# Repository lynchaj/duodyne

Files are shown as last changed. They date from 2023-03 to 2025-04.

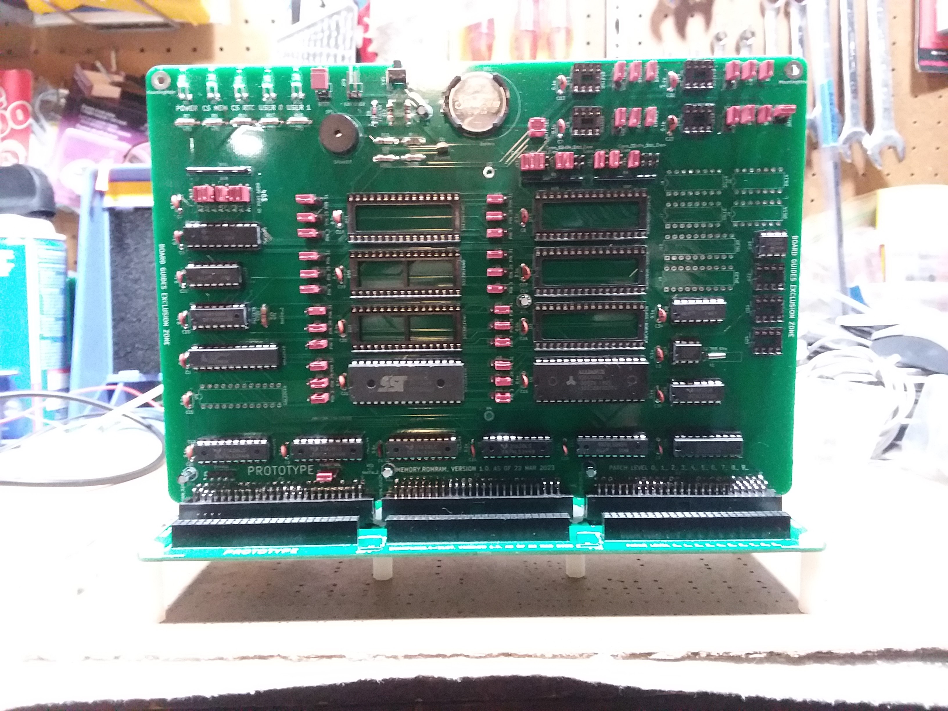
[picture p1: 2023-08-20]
!Initial Build and Test/Andrew's duodyne build.jpg

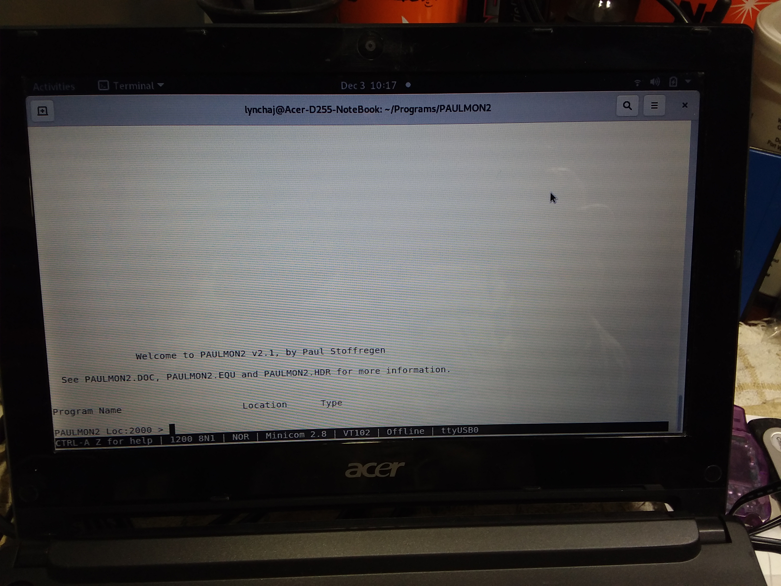
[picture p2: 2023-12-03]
!Development/SAB80535-Dev-Board V1.1/Test-Programs/20231203_101713.jpg

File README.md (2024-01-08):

# duodyne
* duodyne is a hobbyist retrocomputer system comprised of modules on a system bus.  It is specifically designed to run RomWBW, however, provides support for multiple processor architectures and has a flexible and expandable system bus.

* The system bus is designed to support multiple vintage or retro computer processor architectures such as those from Intel, Zilog, Motorola, Mostek, etc.  The Z80 is the primary CPU used to develop the initial round of peripherals.

* Duodyne borrows heavily from previous computer systems.  The form factor is similar to S-100 and VME.  The bus is electrically is derived from ECB with many extensions to support other processor architectures and improved power distribution.  There are multiple pins for 5V and ground.  +12V and -12V are supported.  3.3V and other values can be derived on board using voltage regulators.

* The plan for the system is to have balance between functionality and complexity.  A single function per board has good distribution and easy expansion but leads to many boards and a large backplane which can lead to electrical and signal distribution issues.  However, full integration into a single board computer reduces complexity somewhat but can make expansion difficult.  

* Duoodyne's bus based approach with a generous board form factor allows for a blend of integration and distribution of two or more functions per board leading to a smaller overall backplane yet retaining flexibility for easy expansion.

* The duodyne core system is defined as an 4-slot or 8-slot backplane, a Z80 or other processor (currently, Z80, 65C816, and TMS9995 are supported), and a ROMRAM board.  The ROMRAM memory board assumes an 8-bit data bus so CPU's with larger data busses may require dedicated memory boards.  The Z80 processor includes a debugging serial port for console access.  The boot ROM is included on the ROMRAM board.

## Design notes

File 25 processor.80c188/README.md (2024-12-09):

# Duodyne 80c188 Card
80c188 processor board (hardware and software) for the Duodyne computer system.

Based on the Retrobew Computer SBC-188 board by John Coffman

## Firmware

### BIOS
 The firmware in the BIOS folder is a subset of the SBC-188 firmware.   It currently runs MS-DOS 3.3 and supports PPIDE drives on the Duodyne Disk IO card and USB drives on the Multi IO card.  It requires a RAMROM card and can be used as a primary or secondary CPU.   The RAMROM RTC is supported.
 
 UART must be jumpered for EIRQ0
 
#### BIOS ToDo:
* DiskIO Floppy Drive Support
* Missing Disk-io SD Support
* Missing Disk-io Network Support
* BIOS Support for the PCF 8584
* Better Front Panel Support
* Test multi-io serial support 
* Support for other DuoDyne Hardware
 1.Voice
 1.DualESP
 1.MappedVideo
* Support for Xenix 86
* Support for CPM 86

### Monitor
This is a simple monitor "Mon88" originally by Hans Tiggeler - http://www.ht-lab.com

### Test Programs
There are also two test roms provided.  
* Scream -- this program outputs a constant stream of "A" at 9600-n-8-1 via the on-board uart.
* Scram -- this program outputs an incrimenting character from a RAM address at 9600-n-8-1 via the on-board uart.

## Bugs 
### Hardware
   1. V 0.70
   * To get RAM access -- A21 needs to be high, and it is not. Also A20 should not be left floating.   
      1.  Connect P2 Pin 26 to U17 Pin 18.
      1.  Connect P2 Pin 28 to U17 Pin 16.
      1.  Connect RN1 Pin 3 to U17 Pin 2.
      1.  Connect RN1 Pin 5 to U17 Pin 4.
      1.  Cut Trace between U17 Pin 1 and Pin 19 (bottom of board)
      1.  Connect U17 Pin 1 U6 Pin 19

### BIOS
* Missing multi-io Mouse Support (no plans to support)
* Missing multi-io SD Support (no plans to support)

## Jumper Settings (V.90)

      JP1  - Allow RES_IN to generate board Reset
      
      JP4 - Pullups for IORQ,MREQ,WR,RD.   
            All Open for Secondary CPU
            All Shorted for only CPU

      J1 - Activation Address Port
        
      J2  - CPU Control
                1&2 Only CPU
                2&3 Secondary CPU
      
      J3  - Reset Control
                1&2 Only CPU
                2&3 Secondary CPU                
      
      J4 - Reset Switch Input
        
      J5 - Bus IRQ Enable (0-3)
                1&2 Enable Bus EIRQ3 to Int3
                3&4 Enable Bus EIRQ2 to Int2
                5&6 Enable Bus EIRQ1 to Int1
                7&8 Enable Bus EIRQ0 to Int0

      J7 i2c IRQ Selection
        
      J8 UART IRQ Selection
            (BIOS Requires INT0 - tbd)

      J13 Rom Type Selection
            1&2 32 pin Flash or CMOS 
            2&3 28 pin Flash or CMOS 
        
      J14 Rom Type Selection
            1&2 Flash (not Write Protected)
            2&3 CMOS (512K)

## BOM (V0.90)      
Qty|Reference(s)|Value
--- | ----------- | -----
33|C2, C3, C4, C5, C6, C8, C9, C10, C11, C12, C13, C14, C15, C16, C17, C18, C19, C20, C21, C22, C23, C24, C30, C31, C32, C33, C34, C35, C36, C37, C38, C39, C40|0.1u
4|C25, C26, C27, C28|10u Electrolytic
1|C29|22u Electrolytic
1|C46|47uF Electrolytic
8|D2, D5, D7, D8, D9, D10, D11, D12|LED
1|D4|LED
1|D6|1N4148
1|J1|Pin Header 02x08
1|J2|Pin Header 01x03
1|J3|Pin Header 01x03
1|J4|Pin Header 01x02
1|J7|Pin Header 02x09
1|J8|Pin Header 02x09
1|J11|Pin Header 02x20
2|J13, J14|Pin Header 01x03
1|JP1|Pin Header  01x02
1|JP4|Pin Header 02x04
3|P1, P2, P3|Pin Header 02x25
3|R1, R2, R3|10K
3|R4, R6, R7|1K
1|R5|10
1|R9|1K
3|RN1, RN4, RN5|4700  8 res network
1|RN2|10K  8 res network
1|RN3|470 8 res network
1|RN6|470 4 res network 
1|SW1|Switch:SW_Push
1|U1|74LS04
1|U2|74LS32
2|U3, U19|74ALS373
1|U4|74LS07
1|U5|8259
6|U6, U8, U10, U14, U17, U31|74LS244
1|U7|74LS240
1|U9|OSC 2x rated CPU freq (10-20mhz, should be an even number)
1|U11|74LS245
1|U12|80C188
1|U13|DS1233
2|U15, U25|GAL22V10
1|U16|74LS08
1|U18|OSC 1.8432
1|U20|TL16C550CFN
1|U21|74LS74
1|U22|74LS688
1|U23|74LS00
1|U24|74LS259
1|U26|29F040
1|U27|PCF8584
1|U28|PCF CLOCK
1|U33|74LS374

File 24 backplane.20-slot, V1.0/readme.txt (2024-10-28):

The 20-slot backplane is a foundation of the duodyne system.  It provides the external bus connections for boards in which to plug in boards, power, and mechanical structure.

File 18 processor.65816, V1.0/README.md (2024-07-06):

# 65C816 CPU Card
68C816 processor board (hardware and software) for the Duodyne computer system.

The board contains:
* 65C816 CPU (up to 4Mhz)
* 8K Rom (the first 8K of the EPROM)
* Support for a Standard Duodyne Front Panel
* 16c550 UART

IO is mapped from $00DF00 - $00DF00 for boards prior to V1.31 and is mapped at $xx0300-$xx03FF for 1.31 and later
The on-board ROM is mapped from 00E000-00FFFF.

On board IO Address Port $50-$5F
$50	     Front Panel (RW)
$51	     Option Latch (bit 0, enable interrups, bits 1-7 exposed on front panel connector)
$52	     
$53	     Reset
$54          
$55      
$56
$57 
$58-$5F UART (RW)

Rom Images are in this repo.   DOS/65 operating system sources and images can be found here: https://github.com/danwerner21/6x0x-DOS65
DOS/65 does not work on boards prior to V1.31

# Jumper Settings
        JP1  - Allow RES_IN to generate board Reset

        J2  - Reset Control
                1&2 Only CPU
                2&3 Secondary CPU
                
        J3  - CPU Control
                1&2 Only CPU
                2&3 Secondary CPU

        JP3 - Generate Clock
                OPEN Does not place CPU Clock on BUS
                CLOSED Places CPU Clock on BUS

        JP4 - Reset
                OPEN Does not Connect RES_OUT to BUS
                CLOSED Connect RES_OUT to BUS

        JP10  - IO ADDRESS Select
        JP13  - UART IRQ Enable

# Bugs

Note that the PCF8584 I2C bus controller has been removed from the design after V1.3 as it never worked reliably. The timing requirements of the chip are just too different from what the 65816 is capible of delivering and the work arounds are honestly more trouble than the functionality is worth (IMHO).  

V1.2
* Activation Flip flop needs reset by RES_OUT rather then RES_IN.   Easiest patch is to connect RES_IN to RES_OUT-  JP1 pin 1 to U15 pin 2 (once done DO NOT JUMPER JP1)
* cut connection between JP1 pin 1 and P1 pin 20
* Do not populate U27, U28, R2, R3, and JP2

V1.3
* R15 incorrectly ties M1 to GND.  Do not populate the GND side of this resistor, but instead solder that side to the nearest VCC pin.
* Do not populate U27, U28, R2, R3, and JP2
* U26 lift pin 3 and short pins 2 & 3 -- then use V1.31 GALs and ROMS

# BOM (V1.31)

Qty|Reference(s)|Value
--- | ----------- | -----
1|34|C1, C2, C3, C4, C5, C6, C8, C9, C10, C11, C12, C13, C14, C15, C16, C17, C18, C19, C20, C21, C22, C23, C24, C30, C31, C32, C33, C34, C35, C36, C37, C38, C39, C40|0.1uF
2|4|C25, C26, C27, C28|10uF
3|1|C29|22uF
4|1|C46|47uF
5|1|D1|BI COLOR LED
6|6|D2, D3, D5, D7, D8, D9|LED
7|1|D4|6502
8|1|D6|1N4148
10|1|IC1|65816CPU-DIP
11|1|J1|Connector_Generic:Conn_02x08_Odd_Even
12|1|J2|Connector:Conn_01x03_Male
13|1|J3|Connector:Conn_01x03_Male
14|1|J11|Pin Header Male 02x20 Right Angle| Shrouded
15|1|JP1|Connector:Conn_01x02_Male
16|1|JP3|Jumper:Jumper_2_Open
17|1|JP4|Jumper:Jumper_2_Open
18|1|JP7|Connector_Generic:Conn_02x04_Odd_Even
19|1|JP10|Connector_Generic:Conn_02x04_Odd_Even
20|1|JP13|Jumper:Jumper_2_Open
21|3|P1, P2, P3|Pin Header Male 02x25 Right Angle| Shrouded
22|7|R1, R4, R5, R6, R11, R12, R13|470 ohm
23|1|R7|10 ohm
24|1|R8|470 ohm
25|1|R9|3K ohm
26|1|R10|1K ohm
27|1|R14|100 ohm
28|1|R15|1K ohm
29|3|RN1, RN4, RN5|4700 ohm bussed  9 pin
30|1|RN2|1K  ohm bussed  9 pin
31|1|RN8|10K  ohm bussed  9 pin
32|1|SW1|Switch:SW_Push
33|6|U1, U5, U6, U11, U23, U31|74LS244
34|1|U2|UART CLOCK
35|1|U3|74LS14
36|1|U4|74LS07
37|1|U7|74LS04
38|1|U8|74LS245
39|1|U9|GAL22V10
40|1|U10|GAL16V8
41|2|U12, U22|74LS688
42|1|U13|CPU CLOCK
43|1|U14|TL16C550CFN
44|1|U15|DS1233
45|1|U16|74LS08
46|1|U17|74LS00
47|1|U18|74HC245
48|1|U19|27C64
49|1|U20|GAL22V10
50|1|U21|74LS74
51|1|U24|74HC573
52|2|U25, U33|74LS374
53|1|U26|74LS32

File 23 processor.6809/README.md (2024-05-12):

# Duodyne 6809 Card
6809 processor board (hardware and software) for the Duodyne computer system.

The board contains:
* 6809 CPU
* 8K Rom (the first 8K of the EPROM)
* Support for a Standard Duodyne Front Panel
* 16c550 UART
* PCF8584 I2C bus controller
* Banked MMU with 4 selectable memory windows

Memory Map:
0000 - 3FFF BANK 0
4000 - 7FFF BANK 1
8000 - BFFF BANK 2
C000 - FFFF BANK 3

IO is mapped from 00:DF00 - 00:DFFF, and must be visible in the memory map for the system to operate properly.
The on-board ROM is mapped from 00:E000-00:FFFF.

On board IO Address Port $50-$5F
$50	     PAGER BANK 0(WR)
$51	     PAGER BANK 1(WR)
$52	     PAGER BANK 2(WR)
$53	     PAGER BANK 3(WR)
$54          Front Panel (RW)
$55     
$56-$57 I2C(RW)
$58-$5F UART (RW)

One "Toggle" address is jumper selectable and visible in the OP port range to switch between CPUs in the Duodyne system.

Rom Images are in this repo.   Cubix operating system sources and images can be found here: https://github.com/danwerner21/CUBIX09

# Bugs

V1.00
The following patches are required for the v1.00 6809 board prior to running:
* Pin 33 of U2 (the CPU) must be tied high. Connect a 1K resistor between pin 33 and Pin 7 (+5V) of the CPU
* The traces to Pins 7 and 8 on U9 (Address Decoder) need to be cut on the top of the board
* Pin 7 of U9 needs to be connected to pin 4 of U19
* Pin 8 of U9 needs to be connected to pin 7 of U19
* Connect Pin 19 and 20 of U9 to Pin 3 of U2
* On top of board cut the trace between pin 2 & 6 and also between 8 & 12 of U21 or alternately lift pins 6 & 8.
* Connect pin 1 J2 (/RES_OUT) to pin 20 U3 IO_DECODE GAL
* Update U3 IO-DECODE GAL. 

V1.1
* FIRQ needs a pull up.  Connect U28 Pin 4 to RN1 Pin 2
* Activation Flip flop needs reset by RES_OUT rather then RES_IN.   Easiest patch is to connect RES_IN to RES_OUT-  J4 pin 1 to U15 pin 2 (once done DO NOT JUMPER J4)
* cut connection between J4 pin 1 and P1 pin 20

# JUMPER SETTINGS
## General
        JP1 - Export Clock to Bus
                Closed for Only CPU
                Open For Secondary CPU

        JP3 - Export Reset to Bus
                Closed for Only CPU
                Open For Secondary CPU

        JP4 - Pull up for Bus Signals
                Closed for Only CPU/Pull up
                Open For Secondary CPU/No Pull up

        J11 - 
        J11 NOTE: 
            PINS 5, 7, 9, 11, 13, 15, 17, 19 ARE FOR LED STATUS
            FOR ROMWBW FRONT PANEL INDICATOR
            
            PINS 6, 8, 10, 12, 14, 16, 18, 20 ARE FOR SWITCH
            INPUTS FOR ROMWBW FRONT PANEL

            PINS 21, 23 ARE FOR I2C CONNECTION (SDA & SCL)

            PINS 25, 27, 29, 31, 33, AND 35
            ARE FOR TTL SERIAL CONNECTOR TO UART

            PINS 29, 37 ARE FOR SERIAL VCC POWER ENABLE
            PINS 22, 24 ARE FOR EXTERNAL RESET SWITCH

        J1  - Toggle IO Address Selection

        J2  - Reset Control
                1&2 Only CPU
                2&3 Secondary CPU

        J3  - Enable
                1&2 Only CPU
                2&3 Secondary CPU

        J4 - Reset
                OPEN Only CPU
                CLOSED Secondary CPU

        J5  - CPU NMI Selection
        J6  - CPU IRQ Selection
        J7  - I2C IRQ Selection
        J8  - UART IRQ Selection
        J9  - CPU FIRQ Selection

        J10 - CPU READY
                1&2 Disable CPU Wait
                2&3 Enable CPU Wait           

# BOM

Qty|Reference(s)|Value
--- | --- | ---
33|C2, C3, C4, C5, C6, C8, C9, C10, C11, C12, C13, C14, C15, C16, C17, C18, C19, C20, C21, C22, C23, C24, C30, C31, C32, C33, C34, C35, C36, C37, C38, C39, C40|0.1u
4|C25, C26, C27, C28|10u
1|C29|22u
1|C46|47uF
4|D2, D3, D7, D9|LED
1|D4|6809
1|D6|1N4148
1|J1|IO Address Select -  male Pin Header 2x8
1|J2|6809 RESET -  male Pin Header 1x3 right angle
1|J3|6809 ONLY -  male Pin Header 1x3 right angle
1|J4|RES SEL -  male Pin Header 1x2 right angle
1|J5|NMI Selection -  male Pin Header 2x9
1|J6|IRQ Selection -  male Pin Header 2x9
1|J7|I2C IRQ Selection -  male Pin Header 2x9
1|J8|UART IRQ Selection -  male Pin Header 2x9
1|J9|FIRQ Selection -  male Pin Header 2x9
1|J10|MRDY -  male Pin Header 1x3
1|J11|FPANEL -  male Pin Header 2x20 right angle
1|JP1|GENERATE CLOCK -  male Pin Header 1x2
1|JP3|GENERATE RESET -  male Pin Header 1x2
1|JP4|BUS CPU -  male Pin Header 2x4
1|JP10|IO PORT ADDR -  male Pin Header 2x4
3|P1, P2, P3|CONN_02X25 -  male Pin Header 2x25 right angle
2|R1, R6|1K
2|R2, R3|10K
4|R4, R5, R12, R13|470
1|R7|10
1|R8|470ohm
3|RN1, RN4, RN5|4700 network 9 pin
1|RN2|10Kohm network 9 pin
1|RN3|470 network 9 pin
1|RN8|10K network 9 pin
1|SW1|RESET- Tact Button, right angle
1|U1|74LS04
1|U2|GAL16V8
1|U3|GAL22V10
1|U4|74LS07
1|U5|27C010
6|U6, U8, U10, U14, U17, U31|74LS244
1|U7|74LS14
1|U9|GAL22V10
1|U11|74LS245
2|U12, U22|74LS688
1|U13|CPU CLOCK- TTL Osc 
1|U15|DS1233
1|U16|74LS08
1|U18|UART CLOCK - TTL Osc
1|U19|74LS157
1|U20|TL16C550CFN
1|U21|74LS74
2|U24, U29|74LS670
1|U27|PCF8584
1|U28|MC6809 (pref 68B09)
1|U33|74HCT374

U18 UART CLOCK = 1.8432mhz
U13 CPU CLOCK : 6809 Uses a 4xclock so use 4Mhz for 1mhz CPU, 8Mhz for 2Mhz CPU, etc.
U33 Front panel LED driver should be 74HCT374.
U5 Can be 27C010, Intel P28F001, SST29EE010 

# SOFTWARE
Three Rom images are provided
* Scream - simple scream test, RAM-less
* Monitor - basic monitor
* mon09 - Full featured monitor

The .HEX file can be used to program U5 EPROM/Flash device.

### SCREAM
Serial setting 38400N1

### MONITOR

Monitor is a simple machine language monitor that will allow you to view and manipulate the 6809 operating environment.

Serial setting 9600N1

Monitor Supports the following Commands:

```
	* D -  XXXX YYYY - Dump memory from XXXX to YYYY
        * L - Load a S19 file into RAM
       	* M XXXX YY  - update the ram at XXXX with value YY
        * G XXXX - Execute program at XXXX
        * P - PRINT CONTENTS OF STACK
```

### MON09

MON09 is an interactive software debugger and machine language monitor for the motorola 6809 microprocessor.  It contains display/alter memory/register facilities, as well as a full 6809 disassembler.  Mon09 is a product of Dunfield Development Systems http://www.dunfield.com, 1985-2007 Dave Dunfield.
   
```
       Operand format

        Anywhere that MON09 expects an 8 bit value, you may use:

            Two HEX digits                              Eg: 1F
            A QUOTE followed by an ASCII character      Eg: 'a

        Anywhere that MON09 expects a 16 bit value, you may use:

            Four HEX digits                             Eg: 09AB
            ASCII characters preceeded by quotes        Eg: 'a'b
            X, Y, U, P, or S for current CPU register   EG: X

        Monitor Commands

             The following commands are implemented in the monitor.

               CR <register> <value>

                  Changes  6809  registers  values.  Register  is  a  single
                  character, which may be as follows:

                  A   - Set A accumulator (8 bit value).
                  B   - Set B accumulator (8 bit value).
                  C   - Set condition code register (8 bit value).
                  D   - Set direct page register (8 bit value).
                  X   - Set X register (16 bit value).
                  Y   - Set Y register (16 bit value).
                  U   - Set user stack pointer (16 bit value).
                  S   - Set system stack pointer (16 bit value).
                  P   - Set program counter (16 bit value).
                  sp  - (SPACE) Set D accumulator (16 bit value).

               CV <vector> <address>

                     Changes the interrupt  vector  handler  addresses.  The
                  vectors are as follows:

                  1 or 'S' - SWI  (Software Interrupt) vector
                  2        - SWI2 (Software Interrupt 2) vector
                  3        - SWI3 (Software Interrupt 3) vector
                  4 or 'I' - IRQ  (Interrupt Request) vector
                  5 or 'F' - FIRQ (Fast Interrupt Request) vector

               DI <start>,<end>

                  Disassembles memory,  starting at  indicated  address.  If
                  SPACE  is  entered  for  <end>  address,   assumes   FFFF.
                  Disassembler output contains address, opcodes bytes, ASCII
                  equivalent of  opcode  bytes,  instruction  neumonic,  and
                  operands to instruction.

               DM <start>,<end>

                  Displays memory, in HEX/ASCII dump format, starting at the
                  indicated  address.  If  a  SPACE  is  entered  for  <end>
                  address, assumes FFFF.

               DR

                  Displays the values of the 6809 registers.

               DV

                  Display the current interrupt vector address assignments.

               E <address>

                  Edit memory,  Address and contents are displayed,  Enter
                  two hex digits to change value, or a single quote followed
                  by a character. Entering SPACE skips to the next location,
                  BACKSPACE  backups  to  the  previous  location.  CARRIAGE
                  RETURN terminates the edit command.

               FM <start>,<end> <value>

                  Fill's memory from <start> to <end> with the byte <value>.

               G <address>

                  Begins execution at the indicated address.  If a SPACE  is
                  entered instead of an address,  begins  execution  at  the
                  address in the saved 6809 program counter.

               L

                  Downloads data which may be in either MOTOROLA or INTEL hex format.

               MM <start>,<end> <destination>

                  Move memory  from  <start>  to  <end>,  placeing  it  at
                  <destination>.

               MT <start>,<end>

                  Performs a memory test on memory from  <start>  to  <end>.
                  Pass number is displayed,  First two digits indicate total
                  number completed tests,  last two digits indicate  current
                  pass  (value)  within the  test.  Each  value  is  written
                  sequentially to memory,  insuring that previous  data  has
                  not changed before the new value is written.  To exit  the
                  test, press the escape key.

               RR <address>

                  This command loops,  performing a read  of  the  specified
                  address until it is terminated by the escape key.

               RW <address> <value>

                  This  command  loops,  writing  the  given  value  to  the
                  specified address until it is  terminated  by  the  escape
                  key.

               W <address> <value>

                  Performs  a  single  write  of  the  given  value  to  the
                  specified address in memory.

               XR <address>

                  As 'RR' command, except that a 16 bit value is read.

               XW <address> <word value>

                  As 'RW' command, except that a 16 bit value is written.

               + <value>+<value>

                  Performs 16 bit addition of the values,  and displays  the
                  result.

               - <value>-<Value>

                  Performs 16 bit subtraction of the  values,  and  displays
                  the result.

               ?

                  Displays a short help summary of the commands.

```

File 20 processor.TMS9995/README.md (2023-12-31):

# TMS9995 CPU Card

This is a Duodyne implimentation of Stuart Conner's Mini-Cortex system.  The Mini-Cortex system is a further development of his TMS 9995 breadboard project to produce a system similar to a Powertran Cortex, but using more modern components. The system is based around a TMS 9995 running at 3 MHz, with 32K byte EEPROM, and will use 512K bytes of RAM from a Duodyne ROMRAM card accessed through a memory mapper. An on-board serial port and IDE interface exists on the card.

The main EEPROM image provides a boot menu which enables the user to select between the EVMBUG system monitor from TI's TMS 9995 Evaluation Module, a port of the Powertran Cortex Power BASIC made for a TM 990 computer, the Marinchip Disk Executive (MDEX) operating system, and an implementation of V6 Unix including a C compiler.

[Much more information can be found at Stuart's site](https://www.stuartconner.me.uk/mini_cortex/mini_cortex.htm)

[Source code for the Cortex Version of Unix V6 and a ton more TI990 software (including cross development tools) can be found here on Dave Pitts' TI-990 web page.](https://www.cozx.com/dpitts/ti990.html)

## Memory Map
The memory map is shown in the table below.

```
Memory Address	Mapped To
>0000 - >7FFF	ROM when enabled, otherwise RAM
>8000 - >EFFF	RAM
>F000 - >F0FB	TMS 9995 internal RAM
>F0FC - >FDFF	RAM
>FE00 - >FE3F	CF card ATA registers (FIX INCOMPLETE DECODING WITH NEXT REVISION)
>FE40 - >FE7F	Memory mapper registers 0-15 (>FE40 - >FE4F, repeats at >FE50 etc. . .  FIX INCOMPLETE DECODING WITH NEXT REVISION)
>FE80 - >FEBF	Offboard IO (ports $80-$FF)
>FFF0 - >FFF9	RAM
>FFFA - >FFFF	TMS 9995 internal RAM

CRU Address	Mapped To
>0000 - >003F	TMS 9902 registers
>0040 - >007F	Control signal latch (further details here)
 	(Plus processor internal CRU bits)
    
(Note that in TI Speak ">" means Hexidecimal, so for the rest of us >FFFA is the same as $FFFA or 0xFFFA or FFFAH)
```
[for more information see Stuart's site](https://www.stuartconner.me.uk/mini_cortex/mini_cortex.htm)

## Creating CF card Image for MDEX and Unix

The CF card has to be newly formatted with an MBR (master boot record), a single partition formatted as FAT32, and a cluster size of 4096 bytes - the CF card needs to be at least 256 MB to support this. Not all brands/sizes of CF card seem to work - you may have more success with an older, low capacity card. A SanDisk 2.0GB card with a "SDCFB" marking on the back works well.

It can be problematic formatting a new card using Windows 10 as it does not always seem to write an MBR to the card. I use a formatting utility called Rufus [details and download here](https://rufus.ie/en/) with Boot selection==Non bootable, Partition Scheme==MBR, File System=FAT32, and Cluster Size= 4096 Bytes. Once the card is correctly formatted, use Windows to write the four files from the software folder ZIP filedirectly to the card.
[for more information see Stuart's site](https://www.stuartconner.me.uk/mini_cortex/mini_cortex.htm)

## Jumper Settings
```
JP3 - Enable Reset signal from TMS9918 board to go to RES_OUT on bus. closed for Stand Alone Operation, open for secondary CPU

JP1- CPU Signal Pullups - Jumpers should be installed if this is the only CPU card in the system, otherwise leave unjumpered
JP4 - Jumper to enable on board LED for IDE or connect external LED for IDE Activity
JP5 - 2&3 for power on IDE connector 

J4 - Enable Serial Interrupts (required for Unix and MDEX)
J6 - TTL Serial +5v enable
J7 - External User flag bits (CRU 0046-004C)

J2 - 1&2 for Stand Alone Operation, 2&3 for secondary CPU
J3 - 1&2 for Stand Alone Operation, 2&3 for secondary CPU
J8 - 2&3 for Stand Alone Operation, 1&2 for secondary CPU

J9  - Reset Selection -  closed for External bus Reset in 
```
## Powering up
The serial port on the TMS9995 board is configured for 9600 Baud, 7 data bits, even parity, one stop bit, no flow control.

The EVMBUG monitor and Cortex BASIC software applications, and the boot loaders for MDEX and Unix, are stored on a single 32K byte EEPROM. The required application is selected from a boot menu. To display the boot menu, connect the board to a configured serial port on a PC, apply power then press any key.

You should then see:
```
TMS 9995 BREADBOARD SYSTEM
BY STUART CONNER
PRESS 1 FOR EVMBUG MONITOR
PRESS 2 FOR CORTEX BASIC
PRESS 3 FOR MDEX
PRESS 4 FOR UNIX
```
To select a software application from the menu, press the corresponding numeric key.

## Useful Links
MDEX documentation is available on the site http://www.powertrancortex.com/documentation.html. The documentation and MDEX disks were recovered and made available by Dave Hunter, the owner of the www.powertrancortex.com site. Porting of the MDEX files to the Mini-Cortex was by Paul Ruizendaal. On the Mini-Cortex, the files are stored in two emulated disks on the CF card.

The first version of Unix ported was LSX Unix (https://www.mailcom.com/lsx/), which was designed to run with 40K byte RAM and two 256K byte floppies. LSX Unix was adapted from Unix V6 by Dr. Heinz Lycklama (https://www.60bits.net/msu/mycomp/terak/termubel.htm). This port has been further ported to the TI 990 minicomputer by Dave Pitts, who has also made improvements to the code build system.

[Dave Pitts' TI-990 web page.](https://www.cozx.com/dpitts/ti990.html)
[EVMBUG documentation](https://www.stuartconner.me.uk/tibug_evmbug/tibug_evmbug.htm#evmbug)

## Bugs/To Do
* Add Xmodem to Unix
* Add Vi to Unix
* CF card ATA registers have INCOMPLETE DECODING 
* Memory mapper have INCOMPLETE DECODING
* Add Serial port drivers for off board Duodyne hardware
* Add Mass storage drivers for off board Duodyne hardware

## Troubleshooting

The first test image tests just the processor (TMS9995_test_1_eprom_image), the EPROM and the EPROM chip select logic. Program and fit the EPROM, power on, press the reset switch.  The CPU should execute a loop from ROM., then use the logic probe to check for a series of pulses on pin 20 of the EPROM every 2 seconds or so. 

If the first test passes, repeat with the second test image (TMS9995_test_2_eprom_image), which also tests the RAM and the RAM chip select logic. With the second test, a series of pulses should be seen on pin 20 of the EPROM every 6 seconds or so.

The third test image has two versions.   The first version configures the serial port to 9600 Baud, 7 bits/character, even parity, 2 stops bits, no flow control, and then loops continually sending the ASCII characters >21 ("!") to >7E .  This version tests most of the system including ROM and RAM.   The second version is a ROM only version. It also configures the serial port to 9600 Baud, 7 bits/character, even parity, 2 stops bits, no flow control, and then loops continually sending the ASCII characters >21 ("!") to >7E , but does not use any external RAM.

Note that the TMS9995 uses the RAM3 chip on the ROMRAM card, therefore it must be populated for the TMS9995 board to function.

## Patches
   on the .75 Version of the board do not populate R11  
   on the .70 Version of the board, cut pin 3 of RN4 prior to installing and then tie Pin 13 of U11 High

## BOM
Qty|Reference(s)|Value
--- | ----------- | -----
22|C1, C2, C3, C4, C5, C6, C7, C8, C9, C10, C11, C12, C13, C14, C15, C16, C17, C19, C21, C23, C25, C27|0.1u
4|C18, C20, C22, C24|10u
1|C26|22u
1|C28|47uF
2|C40, C41|15pf
1|D1|PWR LED
1|D2|IDLE LED
1|D3|MAP LED
1|D4|1N4148
1|D5|TMS9995 LED
1|D6|IDE ACT LED
1|D7|UART  LED
1|J1|Connector_Generic:Conn_02x08_Odd_Even
1|J2|Connector:Conn_01x03_Male
1|J3|Connector:Conn_01x03_Male
1|J4|Connector:Conn_01x02_Male
1|J5|Connector_Generic:Conn_01x06
1|J6|Connector_Generic:Conn_01x02
1|J7|Connector:Conn_01x06_Male
1|J8|Connector:Conn_01x03_Male
1|J9|Connector_Generic:Conn_01x02
1|JP1|Connector_Generic:Conn_02x04_Odd_Even
1|JP3|Jumper:Jumper_2_Bridged
1|JP4|Jumper:Jumper_2_Open
1|JP5|Connector_Generic:Conn_01x03
3|P1, P2, P3|Connector_Generic:Conn_02x25_Odd_Even
1|P4|Connector_Generic:Conn_02x20_Odd_Even
5|R1, R3, R7, R12, R13|470 ohm
5|R2, R4, R9, R14, R15|10K ohm
2|R5, R10|470 ohm
1|R8|10 ohm
2|RN1, RN2|4700 ohm resistor net (9 pin)
1|RN3|1K ohm resistor net (9 pin)
1|RN4|10K ohm resistor net (9 pin)
1|SW1|Switch:SW_Push
1|U1|74LS14
1|U2|74LS07
1|U3|TMS9995
1|U4|74LS04
2|U5, U7|74LS74
1|U6|74LS112
1|U8|GAL22V10
5|U9, U10, U11, U13, U14|74LS244
1|U12|74LS245
1|U15|74LS138
1|U16|74LS32
2|U17, U20|74LS688
1|U18|27C256
1|U19|DS1233
1|U21|TMS9902A
1|U22|74LS259
1|U23|74LS612
1|U24|74LS08
1|Y1|12MHz crystal

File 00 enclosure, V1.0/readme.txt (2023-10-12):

The duodyne is intended to be housed in an enclosure along with power supply and optional floppy and/or IDE hard disk drives.  Notional enclosure such as this one below

https://www.amazon.com/dp/B09MQDZ1W4 (Cheval steel)

https://www.amazon.com/dp/B08RSHNDCY (Cheval aluminum)

Triple output power supply (5V, 12V, and -12V) such as this one

https://www.amazon.com/dp/B07CQL28QC (MeanWell)

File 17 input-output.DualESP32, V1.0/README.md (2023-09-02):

# ESP32 Multi IO
The Duodyne ESP32 board provides the following functions for your Duodyne computer
* ANSI Console
* Graphics
* Sprites
* Sound
* Dual USB Serial Support
* WiFi
* Keyboard
* Mouse

This board relies heavily on the FabGL library from Fabrizio Di Vittorio.   More information can be found [HERE](http://www.fabglib.org/)

# ESP32 BOM
Qty|Reference(s)|Value|Notes
---|------------|-----|-----
14|C1, C2, C3, C4, C5, C6, C7, C8, C9, C10, C11, C12, C17, C18|0.1uf
3|C13, C14, C16|10uf
1|C15|100nF
1|D1|LED
4|D2, D3, D4, D5|1N4001
1|J1|2x5 pin header, right angle|KEYBOARD AND MOUSE
1|J2|1x2 pin header, right angle|AUDIO OUT
1|J3|1x3 pin header, right angle|ESP_SERIAL_1
1|J4|1x3 pin header, right angle|ESP_SERIAL_0
1|J5|HD15 Female PCB VGA Connector|VGA
1|J6|1x3 pin header|RESET SEL
1|J7|2x6 pin header, right angle|IO PORT ADDR
1|J8|Mini Din, 6 pos female PS/2|Keyboard
1|J9|Mini Din, 6 pos female PS/2|Mouse
1|J10|2x7 pin header, right angle|VGA
3|P1, P2, P3|02X25 pin header, right angle
1|P4|1x4 pin header|BYPASS
1|R1|470ohm
1|R2|270ohm
4|R3, R4, R10, R11|120ohm
1|R5|150ohm
2|R6, R8|2Kohm
2|R7, R9|1Kohm
3|R12, R14, R16|400ohm| Used for VGA voltage divider, precise value not required 
3|R13, R15, R17|800ohm| Used for VGA voltage divider, precise value not required 
2|R18, R19|0ohm
1|RN1|1Kohm, networked, 9 pin, 8 resistor
1|RN2|10Kohm, networked, 9 pin, 8 resistor
1|U1|74LS04
3|U2, U4, U5|74LS32
2|U3, U17|74LS07
2|U6, U8|74HC595
2|U7, U9|74HC165
3|U10, U13, U15|74LS244
2|U11, U12|ESP-WROOM-32 Dev Module|Such As: https://www.amazon.com/ESP-WROOM-32-Development-Microcontroller-Integrated-Compatible/dp/B08D5ZD528
1|U14|74LS245
1|U16|74LS688

# ESP32 Firmware Installation
The firmware for this board requires that platformio be installed on your system.

To install platformio core for your operating system see the directions [HERE](https://platformio.org/install/cli).  
Make sure you follow the additional directions to install the shell commands.

On linux systems it may be necessary to update permissions for the device that is autocreated for the ESP32. [More details](https://docs.platformio.org/en/latest/core/installation/udev-rules.html)  
Once platformio is properly setup on your system, you should be able to build and deploy the firmware to the ESP32.  

## To build and install the ESP firmware:
Take the ESP32 device you have designated as ESP0 and with it NOT INSTALLED in the Duodyne card, plug it into your computer via USB.
change directory to the ESP0Firmware folder on your PC and from the operating system prompt type
```
pio run -t upload
```

Over the next couple of minutes you should see the build and upload process
something like this:

```
dwerner@lserver02:/lserver03/fileserv/Development/Vintage/Projects/Duodyne/Z80ESP/ESP0Firmware$ pio run -t upload
Processing esp32dev (platform: espressif32; board: esp32dev; framework: arduino)
-----------------------------------------------------------------------------------------------------------------------
Verbose mode can be enabled via `-v, --verbose` option
CONFIGURATION: https://docs.platformio.org/page/boards/espressif32/esp32dev.html
PLATFORM: Espressif 32 (6.3.2) > Espressif ESP32 Dev Module
HARDWARE: ESP32 240MHz, 320KB RAM, 4MB Flash
DEBUG: Current (cmsis-dap) External (cmsis-dap, esp-bridge, esp-prog, iot-bus-jtag, jlink, minimodule, olimex-arm-usb-ocd, olimex-arm-usb-ocd-h, olimex-arm-usb-tiny-h, olimex-jtag-tiny, tumpa)
PACKAGES:
 - framework-arduinoespressif32 @ 3.20009.0 (2.0.9)
 - tool-esptoolpy @ 1.40501.0 (4.5.1)
 - tool-mkfatfs @ 2.0.1
 - tool-mklittlefs @ 1.203.210628 (2.3)
 - tool-mkspiffs @ 2.230.0 (2.30)
 - toolchain-xtensa-esp32 @ 8.4.0+2021r2-patch5
LDF: Library Dependency Finder -> https://bit.ly/configure-pio-ldf
LDF Modes: Finder ~ deep+, Compatibility ~ soft
Found 34 compatible libraries
Scanning dependencies...
Dependency Graph
|-- FabGL @ 1.0.9
|-- SPI @ 2.0.0
|-- Preferences @ 2.0.0
Building in release mode
Retrieving maximum program size .pio/build/esp32dev/firmware.elf
Checking size .pio/build/esp32dev/firmware.elf
Advanced Memory Usage is available via "PlatformIO Home > Project Inspect"
RAM:   [=         ]   9.3% (used 30632 bytes from 327680 bytes)
Flash: [=====     ]  46.4% (used 608561 bytes from 1310720 bytes)
Configuring upload protocol...
AVAILABLE: cmsis-dap, esp-bridge, esp-prog, espota, esptool, iot-bus-jtag, jlink, minimodule, olimex-arm-usb-ocd, olimex-arm-usb-ocd-h, olimex-arm-usb-tiny-h, olimex-jtag-tiny, tumpa
CURRENT: upload_protocol = esptool
Looking for upload port...
Auto-detected: /dev/ttyUSB0
Uploading .pio/build/esp32dev/firmware.bin
esptool.py v4.5.1
Serial port /dev/ttyUSB0
Connecting.....
Chip is ESP32-D0WD-V3 (revision v3.0)
Features: WiFi, BT, Dual Core, 240MHz, VRef calibration in efuse, Coding Scheme None
Crystal is 40MHz
MAC: 08:b6:1f:33:39:fc
Uploading stub...
Running stub...
Stub running...
Changing baud rate to 460800
Changed.
Configuring flash size...
Flash will be erased from 0x00001000 to 0x00005fff...
Flash will be erased from 0x00008000 to 0x00008fff...
Flash will be erased from 0x0000e000 to 0x0000ffff...
Flash will be erased from 0x00010000 to 0x000a4fff...
Compressed 17488 bytes to 12168...
Writing at 0x00001000... (100 %)
Wrote 17488 bytes (12168 compressed) at 0x00001000 in 0.5 seconds (effective 287.3 kbit/s)...
Hash of data verified.
Compressed 3072 bytes to 146...
Writing at 0x00008000... (100 %)
Wrote 3072 bytes (146 compressed) at 0x00008000 in 0.0 seconds (effective 571.2 kbit/s)...
Hash of data verified.
Compressed 8192 bytes to 47...
Writing at 0x0000e000... (100 %)
Wrote 8192 bytes (47 compressed) at 0x0000e000 in 0.1 seconds (effective 829.3 kbit/s)...
Hash of data verified.
Compressed 608928 bytes to 309667...
Writing at 0x00010000... (5 %)
Writing at 0x00020854... (10 %)
Writing at 0x0002f631... (15 %)
Writing at 0x0003b66a... (21 %)
Writing at 0x0004b725... (26 %)
Writing at 0x00050794... (31 %)
Writing at 0x00056585... (36 %)
Writing at 0x0005c2fd... (42 %)
Writing at 0x0006271e... (47 %)
Writing at 0x000684b2... (52 %)
Writing at 0x0006dceb... (57 %)
Writing at 0x00073098... (63 %)
Writing at 0x0007864e... (68 %)
Writing at 0x0007de33... (73 %)
Writing at 0x0008412b... (78 %)
Writing at 0x0008c053... (84 %)
Writing at 0x00094cba... (89 %)
Writing at 0x0009a559... (94 %)
Writing at 0x0009f9b7... (100 %)
Wrote 608928 bytes (309667 compressed) at 0x00010000 in 8.0 seconds (effective 606.6 kbit/s)...
Hash of data verified.

Leaving...
Hard resetting via RTS pin...
============================================ [SUCCESS] Took 22.49 seconds ============================================
```

Once this is done you can install ESP0 into U12 on your Duodyne board.  Then repeat the process for the ESP1 and install into U13.

# ESP32 Communication Protocol

The ESP32 board communicates with your system via 3 ports, two IO ports and one status port.

The default configuration sets the base IO to $9C.  IO Communication with ESP0 is at base port, ESP1 is at base port +1 and the status register is at base port +2.

```
ESPBASE         EQU $9C         ; Base Port
ESP0:           EQU ESPBASE     ; ESP0 IO PORT

ESP1:           EQU ESPBASE+1   ; ESP1 IO PORT

ESP_STATUS:     EQU ESPBASE+2   ; ESP  STATUS PORT
                                ; MSB XX XX S S S S S
                                ;           | | | | |- ESP0 READY_OUTPUT
                                ;           | | | |--- ESP0 BUSY
                                ;           | | |----- ESP0 SPARE (unused)
                                ;           | |------- ESP1 READY_OUTPUT
                                ;           |--------- ESP1 BUSY
```

The communication process is fairly straight forward.  Upon reset, the ESP will initialize, set BUSY and READY_OUTPUT to low and wait for an opcode.

To send an opcode or data to the ESP:

* wait for ESPx BUSY bit to go low (a timeout is suggested)
* write the opcode or data to the ESPx IO port
* it is a best practice to wait for ESPx BUSY bit to go high then low (a timeout is suggested) before sending the next byte

If an "out of sync" occurrs, where the ESP is waiting for data rather than an opcode and the host driver is unsure of the state of the ESP, it is possible to resync the ESP back to the "waiting for opcode" state by sending a stream of NULL bytes to the IO port. A stream of more than 25 NULLS should always safely return the ESP back to the "waiting for opcode" state.

Some Opcodes will return one or more bytes to the host system.   For those opcodes

* wait for ESPx BUSY bit to go low (a timeout is suggested)
* wait for ESPx READY_OUTPUT bit to go high (a timeout is suggested)
* Read the ESPx IO port
* it is a best practice to wait for ESPx BUSY bit to go high then low (a timeout is suggested) before sending the next byte

Note that the BUSY bit transitions after a command is written or data is read can happen very fast.   On slower systems a timeout is required as it is possible for the host system to miss this transition if it is not polling fast enough.

It is also a best practice to empty the ESP send buffer before sending an opcode that returns data.

For example code, see the ESPTEST.ASM program in this repo.

# ESP32 ESP0 Opcode Reference

## ESP32 Misc Opcodes

OP CODE|Description|Values
-------|-----------|------
00|NO OPERATION|NONE

The NO OPERATION opcode is used to sync the ESP32 communications stream to a known state, "Waiting for opcode".

Input Parameters: None  
Returns: None  

OP CODE|Description|Values
-------|-----------|------
255|DISCOVER|"E" "S" "P" "3" "2" "V" "1"

The DISCOVER opcode is used by host systems to verify the presence and version of the ESP hardware and firmware.

Input Parameters: None  
Returns: 7 bytes - "E" "S" "P" "3" "2" "V" "1"  

## ESP32 Terminal Opcodes
	
OP CODE|Description|Values
-------|-----------|------
1 |VGA ANSI TERM OUT SINGLE CHAR| OUT-BYTE

The VGA ANSI TERM OUT SINGLE CHAR opcode sends a single byte to the ANSI terminal subsystem of the ESP32.  Using the ANSI escape sequence set, this byte is rendered to the VGA terminal console.

Input Parameters: 1 byte - "OUT CHAR"  
Returns: None  

OP CODE|Description|Values
-------|-----------|------
2 |VGA ANSI TERM OUT NULL TERMINATED STRING| OUT-BYTE	OUT-BYTE	OUT-BYTE	OUT-BYTE	OUT-BYTE	OUT-BYTE	…	…	…	…	NULL

The VGA ANSI TERM OUT NULL TERMINATED STRING opcode sends a null terminated string to the ANSI terminal subsystem of the ESP32.  Using the ANSI escape sequence set, this string is rendered to the VGA terminal console.

Input Parameters: X bytes - string terminated by a null  
Returns: None  

OP CODE|Description|Values
-------|-----------|------
3 |VGA ANSI TERM KEYBOARD IN| IN-BYTE	

The VGA ANSI TERM KEYBOARD IN opcode returns a byte from the terminal keyboard buffer.   If there is no keystrokes in the buffer, the opcode will return a null.

Input Parameters: None  
Returns: 1 byte - input keystroke or null  

OP CODE|Description|Values
-------|-----------|------
4 |VGA ANSI TERM KEYBOARD BUFFER LENGTH| IN-BYTE

The VGA ANSI TERM KEYBOARD BUFFER LENGTH opcode returns the numbser of keystrokes in the ANSI terminal keyboard buffer.

Input Parameters: None  
Returns: 1 byte - keystroke buffer length  

OP CODE|Description|Values
-------|-----------|------
5 |VGA ANSI TERM SET CURSOR| OUT-BYTE

The VGA ANSI TERM SET CURSOR opcode sets the visibility of the terminal cursor.
* 0 = cursor off
* 1 = cursor on

Input Parameters: 1 byte - Cursor status  
Returns: None  

## ESP32 Serial Opcodes

OP CODE|Description|Values
-------|-----------|------
6 |Set Baud Rate| OUT-BYTE  OUT-BYTE  OUT-BYTE  OUT-BYTE

The Set Baud Rate opcode sets the baud rate for the ESP async serial port.  This port is exposed through the header on the top of the card and through the USB port on the ESP32 module.   Byte order is least signifigant byte to most significant byte.

Input Parameters: 4 bytes - Baud Rate
Returns: None  

OP CODE|Description|Values
-------|-----------|------
7 |Set Serial Mode| OUT-BYTE

The Set Serial Mode opcode sets the serial communication parameters for the ESP async serial port.  This port is exposed through the header on the top of the card and through the USB port on the ESP32 module.
Parameters are set as follows:
* 0 = 8 data bits, no parity, 1 stop bits
* 1 = 8 data bits, even parity, 1 stop bits
* 2 = 8 data bits, odd parity, 1 stop bits
* 3 = 7 data bits, no parity, 1 stop bits
* 4 = 7 data bits, even parity, 1 stop bits
* 5 = 7 data bits, odd parity, 1 stop bits

Input Parameters: 1 byte - Serial Mode  
Returns: None  

OP CODE|Description|Values
-------|-----------|------
8 |Serial TX Single char| OUT-BYTE

The Serial TX Single char opcode transmits a single byte through the serial communication port.  This port is exposed through the header on the top of the card and through the USB port on the ESP32 module.

Input Parameters: 1 byte - char  
Returns: None  

OP CODE|Description|Values
-------|-----------|------
9 |Serial TX Null Terminated String| OUT-BYTE  OUT-BYTE  OUT-BYTE  OUT-BYTE  OUT-BYTE  OUT-BYTE	…	…	…	…	NULL

The Serial TX Null Terminated String opcode transmits a null terminated string through the serial communication port.  This port is exposed through the header on the top of the card and through the USB port on the ESP32 module.

Input Parameters: X bytes - string terminated by a null  
Returns: None  

OP CODE|Description|Values
-------|-----------|------
10 |Serial RX| IN-BYTE

The Serial RX opcode returns a byte from the serial communication port buffer.  If there are no values in the buffer, the opcode will return a null.  This port is exposed through the header on the top of the card and through the USB port on the ESP32 module.   

Input Parameters: None  
Returns: 1 byte - input value or null    

OP CODE|Description|Values
-------|-----------|------
11 |Chars in Serial Buffer| IN-BYTE

The Chars in Serial Buffer opcode returns the numbser of keystrokes in the serial communication port buffer.  This port is exposed through the header on the top of the card and through the USB port on the ESP32 module.   

Input Parameters: None  
Returns: 1 byte - serial buffer length  

## ESP32 Audio Opcodes

OP CODE|Description|Values
-------|-----------|------
12 |Play Null Terminated String| OUT-BYTE  OUT-BYTE  OUT-BYTE  OUT-BYTE  OUT-BYTE  OUT-BYTE	…	…	…	…	NULL

The Play Null Terminated String opcode intreprets a string as musical notes and plays them with a square wave tone generator through the audio port on the top of the ESP32 card.  The audio port is at line level and requires amplification. 

Example string: "A4 4 2 A4 4 2 A#4 4 2 C5 4 2 C5 4 2 A#4 4 2 A4 4 2 G4 4 2 F4 4 2 F4 4 2 G4 4 2 A4 4 2 A4 2 2 G4 16 2 G4 2 2 P 8 2 "

The string is in the format:  [note (C,D,E,F,G,A,B) + [#,b] + octave (2..7) + space + tempo (99..1)] + [pause (P) + space + tempo (99.1)]
```
    "A4 4 2" 
     |  | |----- Tempo
     |  |------- Octave (2..7)
     |---------- note to play (or P for pause)
```     

Input Parameters: 1 byte - Cursor status  
Returns: None  

OP CODE|Description|Values
-------|-----------|------
13 |Play Sound	| OUT-BYTE  OUT-BYTE  OUT-BYTE  OUT-BYTE  OUT-BYTE  OUT-BYTE  OUT-BYTE  OUT-BYTE  OUT-BYTE  OUT-BYTE  OUT-BYTE  OUT-BYTE  OUT-BYTE  OUT-BYTE  OUT-BYTE  OUT-BYTE  OUT-BYTE  OUT-BYTE  OUT-BYTE  OUT-BYTE  OUT-BYTE  OUT-BYTE  OUT-BYTE  OUT-BYTE  

The Play Sound opcode plays a sound with the specified parameters through the audio port on the top of the ESP32 card.  The audio port is at line level and requires amplification. 

The following parameters need to be specified in the following order:
* Attack, 4 bytes, Byte order is least signifigant byte to most significant byte.
* Decay, 4 bytes, Byte order is least signifigant byte to most significant byte.
* Sustain, 2 bytes, Byte order is least signifigant byte to most significant byte.
* Release, 4 bytes, Byte order is least signifigant byte to most significant byte.
* WaveType, 1 byte,   0=WAVE_SQUARE,1=WAVE_SINE,2=WAVE_TRIANGLE,3=WAVE_SAW,4=WAVE_NOISE
* Volume, 2 bytes,  Byte order is least signifigant byte to most significant byte.  Even though volume is specified as two bytes, only LSB is used.
* Duration, 2 bytes, Byte order is least signifigant byte to most significant byte.  Duration is in MS.
* FreqStart, 2 bytes, Byte order is least signifigant byte to most significant byte.
* FreqEnd, 2 bytes, Byte order is least signifigant byte to most significant byte.
* ModFreqMode, 1 byte,  0=MODFREQ_NONE,1=MODFREQ_TO_END,2=MODFREQ_TO_RELEASE,3=MODFREQ_TO_SUSTAIN

More detailed information about programming the sound generator can be found [HERE](http://www.fabglib.org/classfabgl_1_1_sound_generator.html)

Input Parameters: 24 bytes
Returns: None  

OP CODE|Description|Values
-------|-----------|------
14 |Set Volume| OUT-BYTE

The Set Volume opcode sets the overall volume of the sound generated by the audio port on the top of the ESP32 card.  The audio port is at line level and requires amplification.

Input Parameters: 1 byte - Volume
Returns: None  

## ESP32 Graphics Opcodes
OP CODE|Description|Values
-------|-----------|------
15 |Set Display Resolution| OUT-BYTE

The Set Display Resolution opcode sets the display resolution of the VGA output of the ESP32. The specified display resolution is stored in flash memory and will survive a power cycle.  Note that this opcode can take a SECOND OR MORE to process as it requires the ESP to reboot, so leave plenty of time after issuing this command. ALWAYS issue a Clear Display(17) command after changing video mode. 

The proper sequence is as follows:
* issue Set Display Resolution opcode
* send one byte for new video mode
* wait at least 3 seconds
* issue clear display command

ID|Mode Name|Description|Color Depth
--|---------|-----------|-----------
00|VGA_320x200_70Hz|320x200@70Hz resolution - the same of VGA_640x200_70Hz with horizontal halved|64
01|VGA_320x200_75Hz|320x200@75Hz resolution|64
02|VGA_320x200_75HzRetro|320x200@75Hz retro resolution|64
03|QVGA_320x240_60Hz|320x240@60Hz resolution|64
04|VGA_400x300_60Hz|400x300@60Hz resolution|64
05|VGA_480x300_75Hz|480x300@75Hz resolution|64
06|VGA_512x192_60Hz|512x192@60Hz resolution|16
07|VGA_512x384_60Hz	|512x384@60Hz resolution|16
08|VGA_512x448_60Hz|512x448@60Hz resolution|16
09|VGA_512x512_58Hz|512x512@58Hz resolution|16
10|VGA_640x200_60HzD|640x200@60Hz doublescan resolution|16
11|VGA_640x200_70Hz|640x200@70Hz resolution - the same of VGA_640x400_70Hz with vertical halved|16
12|VGA_640x200_70HzRetro|640x200@70Hz retro resolution|16
13|VGA_640x240_60Hz|640x240@60Hz (DoubleScan) resolution|16
14|VGA_640x350_70Hz|640x350@70Hz resolution|16
15|VGA_640x350_70HzAlt1|640x350@70HzAlt1 resolution|16
16|VESA_640x350_85Hz|640x350@85Hz resolution|16
17|VGA_640x382_60Hz|640x382@60Hz resolution|16
18|VGA_640x384_60Hz|640x384@60Hz resolution|16
19|VGA_640x400_70Hz|640x400@70Hz resolution|16
20|VGA_640x400_60Hz|640x400@60Hz (actually 640x480 but with less lines)|16
21|VGA_640x480_60Hz|640x480@60Hz resolution|16
22|VGA_640x480_60HzAlt1|640x480@60HzAlt1 resolution|16
23|VGA_640x480_60HzD|640x480@60Hz doublescan resolution|16
24|VGA_640x480_73Hz|640x480@73Hz resolution|16
25|VESA_640x480_75Hz|640x480@75Hz resolution|16
26|VGA_720x348_50HzD|720x348@50Hz doublescan resolution|16
27|VGA_720x348_59HzD|720x348@59Hz doublescan resolution|16
28|VGA_720x348_73Hz|720x348@73Hz resolution|16
29|VGA_720x350_70Hz|720x350@70Hz resolution|16
30|VGA_720x400_70Hz|720x400@70Hz resolution|16
31|VESA_720x400_85Hz|720x400@85Hz resolution|16
32|PAL_720x576_50Hz|720x576@50Hz resolution|8
33|VESA_768x576_60Hz|768x576@60Hz resolution|8
34|SVGA_800x300_60Hz|800x300@60Hz resolution|8
35|SVGA_800x600_56Hz|800x600@56Hz resolution|4
36|SVGA_800x600_60Hz|800x600@60Hz resolution|4
37|SVGA_960x540_60Hz|960x540@60Hz resolution|4
38|SVGA_1024x768_60Hz|1024x768@60Hz resolution|2
39|SVGA_1024x768_70Hz|1024x768@70Hz resolution|2
40|SVGA_1024x768_75Hz|1024x768@75Hz resolution|2
41|SVGA_1280x600_60Hz|1280x600@60Hz resolution|2
42|SVGA_1280x720_60Hz|1280x720@60Hz resolution|2
43|SVGA_1280x720_60HzAlt1|1280x720@60Hz resolution|2
44|SVGA_1280x768_50Hz|1280x768@50Hz resolution|2

Input Parameters: 1 byte - Video Mode
Returns: None  

OP CODE|Description|Values
-------|-----------|------
16 |Load Font| OUT-BYTE

The Load Font opcode sets the display font for the VGA ANSI Terminal.

ID|Font Name	
--|---------
00|FONT_4X6
01|FONT_5X7
02|FONT_5X8
03|FONT_6X8
04|FONT_6X9
05|FONT_6X10
06|FONT_6X12
07|FONT_6X13
08|FONT_7X13
09|FONT_7X14
10|FONT_8X8
11|FONT_8X9
12|FONT_8X13
13|FONT_8X14
14|FONT_8X16
15|FONT_8X19
16|FONT_9X15
17|FONT_9X18
18|FONT_10X20
19|FONT_BIGSERIF_8X14
20|FONT_BIGSERIF_8X16
21|FONT_BLOCK_8X14
22|FONT_BROADWAY_8X14
23|FONT_COMPUTER_8X14
24|FONT_COURIER_8X14
25|FONT_LCD_8X14
26|FONT_OLDENGL_8X16
27|FONT_SANSERIF_8X14
28|FONT_SANSERIF_8X16
29|FONT_SLANT_8X14
30|FONT_WIGGLY_8X16

Input Parameters: 1 byte - Font
Returns: None  

OP CODE|Description|Values
-------|-----------|------
17|Clear Display| NONE

The Clear Display opcode clears the VGA.

Input Parameters: None
Returns: None  

OP CODE|Description|Values
-------|-----------|------
18 |Copy Rectangle| OUT-BYTE OUT-BYTE OUT-BYTE OUT-BYTE OUT-BYTE OUT-BYTE OUT-BYTE OUT-BYTE OUT-BYTE OUT-BYTE OUT-BYTE OUT-BYTE

The Copy Rectangle opcode copyies a rectangle shaped area from one part of the bitmapped display to another.

The following parameters need to be specified in the following order:
* Source X coordinate, 2 bytes, Byte order is least signifigant byte to most significant byte.
* Source Y coordinate, 2 bytes, Byte order is least signifigant byte to most significant byte.
* Destination X coordinate, 2 bytes, Byte order is least signifigant byte to most significant byte.
* Destination Y coordinate, 2 bytes, Byte order is least signifigant byte to most significant byte.
* Area Width, 2 bytes, Byte order is least signifigant byte to most significant byte.
* Area Hight, 2 bytes, Byte order is least signifigant byte to most significant byte.

All Parameters above are in display pixels with 0,0 being the upper left of the VGA screen.

Input Parameters: 12 bytes
Returns: None  

OP CODE|Description|Values
-------|-----------|------
19 |Draw Bitmap| OUT-BYTE(s)

The Draw Bitmap opcode draws a specified bitmap on the VGA display.

The following parameters need to be specified in the following order:
* X coordinate, 2 bytes, Byte order is least signifigant byte to most significant byte.
* Y coordinate, 2 bytes, Byte order is least signifigant byte to most significant byte.
* Width, 2 bytes, Byte order is least signifigant byte to most significant byte.
* Hight, 2 bytes, Byte order is least signifigant byte to most significant byte.
* Pixel Format, 1 byte, FORMAT=1:NATIVE DEVICE(usually 1 BIT/PIXEL),2:MASK(1=OPAQUE 0=TRANSP),3: 8 BITS/PIXEL aabbggrr, 4:32 BITS/PIXEL RGBA
* Bitmap Length, 2 bytes, Byte order is least signifigant byte to most significant byte.
* Bitmap Data, X bytes, bitmap size cannot exceed 31.5K

Input Parameters: X bytes
Returns: None  

OP CODE|Description|Values
-------|-----------|------
20 |Draw Char| OUT-BYTE OUT-BYTE OUT-BYTE OUT-BYTE OUT-BYTE OUT-BYTE

The Draw Char opcode draws a specified character, at a specified location, in a specified font, in the current Pen color.

The following parameters need to be specified in the following order:
* X coordinate, 2 bytes, Byte order is least signifigant byte to most significant byte.
* Y coordinate, 2 bytes, Byte order is least signifigant byte to most significant byte.
* Character to Draw, 1 byte
* Font, 1 bytes, See Font Table from Set Font opcode

Input Parameters: 6 bytes
Returns: None  

OP CODE|Description|Values
-------|-----------|------
21 |Draw Ellipse| OUT-BYTE  OUT-BYTE  OUT-BYTE  OUT-BYTE  OUT-BYTE  OUT-BYTE  OUT-BYTE  OUT-BYTE  

The Draw Ellipse opcode draws an ellpise on the bitmapped display, in the current Pen color.

The following parameters need to be specified in the following order:
* X coordinate, 2 bytes, Byte order is least signifigant byte to most significant byte.
* Y coordinate, 2 bytes, Byte order is least signifigant byte to most significant byte.
* Width, 2 bytes, Byte order is least signifigant byte to most significant byte.
* Height, 2 bytes, Byte order is least signifigant byte to most significant byte.

Input Parameters: 6 bytes
Returns: None  

OP CODE|Description|Values
-------|-----------|------
22 |Draw Gliph| OUT-BYTE(s)

The Draw Glyph opcode draws a Glyph on the bitmapped display, in the current Pen color.

The following parameters need to be specified in the following order:
* X coordinate, 2 bytes, Byte order is least signifigant byte to most significant byte.
* Y coordinate, 2 bytes, Byte order is least signifigant byte to most significant byte.
* Width, 2 bytes, Byte order is least signifigant byte to most significant byte.
* Height, 2 bytes, Byte order is least signifigant byte to most significant byte.
* Index, 2 bytes, Byte order is least signifigant byte to most significant byte.  Usually 0, Use when the buffer contains multiple glyphs.
* Glyph Length, 2 bytes, Byte order is least signifigant byte to most significant byte.
* Glyph Data, X bytes, glyph size cannot exceed 255 bytes, and is stored as a 1 bit/pixel bitmap

Input Parameters: X bytes
Returns: None  

OP CODE|Description|Values
-------|-----------|------
23 |Draw Line| OUT-BYTE  OUT-BYTE  OUT-BYTE  OUT-BYTE  OUT-BYTE  OUT-BYTE  OUT-BYTE  OUT-BYTE  

The Draw Line opcode draws a line on the bitmapped display, in the current Pen color.

The following parameters need to be specified in the following order:
* Start X coordinate, 2 bytes, Byte order is least signifigant byte to most significant byte.
* Start Y coordinate, 2 bytes, Byte order is least signifigant byte to most significant byte.
* End X coordinate, 2 bytes, Byte order is least signifigant byte to most significant byte.
* End Y coordinate, 2 bytes, Byte order is least signifigant byte to most significant byte.

Input Parameters: 8 bytes
Returns: None  

OP CODE|Description|Values
-------|-----------|------
24 |Draw Rectangle| OUT-BYTE  OUT-BYTE  OUT-BYTE  OUT-BYTE  OUT-BYTE  OUT-BYTE  OUT-BYTE  OUT-BYTE  

The Draw Rectangle opcode draws a Rectangle on the bitmapped display, in the current Pen color.

The following parameters need to be specified in the following order:
* Start X coordinate, 2 bytes, Byte order is least signifigant byte to most significant byte.
* Start Y coordinate, 2 bytes, Byte order is least signifigant byte to most significant byte.
* End X coordinate, 2 bytes, Byte order is least signifigant byte to most significant byte.
* End Y coordinate, 2 bytes, Byte order is least signifigant byte to most significant byte.

Input Parameters: 8 bytes
Returns: None  

OP CODE|Description|Values
-------|-----------|------
25 |Draw Filled Ellipse| OUT-BYTE  OUT-BYTE  OUT-BYTE  OUT-BYTE  OUT-BYTE  OUT-BYTE  OUT-BYTE  OUT-BYTE  

The Draw Filled Ellipse opcode draws a filled ellipse on the bitmapped display, in the current Pen color, filled with the current Brush color.

The following parameters need to be specified in the following order:
* Start X coordinate, 2 bytes, Byte order is least signifigant byte to most significant byte.
* Start Y coordinate, 2 bytes, Byte order is least signifigant byte to most significant byte.
* width, 2 bytes, Byte order is least signifigant byte to most significant byte.
* Height, 2 bytes, Byte order is least signifigant byte to most significant byte.

Input Parameters: 8 bytes
Returns: None  

OP CODE|Description|Values
-------|-----------|------
26 |Draw Filled Rectangle| OUT-BYTE  OUT-BYTE  OUT-BYTE  OUT-BYTE  OUT-BYTE  OUT-BYTE  OUT-BYTE  OUT-BYTE  

The Draw Filled Rectangle opcode draws a filled rectangle on the bitmapped display, in the current Pen color, filled with the current Brush color.

The following parameters need to be specified in the following order:
* Start X coordinate, 2 bytes, Byte order is least signifigant byte to most significant byte.
* Start Y coordinate, 2 bytes, Byte order is least signifigant byte to most significant byte.
* End X coordinate, 2 bytes, Byte order is least signifigant byte to most significant byte.
* End Y coordinate, 2 bytes, Byte order is least signifigant byte to most significant byte.

Input Parameters: 8 bytes
Returns: None  

OP CODE|Description|Values
-------|-----------|------
27 |Get Pixel Value| OUT-BYTE  OUT-BYTE  OUT-BYTE  OUT-BYTE  IN-BYTE    IN-BYTE    IN-BYTE  

The Get Pixel Value opcode returns the current color value of the specified display pixel.

The following parameters need to be specified in the following order:
* X coordinate, 2 bytes, Byte order is least signifigant byte to most significant byte.
* Y coordinate, 2 bytes, Byte order is least signifigant byte to most significant byte.

The ESP will then return:
* Blue value, 1 byte
* Green value, 1 byte
* Red value, 1 byte

Input Parameters: 4 bytes
Returns: 3 bytes

OP CODE|Description|Values
-------|-----------|------
28 |Invert Rectangle| OUT-BYTE  OUT-BYTE  OUT-BYTE  OUT-BYTE  OUT-BYTE  OUT-BYTE  OUT-BYTE  OUT-BYTE  

The Invert Rectangle opcode will invert all of the pixels within a specified area on the bitmapped display.

The following parameters need to be specified in the following order:
* Start X coordinate, 2 bytes, Byte order is least signifigant byte to most significant byte.
* Start Y coordinate, 2 bytes, Byte order is least signifigant byte to most significant byte.
* End X coordinate, 2 bytes, Byte order is least signifigant byte to most significant byte.
* End Y coordinate, 2 bytes, Byte order is least signifigant byte to most significant byte.

Input Parameters: 8 bytes
Returns: None  

OP CODE|Description|Values
-------|-----------|------
29 |Draw A Line To| OUT-BYTE  OUT-BYTE  OUT-BYTE  OUT-BYTE

The Draw A Line To opcode will draw a line from the current graphics cursor position to the specified location on the bitmapped display.

The following parameters need to be specified in the following order:
* End X coordinate, 2 bytes, Byte order is least signifigant byte to most significant byte.
* End Y coordinate, 2 bytes, Byte order is least signifigant byte to most significant byte.

Input Parameters: 4 bytes
Returns: None  

OP CODE|Description|Values
-------|-----------|------
30 |Move Cursor To| OUT-BYTE  OUT-BYTE  OUT-BYTE  OUT-BYTE

The Move Cursor To opcode will move the graphics cursor to the specified location on the bitmapped display.

The following parameters need to be specified in the following order:
* End X coordinate, 2 bytes, Byte order is least signifigant byte to most significant byte.
* End Y coordinate, 2 bytes, Byte order is least signifigant byte to most significant byte.

Input Parameters: 4 bytes
Returns: None  

OP CODE|Description|Values
-------|-----------|------
31 |Scroll Display| OUT-BYTE  OUT-BYTE  OUT-BYTE  OUT-BYTE

The Scroll Display opcode will scroll the display by the specified offset.

The following parameters need to be specified in the following order:
* X Offset, 2 bytes, Byte order is least signifigant byte to most significant byte.  Left Scroll is accomplished by a negative offset
* Y Offset, 2 bytes, Byte order is least signifigant byte to most significant byte.  Up Scroll is accomplished by a negative offset

Input Parameters: 4 bytes
Returns: None  

OP CODE|Description|Values
-------|-----------|------
32 |Set Brush Color| OUT-BYTE

The Set Brush Color sets the brush color to the specified color index on the pallette.

Input Parameters: 1 byte - Color
Returns: None  

OP CODE|Description|Values
-------|-----------|------
33 |Set Line Ends| OUT-BYTE

The Set Line Ends sets the method for drawing line ends by the display renderer. 
* 0=NONE
* 1=ROUNDED

Input Parameters: 1 byte - End Type
Returns: None  

OP CODE|Description|Values
-------|-----------|------
34 |Set Pen Color| OUT-BYTE

The Set Pen Color sets the brush color to the specified color index on the pallette.

Input Parameters: 1 byte - Color
Returns: None  

OP CODE|Description|Values
-------|-----------|------
35 |Set Pen Width| OUT-BYTE

The Set Pen Width sets the width in pixels of the drawing pen.

Input Parameters: 1 byte - Pen Width
Returns: None  

OP CODE|Description|Values
-------|-----------|------
36 |Set Pixel| OUT-BYTE  OUT-BYTE  OUT-BYTE  OUT-BYTE  

The Set Pixel draws a pixel at the specified location in the current pen color.

The following parameters need to be specified in the following order:
* End X coordinate, 2 bytes, Byte order is least signifigant byte to most significant byte.
* End Y coordinate, 2 bytes, Byte order is least signifigant byte to most significant byte.

Input Parameters: 4 bytes
Returns: None 

OP CODE|Description|Values
-------|-----------|------
37 |Set Glyph Options| OUT-BYTE  OUT-BYTE  OUT-BYTE  OUT-BYTE  OUT-BYTE  OUT-BYTE  OUT-BYTE  

The Set Glpyh Options opcode sets optional parameters that modify how glyphs are rendered by Draw Glyph.

The following parameters need to be specified in the following order:
* blank, 1 byte, send 1 to cause glyph to be rendered in background color
* bold, 1 byte, send 1 to cause glyph to be rendered in bold
* doubleWidth, 1 byte, send 1 to cause glyph to be rendered double width
* FillBackground, 1 byte, send 1 to cause glyph to be rendered with background painted in the specified brush color
* Invert, 1 byte, send 1 to cause glyph to be rendered inverted
* Italic, 1 byte, send 1 to cause glyph to be rendered in italics
* Underline, 1 byte, send 1 to cause glyph to be rendered with an underline

Input Parameters: 7 bytes
Returns: None  

OP CODE|Description|Values
-------|-----------|------
38 |Set Pallette Item| OUT-BYTE  OUT-BYTE  OUT-BYTE  OUT-BYTE  

The Set Pallette Item opcode sets the rendered color for a given color index.

The following parameters need to be specified in the following order:
* Index, 1 byte, Color Index on Pallette (0-63 or 0-15, or 0-3, or 0-2 or 0-1 depending on screen color depth)
* Blue Value, 1 byte 
* Green Value, 1 byte
* Red Value, 1 byte

Input Parameters: 4 bytes
Returns: None  

OP CODE|Description|Values
-------|-----------|------
39 |Set Mouse Cursor Type| OUT-BYTE

The Set Mouse Cursor Type opcode sets the shape of the rendered mouse cursor.

ID|Description
--|-----------
0|11x11 Amiga like colored mouse pointer
1|10x15 mouse pointer
2|11x19 mouse pointer
3|11x19 shadowed mouse pointer
4|12x17 mouse pointer
5|16x16 pen
6|9x9 cross
7|11x11 cross
8|5x5 point
9|11x11 left arrow
10|11x11 right arrow
11|11x11 down arrow
12|11x11 up arrow
13|19x19 move
14|12x12 resize orientation 1
15|12x12 resize orientation 2
16|11x17 resize orientation 3
17|17x11 resize orientation 4
18|7x15 text input

Input Parameters: 1 byte - Mouse Cursor Type
Returns: None  

OP CODE|Description|Values
-------|-----------|------
40 |Set Mouse Cursor Position| OUT-BYTE  OUT-BYTE  OUT-BYTE  OUT-BYTE  

The Set Mouse Cursor Position opcode sets the display position of the mouse cursor.

The following parameters need to be specified in the following order:
* X coordinate, 2 bytes, Byte order is least signifigant byte to most significant byte.
* Y coordinate, 2 bytes, Byte order is least signifigant byte to most significant byte.

Input Parameters: 4 bytes
Returns: None  

OP CODE|Description|Values
-------|-----------|------
41 |Clear Sprites| NONE

The Clear Sprites opcode clears the sprite shape table.

Input Parameters: None  
Returns: None  

OP CODE|Description|Values
-------|-----------|------
42 |Set Sprite Map| OUT-BYTE(s)

setSpriteMap	42		*AWAYS SET THE HIGHEST INDEX SPRITE LAST, AND THE MAX CONFIGURED SPRITE NUMBER IS 31. (0-32)

The Set Sprite Map opcode sets the shape for a specified sprite.   There are 32 sprites (0-31) available with the current firmware and it is important to set the highest # sprite used LAST.   

The following parameters need to be specified in the following order:
* Sprite Index, 1 byte
* Sprite Width, 2 bytes, Byte order is least signifigant byte to most significant byte.
* Sprite Hight, 2 bytes, Byte order is least signifigant byte to most significant byte.
* Pixel Format, 1 byte, FORMAT=1:NATIVE DEVICE(usually 1 BIT/PIXEL),2:MASK(1=OPAQUE 0=TRANSP),3: 8 BITS/PIXEL aabbggrr, 4:32 BITS/PIXEL RGBA
* Sprite Length, 2 bytes, Byte order is least signifigant byte to most significant byte.
* Sprite Data, X bytes, bitmap size cannot exceed 31.5K

Input Parameters: X bytes
Returns: None  

OP CODE|Description|Values
-------|-----------|------
43 |Set Sprite Location| OUT-BYTE   OUT-BYTE   OUT-BYTE   OUT-BYTE   OUT-BYTE  

The Set Sprite Location opcode moves a specified sprite to a specified location.

The following parameters need to be specified in the following order:
* X Coordinate Location, 2 bytes, Byte order is least signifigant byte to most significant byte.
* Y Coordinate Location, 2 bytes, Byte order is least signifigant byte to most significant byte.
* Sprite Index, 1 byte

Input Parameters: 5 bytes
Returns: None  

OP CODE|Description|Values
-------|-----------|------
44 |Set Sprite Visibility| OUT-BYTE  OUT-BYTE  

The Set Sprite Visibility opcode sets the visibility of a specified sprite.

The following parameters need to be specified in the following order:
* Sprite Index, 1 byte
* Visible, 1 byte, 0= hidden, 1=visible

Input Parameters: 2 bytes
Returns: None  

### ESP32 ESP1 Opcode Reference

## ESP32 Misc Opcodes

OP CODE|Description|Values
-------|-----------|------
00|NO OPERATION|NONE

The NO OPERATION opcode is used to sync the ESP32 communications stream to a known state, "Waiting for opcode".

Input Parameters: None  
Returns: None  

OP CODE|Description|Values
-------|-----------|------
255|DISCOVER|"E" "S" "P" "3" "2" "V" "1"

The DISCOVER opcode is used by host systems to verify the presence and version of the ESP hardware and firmware.

Input Parameters: None  
Returns: 7 bytes - "E" "S" "P" "3" "2" "V" "1"  

## ESP32 WiFi Opcodes
OP CODE|Description|Values
-------|-----------|------
1 |WiFi Set SSID| OUT-BYTE(s)

The WiFi Set SSID opcode stores a null terminated string in the ESP flash memory and will survive a power cycle.  This value is then used during WiFi Connection.

Input Parameters: X bytes - string terminated by a null  
Returns: None  

OP CODE|Description|Values
-------|-----------|------
2 |WiFi Set Password| OUT-BYTE(s)
The WiFi Set WiFi Password opcode stores a null terminated string in the ESP flash memory and will survive a power cycle.  This value is then used during WiFi Connection.

Input Parameters: X bytes - string terminated by a null  
Returns: None  

OP CODE|Description|Values
-------|-----------|------
3 |WiFi Connect| None

The WiFi Connect opcode will attempt to connect to a WiFI access point using the stored configuration information.  If No TCP/IP address information is configured, DHCP will be attempted.

Input Parameters: None  
Returns: None  

OP CODE|Description|Values
-------|-----------|------
4 |WiFi Get Status| IN-BYTE  

The WiFi Get Status opcode returns the current WiFi status.

Status Byte|Description
-----------|-----------
0|WL_IDLE_STATUS
1|WL_NO_SSID_AVAIL
2|WL_SCAN_COMPLETED
3|WL_CONNECTED
4|WL_CONNECT_FAILED
5|WL_CONNECTION_LOST
6|WL_DISCONNECTED

Input Parameters: None  
Returns: 1 byte - WiFi Status

OP CODE|Description|Values
-------|-----------|------
5 |WiFi Get Signal Strength| IN-BYTE  

The WiFi Get Signal Strength opcode returns the current WiFi signal strength.

Input Parameters: None  
Returns: 1 bytes- Signal Strength  

## ESP32 TCP/IP Opcodes

OP CODE|Description|Values
-------|-----------|------
12|Get IP Address| IN-BYTE   IN-BYTE   IN-BYTE   IN-BYTE

The Get IP Address opcode returns the current IP address.

Input Parameters: None  
Returns: 4 bytes (octet 1,2,3,4)  

OP CODE|Description|Values
-------|-----------|------
13 |Get Subnet Mask| IN-BYTE   IN-BYTE   IN-BYTE   IN-BYTE

The Get Subnet Mask opcode returns the current submet mask.

Input Parameters: None  
Returns: 4 bytes (octet 1,2,3,4)  

OP CODE|Description|Values
-------|-----------|------
14 |Get Gateway| IN-BYTE   IN-BYTE   IN-BYTE   IN-BYTE

The Get Gateway opcode returns the current IP default gateway.

Input Parameters: None  
Returns: 4 bytes (octet 1,2,3,4)  

OP CODE|Description|Values
-------|-----------|------
15 |Get Primary DNS| IN-BYTE   IN-BYTE   IN-BYTE   IN-BYTE

The Get Primary DNS returns the current primary DNS address.

Input Parameters: None  
Returns: 4 bytes (octet 1,2,3,4)  

OP CODE|Description|Values
-------|-----------|------
16 |Get Secondary DNS| IN-BYTE   IN-BYTE   IN-BYTE   IN-BYTE

The Get Secondary DNS opcode returns the current secondary DNS IP address.

Input Parameters: None  
Returns: 4 bytes (octet 1,2,3,4)  

OP CODE|Description|Values
-------|-----------|------
17 |Set IP Address| OUT-BYTE   OUT-BYTE   OUT-BYTE   OUT-BYTE

The Set IP Address opcode sets the IP address. 0.0.0.0 value enables DHCP.

Input Parameters: 4 bytes (octet 1,2,3,4)  
Returns: None  

OP CODE|Description|Values
-------|-----------|------
18 |Set Subnet Mask| OUT-BYTE   OUT-BYTE   OUT-BYTE   OUT-BYTE   OUT-BYTE  

The Set Subnet Mask opcode sets the subnet mask.

Input Parameters: 4 bytes (octet 1,2,3,4)  
Returns: None  

OP CODE|Description|Values
-------|-----------|------
19 |Set Gateway	| OUT-BYTE   OUT-BYTE   OUT-BYTE   OUT-BYTE   OUT-BYTE  

The Set Gateway	opcode sets the Gateway IP Address.

Input Parameters: 4 bytes (octet 1,2,3,4)  
Returns: None  

OP CODE|Description|Values
-------|-----------|------
20 |Set Primary DNS| OUT-BYTE   OUT-BYTE   OUT-BYTE   OUT-BYTE   OUT-BYTE  

The Set Primary DNS opcode sets the primary DNS IP address.

Input Parameters: 4 bytes (octet 1,2,3,4)  
Returns: None  

OP CODE|Description|Values
-------|-----------|------
21 |Set Secondary DNS| OUT-BYTE   OUT-BYTE   OUT-BYTE   OUT-BYTE   OUT-BYTE  

The Set Secondary DNS opcode sets the secondary DNS IP address.

Input Parameters: 4 bytes (octet 1,2,3,4)  
Returns: None  

OP CODE|Description|Values
-------|-----------|------
22 |Set Hostname| OUT-BYTE(s)

The Set Hostname opcode stores a null terminated string in the ESP flash memory and will survive a power cycle.  This value is then used during WiFi Connection.

Input Parameters: X bytes - string terminated by a null  
Returns: None  

OP CODE|Description|Values
-------|-----------|------
23 |Create Outgoing Connection| OUT-BYTEs

The Create Outgoing Connection opcode creates an outgoing TCP/IP socket connection to a specified host.

The following parameters need to be specified in the following order:
* Connection Number, 1 byte, Must be from 1-63, connection 0 is reserved for incoming connections.
* Port, 2 bytes, Byte order is least signifigant byte to most significant byte.
* Hostname, x bytes, null terminated string.

Input Parameters: x bytes
Returns: None  

OP CODE|Description|Values
-------|-----------|------
24 |Set Incoming Port| OUT-BYTE   OUT-BYTE

The Set Incoming Port opcode sets listen port for connection 0.

The following parameters need to be specified in the following order:
* Port Number, 2 bytes, Byte order is least signifigant byte to most significant byte.

Input Parameters: 2 bytes
Returns: None  

OP CODE|Description|Values
-------|-----------|------
25 |Out Byte to Connection#| OUT-BYTE   OUT-BYTE

The Out Byte to Connection# opcode sends a byte to the specified connection.

The following parameters need to be specified in the following order:
* Connetion #, 1 byte
* Char, 1 byte

Input Parameters: 2 bytes
Returns: None  

OP CODE|Description|Values
-------|-----------|------
26 |Out String to Connection#| OUT-BYTE   OUT-BYTE(s)

The Out String to Connection# opcode sends a null terminated string to the specified connection.

The following parameters need to be specified in the following order:
* Connetion #, 1 byte
* string, x bytes null terminated

Input Parameters: x bytes
Returns: None  

OP CODE|Description|Values
-------|-----------|------
27 |In Byte From Connection#| OUT-BYTE   IN-BYTE

The In Byte From Connection# opcode returns a byte from the connection communication buffer.  If there are no values in the buffer, the opcode will return a null.  

Input Parameters: 1 byte - Connection Number  
Returns: 1 byte - input value or null    

OP CODE|Description|Values
-------|-----------|------
28 |Chars in Buffer from Connection#| OUT-BYTE   IN-BYTE   OUT-BYTE   OUT-BYTE   OUT-BYTE  

The Chars in Buffer from Connection# opcode returns the numbser of bytes in the connection communication buffer.  This port is exposed through the header on the top of the card and through the USB port on the ESP32 module.   

Input Parameters: 1 byte - Connection Number  
Returns: 1 byte - number of bytes in the buffer 

OP CODE|Description|Values
-------|-----------|------
30 |Get MAC Address| IN-BYTE  IN-BYTE  IN-BYTE  IN-BYTE  IN-BYTE  IN-BYTE    

The Get Mac Address opcode returns the six byte MAC address of the ESP32

The following information is returned in the following order:
* MAC Address, 6 bytes

Input Parameters: None  
Returns: 6 bytes  

## ESP32 Serial Opcodes

OP CODE|Description|Values
-------|-----------|------
6 |Set Baud Rate| OUT-BYTE  OUT-BYTE  OUT-BYTE  OUT-BYTE

The Set Baud Rate opcode sets the baud rate for the ESP async serial port.  This port is exposed through the header on the top of the card and through the USB port on the ESP32 module.   Byte order is least signifigant byte to most significant byte.

Input Parameters: 4 bytes - Baud Rate
Returns: None  

OP CODE|Description|Values
-------|-----------|------
7 |Set Serial Mode| OUT-BYTE

The Set Serial Mode opcode sets the serial communication parameters for the ESP async serial port.  This port is exposed through the header on the top of the card and through the USB port on the ESP32 module.
Parameters are set as follows:
* 0 = 8 data bits, no parity, 1 stop bits
* 1 = 8 data bits, even parity, 1 stop bits
* 2 = 8 data bits, odd parity, 1 stop bits
* 3 = 7 data bits, no parity, 1 stop bits
* 4 = 7 data bits, even parity, 1 stop bits
* 5 = 7 data bits, odd parity, 1 stop bits

Input Parameters: 1 byte - Serial Mode  
Returns: None  

OP CODE|Description|Values
-------|-----------|------
8 |Serial TX Single char| OUT-BYTE

The Serial TX Single char opcode transmits a single byte through the serial communication port.  This port is exposed through the header on the top of the card and through the USB port on the ESP32 module.

Input Parameters: 1 byte - char  
Returns: None  

OP CODE|Description|Values
-------|-----------|------
9 |Serial TX Null Terminated String| OUT-BYTE  OUT-BYTE  OUT-BYTE  OUT-BYTE  OUT-BYTE  OUT-BYTE	…	…	…	…	NULL

The Serial TX Null Terminated String opcode transmits a null terminated string through the serial communication port.  This port is exposed through the header on the top of the card and through the USB port on the ESP32 module.

Input Parameters: X bytes - string terminated by a null  
Returns: None  

OP CODE|Description|Values
-------|-----------|------
10 |Serial RX| IN-BYTE

The Serial RX opcode returns a byte from the serial communication port buffer.  If there are no values in the buffer, the opcode will return a null.  This port is exposed through the header on the top of the card and through the USB port on the ESP32 module.   

Input Parameters: None  
Returns: 1 byte - input value or null    

OP CODE|Description|Values
-------|-----------|------
11 |Chars in Serial Buffer| IN-BYTE

The Chars in Serial Buffer opcode returns the numbser of keystrokes in the serial communication port buffer.  This port is exposed through the header on the top of the card and through the USB port on the ESP32 module.   

Input Parameters: None  
Returns: 1 byte - serial buffer length  

## ESP32 Mouse Opcodes
OP CODE|Description|Values
-------|-----------|------
29 |Get Mouse| IN-BYTE  IN-BYTE  IN-BYTE  IN-BYTE  IN-BYTE  IN-BYTE  IN-BYTE  IN-BYTE  

GetMouse	29	left btn	middle btn	right btn	Wheel Delta	X	X	Y	Y

The Get Mouse opcode gets the current mouse information.

The following information is returned in the following order:
* Left Button Status, 1 byte
* Middle Button Status, 1 byte
* Right Button Status, 1 byte
* Wheel location Delta, 1 byte
* X Coordinate Location, 2 bytes, Byte order is least signifigant byte to most significant byte.
* Y Coordinate Location, 2 bytes, Byte order is least signifigant byte to most significant byte.

Input Parameters: None  
Returns: 8 bytes  

### TO DO
* Improve formatting of README file
* Complete espconf program
* add better status messages to testesp.c
* add API for getting the MAC address

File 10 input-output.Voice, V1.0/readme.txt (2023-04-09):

The input-output.Voice board is a specialized audio board for speech.  It contains a CTS256A-AL2 and SP0256A-AL2 text to speech (TTS) chipset, a DAC and ADC for audio frequencies, and left and right channel sound synthesis (SN76489N) chips.  There is a mixer combining all four sources of audio to output to either onboard speakers and/or headphone jack.  Also includes a microphone jack for ADC recording voice audio.

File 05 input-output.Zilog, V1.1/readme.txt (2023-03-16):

The input-output.Zilog board provides system timer/counter, dual serial ports, and dual general purpose parallel IO.  It also supports a dedicated controller for extended interrupts.  Designed for IM2, it is intended to be the primary console interface.

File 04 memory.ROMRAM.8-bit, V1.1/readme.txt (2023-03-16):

The memory.ROMRAM board is an 8-bit wide memory board of up to 4MB of Flash ROM and/or SRAM in 512KB increments.  For booting the system, Flash ROM must be in the first position.  Supports RTC and limited user debugging features.

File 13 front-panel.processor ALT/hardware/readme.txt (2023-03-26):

The 4-slot backplane is for the initial prototyping phase of the system.  It can also be used for creating a minimum sized unit.  

The minimum boards for a complete system are: 1) backplane, 2) processor, and 3) ROM & RAM; assumes using processor debug serial port as console

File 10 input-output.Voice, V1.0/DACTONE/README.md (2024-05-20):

## About

DACTONE is a CP/M-80 program running under RomWBW that is used to send
a sine wave of a specified frequency to the digital-to-analog
converter
[DAC0800](https://www.ti.com/lit/ds/symlink/dac0800.pdf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)
on the Duodyne Voice board. 

This image shows the output of the DAC from the command `dactone 440`
when disconnected from the LM741 op amp and its resistors. The DAC
outputs are connected to the positive and negative supplies using 4700 ohm
registors as shown on the first page of the linked datasheet. 

DAC output

## Usage

    usage: dactone [-v] [-s] frequency
         -v         Show verbose output.
         -s         Send samples (four seconds) to SIO0 Channel A instead of the DAC.

         frequency  The frequency of the tone to generate.

## Serial Debug Mode

Using the `-s` option tells DACTONE to send the audio samples to port
A of the SIO on the Duodyne Zilog peripherals board *instead* of to
the DAC. About four seconds of samples are sent. The serial port is
configured by DACTONE for 115200 baud, N81.

A WAV file header is sent so the resulting samples can be played on a
PC.

### Serial capture and playback on the Mac

Capturing the samples under MacOS is a two step process. First, before
running DACTONE on the Duodyne system, you have to `cat` the serial
adapter device that is connected to SIO PORT A to a file:

    cat /dev/cu.usbserial-AC013VEM > test.wav

Then, in a separate terminal, set the USB serial adapter baud rate:

    stty -f /dev/cu.usbserial-AC013VEM 115200

The `stty` command has do be done while the `cat` command above is
running.

Once DACTONE playback is done, stop the `cat` program with Control-C,
then use `afplay` to play the received tone:

    afplay test.wav

### Serial capture and playback on Linux

To capture the samples from the serial port for Linux, I'd suggest
using the `socat` program, which may need to be installed for
your version of Linux.

Identify the device name for the USB serial adapter. On my system,
that is `/dev/ttyUSB0`. Use the `stty` program to set the baud
rate to 115200:

    stty -F /dev/ttyUSB0 115200

Then run this `socat` command:

    socat stdio /dev/ttyUSB0 > test.wav

Run the DACTONE program in serial debug mode on your Duodyne machine:

    A>dactone -s 440

When playback is complete, stop the `socat` program on your Linux machine
by using Control-C. The play the received tone using `aplay`:

    aplay test.wav

## Technical Notes

The program uses Channel 3 of the second CTC chip to generate an
approximately 8 kHz interrupt. The CTC runs at 7,372,800 Hz and is
programmed to use a divide-by-16 prescalar. The time constant is
programmed with $058D, giving

    7,372,800 / 16 / 58 = 7944 Hz

The interrupt handler is configued to use slot 11 of the RomWBW
interrupt table.

The sample data is generated from a 1024-entry sine wave table. A
phase incrementer loop is used to generate the required samples for
the input frequency given an 8 kHz sample rate. These samples are
placed in a buffer for use by the interrupt handler before the handler
starts. The interrupt handler then sends samples to the DAC from a
single circular buffer. This continues until either the user presses a
key or about four seconds have elapsed in serial debug mode.

The system tick timer is disabled during playback to the DAC and
restored when done.

## Building

The program is written in C and Z80 assembly using the
[Z88DK](https://z88dk.org/site/) development kit. Assuming you have
z88dk installed and have configured the environment (see
`set_environment.sh`), you can just run `make` to build the code.
There is a pre-compiled binary available.

## License

Copyright 2024 Rob Gowin

All files here are licensed using GPL version 2.0 or later. See
[COPYING](COPYING.md).

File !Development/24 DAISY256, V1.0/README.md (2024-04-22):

DAISY256 is an experimental project board to determine if the CTS256A-AL2 can be replaced with TMS7xxx microcontrollers in microprocessor mode using an external boot ROM.

It is not intended to be a general purpose text to speech board.

The DAISY256 is inspired by:

https://github.com/mecparts/Talker
https://github.com/GmEsoft/CTS256A-AL2
https://github.com/jim11662418/CTS256-SP0256
https://www.smbaker.com/cts256a-al2-text-to-speech-board

Important Setup Notes:
* default serial parameters are 9600, 8 data bits, No Parity, 1 stop bit, RTS/CTS handshaking
* mecparts Talker exception ROM must be installed in Expansion ROM socket
* 6116 SRAM (200-300 ns) must be installed in Buffer socket

Fixes:
* check Plot -> Component Labels for Gerbers
* add power switch
* add power LED
* add logic probe VCC and GND loops
* convert power to LM7805 and reverse voltage protection diode

20 Apr 2024: Built DAISY256 prototype, confirmed control works per mecparts Talker. Mode jumper installed (full expansion mode, not microprocessor mode)

20 Apr 2024: installed Boot EPROM (2732 contains CTS256 recovered firmware), removed mode jumper.  Confirmed CTS256 is able to boot from external EPROM.  Works just like internal firmware.

20 Apr 2024: replaced CTS256 with TMS7001.  Works fine, says "OK" on reset.  Accepts input from serial port.  Acts just like a CTS256.

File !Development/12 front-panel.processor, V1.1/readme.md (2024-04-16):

The front-panel board connects to the Z80 processor to allow local access to configuration status input and display.  Also supports TTL serial to USB connection, an SSD1306 OLED display, and an I2C to SD card.  Several Z80 processor parameters can be set along with a reset button.

The I2C to SD card uses an ATtiny microcontroller which requires programming to work.  It is modeled after the I2C to SD card project at Technoblogy (http://www.technoblogy.com/show?3XEP)

Firmware for the card can be built and programed from the Arduino project located in the ATTINY_SD_FIRMWARE folder in this repo

You can program your ATtiny using the Arduino IDE for Linux 1.8.13 available here: https://www.arduino.cc/en/software/OldSoftwareReleases

with the megaTinyCore available here: https://wolles-elektronikkiste.de/en/using-megatinycore#usb2ttl_adaper_as_updi

I used a 3.3V TTL serial to USB cable direct to the UPDI connector on the front-panel and it worked fine. Following the instructions, I was able to successfully program the ATtiny1614 in-circuit. Alternatively, you can use pymcuprog on Linux.  Just follow the instructions here:https://pypi.org/project/pymcuprog/

For example, I was able to "ping" the ATtiny1614 and get a verbose status using: pymcuprog ping -d attiny1614 -t uart -u /dev/ttyUSB0 -v debug

Once programmed the ATTINY will respond to the I2C address 0x25.   This address can be updated in the code by changing the line 
```
const int MyAddress = 0x25;
```

The communication flow to the SD-I2C controller is very simple.  There are only 4 commands (I)nfo, (S)et block, (R)ead, (W)rite.  The SD-I2C controller expects a FAT formatted SD card with an raw HDD image file in the root directory called "IMAGE.IMG".   Cubix, DOS/65, or RomWBW image files should work without modification.

```
Info Command:
   Send one I2C data frame containing a single byte:  'I'   (This tells the controller to put the SD information in the buffer)
   Send one I2C data frame containing a single byte:  'R'   (This tells the controller that the host system wants to read the buffer)
   Read one I2C data frame -- should return 6 bytes:  'S' 'D' Byte1 Byte2 Byte3 Byte4  (the 4 bytes is one Double word containing the length in bytes of the image file- Big Endian)
   
Set Block Command:
   Send one I2C data frame containing 5 bytes:  'S' Byte1 Byte2 Byte3 Byte4  (the 4 bytes is one Double word containing the LBA block number that you wish to access in the image file- Big Endian)  
   
Read Command:
   Send one I2C data frame containing a single byte:  'R'   (This tells the controller that the host system wants to read the buffer)
   Read one I2C data frame -- should return 512 bytes 

Write Command:
   Send one I2C data frame containing  513 bytes:  'W' (512 bytes of sector data)  
```

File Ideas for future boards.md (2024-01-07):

Ideas for future duodyne boards

* Media IO: V9938/V9958 VDP and AY-3-8910 PSG with joysticks/pots

* Voice IO: CTS256/SPO256 Text-To-Voice, ADC/DAC, dual SN76489 sound generators

* GDC IO: VGA compatible uPD7220 16-color graphics

* Text IO: VGA compatible uPD7220 monochrome text

* VDCENET: MOS8568 VDC, RTL8019AS wired Ethernet

* Z180 processor

* 8032 MCU processor

* Merged uPD7220 graphics and text board

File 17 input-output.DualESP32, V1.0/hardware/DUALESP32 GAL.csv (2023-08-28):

~CSxESP | ~bRD | ~bWR | bA0 | bA1 | ~PRExESP0xRD | ~PRExESP1xRD | ~PRExESP0xWR | ~PRExESP1xWR | ~ESPxSTAT
0 | 0 | 0 | 0 | 0 | 0 | 1 | 0 | 1 | 1
0 | 0 | 0 | 0 | 1 | 1 | 1 | 1 | 1 | 0
0 | 0 | 0 | 1 | 0 | 1 | 0 | 1 | 0 | 1
0 | 0 | 0 | 1 | 1 | 1 | 1 | 1 | 1 | 0
0 | 0 | 1 | 0 | 0 | 0 | 1 | 1 | 1 | 1
0 | 0 | 1 | 0 | 1 | 1 | 1 | 1 | 1 | 0
0 | 0 | 1 | 1 | 0 | 1 | 0 | 1 | 1 | 1
0 | 0 | 1 | 1 | 1 | 1 | 1 | 1 | 1 | 0
0 | 1 | 0 | 0 | 0 | 1 | 1 | 0 | 1 | 1
0 | 1 | 0 | 0 | 1 | 1 | 1 | 1 | 1 | 1
0 | 1 | 0 | 1 | 0 | 1 | 1 | 1 | 0 | 1
0 | 1 | 0 | 1 | 1 | 1 | 1 | 1 | 1 | 1
0 | 1 | 1 | 0 | 0 | 1 | 1 | 1 | 1 | 1
0 | 1 | 1 | 0 | 1 | 1 | 1 | 1 | 1 | 1
0 | 1 | 1 | 1 | 0 | 1 | 1 | 1 | 1 | 1
0 | 1 | 1 | 1 | 1 | 1 | 1 | 1 | 1 | 1
1 | 0 | 0 | 0 | 0 | 1 | 1 | 1 | 1 | 1
1 | 0 | 0 | 0 | 1 | 1 | 1 | 1 | 1 | 1
1 | 0 | 0 | 1 | 0 | 1 | 1 | 1 | 1 | 1
1 | 0 | 0 | 1 | 1 | 1 | 1 | 1 | 1 | 1
1 | 0 | 1 | 0 | 0 | 1 | 1 | 1 | 1 | 1
1 | 0 | 1 | 0 | 1 | 1 | 1 | 1 | 1 | 1
1 | 0 | 1 | 1 | 0 | 1 | 1 | 1 | 1 | 1
1 | 0 | 1 | 1 | 1 | 1 | 1 | 1 | 1 | 1
1 | 1 | 0 | 0 | 0 | 1 | 1 | 1 | 1 | 1
1 | 1 | 0 | 0 | 1 | 1 | 1 | 1 | 1 | 1
1 | 1 | 0 | 1 | 0 | 1 | 1 | 1 | 1 | 1
1 | 1 | 0 | 1 | 1 | 1 | 1 | 1 | 1 | 1
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

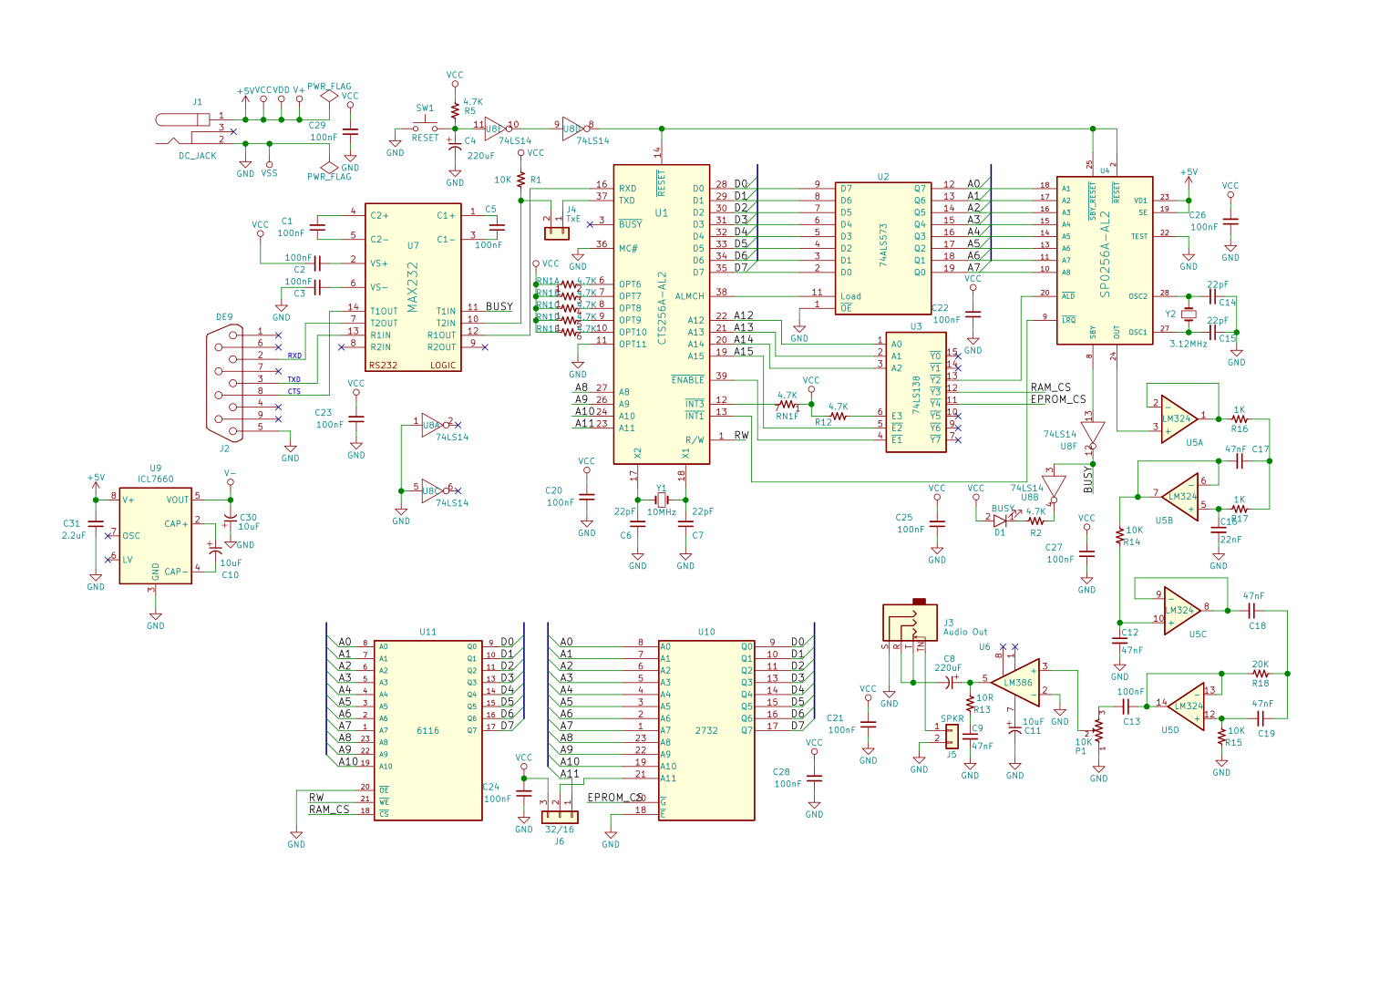
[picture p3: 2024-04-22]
!Development/24 DAISY256, V1.0/temp/Talker_schematic.png

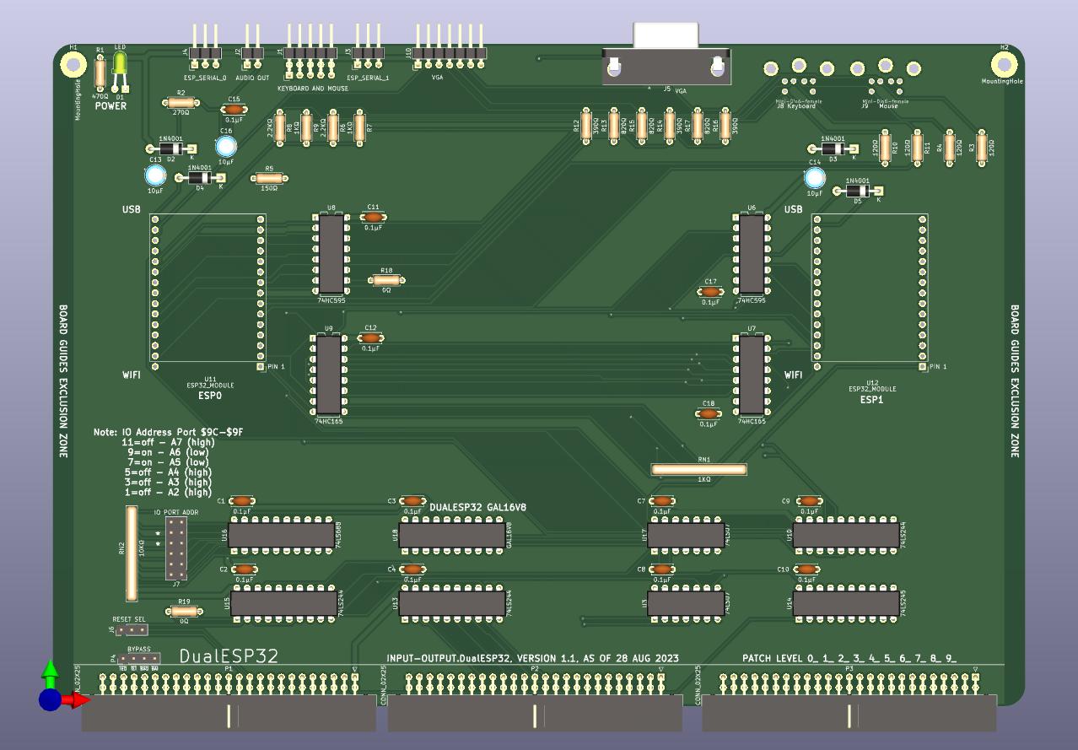
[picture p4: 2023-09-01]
17 input-output.DualESP32, V1.0/hardware/input-output.DualESP32.jpg

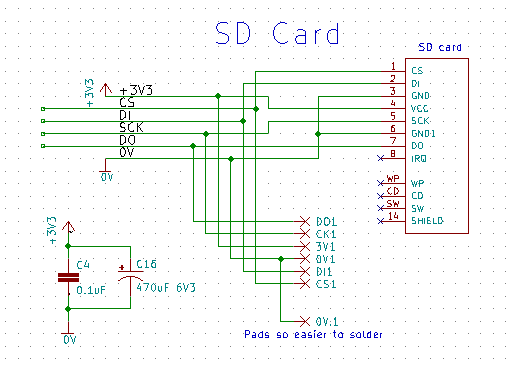
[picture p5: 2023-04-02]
08 input-output.Disk, V1.0/temp/SD-Card_Schematic.png

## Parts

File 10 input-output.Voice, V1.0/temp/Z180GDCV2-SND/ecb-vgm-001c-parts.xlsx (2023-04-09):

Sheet: Sheet1
"Ref","Qnty","Value","Cmp name","Footprint","Description","Vendor"
"C1, C2, C3, C4, C7, C8, C10, C18, C19, C22, C23, C28, C29, C50, ","14","0.1uF","C","Capacitor_THT:C_Disc_D7.0mm_W2.5mm_P5.00mm"," | Unp | olarized capacitor",""
"C5, C20, C21, C34, C35, ","5","470uF","CP","Capacitor_THT:CP_Radial_D8.0mm_P2.50mm","Polarized capacitor",""
"C6, ","1","100uF","CP","Capacitor_THT:CP_Radial_D5.0mm_P2.50mm","Polarized capacitor",""
"C24, C25, ","2","100uF","CP","Capacitor_THT:CP_Radial_D8.0mm_P2.50mm","Polarized capacitor",""
"C26, C27, C36, C37, C39, C41, ","6","10uF","C","Capacitor_THT:CP_Radial_D5.0mm_P2.50mm","Unpolarized capacitor",""
"C30, C31, ","2","470pF","C","Capacitor_THT:C_Disc_D3.8mm_W2.6mm_P2.50mm","Unpolarized capacitor",""
"C32, C33, ","2","1uF","C","Capacitor_THT:C_Disc_D7.0mm_W2.5mm_P5.00mm","Unpolarized capacitor",""
"C38, C46, ","2","220pF","C","Capacitor_THT:C_Disc_D3.8mm_W2.6mm_P2.50mm","Unpolarized capacitor",""
"C40, C47, ","2","1uF","C","Capacitor_THT:CP_Radial_D5.0mm_P2.50mm","Unpolarized capacitor",""
"C42, C43, C44, C45, ","4","5.6nF","C","Capacitor_THT:C_Disc_D3.8mm_W2.6mm_P2.50mm","Unpolarized capacitor",""
"CX1, CX2, ","2","0.1uF","C","Capacitor_THT:C_Disc_D7.0mm_W2.5mm_P5.00mm","Unpolarized capacitor",""
"H1, ","1","MountingHole","MountingHole","MountingHole:MountingHole_5mm","Mounting Hole without connection",""
"J1, ","1","Barrel_Jack","Barrel_Jack","Connector_BarrelJack:BarrelJack_Horizontal","DC Barrel Jack",""
"J3, ","1","Conn_01x04","Conn_01x04","TerminalBlock:TerminalBlock_bornier-4_P5.08mm","Generic connector, single row, 01x04, script | ge | nerated (kicad-library-utils/schlib/autogen/connector/)",""
"JP1, ","1","Jumper_3_Open","Jumper_3_Open","Connector_PinHeader_2.54mm:PinHeader_1x03_P2.54mm_Vertical","Jumper, 3-pole, both ope | n", | ""
"L1, L2, ","2","33uH","INDUCTOR","Inductor_THT:L_Axial_L6.6mm_D2.7mm_P10.16mm_Horizontal_Vishay_IM-2","Inductor symbol for simulat | ion | only",""
"R1, R3, R4, R5, R6, R7, ","6","2K2","R","Resistor_THT:R_Axial_DIN0207_L6.3mm_D2.5mm_P10.16mm_Horizontal","Resistor",""
"R2, R13, ","2","51K","R","Resistor_THT:R_Axial_DIN0207_L6.3mm_D2.5mm_P10.16mm_Horizontal","Resistor",""
"R8, R9, R14, R15, R16, R17, ","6","10K","R","Resistor_THT:R_Axial_DIN0207_L6.3mm_D2.5mm_P10.16mm_Horizontal","Resistor",""
"R10, R11, ","2","10R","R","Resistor_THT:R_Axial_DIN0207_L6.3mm_D2.5mm_P10.16mm_Horizontal","Resistor",""
"R12, R20, ","2","47K","R","Resistor_THT:R_Axial_DIN0207_L6.3mm_D2.5mm_P10.16mm_Horizontal","Resistor",""
"R18, R19, ","2","33K","R","Resistor_THT:R_Axial_DIN0207_L6.3mm_D2.5mm_P10.16mm_Horizontal","Resistor",""
"RN1, ","1","22K","R_Network08","Resistor_THT:R_Array_SIP9","8 resistor network, star topology, bussed resistors, small symbol",""
"RV1, ","1","10K","R_POT_Dual","Potentiometer_THT:Potentiometer_Alps_RK097_Dual_Horizontal","Dual potentiometer",""
"RV2, RV3, ","2","10K","R_POT_TRIM","Potentiometer_THT:Potentiometer_Bourns_3339P_Vertical","Trim-potentiometer",""
"SW1, ","1","ADDR","Conn_02x06_Odd_Even","Connector_PinHeader_2.54mm:PinHeader_2x06_P2.54mm_Vertical","Generic connector, double r | ow, | 02x06, odd/even pin numbering scheme (row 1 odd numbers, row 2 even numbers), script generated (kicad-library-utils/schlib/autogen/connector/)",""
"SW3, ","1","N8VEM/KONTRON","Conn_01x03","Jumper:SolderJumper-3_P1.3mm_Open_RoundedPad1.0x1.5mm_NumberLabels","Generic connector, | sin | gle row, 01x03, script generated (kicad-library-utils/schlib/autogen/connector/)",""
"U1, ","1","74LS245","74LS245","Package_DIP:DIP-20_W7.62mm","Octal BUS Transceivers, 3-State outputs",""
"U2, U8, ","2","74LS241","74LS241","Package_DIP:DIP-20_W7.62mm","Octal Buffer and Line Driver With 3-State Output, complementary e | nab | les, non-inverting outputs",""
"U3, ","1","74LS688","74LS688","Package_DIP:DIP-20_W7.62mm","8-bit magnitude comparator",""
"U4, ","1","YM2612","YM2612-Audio","Package_DIP:DIP-24_W15.24mm","",""
"U5, ","1","TL072","TL072","Package_DIP:DIP-8_W7.62mm","Dual Low-Noise JFET-Input Operational Amplifiers, DIP-8/SOIC-8",""
"U6, ","1","74LS74","74LS74","Package_DIP:DIP-14_W7.62mm","Dual D Flip-flop, Set & Reset",""
"U10, ","1","74LS139","74LS139","Package_DIP:DIP-16_W7.62mm","Dual Decoder 1 of 4, Active low outputs",""
"U18, U19, ","2","SN76489","SN76489","Package_DIP:DIP-16_W7.62mm","",""
"U20, ","1","C96ABC","C96ABC","library:C96ABCMC","Connector Europe, 96 contacts, ranges A,B,C",""
"U21, U22, ","2","LM386","LM386","Package_DIP:DIP-8_W7.62mm","Low Voltage Audio Power Amplifier, DIP-8/SOIC-8/SSOP-8",""
"X1, ","1","3.57595Mhz","CXO_DIP8","Oscillator:Oscillator_DIP-8","Crystal Clock Oscillator, DIP8-style metal package",""
"X2, ","1","7.6Mhz","CXO_DIP8","Oscillator:Oscillator_DIP-8","Crystal Clock Oscillator, DIP8-style metal package",""

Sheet: Sheet2
Ref | Qnty | Value | Cmp name | Footprint | Description | Vendor
C1, C2, C3, C4, C7, C8, C10, C18, C19, C22, C23, C28, C29, C50, | 14 | 0.1uF | C | Capacitor_THT:C_Disc_D7.0mm_W2.5mm_P5.00mm | Unpolarized capacitor
C5, C20, C21, C34, C35, | 5 | 470uF | CP | Capacitor_THT:CP_Radial_D8.0mm_P2.50mm | Polarized capacitor
C6, | 1 | 100uF | CP | Capacitor_THT:CP_Radial_D5.0mm_P2.50mm | Polarized capacitor
C24, C25, | 2 | 100uF | CP | Capacitor_THT:CP_Radial_D8.0mm_P2.50mm | Polarized capacitor
C26, C27, C36, C37, C39, C41, | 6 | 10uF | C | Capacitor_THT:CP_Radial_D5.0mm_P2.50mm | Unpolarized capacitor
C30, C31, | 2 | 470pF | C | Capacitor_THT:C_Disc_D3.8mm_W2.6mm_P2.50mm | Unpolarized capacitor
C32, C33, | 2 | 1uF | C | Capacitor_THT:C_Disc_D7.0mm_W2.5mm_P5.00mm | Unpolarized capacitor
C38, C46, | 2 | 220pF | C | Capacitor_THT:C_Disc_D3.8mm_W2.6mm_P2.50mm | Unpolarized capacitor
C40, C47, | 2 | 1uF | C | Capacitor_THT:CP_Radial_D5.0mm_P2.50mm | Unpolarized capacitor
C42, C43, C44, C45, | 4 | 5.6nF | C | Capacitor_THT:C_Disc_D3.8mm_W2.6mm_P2.50mm | Unpolarized capacitor
CX1, CX2, | 2 | 0.1uF | C | Capacitor_THT:C_Disc_D7.0mm_W2.5mm_P5.00mm | Unpolarized capacitor
H1, | 1 | MountingHole | MountingHole | MountingHole:MountingHole_5mm | Mounting Hole without connection
J1, | 1 | Barrel_Jack | Barrel_Jack | Connector_BarrelJack:BarrelJack_Horizontal | DC Barrel Jack
J3, | 1 | Conn_01x04 | Conn_01x04 | TerminalBlock:TerminalBlock_bornier-4_P5.08mm | Generic connector, single row, 01x04, script generated (kicad-library-utils/schlib/autogen/connector/)
JP1, | 1 | Jumper_3_Open | Jumper_3_Open | Connector_PinHeader_2.54mm:PinHeader_1x03_P2.54mm_Vertical | Jumper, 3-pole, both open
L1, L2, | 2 | 33uH | INDUCTOR | Inductor_THT:L_Axial_L6.6mm_D2.7mm_P10.16mm_Horizontal_Vishay_IM-2 | Inductor symbol for simulation only
R1, R3, R4, R5, R6, R7, | 6 | 2K2 | R | Resistor_THT:R_Axial_DIN0207_L6.3mm_D2.5mm_P10.16mm_Horizontal | Resistor
R2, R13, | 2 | 51K | R | Resistor_THT:R_Axial_DIN0207_L6.3mm_D2.5mm_P10.16mm_Horizontal | Resistor
R8, R9, R14, R15, R16, R17, | 6 | 10K | R | Resistor_THT:R_Axial_DIN0207_L6.3mm_D2.5mm_P10.16mm_Horizontal | Resistor
R10, R11, | 2 | 10R | R | Resistor_THT:R_Axial_DIN0207_L6.3mm_D2.5mm_P10.16mm_Horizontal | Resistor
R12, R20, | 2 | 47K | R | Resistor_THT:R_Axial_DIN0207_L6.3mm_D2.5mm_P10.16mm_Horizontal | Resistor
R18, R19, | 2 | 33K | R | Resistor_THT:R_Axial_DIN0207_L6.3mm_D2.5mm_P10.16mm_Horizontal | Resistor
RN1, | 1 | 22K | R_Network08 | Resistor_THT:R_Array_SIP9 | 8 resistor network, star topology, bussed resistors, small symbol
RV1, | 1 | 10K | R_POT_Dual | Potentiometer_THT:Potentiometer_Alps_RK097_Dual_Horizontal | Dual potentiometer
RV2, RV3, | 2 | 10K | R_POT_TRIM | Potentiometer_THT:Potentiometer_Bourns_3339P_Vertical | Trim-potentiometer
SW1, | 1 | ADDR | Conn_02x06_Odd_Even | Connector_PinHeader_2.54mm:PinHeader_2x06_P2.54mm_Vertical | Generic connector, double row, 02x06, odd/even pin numbering scheme (row 1 odd numbers, row 2 even numbers), script generated (kicad-library-utils/schlib/autogen/connector/)
SW3, | 1 | N8VEM/KONTRON | Conn_01x03 | Jumper:SolderJumper-3_P1.3mm_Open_RoundedPad1.0x1.5mm_NumberLabels | Generic connector, single row, 01x03, script generated (kicad-library-utils/schlib/autogen/connector/)
U1, | 1 | 74LS245 | 74LS245 | Package_DIP:DIP-20_W7.62mm | Octal BUS Transceivers, 3-State outputs
U2, U8, | 2 | 74LS241 | 74LS241 | Package_DIP:DIP-20_W7.62mm | Octal Buffer and Line Driver With 3-State Output, complementary enables, non-inverting outputs
U3, | 1 | 74LS688 | 74LS688 | Package_DIP:DIP-20_W7.62mm | 8-bit magnitude comparator
U4, | 1 | YM2612 | YM2612-Audio | Package_DIP:DIP-24_W15.24mm
U5, | 1 | TL072 | TL072 | Package_DIP:DIP-8_W7.62mm | Dual Low-Noise JFET-Input Operational Amplifiers, DIP-8/SOIC-8
U6, | 1 | 74LS74 | 74LS74 | Package_DIP:DIP-14_W7.62mm | Dual D Flip-flop, Set & Reset
U10, | 1 | 74LS139 | 74LS139 | Package_DIP:DIP-16_W7.62mm | Dual Decoder 1 of 4, Active low outputs
U18, U19, | 2 | SN76489 | SN76489 | Package_DIP:DIP-16_W7.62mm
U20, | 1 | C96ABC | C96ABC | library:C96ABCMC | Connector Europe, 96 contacts, ranges A,B,C
U21, U22, | 2 | LM386 | LM386 | Package_DIP:DIP-8_W7.62mm | Low Voltage Audio Power Amplifier, DIP-8/SOIC-8/SSOP-8
X1, | 1 | 3.57595Mhz | CXO_DIP8 | Oscillator:Oscillator_DIP-8 | Crystal Clock Oscillator, DIP8-style metal package
X2, | 1 | 7.6Mhz | CXO_DIP8 | Oscillator:Oscillator_DIP-8 | Crystal Clock Oscillator, DIP8-style metal package

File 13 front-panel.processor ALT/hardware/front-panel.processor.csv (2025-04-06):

Reference | Value | Datasheet | Footprint | Qty | DNP
Brd1 | SSD1306 |  | SSD1306:128x64OLED | 1
D1,D2,D3,D4,D5,D6,D7,D8,D9 | LED | ~ | LED_THT:LED_D3.0mm | 9
H1,H2,H3,H4 | MountingHole | ~ | MountingHole:MountingHole_3.2mm_M3_Pad | 4
J1 | FPANEL | ~ | Connector_IDC:IDC-Header_2x20_P2.54mm_Horizontal | 1
J2 | TTL SERIAL | ~ | Connector_PinHeader_2.54mm:PinHeader_1x06_P2.54mm_Vertical | 1
J3 | MICRO SD CARD | ~ | Connector_PinSocket_2.54mm:PinSocket_1x08_P2.54mm_Vertical | 1
J4 | TTL Serial to WiFi Enable | ~ | Connector_PinHeader_2.54mm:PinHeader_2x04_P2.54mm_Vertical | 1
J5 | Micro_SD_Card | https://www.we-online.com/components/products/datasheet/693072010801.pdf | Connector_Card:SD_Hirose_DM1AA_SF_PEJ82 | 1
R1,R2 | 10K | ~ | Resistor_THT:R_Axial_DIN0207_L6.3mm_D2.5mm_P7.62mm_Horizontal | 2
R6,RN1 | 470 | -- mixed values -- | -- mixed values -- | 2
SW1,SW2,SW3,SW4,SW5,SW6,SW7,SW8,SW10,SW11,SW12 | SW_SPDT | ~ | SW_Toggle_Blue_wSlots:SW_Toggle_Blue_wSlots | 11
SW9 | SW_Push | ~ | Button_Switch_THT:SW_PUSH_6mm | 1
U1 | 74LS240 | http://www.ti.com/lit/ds/symlink/sn74ls240.pdf | Package_DIP:DIP-20_W7.62mm | 1
U2 | ESP32-S3-DevKitC |  | Custom:ESP32S3Devkit3Universal | 1
U3,U4 | ~ |  | Custom:HV-LV | 2
U5 | LP2950-3.3_TO92 | http://www.ti.com/lit/ds/symlink/lp2950.pdf | Package_TO_SOT_THT:TO-92_Inline | 1

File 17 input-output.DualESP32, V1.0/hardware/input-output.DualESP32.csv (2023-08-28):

Source: | C:\Users\Andrew\Desktop\System CD Updates\data\duodyne\GitHub\17 input-output.DualESP32, V1.0\hardware\input-output.DualESP32.kicad_sch
Date: | 8/28/2023 6:39:54 PM
Tool: | Eeschema (6.0.11)
Generator: | C:\Program Files\KiCad\6.0\bin\scripting\plugins/bom_csv_grouped_by_value_with_fp.py
Component Count: | 72
Ref | Qnty | Value | Cmp name | Footprint | Description | Vendor
C1, C2, C3, C4, C7, C8, C9, C10, C11, C12, C15, C17, C18, | 13 | 0.1µF | C | Capacitor_THT:C_Disc_D5.0mm_W2.5mm_P5.00mm | Unpolarized capacitor
C13, C14, C16, | 3 | 10µF | C_Polarized_US | Capacitor_THT:CP_Radial_D5.0mm_P2.50mm | Polarized capacitor, US symbol
D1, | 1 | LED | LED | LED_THT:LED_D3.0mm_Horizontal_O3.81mm_Z2.0mm | Light emitting diode
D2, D3, D4, D5, | 4 | 1N4001 | 1N4001 | Diode_THT:D_DO-41_SOD81_P10.16mm_Horizontal | 50V 1A General Purpose Rectifier Diode, DO-41
H1, H2, | 2 | MountingHole | MountingHole_Pad | MountingHole:MountingHole_3.2mm_M3_Pad | Mounting Hole with connection
J1, | 1 | KEYBOARD AND MOUSE | Conn_02x05_Odd_Even | Connector_PinHeader_2.54mm:PinHeader_2x05_P2.54mm_Horizontal | Generic connector, double row, 02x05, odd/even pin numbering scheme (row 1 odd numbers, row 2 even numbers), script generated (kicad-library-utils/schlib/autogen/connector/)
J2, | 1 | AUDIO OUT | Conn_01x02_Male | Connector_PinHeader_2.54mm:PinHeader_1x02_P2.54mm_Horizontal | Generic connector, single row, 01x02, script generated (kicad-library-utils/schlib/autogen/connector/)
J3, | 1 | ESP_SERIAL_1 | Conn_01x03_Male | Connector_PinHeader_2.54mm:PinHeader_1x03_P2.54mm_Horizontal | Generic connector, single row, 01x03, script generated (kicad-library-utils/schlib/autogen/connector/)
J4, | 1 | ESP_SERIAL_0 | Conn_01x03_Male | Connector_PinHeader_2.54mm:PinHeader_1x03_P2.54mm_Horizontal | Generic connector, single row, 01x03, script generated (kicad-library-utils/schlib/autogen/connector/)
J5, | 1 | VGA | DB15_Female_HighDensity_MountingHoles | Connector_Dsub:DSUB-15-HD_Female_Horizontal_P2.29x1.98mm_EdgePinOffset3.03mm_Housed_MountingHolesOffset4.94mm | 15-pin female D-SUB connector, High density (3 columns), Triple Row, Generic, VGA-connector, Mounting Hole
J6, | 1 | RESET SEL | Conn_01x03 | Connector_PinHeader_2.54mm:PinHeader_1x03_P2.54mm_Vertical | Generic connector, single row, 01x03, script generated (kicad-library-utils/schlib/autogen/connector/)
J7, | 1 | IO PORT ADDR | Conn_02x06_Odd_Even | Connector_PinHeader_2.54mm:PinHeader_2x06_P2.54mm_Vertical | Generic connector, double row, 02x06, odd/even pin numbering scheme (row 1 odd numbers, row 2 even numbers), script generated (kicad-library-utils/schlib/autogen/connector/)
J8, | 1 | Keyboard | Mini-DIN-6 | CUSTOM:mini_din | 6-pin Mini-DIN connector
J9, | 1 | Mouse | Mini-DIN-6 | CUSTOM:mini_din | 6-pin Mini-DIN connector
J10, | 1 | VGA | Conn_01x07 | Connector_PinHeader_2.54mm:PinHeader_1x07_P2.54mm_Horizontal | Generic connector, single row, 01x07, script generated (kicad-library-utils/schlib/autogen/connector/)
P1, P2, P3, | 3 | CONN_02X25 | Conn_02x25_Odd_Even | Connector_IDC:IDC-Header_2x25_P2.54mm_Horizontal | Generic connector, double row, 02x25, odd/even pin numbering scheme (row 1 odd numbers, row 2 even numbers), script generated (kicad-library-utils/schlib/autogen/connector/)
P4, | 1 | BYPASS | Conn_01x04 | Connector_PinHeader_2.54mm:PinHeader_1x04_P2.54mm_Vertical | Generic connector, single row, 01x04, script generated (kicad-library-utils/schlib/autogen/connector/)
R1, | 1 | 470Ω | R | Resistor_THT:R_Axial_DIN0207_L6.3mm_D2.5mm_P7.62mm_Horizontal | Resistor
R2, | 1 | 270Ω | R | Resistor_THT:R_Axial_DIN0207_L6.3mm_D2.5mm_P7.62mm_Horizontal | Resistor
R3, R4, R10, R11, | 4 | 120Ω | R | Resistor_THT:R_Axial_DIN0207_L6.3mm_D2.5mm_P7.62mm_Horizontal | Resistor
R5, | 1 | 150Ω | R | Resistor_THT:R_Axial_DIN0207_L6.3mm_D2.5mm_P7.62mm_Horizontal | Resistor
R6, R8, | 2 | 2.2KΩ | R | Resistor_THT:R_Axial_DIN0207_L6.3mm_D2.5mm_P7.62mm_Horizontal | Resistor
R7, R9, | 2 | 1KΩ | R | Resistor_THT:R_Axial_DIN0207_L6.3mm_D2.5mm_P7.62mm_Horizontal | Resistor
R12, R14, R16, | 3 | 390Ω | R | Resistor_THT:R_Axial_DIN0207_L6.3mm_D2.5mm_P7.62mm_Horizontal | Resistor
R13, R15, R17, | 3 | 820Ω | R | Resistor_THT:R_Axial_DIN0207_L6.3mm_D2.5mm_P7.62mm_Horizontal | Resistor
R18, R19, | 2 | 0Ω | R | Resistor_THT:R_Axial_DIN0207_L6.3mm_D2.5mm_P7.62mm_Horizontal | Resistor
RN1, | 1 | 1KΩ | R_Network08 | Resistor_THT:R_Array_SIP9 | 8 resistor network, star topology, bussed resistors, small symbol
RN2, | 1 | 10KΩ | R_Network08_US | Resistor_THT:R_Array_SIP9 | 8 resistor network, star topology, bussed resistors, small US symbol
U3, U17, | 2 | 74LS07 | 74LS07 | Package_DIP:DIP-14_W7.62mm | Hex Buffers and Drivers With Open Collector High Voltage Outputs
U6, U8, | 2 | 74HC595 | 74HC595 | Package_DIP:DIP-16_W7.62mm | 8-bit serial in/out Shift Register 3-State Outputs
U7, U9, | 2 | 74HC165 | 74HC165 | Package_DIP:DIP-16_W7.62mm | Shift Register, 8-bit, Parallel Load
U10, U13, U15, | 3 | 74LS244 | 74LS244 | Package_DIP:DIP-20_W7.62mm | Octal Buffer and Line Driver With 3-State Output, active-low enables, non-inverting outputs
U11, U12, | 2 | ESP32_MODULE | ESP32_MODULE_1 | CUSTOM:ESP32_MODULE
U14, | 1 | 74LS245 | 74LS245 | Package_DIP:DIP-20_W7.62mm | Octal BUS Transceivers, 3-State outputs
U16, | 1 | 74LS688 | 74LS688 | Package_DIP:DIP-20_W7.62mm | 8-bit magnitude comparator
U18, | 1 | GAL16V8 | GAL16V8 | Package_DIP:DIP-20_W7.62mm | Programmable Logic Array, DIP-20/SOIC-20/PLCC-20

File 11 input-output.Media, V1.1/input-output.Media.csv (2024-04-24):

Source: | C:\Users\Andrew\Desktop\System CD Updates\data\duodyne\GitHub\11 input-output.Media, V1.1\input-output.Media.kicad_sch
Date: | 4/23/2024 9:06:44 PM
Tool: | Eeschema (6.0.11)
Generator: | C:\Program Files\KiCad\6.0\bin\scripting\plugins/bom_csv_grouped_by_value_with_fp.py
Component Count: | 189
Ref | Qnty | Value | Cmp name | Footprint | Description | Vendor
C1, C2, C3, C4, C5, C6, C7, C9, C10, C11, C12, C14, C15, C16, C18, C19, C43, C44, C45, C50, C55, C62, C79, | 23 | 0.1u | C | Capacitor_THT:C_Disc_D5.0mm_W2.5mm_P5.00mm | Unpolarized capacitor
C8, C13, | 2 | 10uF | C_Polarized | Capacitor_THT:CP_Radial_D5.0mm_P2.50mm | Polarized capacitor
C17, C29, C30, C33, C34, C48, | 6 | 0.1uF | C | Capacitor_THT:C_Disc_D5.0mm_W2.5mm_P5.00mm | Unpolarized capacitor
C20, C21, C22, C23, C24, C25, C26, C27, C54, C82, C83, | 11 | 10u | C_Polarized | Capacitor_THT:CP_Radial_D5.0mm_P2.50mm | Polarized capacitor
C28, C56, C57, C58, C59, C60, C61, | 7 | 220u | C_Polarized | Capacitor_THT:CP_Radial_D6.3mm_P2.50mm | Polarized capacitor
C31, C32, | 2 | 470pF | C | Capacitor_THT:C_Disc_D5.0mm_W2.5mm_P5.00mm | Unpolarized capacitor
C35, C36, | 2 | 47uF | C_Polarized | Capacitor_THT:CP_Radial_D5.0mm_P2.50mm | Polarized capacitor
C37, C39, C41, | 3 | 330p | C | Capacitor_THT:C_Disc_D5.0mm_W2.5mm_P5.00mm | Unpolarized capacitor
C38, C40, | 2 | 47pF | C | Capacitor_THT:C_Disc_D5.0mm_W2.5mm_P5.00mm | Unpolarized capacitor
C42, C46, | 2 | 1000u | C_Polarized | Capacitor_THT:CP_Radial_D8.0mm_P2.50mm | Polarized capacitor
C47, | 1 | 47p | C | Capacitor_THT:C_Disc_D5.0mm_W2.5mm_P5.00mm | Unpolarized capacitor
C49, | 1 | 4.7p | C | Capacitor_THT:C_Disc_D5.0mm_W2.5mm_P5.00mm | Unpolarized capacitor
C51, | 1 | 27p | C | Capacitor_THT:C_Disc_D5.0mm_W2.5mm_P5.00mm | Unpolarized capacitor
C52, | 1 | 30p | C_Trim | 30pF Cap Trimmer:CAP_TZ03R300E169B00_MUR | Trimmable capacitor
C53, | 1 | 22p | C | Capacitor_THT:C_Disc_D5.0mm_W2.5mm_P5.00mm | Unpolarized capacitor
C63, C64, C65, C66, | 4 | 0.22u | C | Capacitor_THT:C_Disc_D5.0mm_W2.5mm_P5.00mm | Unpolarized capacitor
C80, C81, | 2 | 270p | C | Capacitor_THT:C_Disc_D5.0mm_W2.5mm_P5.00mm | Unpolarized capacitor
C84, C85, | 2 | 0.01u | C | Capacitor_THT:C_Disc_D5.0mm_W2.5mm_P5.00mm | Unpolarized capacitor
D1, D2, D3, D4, | 4 | LED | LED | LED_THT:LED_D3.0mm_Horizontal_O3.81mm_Z2.0mm | Light emitting diode
D5, | 1 | 1N5817 | 1N5817 | Diode_THT:D_DO-41_SOD81_P10.16mm_Horizontal | 20V 1A Schottky Barrier Rectifier Diode, DO-41
H1, H2, | 2 | MountingHole | MountingHole_Pad | MountingHole:MountingHole_3.2mm_M3_Pad | Mounting Hole with connection
J1, | 1 | FPGA Emulator | Conn_02x10_Odd_Even | Connector_PinHeader_2.54mm:PinHeader_2x10_P2.54mm_Vertical | Generic connector, double row, 02x10, odd/even pin numbering scheme (row 1 odd numbers, row 2 even numbers), script generated (kicad-library-utils/schlib/autogen/connector/)
J2, | 1 | AUD SEL | Conn_01x03 | Connector_PinHeader_2.54mm:PinHeader_1x03_P2.54mm_Vertical | Generic connector, single row, 01x03, script generated (kicad-library-utils/schlib/autogen/connector/)
J3, | 1 | CSYNC | Conn_01x03 | Connector_PinHeader_2.54mm:PinHeader_1x03_P2.54mm_Vertical | Generic connector, single row, 01x03, script generated (kicad-library-utils/schlib/autogen/connector/)
J4, | 1 | PIN13 | Conn_01x03 | Connector_PinHeader_2.54mm:PinHeader_1x03_P2.54mm_Vertical | Generic connector, single row, 01x03, script generated (kicad-library-utils/schlib/autogen/connector/)
J7, | 1 | INTERRUPT | Conn_02x08_Odd_Even | Connector_PinHeader_2.54mm:PinHeader_2x08_P2.54mm_Vertical | Generic connector, double row, 02x08, odd/even pin numbering scheme (row 1 odd numbers, row 2 even numbers), script generated (kicad-library-utils/schlib/autogen/connector/)
J8, | 1 | JOY/VCC | Conn_01x03 | Connector_PinHeader_2.54mm:PinHeader_1x03_P2.54mm_Vertical | Generic connector, single row, 01x03, script generated (kicad-library-utils/schlib/autogen/connector/)
J9, | 1 | RESET SEL | Conn_01x03 | Connector_PinHeader_2.54mm:PinHeader_1x03_P2.54mm_Vertical | Generic connector, single row, 01x03, script generated (kicad-library-utils/schlib/autogen/connector/)
J10, | 1 | POT/VCC | Conn_01x03 | Connector_PinHeader_2.54mm:PinHeader_1x03_P2.54mm_Vertical | Generic connector, single row, 01x03, script generated (kicad-library-utils/schlib/autogen/connector/)
J11, | 1 | JOY_ENB | Conn_02x03_Odd_Even | Connector_PinHeader_2.54mm:PinHeader_2x03_P2.54mm_Vertical | Generic connector, double row, 02x03, odd/even pin numbering scheme (row 1 odd numbers, row 2 even numbers), script generated (kicad-library-utils/schlib/autogen/connector/)
J12, | 1 | AudioJack3 | AudioJack3 | Connector_Audio:Jack_3.5mm_CUI_SJ1-3533NG_Horizontal | Audio Jack, 3 Poles (Stereo / TRS)
J13, | 1 | RGB | DIN-8 | Connector_Video:AV_CON_DIN8 | 8-pin DIN connector
J14, | 1 | S-VIDEO | Mini-DIN-4 | Connector_Video:Conn_Mini_DIN_4pin | 4-pin Mini-DIN connector
J15, | 1 | Composite | Conn_Coaxial | Connector_Video:Conn_RCA_Right | coaxial connector (BNC, SMA, SMB, SMC, Cinch/RCA, LEMO, ...)
JP1, | 1 | V9958/V9938 | Jumper_3_Open | Connector_PinHeader_2.54mm:PinHeader_1x03_P2.54mm_Vertical | Jumper, 3-pole, both open
JP2, | 1 | OPTWAIT | Jumper_2_Open | Connector_PinHeader_2.54mm:PinHeader_1x02_P2.54mm_Vertical | Jumper, 2-pole, open
JP3, | 1 | V9958 | Jumper_2_Open | Connector_PinHeader_2.54mm:PinHeader_1x02_P2.54mm_Vertical | Jumper, 2-pole, open
JP4, | 1 | TEST2 | Jumper_2_Open | Connector_PinHeader_2.54mm:PinHeader_1x02_P2.54mm_Vertical | Jumper, 2-pole, open
JP5, | 1 | VRY CLK | Jumper_2_Open | Connector_PinHeader_2.54mm:PinHeader_1x02_P2.54mm_Vertical | Jumper, 2-pole, open
JP6, | 1 | ~{HSYNC} | Jumper_2_Open | Connector_PinHeader_2.54mm:PinHeader_1x02_P2.54mm_Vertical | Jumper, 2-pole, open
JP7, | 1 | ~{VDS}/~{VRESET} | Jumper_2_Open | Connector_PinHeader_2.54mm:PinHeader_1x02_P2.54mm_Vertical | Jumper, 2-pole, open
JP8, | 1 | AMP PWR | Jumper_3_Open | Connector_PinHeader_2.54mm:PinHeader_1x03_P2.54mm_Vertical | Jumper, 3-pole, both open
JP9, | 1 | LFT SPK | Jumper_2_Open | Connector_PinHeader_2.54mm:PinHeader_1x02_P2.54mm_Vertical | Jumper, 2-pole, open
JP10, | 1 | RGT SPK | Jumper_2_Open | Connector_PinHeader_2.54mm:PinHeader_1x02_P2.54mm_Vertical | Jumper, 2-pole, open
JP12, | 1 | V9938 EN | Jumper_2_Open | Connector_PinHeader_2.54mm:PinHeader_1x02_P2.54mm_Vertical | Jumper, 2-pole, open
JP13, | 1 | MSX INT | Jumper_2_Open | Connector_PinHeader_2.54mm:PinHeader_1x02_P2.54mm_Vertical | Jumper, 2-pole, open
L1, | 1 | 68u | L_Small | Inductor_THT:L_Axial_L6.6mm_D2.7mm_P10.16mm_Horizontal_Vishay_IM-2 | Inductor, small symbol
L2, L3, | 2 | 5.6uH | L_Small | Inductor_THT:L_Axial_L5.3mm_D2.2mm_P7.62mm_Horizontal_Vishay_IM-1 | Inductor, small symbol
LS1, LS2, | 2 | Speaker | Speaker | Jameco PCB Speaker 30mm 135722:Jameco PCB Speaker 30mm 135722 | Speaker
P1, P2, P3, | 3 | CONN_02X25 | Conn_02x25_Odd_Even | Connector_IDC:IDC-Header_2x25_P2.54mm_Horizontal | Generic connector, double row, 02x25, odd/even pin numbering scheme (row 1 odd numbers, row 2 even numbers), script generated (kicad-library-utils/schlib/autogen/connector/)
P4, | 1 | BYPASS | Conn_01x04 | Connector_PinHeader_2.54mm:PinHeader_1x04_P2.54mm_Vertical | Generic connector, single row, 01x04, script generated (kicad-library-utils/schlib/autogen/connector/)
P5, | 1 | ANALOG RGB | Conn_02x08_Odd_Even | Connector_PinHeader_2.54mm:PinHeader_2x08_P2.54mm_Vertical | Generic connector, double row, 02x08, odd/even pin numbering scheme (row 1 odd numbers, row 2 even numbers), script generated (kicad-library-utils/schlib/autogen/connector/)
P6, | 1 | RAMDAC | Conn_02x08_Odd_Even | Connector_PinHeader_2.54mm:PinHeader_2x08_P2.54mm_Vertical | Generic connector, double row, 02x08, odd/even pin numbering scheme (row 1 odd numbers, row 2 even numbers), script generated (kicad-library-utils/schlib/autogen/connector/)
P7, | 1 | 3.5795 MHz | Conn_02x07_Counter_Clockwise | Package_DIP:DIP-14_W7.62mm | Generic connector, double row, 02x07, counter clockwise pin numbering scheme (similar to DIP package numbering), script generated (kicad-library-utils/schlib/autogen/connector/)
P8, | 1 | AY3-CFG | Conn_02x05_Odd_Even | Connector_PinHeader_2.54mm:PinHeader_2x05_P2.54mm_Vertical | Generic connector, double row, 02x05, odd/even pin numbering scheme (row 1 odd numbers, row 2 even numbers), script generated (kicad-library-utils/schlib/autogen/connector/)
P9, | 1 | SOUND | Conn_02x05_Odd_Even | Connector_IDC:IDC-Header_2x05_P2.54mm_Horizontal | Generic connector, double row, 02x05, odd/even pin numbering scheme (row 1 odd numbers, row 2 even numbers), script generated (kicad-library-utils/schlib/autogen/connector/)
P10, | 1 | POT_ENB | Conn_02x03_Odd_Even | Connector_PinHeader_2.54mm:PinHeader_2x03_P2.54mm_Vertical | Generic connector, double row, 02x03, odd/even pin numbering scheme (row 1 odd numbers, row 2 even numbers), script generated (kicad-library-utils/schlib/autogen/connector/)
P11, | 1 | JYSTK-B | Conn_02x05_Odd_Even | Connector_IDC:IDC-Header_2x05_P2.54mm_Horizontal | Generic connector, double row, 02x05, odd/even pin numbering scheme (row 1 odd numbers, row 2 even numbers), script generated (kicad-library-utils/schlib/autogen/connector/)
P12, | 1 | JYSTK-A | Conn_02x05_Odd_Even | Connector_IDC:IDC-Header_2x05_P2.54mm_Horizontal | Generic connector, double row, 02x05, odd/even pin numbering scheme (row 1 odd numbers, row 2 even numbers), script generated (kicad-library-utils/schlib/autogen/connector/)
P13, | 1 | SYNC | Conn_02x03_Odd_Even | Connector_PinHeader_2.54mm:PinHeader_2x03_P2.54mm_Vertical | Generic connector, double row, 02x03, odd/even pin numbering scheme (row 1 odd numbers, row 2 even numbers), script generated (kicad-library-utils/schlib/autogen/connector/)
Q1, | 1 | 2N3906 | 2N3906 | Package_TO_SOT_THT:TO-92_HandSolder | -0.2A Ic, -40V Vce, Small Signal PNP Transistor, TO-92
R1, R5, R6, R10, R25, R26, R27, | 7 | 470 | R | Resistor_THT:R_Axial_DIN0207_L6.3mm_D2.5mm_P7.62mm_Horizontal | Resistor
R2, R34, R35, R36, R38, | 5 | 10K | R | Resistor_THT:R_Axial_DIN0207_L6.3mm_D2.5mm_P7.62mm_Horizontal | Resistor
R3, | 1 | 180 | R | Resistor_THT:R_Axial_DIN0207_L6.3mm_D2.5mm_P7.62mm_Horizontal | Resistor
R4, R7, R20, R31, R32, R33, | 6 | 1000 | R | Resistor_THT:R_Axial_DIN0207_L6.3mm_D2.5mm_P7.62mm_Horizontal | Resistor
R8, R12, R24, | 3 | 4700 | R | Resistor_THT:R_Axial_DIN0207_L6.3mm_D2.5mm_P7.62mm_Horizontal | Resistor
R9, R41, R42, | 3 | 2200 | R | Resistor_THT:R_Axial_DIN0207_L6.3mm_D2.5mm_P7.62mm_Horizontal | Resistor
R11, | 1 | 20K | R | Resistor_THT:R_Axial_DIN0207_L6.3mm_D2.5mm_P7.62mm_Horizontal | Resistor
R13, R14, R15, R16, R17, R18, | 6 | 75 | R | Resistor_THT:R_Axial_DIN0207_L6.3mm_D2.5mm_P7.62mm_Horizontal | Resistor
R19, | 1 | 47K | R | Resistor_THT:R_Axial_DIN0207_L6.3mm_D2.5mm_P7.62mm_Horizontal | Resistor
R21, | 1 | 120 | R | Resistor_THT:R_Axial_DIN0207_L6.3mm_D2.5mm_P7.62mm_Horizontal | Resistor
R22, | 1 | 680K | R | Resistor_THT:R_Axial_DIN0207_L6.3mm_D2.5mm_P7.62mm_Horizontal | Resistor
R23, | 1 | 470K | R | Resistor_THT:R_Axial_DIN0207_L6.3mm_D2.5mm_P7.62mm_Horizontal | Resistor
R30, R37, | 2 | 10 | R | Resistor_THT:R_Axial_DIN0207_L6.3mm_D2.5mm_P7.62mm_Horizontal | Resistor
R39, R40, | 2 | 1M | R | Resistor_THT:R_Axial_DIN0207_L6.3mm_D2.5mm_P7.62mm_Horizontal | Resistor
RN1, | 1 | 10K | R_Network08 | Resistor_THT:R_Array_SIP9 | 8 resistor network, star topology, bussed resistors, small symbol
RV1, RV2, | 2 | 5K | R_Potentiometer | Potentiometer_THT:Potentiometer_Bourns_3386P_Vertical | Potentiometer
SW1, | 1 | IO PORT ADDR | Conn_02x05_Odd_Even | Connector_PinHeader_2.54mm:PinHeader_2x05_P2.54mm_Vertical | Generic connector, double row, 02x05, odd/even pin numbering scheme (row 1 odd numbers, row 2 even numbers), script generated (kicad-library-utils/schlib/autogen/connector/)
U1, | 1 | GAL16V8 | GAL16V8 | Package_DIP:DIP-20_W7.62mm | Programmable Logic Array, DIP-20/SOIC-20/PLCC-20
U2, U3, | 2 | LM386 | LM386 | Package_DIP:DIP-8_W7.62mm | Low Voltage Audio Power Amplifier, DIP-8/SOIC-8/SSOP-8
U4, | 1 | 74LS06 | 74LS06 | Package_DIP:DIP-14_W7.62mm | Inverter Open Collect
U5, | 1 | CXA1645 | CXA1645 | Package_DIP:DIP-24_W10.16mm
U6, | 1 | V9938-V9958 | V9938-V9958 | ShrunkenDIP:renesas21-DIP64-S
U7, U8, U10, U11, | 4 | D41464C | D41464C | Package_DIP:DIP-18_W7.62mm
U9, | 1 | 74LS174 | 74LS174 | Package_DIP:DIP-16_W7.62mm | Hex D-type Flip-Flop, reset
U13, U15, | 2 | 74LS244 | 74LS244 | Package_DIP:DIP-20_W7.62mm | Octal Buffer and Line Driver With 3-State Output, active-low enables, non-inverting outputs
U14, | 1 | 74LS245 | 74LS245 | Package_DIP:DIP-20_W7.62mm | Octal BUS Transceivers, 3-State outputs
U16, | 1 | LM1881 | LM1881 | Package_DIP:DIP-8_W7.62mm
U17, | 1 | 74LS221 | 74LS221 | Package_DIP:DIP-16_W7.62mm | Dual Monostable
U20, | 1 | AY-3-8910 | AY-3-8910 | Package_DIP:DIP-40_W15.24mm
U21, | 1 | 74LS688 | 74LS688 | Package_DIP:DIP-20_W7.62mm | 8-bit magnitude comparator
U22, | 1 | 74LS93 | 74LS93 | Package_DIP:DIP-14_W7.62mm | Divide by 2 & 8 counter
U24, | 1 | 74LS04 | 74LS04 | Package_DIP:DIP-14_W7.62mm | Hex Inverter
X1, | 1 | 21.47727 MHz | Crystal | Crystal:Crystal_HC49-4H_Vertical | Two pin crystal

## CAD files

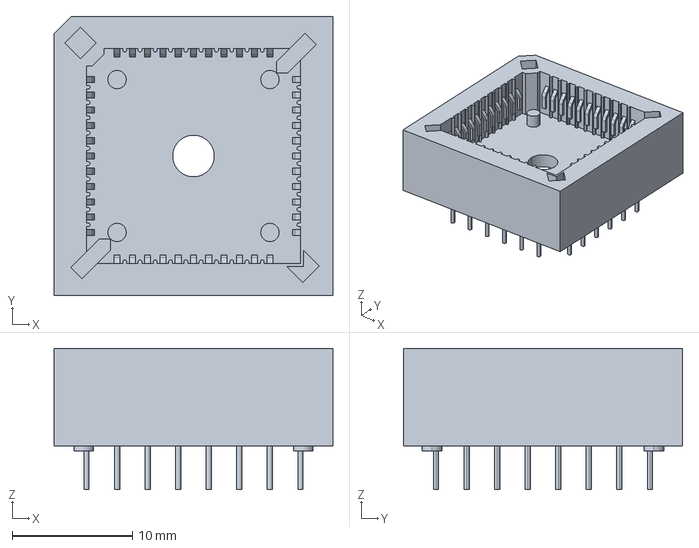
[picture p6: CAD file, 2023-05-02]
!Development/06 input-output.Multi, V1.1/plcc44socket.stp
23.2 x 23.2 x 11.8 mm

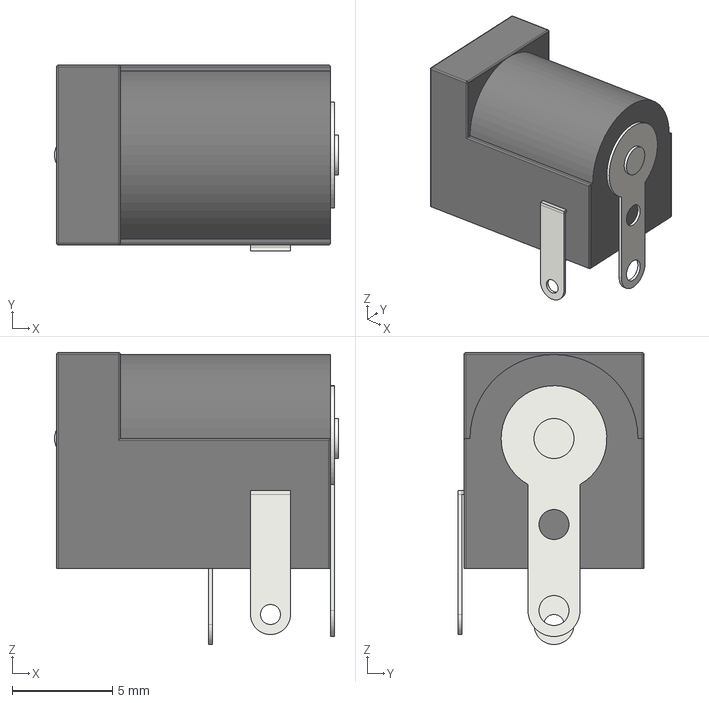
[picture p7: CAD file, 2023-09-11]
!Development/retro-programmer/BarrelJack_Horizontal.step
14.2 x 9.30 x 14.6 mm

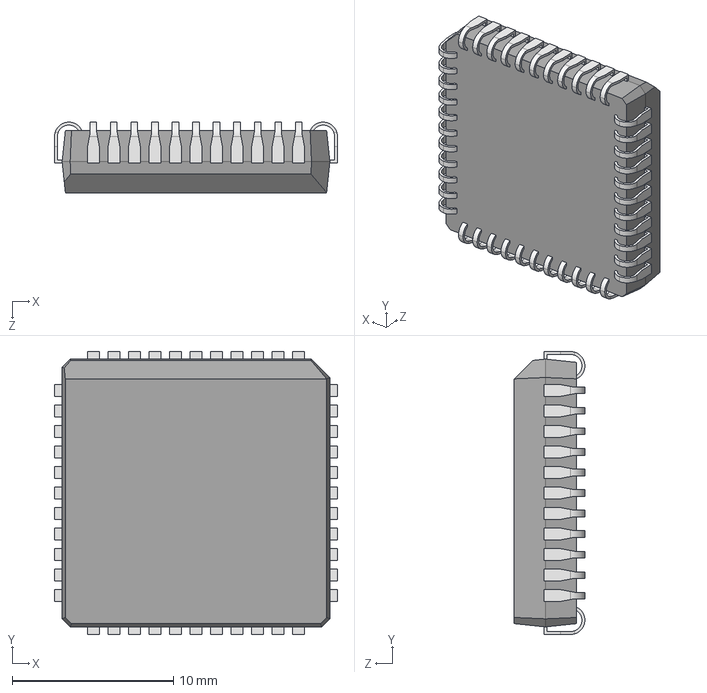
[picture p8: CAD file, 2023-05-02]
!Development/Slick/plcc44.stp
17.5 x 17.5 x 4.39 mm

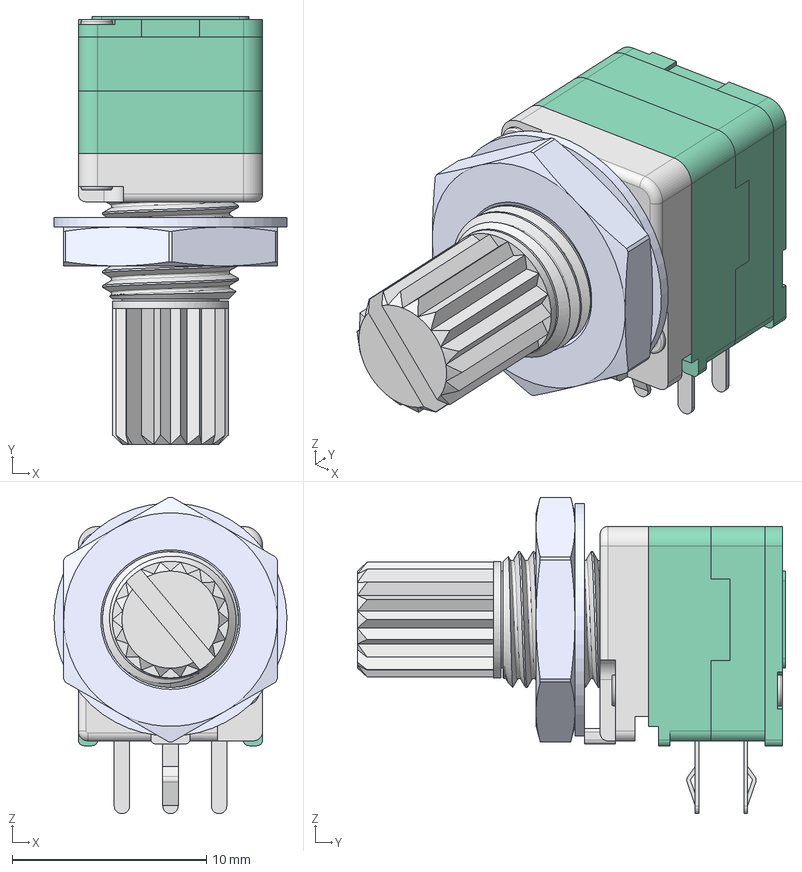
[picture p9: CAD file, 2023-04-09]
10 input-output.Voice, V1.0/temp/Z180GDCV2-SND/RK0972-L-12.5KC_N-5-green.step
12.0 x 22.1 x 16.3 mm

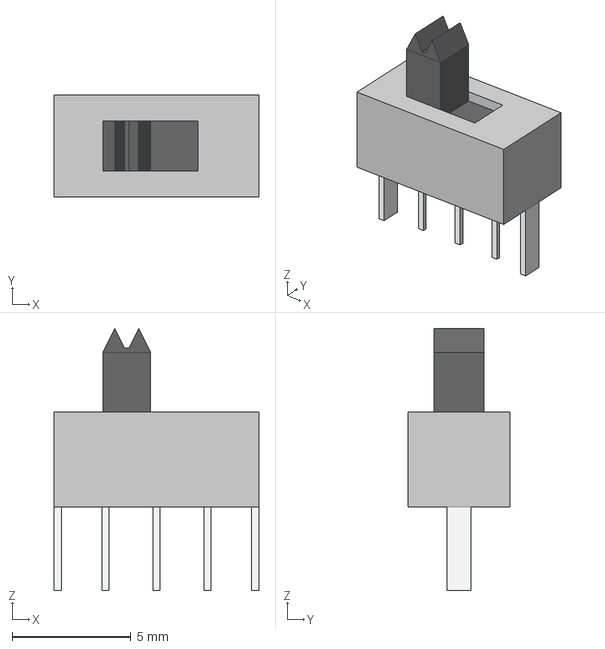
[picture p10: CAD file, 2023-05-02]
13 front-panel.processor ALT/hardware/SW_Slide_1P2T_CK_OS102011MS2Q.step
8.60 x 4.30 x 11.0 mm

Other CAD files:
25 processor.80c188/firmware/BIOS/debug.obj
25 processor.80c188/firmware/BIOS/fpem/em187.obj
10 input-output.Voice, V1.0/temp/Z180GDCV2-SND/Terminal block 5mm.step
25 processor.80c188/firmware/BIOS/copyrght.obj
25 processor.80c188/firmware/BIOS/cprintf.obj
25 processor.80c188/firmware/BIOS/floppy.obj
25 processor.80c188/firmware/BIOS/ide.obj
25 processor.80c188/firmware/BIOS/idelib.obj
25 processor.80c188/firmware/BIOS/int10ser.obj
25 processor.80c188/firmware/BIOS/int14ser.obj
25 processor.80c188/firmware/BIOS/int16.obj
25 processor.80c188/firmware/BIOS/int17par.obj
25 processor.80c188/firmware/BIOS/inttrace.obj
25 processor.80c188/firmware/BIOS/kbd.obj
25 processor.80c188/firmware/BIOS/libc.obj
25 processor.80c188/firmware/BIOS/misc15.obj
25 processor.80c188/firmware/BIOS/nvram.obj
25 processor.80c188/firmware/BIOS/ppide.obj
25 processor.80c188/firmware/BIOS/rbios.obj
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

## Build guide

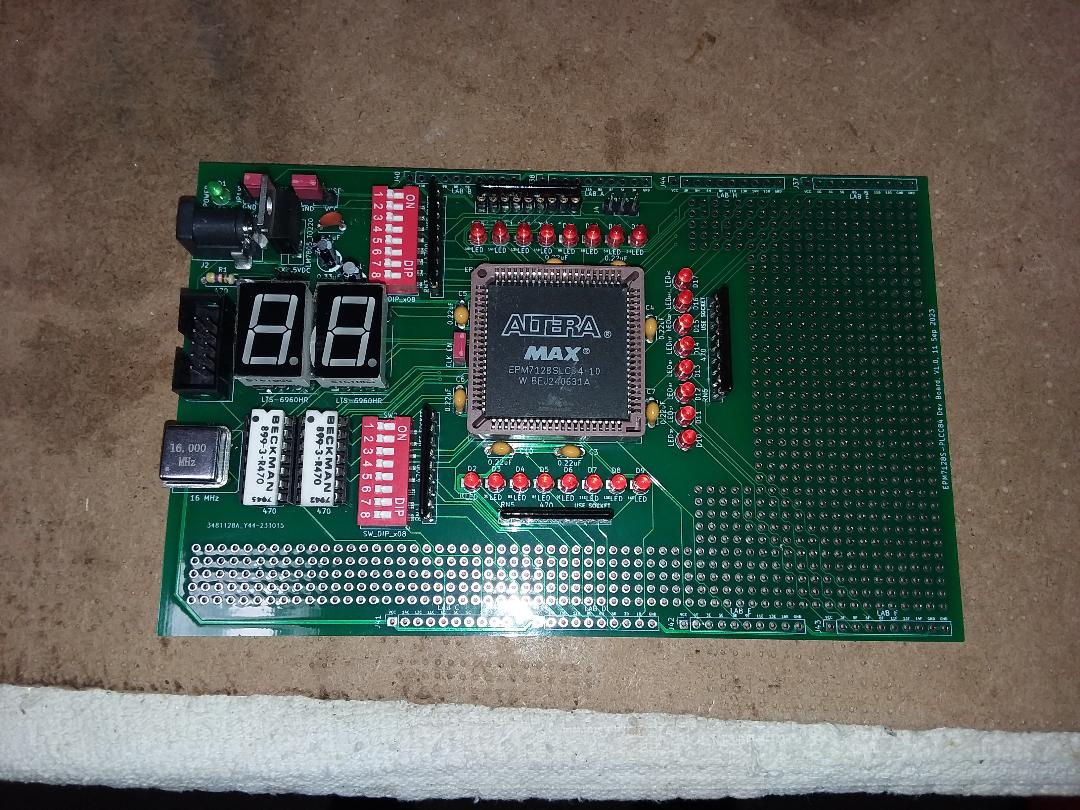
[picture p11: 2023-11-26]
!Initial Build and Test/Andrew's EPM7128S dev board.jpg

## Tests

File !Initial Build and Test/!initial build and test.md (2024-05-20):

duodyne initial build and test findings

##

* 4-slot backplane power LED much too bright
* 4-slot backplane power connectors too close to processor slot

##

* ROMRAM memory configuration jumpers flipped on PCB (fixed 1.1)
* ROMRAM order the I2C jumper blocks the same as the I2C sockets -- would be even better if they could be made proximate (fixed 1.1)
* ROMRAM add bypass capacitors to the 24LC512 I2C memories (fixed 1.1)
* ROMRAM replace labels on J32-J35 with better descriptions (fixed 1.1)
* ROMRAM label DS1210s to match SRAMs (fixed 1.1)
* ROMRAM new layout for more logical structure (fixed 1.1)
* ROMRAM use 30mm speaker instead of tiny piezo (fixed 1.1)
* ROMRAM C15 reversed on back silkscreen (fixed 1.1)
* ROMRAM use TO-92 hand solder footprints (fixed 1.1)

##

* Z80 processor LEDs way too bright
* Z80 processor replace reset circuit with DS1233 (EconoReset) (fixed 1.1)
* Z80 processor remove spare debugging sockets, GAL, & portal holes (fixed 1.1)
* Z80 processor convert 74HCT244 symbols to 74LS244 (fixed 1.1)
* Z80 processor RUN and HALT labels reversed (fixed 1.1)
* Z80 processor change D0-D3 to D4-D7 on U22 74LS670 (fixed 1.1)
* Z80 processor R8 & R9 missing value labels (fixed 1.1)
* Z80 processor U6 reversed on back silkscreen (fixed 1.1)
* Z80 processor update to CPU-MAPPER-V3 GAL for I2C read and write fixes (fixed 1.1)
* Z80 processor requires updated U25 CPU-MAPPER GAL for I2C to function *and* U25 pins 13 and 14 connected (fixed 1.1)
* Z80 processor DMA D5 and D6 swapped in KiCAD symbol library (fixed 1.1)
* Z80 processor J3 and J4 should be labelled 1-8 not 0-7 (fixed 1.1)
* Z80 processor DMA CS GAL22V10 needs inverter on ~CPU-BUSACK for DMA-CS1 and DMA-CS2 (fixed 1.1)
* Z80 processor interrupts on IM2 reversed relative to CPU (fixed 1.1)
* Z80 processor add optional/experimental system tick timer (fixed 1.1)
* Z80 processor use TO-92 hand solder footprints (fixed 1.1)
* Z80 processor update U36 GAL to DMA-CS-V4 configuration (fixed 1.1)
* Z80 processor add jumper U36-13 to RN6-8 (fixed 1.1)

##

* Zilog IO U2 and U4 are really 74LS244s even though the front silkscreen says 74LS241s (fixed 1.1)
* Zilog IO Update U1 GAL to ZP-DATA-DIR-V2 configuration (fixed 1.1)
* Zilog IO Disconnect D6 from D5 on 1PIO and 2PIO (fixed 1.1)
* Zilog IO Mark default jumper locations on PCB front silkscreen (fixed 1.1)
* Zilog IO Consolidate multi small jumpers into a larger jumper group (fixed 1.1)

##

* Multi IO Replace 1K ohm isolated resistor networks DIP-14 with regular resistors due to obsolescence (fixed 1.1)
* Multi IO Swap Serial port A and Serial port B on TTL serial connector (A on the evens, B on the odds) (fixed 1.1)
* Multi IO add 3-pin jumper to select "reserved 2" on either 2x5 IDC PS/2 keyboard & mouse connector either pin 2 or 10 (fixed 1.1)
* Multi IO add CH376S-EVT board as alternate to CH376S and associated parts install (fixed 1.1)
* Multi IO add 10K ohm pull up resistors between U8 pin 16 and pin 9 and U9 pin 16 and pin 9 (fixed 1.1)
* Multi IO add jumpers on J1 and J13 (any) to prevent always on INT LED (fixed 1.1)
* Multi IO C23 in wrong place; should be near SD card socket (fixed 1.1)

##

* EPM7128S dev board Replace 470 ohm isolated resistor networks DIP-14 with same in DIP-16 due to obsolescence
* EPM7128S add 2 screw terminal for 9VDC
* EPM7128S add VCC and GND lugs for logic probe

##

* SAB80535 add VCC and GND lugs for logic probe (fixed 1.1)
* SAB80535 enlarge small labels for readability (fixed 1.1)
* SAB80535 Cut VCC trace between U10-pin32 and C12-pin1 so VBB is connected to GND via C12 not VCC (fixed 1.1)
* SAB80535 Rotate U5 180 degrees and U11 & U12 90 degrees so labels are consistent with board
* SAB80535 Replace R6 with 10K ohm resistor because LED is way too bright (fixed 1.1)
* SAB80535 Label J2 (9VDC screw terminal) connections 9VDC & GND (fixed 1.1)
* SAB80535 Add jumper select for pin 37 (VCC for SAB80C535 and 0.1uF to GND for SAB80535) (fixed 1.1)
* SAB80535 Replace SIL-6 TTL serial connectors with right angle 2x6 IDC and flip orientation (fixed 1.1)
* SAB80535 Replace 22.1184 MHz crystal with 11.0592 MHz crystal (fixed 1.1)
* SAB80535 Change LM7805 voltage regulator from vertical to horizontal with room for heatsink (fixed 1.1)
* SAB80535 FE/SS label is reversed; SS is 1-2 and FE is 3-4 (fixed 1.1)
* SAB80535 Label pins 1 and 2 on LCD interface pin socket (fixed 1.1)
* SAB80535 Replace 14-pin LCD interface with 16-pin version for LED backlight (fixed 1.1)
* SAB80535 Add LEDs for key signals (ROM /CS, RAM /CS, PPI0 & PPI1 /CS, LCD CS, LATCH /CS, /OE, /WR, T0, and T1) (fixed 1.1)
* SAB80535 Replace Flash ROM PLCC-32 with DIP-32 ZIF socket (fixed 1.1)
* SAB80535 Change LCD Vo Adjust circuit to use 10K Potentiometer (fixed 1.1)

##

* SelfHost exchange J3-pin1 with J3-pin4 (Tx and Rx reversed) (fixed 1.1)
* SelfHost Add BusMonitor function (fixed 1.1)

##

* Disk IO Change U26 (74AHC02) supply from VCC (5V) to VDD (3.3V) (fixed 1.1)
* Disk IO Remove R36 (22K) and R44 (22K); Replace R35 (10K) and R43 (10K) with wires (fixed 1.1)
* Disk IO Connect U28 & U29 D0-D7 to U14 bD0-bD7 (fixed 1.1)
* Disk IO Move SD socket up to top of board (fixed 1.1)
* Disk IO Remove U16 74LS273 as not used (fixed 1.1)
* Disk IO Add comment referring back to MT011 source document (fixed 1.1)
* Disk IO Remove R34, R39, R40, and R45 (fixed 1.1)
* Disk IO Replace R33, R37, R38, and R46 with IN5817 or BAT85 small signal Schottky barrier diode -- cathode towards 74HCT175 (fixed 1.1)

##

* front-panel Add mounting holes for OLED and microSD module (fixed 1.1)
* front-panel Reverse orientation of switches SW10-SW13 (fixed 1.1)
* front-panel Add 0.1uF bypass capacitor near U1 (fixed 1.1)

##

* Media IO "C37 should have the value on the top of the PCB not the Bottom" (fixed 1.1)
* Media IO "C42 and C46 footprints are a bit too close to the IC sockets and are too small for any 1000uf that I had in stock.   There is probably a 1000uf cap that would fit, but it seems like it might not be the one that many would have in stock."  Use an 8mm 1000 uF capacitor and be sure to get one that is not too tall (12mm height) (fixed 1.1)
* Media IO The PJ320E 3.5mm jack is way harder to source than the PJ320A.   Changing the footprint might make the board a bit more simple to get parts for. Use this one https://www.aliexpress.us/item/2251801525496024.html (fixed 1.1)
* Media IO "I am also having a tough time matching the footprint for the 8 pin RGB DIN connector.   I have several different 8 pin DIN sockets but the footprint does not match.   Do you have a part# or something more specific so I can widen my search a bit?"  Use Mouser 490-SDF-80J https://www.mouser.com/ProductDetail/490-SDF-80J (fixed 1.1)
* Media IO "The silk screen and comments on the schematic for the address jumper are wrong – default settings do not produce an “A0-A7” address." Should be IO Address Port $A0-$A7: 1-2 =off - A7 (high), 3-4 =on - A6 (low), 5-6 =off - A5 (high), 7-8 =on - A4 (low), 9-10 =on - A3 (low) (fixed 1.1)
* Media IO update MEDIA-CS-GAL to fix ~CS_ACR_WR inversion.  Use MEDIA-CS-V3-GAL JEDEC instead (fixed 1.1)
* Media IO /VINT polarity reversed (fixed 1.1).
* Media IO Add jumper for /VINT to /INT0 (fixed 1.1)
* Media IO Add power conditioning circuit from Sergey's Omega MSX2 for VDP and CXA1645 (fixed 1.1)
* Media IO Add VCC fill zone on component layer and GND fill zone on copper layer
* Media IO Replace 30pF cap with 30pF trimmer cap on VDP U6 pin 63 (fixed 1.1)

##

* Steps to fix /VINT polarity on Media IO V1.0: 
* cut trace (component side) between R24 pin 1 and U6 pin 25
* cut trace between (component side) R24 pin 1 and U4 pin 9
* cut trace between (copper side) U4 pin 9 and U4 pin 5 
* cut trace (copper side) between D3 pin 1 and U4 pin 8 
* jumper between R24 pin 1 and U4 pin 8
* jumper between U6 pin 25 and D3 pin 1
* jumper between D3 pin 1 and U4 pin 9 
* jumper between U4 pin 5 and U4 pin 8

##

* Voice IO cut trace from U1 pin 19 to U21 pin 19 (component side); jumper U25 pin 19 to U21 pin 19 (copper side); Data Bus transceiver tied to TTS only, should be whole board select
* Voice IO Update GAL U1 from Voice CS GAL to Voice CS V3 GAL
* Voice IO Replace C80 and C81 (0.22uF) with 68pF capacitors
* Voice IO Add 10K ohm resistor pull up to CTS256 pin 3 for optional debug monitor
* Voice IO Add latch for user enabled reset to CTS256 & SP0256
* Voice IO U9 Latch Enable incorrect; cut trace to U9, pin 11 (under U9, ZERO) and jumper between U9 pin 20 and U9 pin 11
* Voice IO UART PARMS jumper data bits in reverse order; 1-2 -> 15-16, 3-4 -> 13-14, etc.
* Voice IO Adding an IO write wait state on Z80 processor board will improve CTS256 stability
* Voice IO Add flip flop to parallel input circuit per Radio Shack original schematic
* Voice IO Connect R19 between U15 pin 3 and GND and R18 between U15 pin 2 and U15 pin 6
* Voice IO Replace R16 and R17 4700 ohm resistors with 10K ohm
* Voice IO Add 10nF cap between U15 pin 2 & U15 pin 6 to create a low pass filter with a knee around 3300 Hz
* Voice IO Replace linear pots with log-taper pots for audio

##

* All boards label the GAL sockets with their GAL names (like CPU-MAPPER) in addition to the Uxx designation
* All boards Ensure crystal oscillators are free of other traces interfering with connections
(RAMROM, Multi IO, Voice IO, Media IO, VDCENET, SAB80535)
* All boards for non-bus master/devices and slave devices, link /BAI-/BAO on the peripherals boards
* All boards for non-IM2 devices, link /IEO-/IEI on the peripherals boards
* All boards use /RES_OUT only on the peripheral boards (eliminate /RES_IN)

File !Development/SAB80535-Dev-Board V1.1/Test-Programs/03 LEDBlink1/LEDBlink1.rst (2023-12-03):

                                      1 ;--------------------------------------------------------
                                      2 ; File Created by SDCC : free open source ANSI-C Compiler
                                      3 ; Version 4.0.0 #11528 (Linux)
                                      4 ;--------------------------------------------------------
                                      5 	.module LEDBlink1
                                      6 	.optsdcc -mmcs51 --model-small
                                      7 	
                                      8 ;--------------------------------------------------------
                                      9 ; Public variables in this module
                                     10 ;--------------------------------------------------------
                                     11 	.globl _main
                                     12 	.globl _TF2
                                     13 	.globl _EXF2
                                     14 	.globl _RCLK
                                     15 	.globl _TCLK
                                     16 	.globl _EXEN2
                                     17 	.globl _TR2
                                     18 	.globl _C_T2
                                     19 	.globl _CP_RL2
                                     20 	.globl _T2CON_7
                                     21 	.globl _T2CON_6
                                     22 	.globl _T2CON_5
                                     23 	.globl _T2CON_4
                                     24 	.globl _T2CON_3
                                     25 	.globl _T2CON_2
                                     26 	.globl _T2CON_1
                                     27 	.globl _T2CON_0
                                     28 	.globl _PT2
                                     29 	.globl _ET2
                                     30 	.globl _CY
                                     31 	.globl _AC
                                     32 	.globl _F0
                                     33 	.globl _RS1
                                     34 	.globl _RS0
                                     35 	.globl _OV
                                     36 	.globl _F1
                                     37 	.globl _P
                                     38 	.globl _PS
                                     39 	.globl _PT1
                                     40 	.globl _PX1
                                     41 	.globl _PT0
                                     42 	.globl _PX0
                                     43 	.globl _RD
                                     44 	.globl _WR
                                     45 	.globl _T1
                                     46 	.globl _T0
                                     47 	.globl _INT1
                                     48 	.globl _INT0
                                     49 	.globl _TXD
                                     50 	.globl _RXD
                                     51 	.globl _P3_7
                                     52 	.globl _P3_6
                                     53 	.globl _P3_5
                                     54 	.globl _P3_4
                                     55 	.globl _P3_3
                                     56 	.globl _P3_2
                                     57 	.globl _P3_1
                                     58 	.globl _P3_0
                                     59 	.globl _EA
                                     60 	.globl _ES
                                     61 	.globl _ET1
                                     62 	.globl _EX1
                                     63 	.globl _ET0
                                     64 	.globl _EX0
                                     65 	.globl _P2_7
                                     66 	.globl _P2_6
                                     67 	.globl _P2_5
                                     68 	.globl _P2_4
                                     69 	.globl _P2_3
                                     70 	.globl _P2_2
                                     71 	.globl _P2_1
                                     72 	.globl _P2_0
                                     73 	.globl _SM0
                                     74 	.globl _SM1
                                     75 	.globl _SM2
                                     76 	.globl _REN
                                     77 	.globl _TB8
                                     78 	.globl _RB8
                                     79 	.globl _TI
                                     80 	.globl _RI
                                     81 	.globl _P1_7
                                     82 	.globl _P1_6
                                     83 	.globl _P1_5
                                     84 	.globl _P1_4
                                     85 	.globl _P1_3
                                     86 	.globl _P1_2
                                     87 	.globl _P1_1
                                     88 	.globl _P1_0
                                     89 	.globl _TF1
                                     90 	.globl _TR1
                                     91 	.globl _TF0
                                     92 	.globl _TR0
                                     93 	.globl _IE1
                                     94 	.globl _IT1
                                     95 	.globl _IE0
                                     96 	.globl _IT0
                                     97 	.globl _P0_7
                                     98 	.globl _P0_6
                                     99 	.globl _P0_5
                                    100 	.globl _P0_4
                                    101 	.globl _P0_3
                                    102 	.globl _P0_2
                                    103 	.globl _P0_1
                                    104 	.globl _P0_0
                                    105 	.globl _TH2
                                    106 	.globl _TL2
                                    107 	.globl _RCAP2H
                                    108 	.globl _RCAP2L
                                    109 	.globl _T2CON
                                    110 	.globl _B
                                    111 	.globl _ACC
                                    112 	.globl _PSW
                                    113 	.globl _IP
                                    114 	.globl _P3
                                    115 	.globl _IE
                                    116 	.globl _P2
                                    117 	.globl _SBUF
                                    118 	.globl _SCON
                                    119 	.globl _P1
                                    120 	.globl _TH1
                                    121 	.globl _TH0
                                    122 	.globl _TL1
                                    123 	.globl _TL0
                                    124 	.globl _TMOD
                                    125 	.globl _TCON
                                    126 	.globl _PCON
                                    127 	.globl _DPH
                                    128 	.globl _DPL
                                    129 	.globl _SP
                                    130 	.globl _P0
                                    131 	.globl _delay
                                    132 ;--------------------------------------------------------
                                    133 ; special function registers
                                    134 ;--------------------------------------------------------
                                    135 	.area RSEG    (ABS,DATA)
      000000                        136 	.org 0x0000
                           000080   137 _P0	=	0x0080
                           000081   138 _SP	=	0x0081
                           000082   139 _DPL	=	0x0082
                           000083   140 _DPH	=	0x0083
                           000087   141 _PCON	=	0x0087
                           000088   142 _TCON	=	0x0088
                           000089   143 _TMOD	=	0x0089
                           00008A   144 _TL0	=	0x008a
                           00008B   145 _TL1	=	0x008b
                           00008C   146 _TH0	=	0x008c
                           00008D   147 _TH1	=	0x008d
                           000090   148 _P1	=	0x0090
                           000098   149 _SCON	=	0x0098
                           000099   150 _SBUF	=	0x0099
                           0000A0   151 _P2	=	0x00a0
                           0000A8   152 _IE	=	0x00a8
                           0000B0   153 _P3	=	0x00b0
                           0000B8   154 _IP	=	0x00b8
                           0000D0   155 _PSW	=	0x00d0
                           0000E0   156 _ACC	=	0x00e0
                           0000F0   157 _B	=	0x00f0
                           0000C8   158 _T2CON	=	0x00c8
                           0000CA   159 _RCAP2L	=	0x00ca
                           0000CB   160 _RCAP2H	=	0x00cb
                           0000CC   161 _TL2	=	0x00cc
                           0000CD   162 _TH2	=	0x00cd
                                    163 ;--------------------------------------------------------
                                    164 ; special function bits
                                    165 ;--------------------------------------------------------
                                    166 	.area RSEG    (ABS,DATA)
      000000                        167 	.org 0x0000
                           000080   168 _P0_0	=	0x0080
                           000081   169 _P0_1	=	0x0081
                           000082   170 _P0_2	=	0x0082
                           000083   171 _P0_3	=	0x0083
                           000084   172 _P0_4	=	0x0084
                           000085   173 _P0_5	=	0x0085
                           000086   174 _P0_6	=	0x0086
                           000087   175 _P0_7	=	0x0087
                           000088   176 _IT0	=	0x0088
                           000089   177 _IE0	=	0x0089
                           00008A   178 _IT1	=	0x008a
                           00008B   179 _IE1	=	0x008b
                           00008C   180 _TR0	=	0x008c
                           00008D   181 _TF0	=	0x008d
                           00008E   182 _TR1	=	0x008e
                           00008F   183 _TF1	=	0x008f
                           000090   184 _P1_0	=	0x0090
                           000091   185 _P1_1	=	0x0091
                           000092   186 _P1_2	=	0x0092
                           000093   187 _P1_3	=	0x0093
                           000094   188 _P1_4	=	0x0094
                           000095   189 _P1_5	=	0x0095
                           000096   190 _P1_6	=	0x0096
                           000097   191 _P1_7	=	0x0097
                           000098   192 _RI	=	0x0098
                           000099   193 _TI	=	0x0099
                           00009A   194 _RB8	=	0x009a
                           00009B   195 _TB8	=	0x009b
                           00009C   196 _REN	=	0x009c
                           00009D   197 _SM2	=	0x009d
                           00009E   198 _SM1	=	0x009e
                           00009F   199 _SM0	=	0x009f
                           0000A0   200 _P2_0	=	0x00a0
                           0000A1   201 _P2_1	=	0x00a1
                           0000A2   202 _P2_2	=	0x00a2
                           0000A3   203 _P2_3	=	0x00a3
                           0000A4   204 _P2_4	=	0x00a4
                           0000A5   205 _P2_5	=	0x00a5
                           0000A6   206 _P2_6	=	0x00a6
                           0000A7   207 _P2_7	=	0x00a7
                           0000A8   208 _EX0	=	0x00a8
                           0000A9   209 _ET0	=	0x00a9
                           0000AA   210 _EX1	=	0x00aa
                           0000AB   211 _ET1	=	0x00ab
                           0000AC   212 _ES	=	0x00ac
                           0000AF   213 _EA	=	0x00af
                           0000B0   214 _P3_0	=	0x00b0
                           0000B1   215 _P3_1	=	0x00b1
                           0000B2   216 _P3_2	=	0x00b2
                           0000B3   217 _P3_3	=	0x00b3
                           0000B4   218 _P3_4	=	0x00b4
                           0000B5   219 _P3_5	=	0x00b5
                           0000B6   220 _P3_6	=	0x00b6
                           0000B7   221 _P3_7	=	0x00b7
                           0000B0   222 _RXD	=	0x00b0
                           0000B1   223 _TXD	=	0x00b1
                           0000B2   224 _INT0	=	0x00b2
                           0000B3   225 _INT1	=	0x00b3
                           0000B4   226 _T0	=	0x00b4
                           0000B5   227 _T1	=	0x00b5
                           0000B6   228 _WR	=	0x00b6
                           0000B7   229 _RD	=	0x00b7
                           0000B8   230 _PX0	=	0x00b8
                           0000B9   231 _PT0	=	0x00b9
                           0000BA   232 _PX1	=	0x00ba
                           0000BB   233 _PT1	=	0x00bb
                           0000BC   234 _PS	=	0x00bc
                           0000D0   235 _P	=	0x00d0
                           0000D1   236 _F1	=	0x00d1
                           0000D2   237 _OV	=	0x00d2
                           0000D3   238 _RS0	=	0x00d3
                           0000D4   239 _RS1	=	0x00d4
                           0000D5   240 _F0	=	0x00d5
                           0000D6   241 _AC	=	0x00d6
                           0000D7   242 _CY	=	0x00d7
                           0000AD   243 _ET2	=	0x00ad
                           0000BD   244 _PT2	=	0x00bd
                           0000C8   245 _T2CON_0	=	0x00c8
                           0000C9   246 _T2CON_1	=	0x00c9
                           0000CA   247 _T2CON_2	=	0x00ca
                           0000CB   248 _T2CON_3	=	0x00cb
                           0000CC   249 _T2CON_4	=	0x00cc
                           0000CD   250 _T2CON_5	=	0x00cd
                           0000CE   251 _T2CON_6	=	0x00ce
                           0000CF   252 _T2CON_7	=	0x00cf
                           0000C8   253 _CP_RL2	=	0x00c8
                           0000C9   254 _C_T2	=	0x00c9
                           0000CA   255 _TR2	=	0x00ca
                           0000CB   256 _EXEN2	=	0x00cb
                           0000CC   257 _TCLK	=	0x00cc
                           0000CD   258 _RCLK	=	0x00cd
                           0000CE   259 _EXF2	=	0x00ce
                           0000CF   260 _TF2	=	0x00cf
                                    261 ;--------------------------------------------------------
                                    262 ; overlayable register banks
                                    263 ;--------------------------------------------------------
                                    264 	.area REG_BANK_0	(REL,OVR,DATA)
      000000                        265 	.ds 8
                                    266 ;--------------------------------------------------------
                                    267 ; internal ram data
                                    268 ;--------------------------------------------------------
                                    269 	.area DSEG    (DATA)
                                    270 ;--------------------------------------------------------
                                    271 ; overlayable items in internal ram 
                                    272 ;--------------------------------------------------------
                                    273 	.area	OSEG    (OVR,DATA)
                                    274 ;--------------------------------------------------------
                                    275 ; Stack segment in internal ram 
                                    276 ;--------------------------------------------------------
                                    277 	.area	SSEG
      000008                        278 __start__stack:
      000008                        279 	.ds	1
                                    280 
                                    281 ;--------------------------------------------------------
                                    282 ; indirectly addressable internal ram data
                                    283 ;--------------------------------------------------------
                                    284 	.area ISEG    (DATA)
                                    285 ;--------------------------------------------------------
                                    286 ; absolute internal ram data
                                    287 ;--------------------------------------------------------
                                    288 	.area IABS    (ABS,DATA)
                                    289 	.area IABS    (ABS,DATA)
                                    290 ;--------------------------------------------------------
                                    291 ; bit data
                                    292 ;--------------------------------------------------------
                                    293 	.area BSEG    (BIT)
                                    294 ;--------------------------------------------------------
                                    295 ; paged external ram data
                                    296 ;--------------------------------------------------------
                                    297 	.area PSEG    (PAG,XDATA)
                                    298 ;--------------------------------------------------------
                                    299 ; external ram data
                                    300 ;--------------------------------------------------------
                                    301 	.area XSEG    (XDATA)
                                    302 ;--------------------------------------------------------
                                    303 ; absolute external ram data
                                    304 ;--------------------------------------------------------
                                    305 	.area XABS    (ABS,XDATA)
                                    306 ;--------------------------------------------------------
                                    307 ; external initialized ram data
                                    308 ;--------------------------------------------------------
                                    309 	.area XISEG   (XDATA)
                                    310 	.area HOME    (CODE)
                                    311 	.area GSINIT0 (CODE)
                                    312 	.area GSINIT1 (CODE)
                                    313 	.area GSINIT2 (CODE)
                                    314 	.area GSINIT3 (CODE)
                                    315 	.area GSINIT4 (CODE)
                                    316 	.area GSINIT5 (CODE)
                                    317 	.area GSINIT  (CODE)
                                    318 	.area GSFINAL (CODE)
                                    319 	.area CSEG    (CODE)
                                    320 ;--------------------------------------------------------
                                    321 ; interrupt vector 
                                    322 ;--------------------------------------------------------
                                    323 	.area HOME    (CODE)
      000000                        324 __interrupt_vect:
      000000 02 00 06         [24]  325 	ljmp	__sdcc_gsinit_startup
                                    326 ;--------------------------------------------------------
                                    327 ; global & static initialisations
                                    328 ;--------------------------------------------------------
                                    329 	.area HOME    (CODE)
                                    330 	.area GSINIT  (CODE)
                                    331 	.area GSFINAL (CODE)
                                    332 	.area GSINIT  (CODE)
                                    333 	.globl __sdcc_gsinit_startup
                                    334 	.globl __sdcc_program_startup
                                    335 	.globl __start__stack
                                    336 	.globl __mcs51_genXINIT
                                    337 	.globl __mcs51_genXRAMCLEAR
                                    338 	.globl __mcs51_genRAMCLEAR
                                    339 	.area GSFINAL (CODE)
      00005F 02 00 03         [24]  340 	ljmp	__sdcc_program_startup
                                    341 ;--------------------------------------------------------
                                    342 ; Home
                                    343 ;--------------------------------------------------------
                                    344 	.area HOME    (CODE)
                                    345 	.area HOME    (CODE)
      000003                        346 __sdcc_program_startup:
      000003 02 00 62         [24]  347 	ljmp	_main
                                    348 ;	return from main will return to caller
                                    349 ;--------------------------------------------------------
                                    350 ; code
                                    351 ;--------------------------------------------------------
                                    352 	.area CSEG    (CODE)
                                    353 ;------------------------------------------------------------
                                    354 ;Allocation info for local variables in function 'main'
                                    355 ;------------------------------------------------------------
                                    356 ;	LEDBlink1.c:5: void main(void)
                                    357 ;	-----------------------------------------
                                    358 ;	 function main
                                    359 ;	-----------------------------------------
      000062                        360 _main:
                           000007   361 	ar7 = 0x07
                           000006   362 	ar6 = 0x06
                           000005   363 	ar5 = 0x05
                           000004   364 	ar4 = 0x04
                           000003   365 	ar3 = 0x03
                           000002   366 	ar2 = 0x02
                           000001   367 	ar1 = 0x01
                           000000   368 	ar0 = 0x00
                                    369 ;	LEDBlink1.c:7: while(1)
      000062                        370 00102$:
                                    371 ;	LEDBlink1.c:9: P1 = 0xFF; // Turn ON all LED's connected to Port1
      000062 75 90 FF         [24]  372 	mov	_P1,#0xff
                                    373 ;	LEDBlink1.c:10: delay();
      000065 12 00 70         [24]  374 	lcall	_delay
                                    375 ;	LEDBlink1.c:11: P1 = 0x00; // Turn OFF all LED's connected to Port1
      000068 75 90 00         [24]  376 	mov	_P1,#0x00
                                    377 ;	LEDBlink1.c:12: delay();
      00006B 12 00 70         [24]  378 	lcall	_delay
                                    379 ;	LEDBlink1.c:14: }
      00006E 80 F2            [24]  380 	sjmp	00102$
                                    381 ;------------------------------------------------------------
                                    382 ;Allocation info for local variables in function 'delay'
                                    383 ;------------------------------------------------------------
                                    384 ;i                         Allocated to registers r6 r7 
                                    385 ;j                         Allocated to registers r4 r5 
                                    386 ;------------------------------------------------------------
                                    387 ;	LEDBlink1.c:16: void delay(void)
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

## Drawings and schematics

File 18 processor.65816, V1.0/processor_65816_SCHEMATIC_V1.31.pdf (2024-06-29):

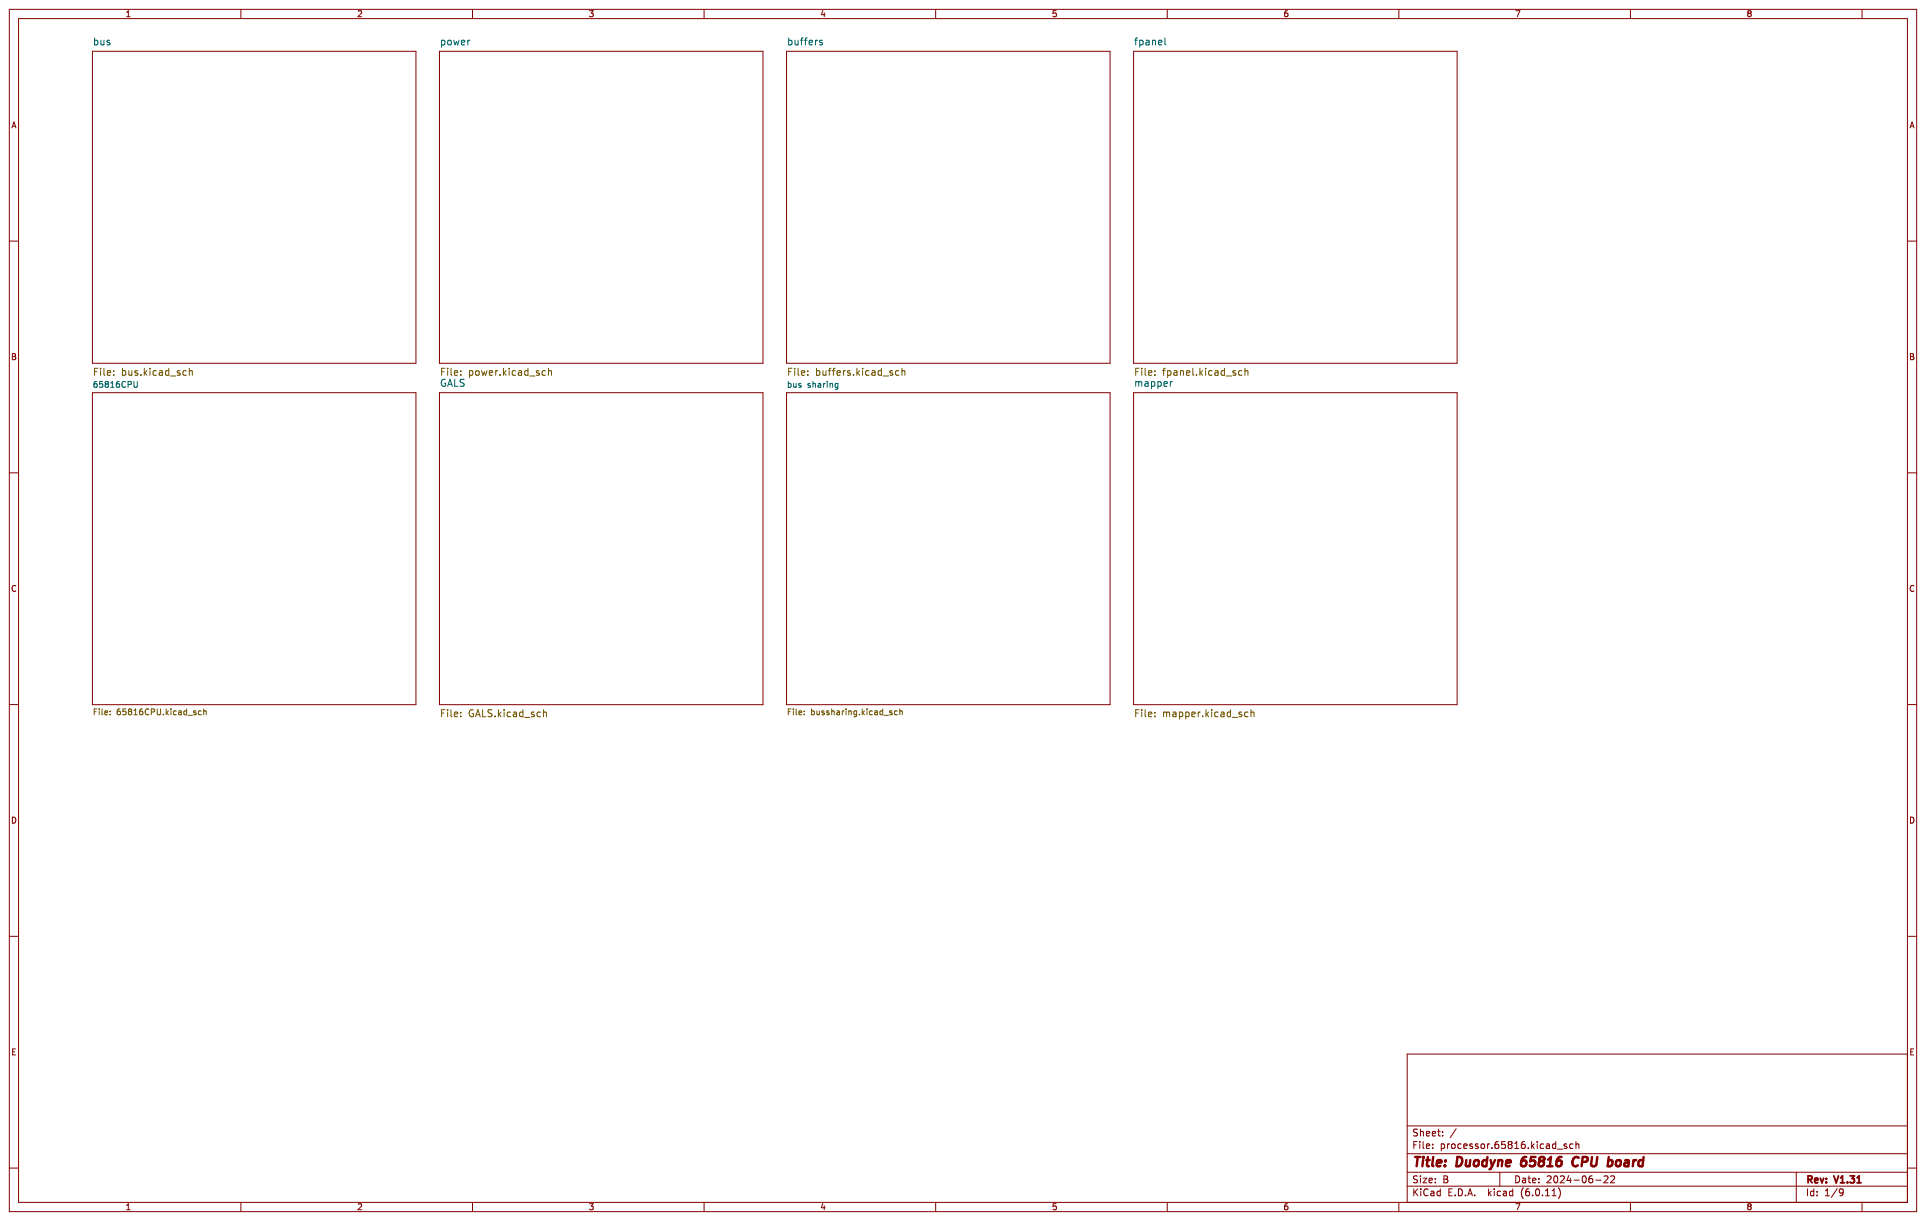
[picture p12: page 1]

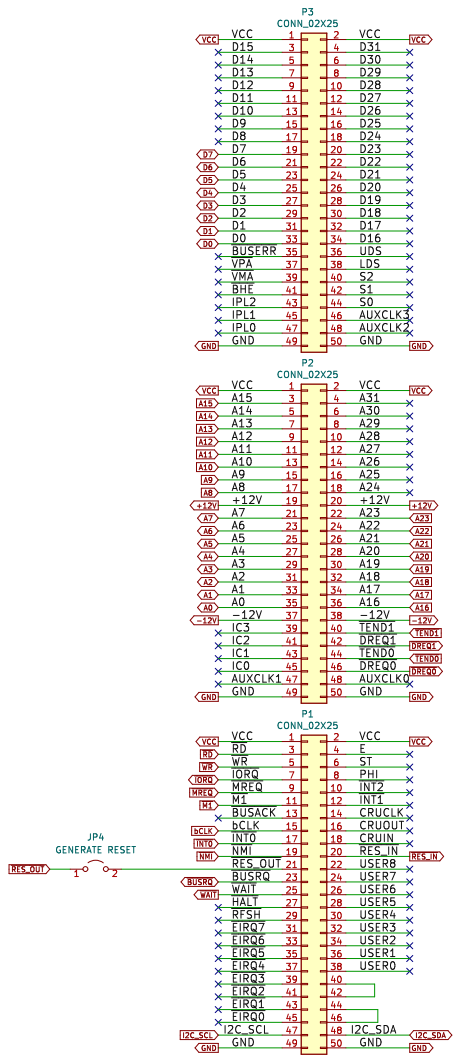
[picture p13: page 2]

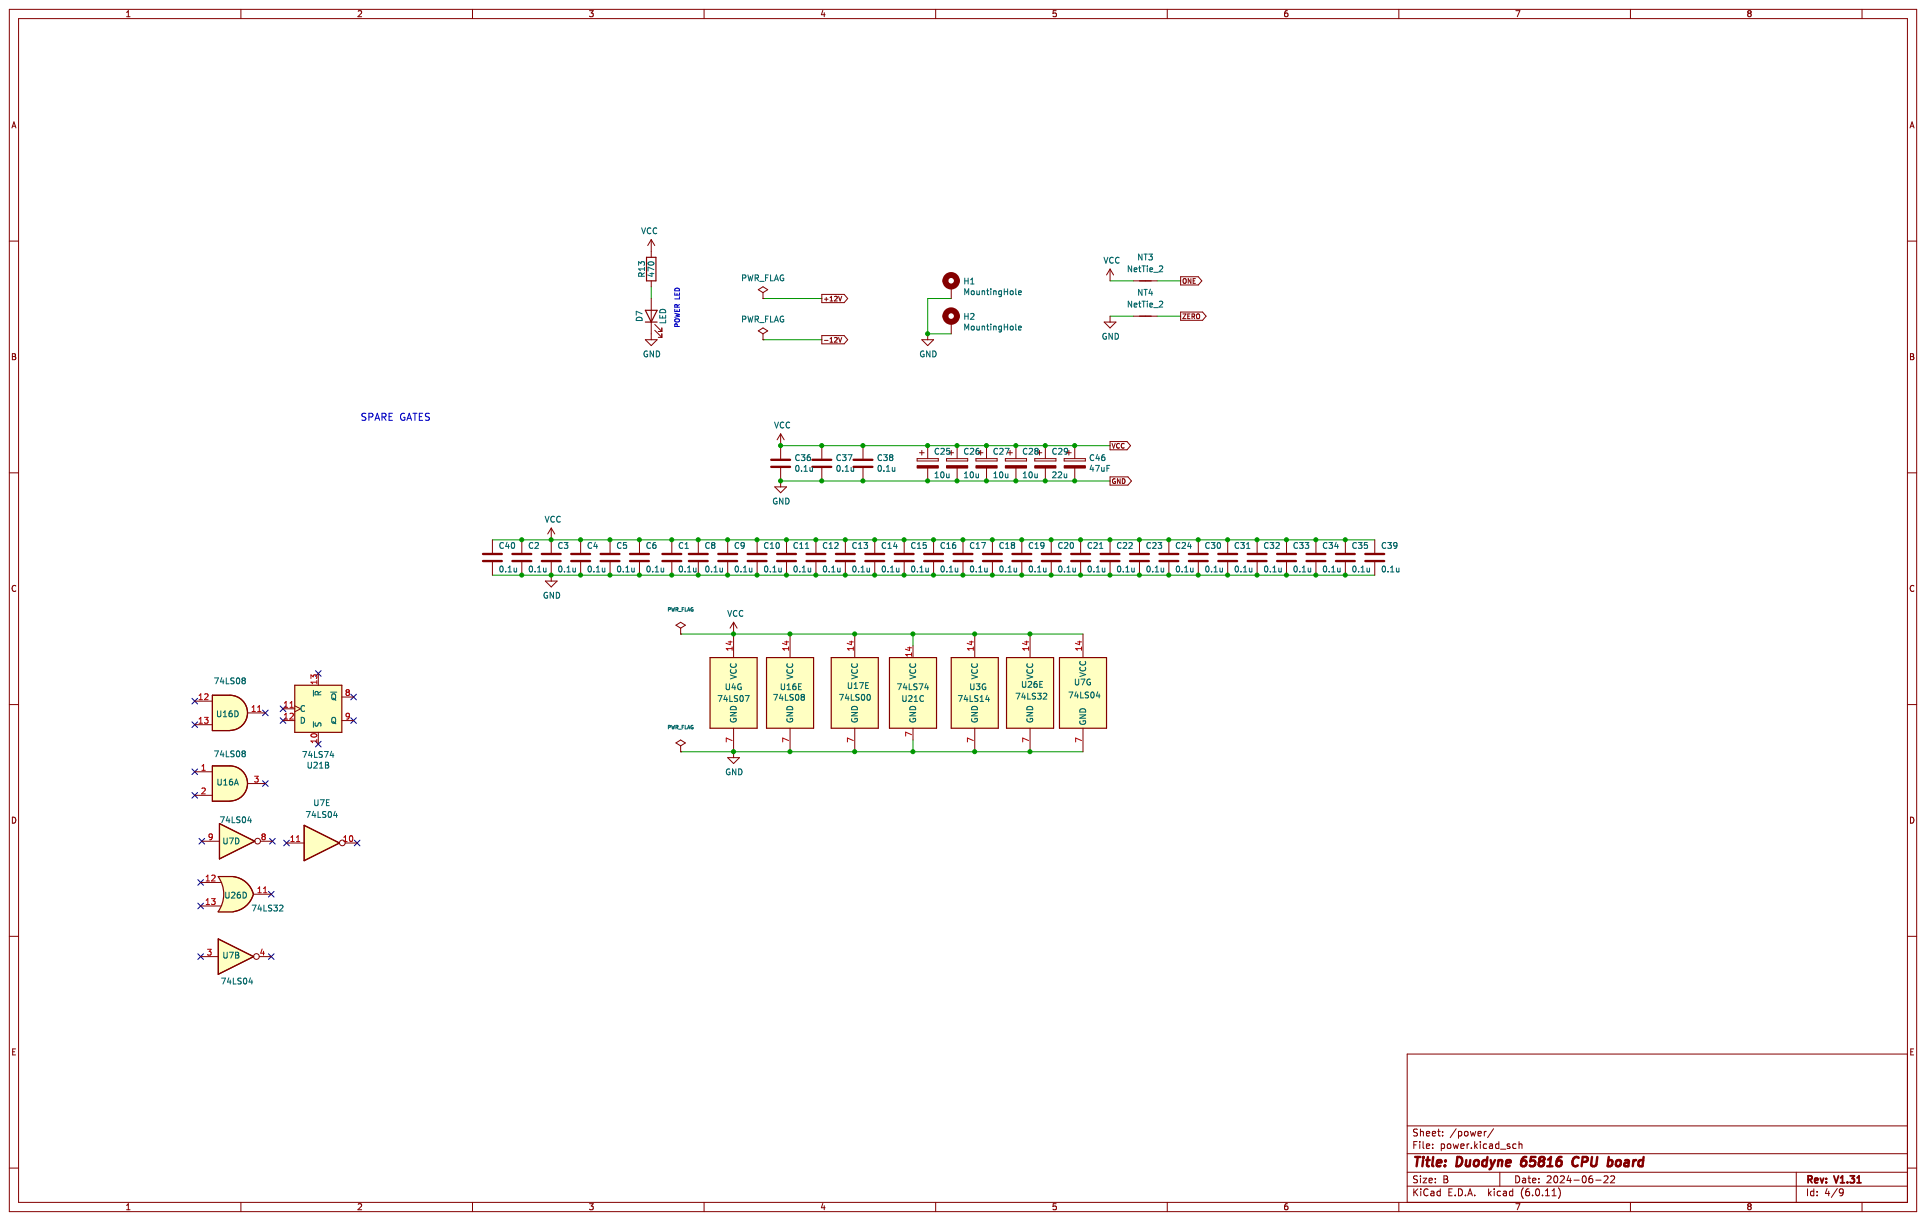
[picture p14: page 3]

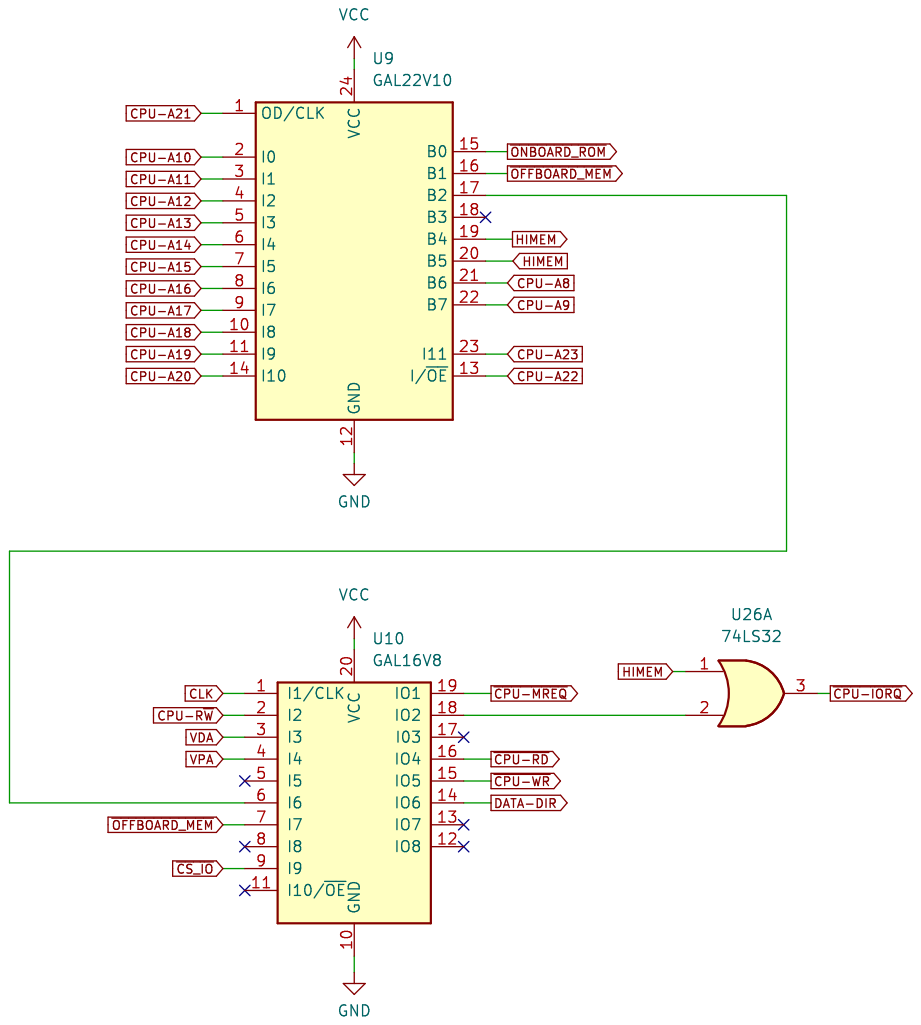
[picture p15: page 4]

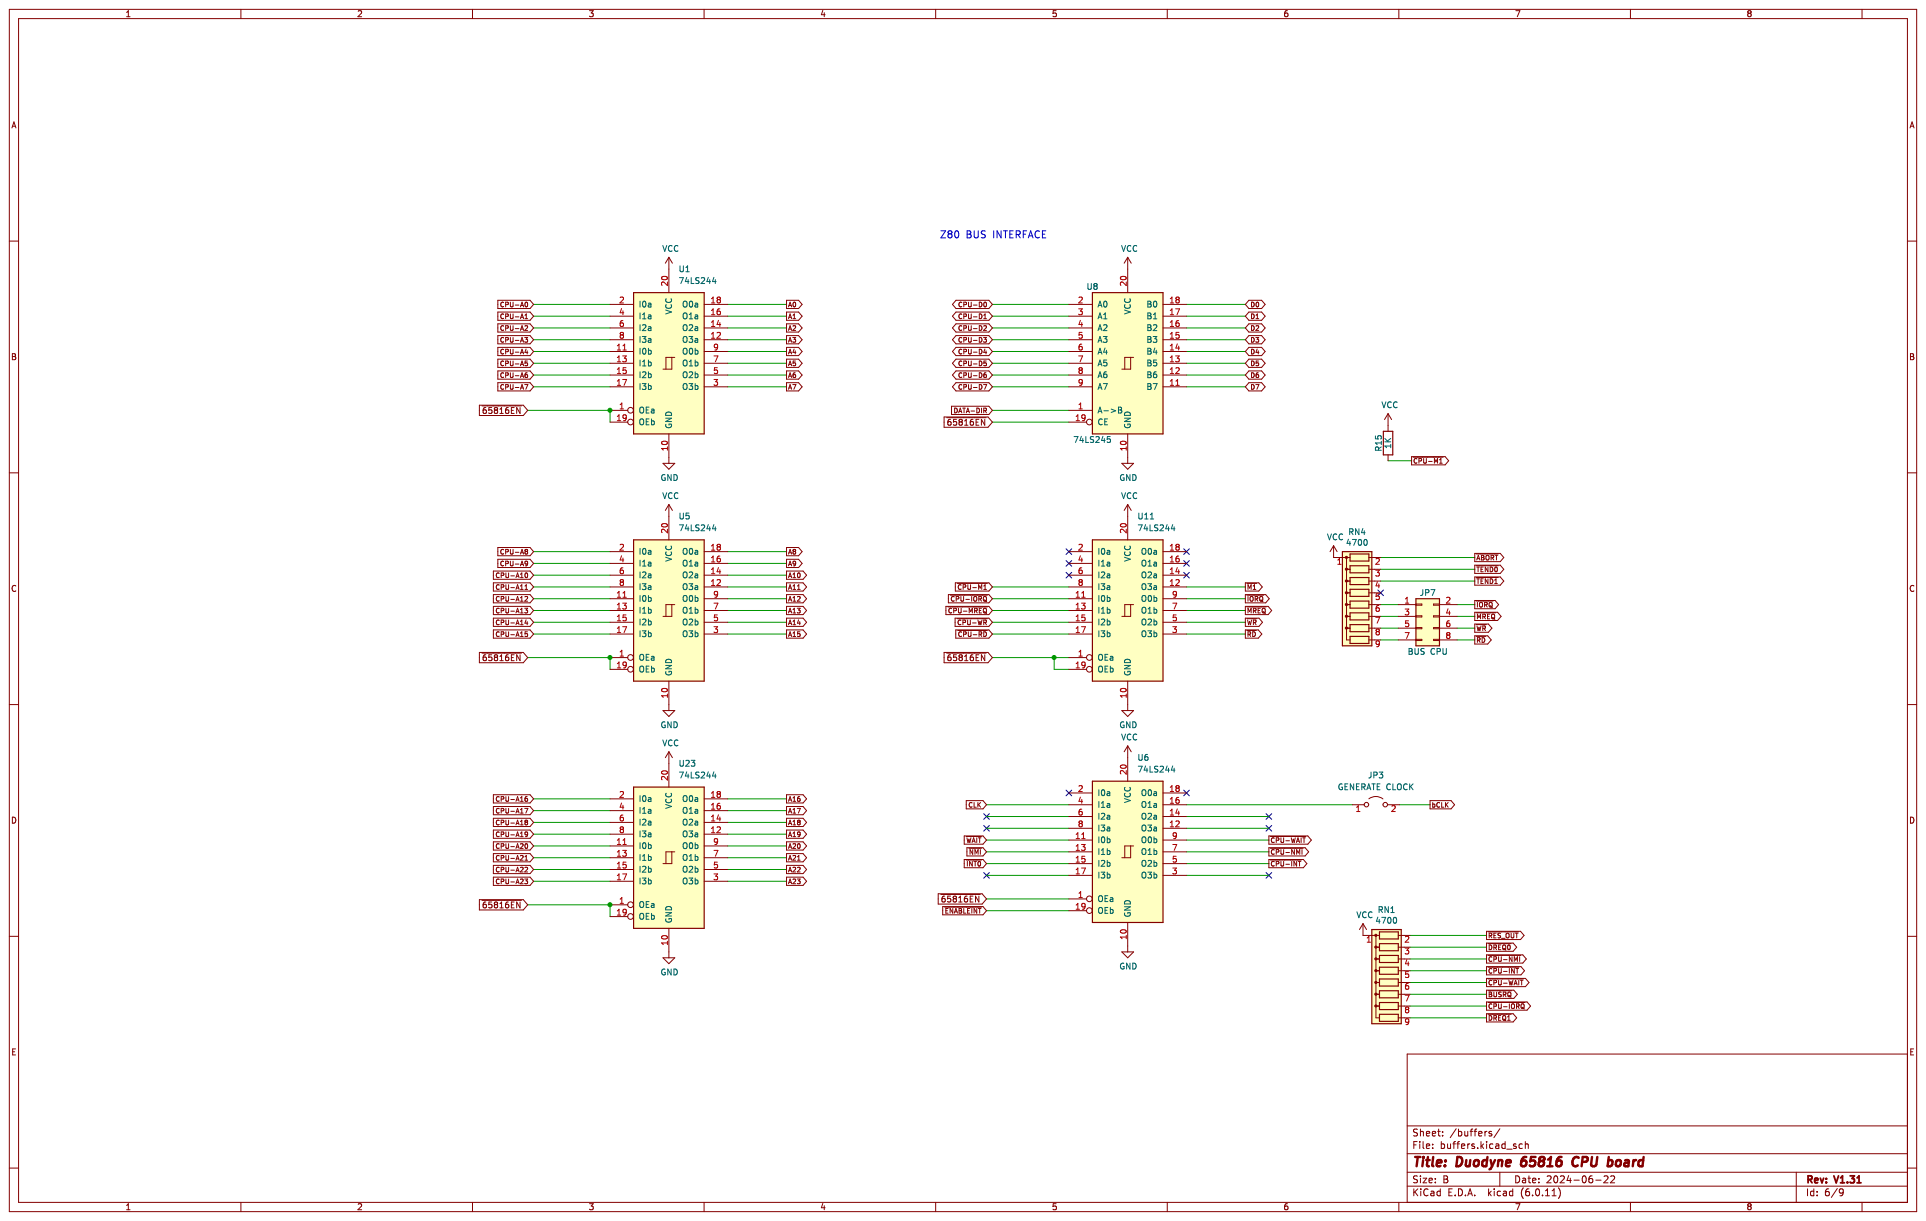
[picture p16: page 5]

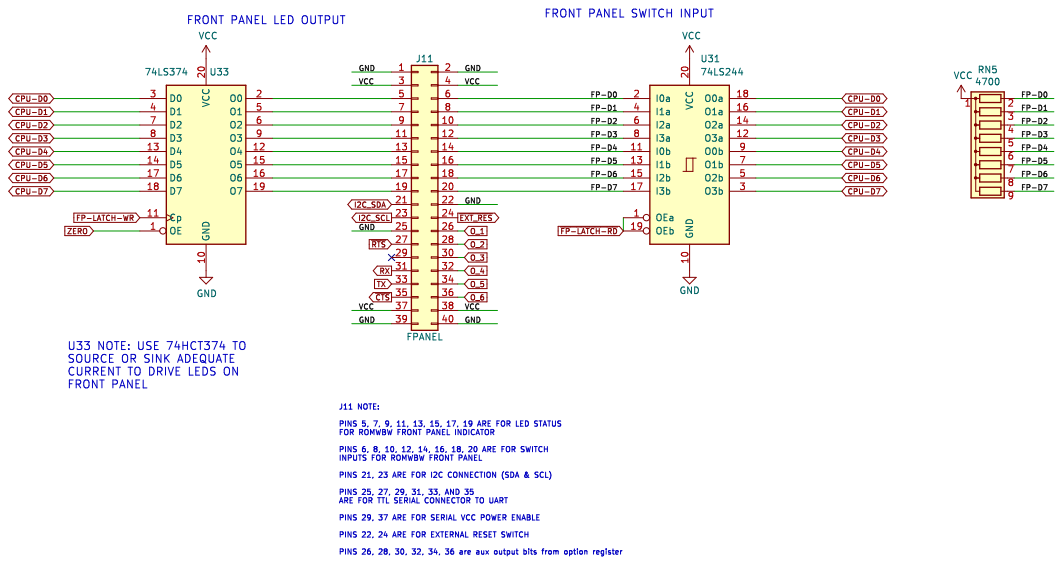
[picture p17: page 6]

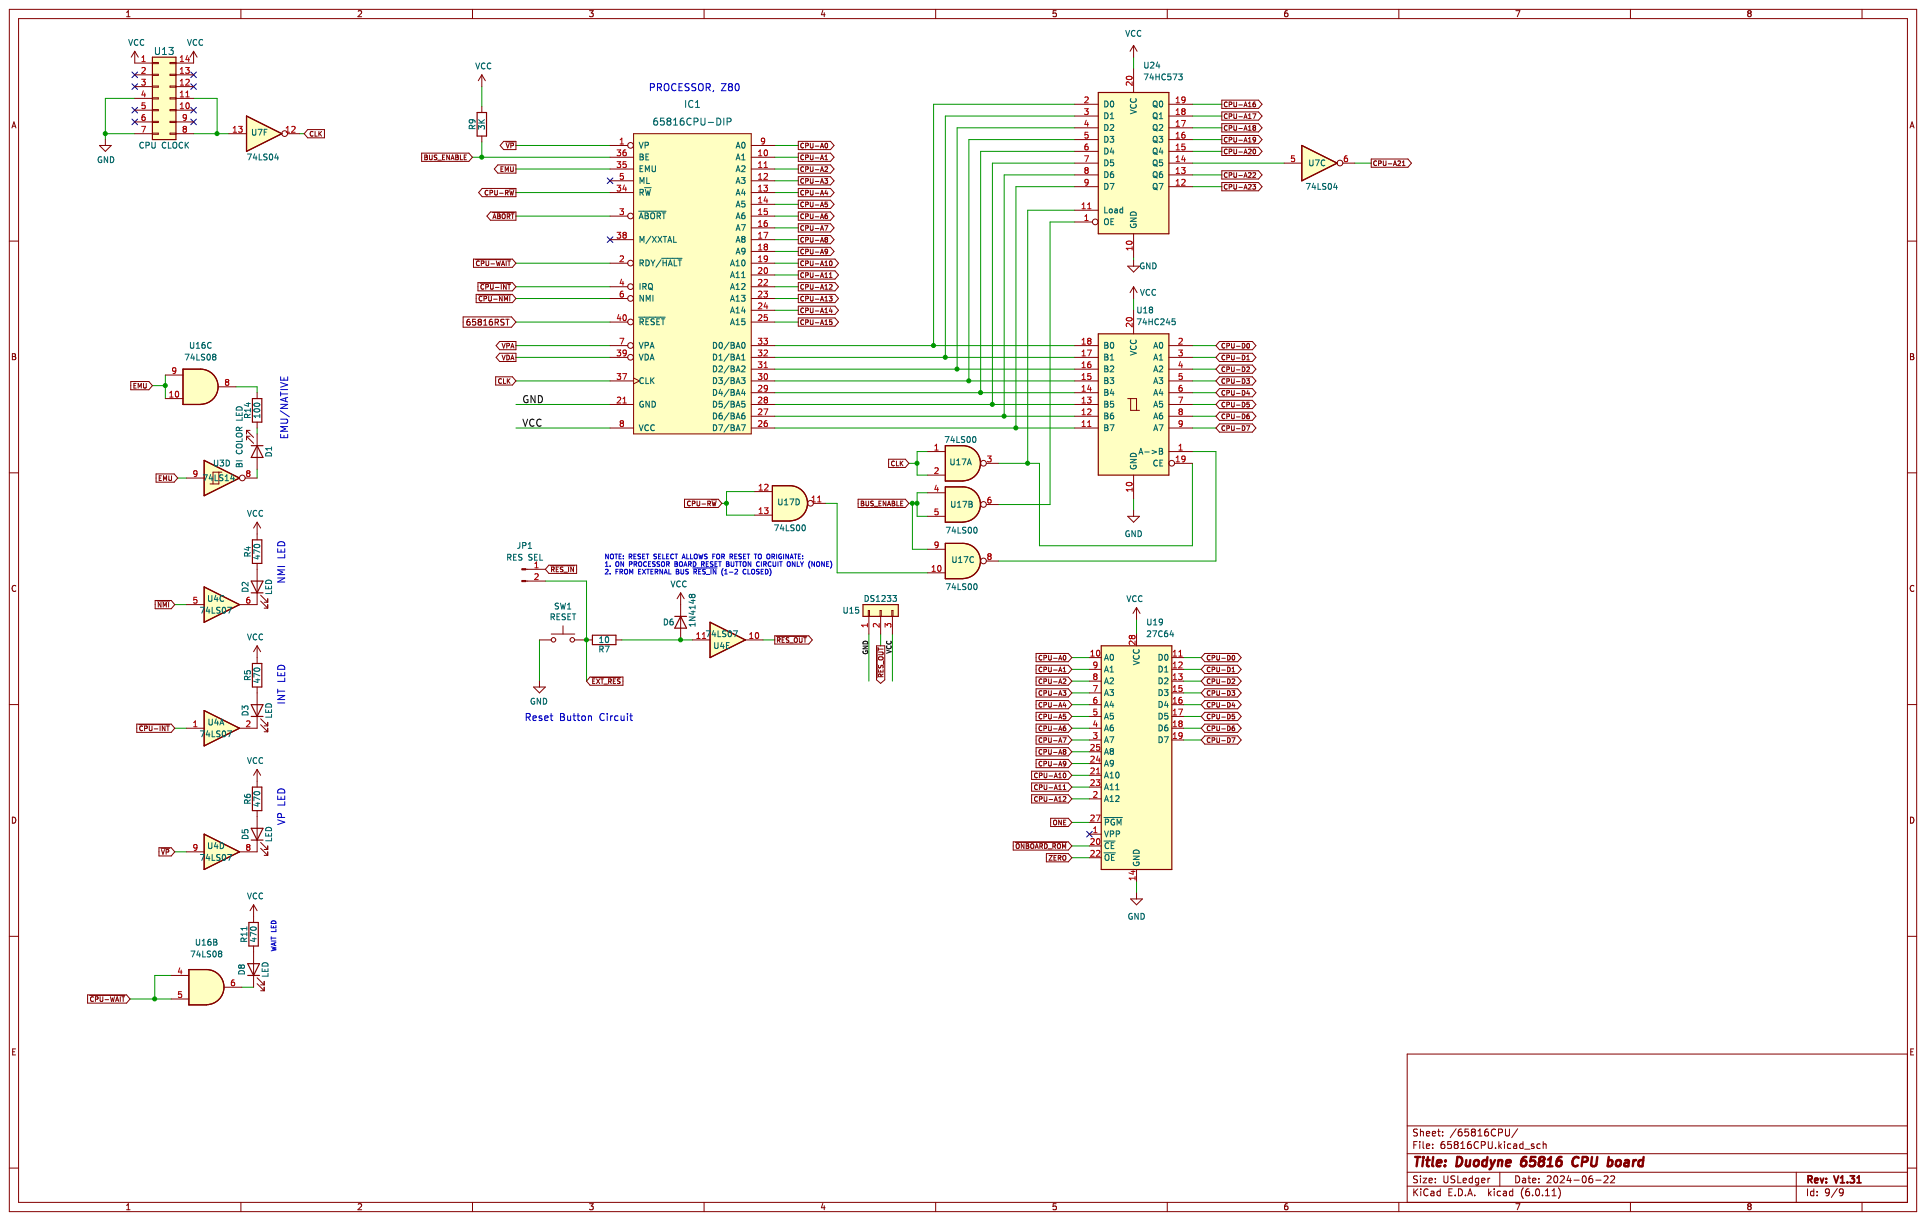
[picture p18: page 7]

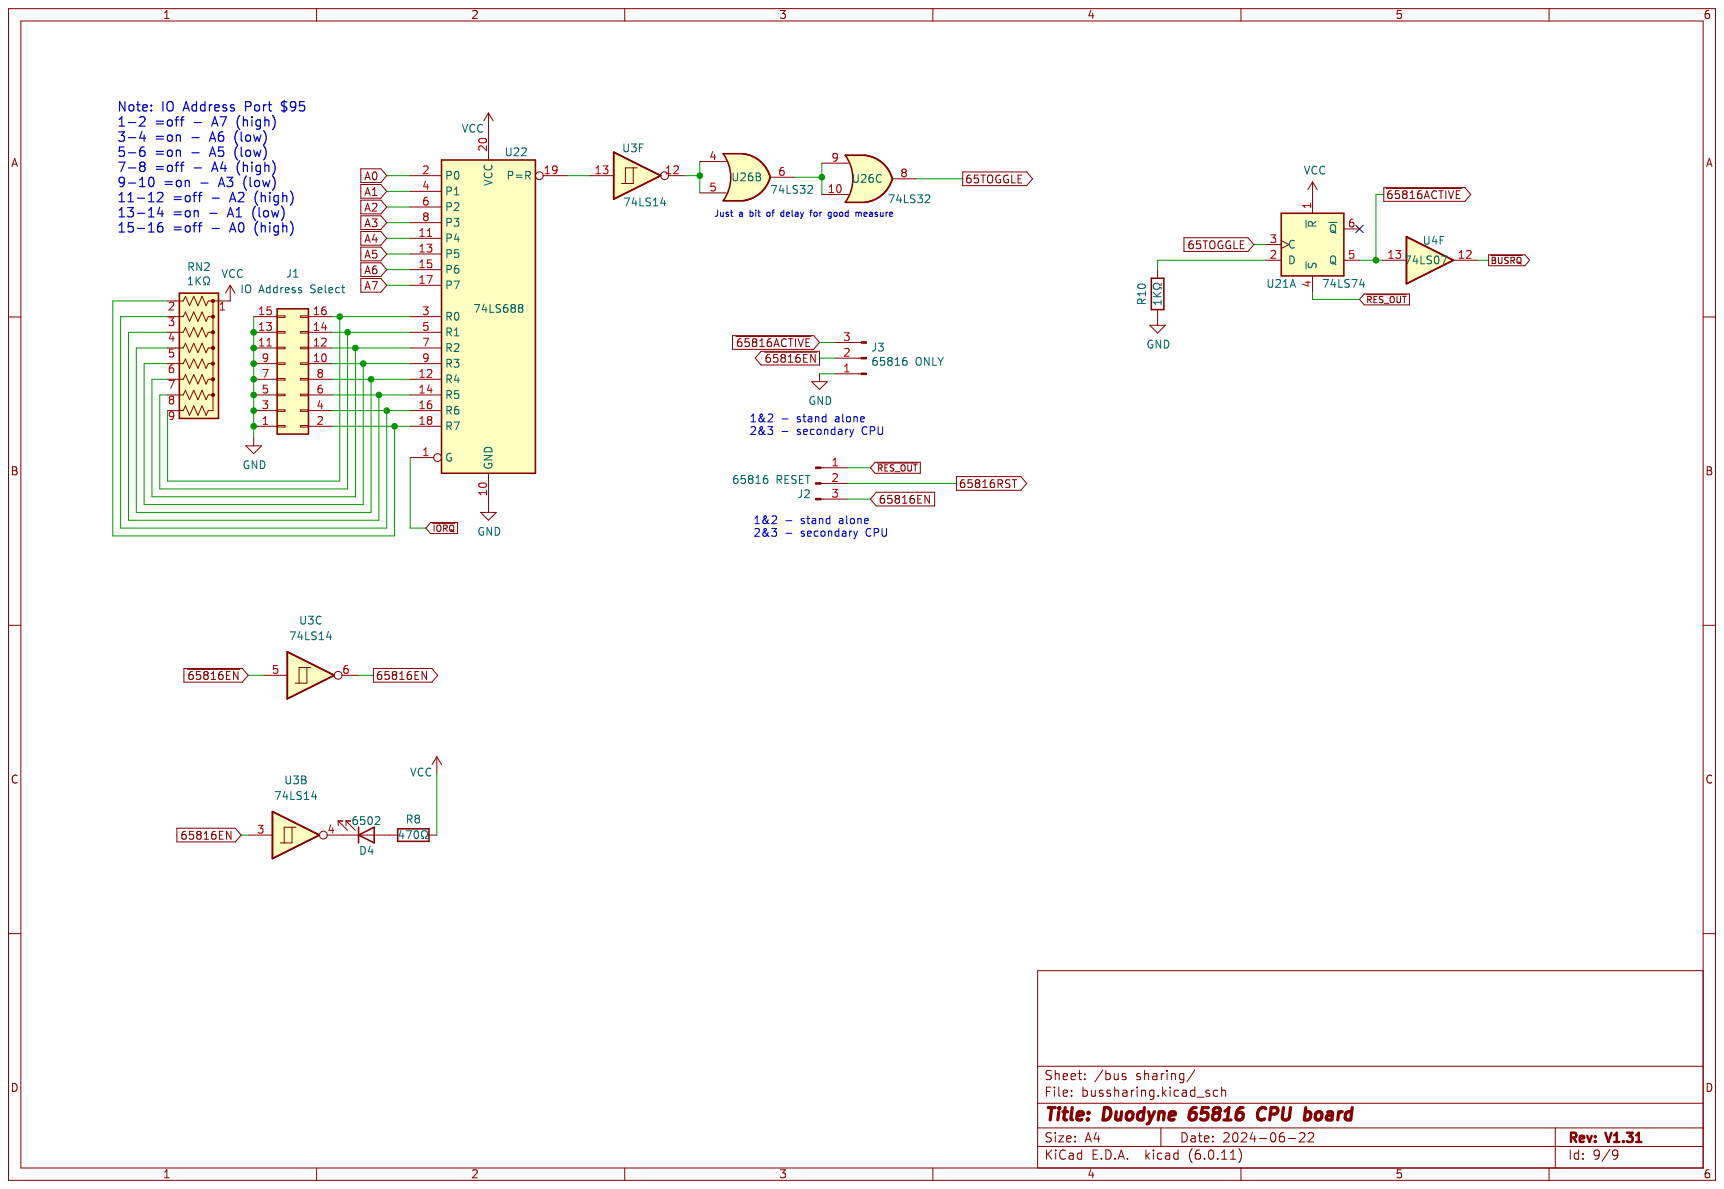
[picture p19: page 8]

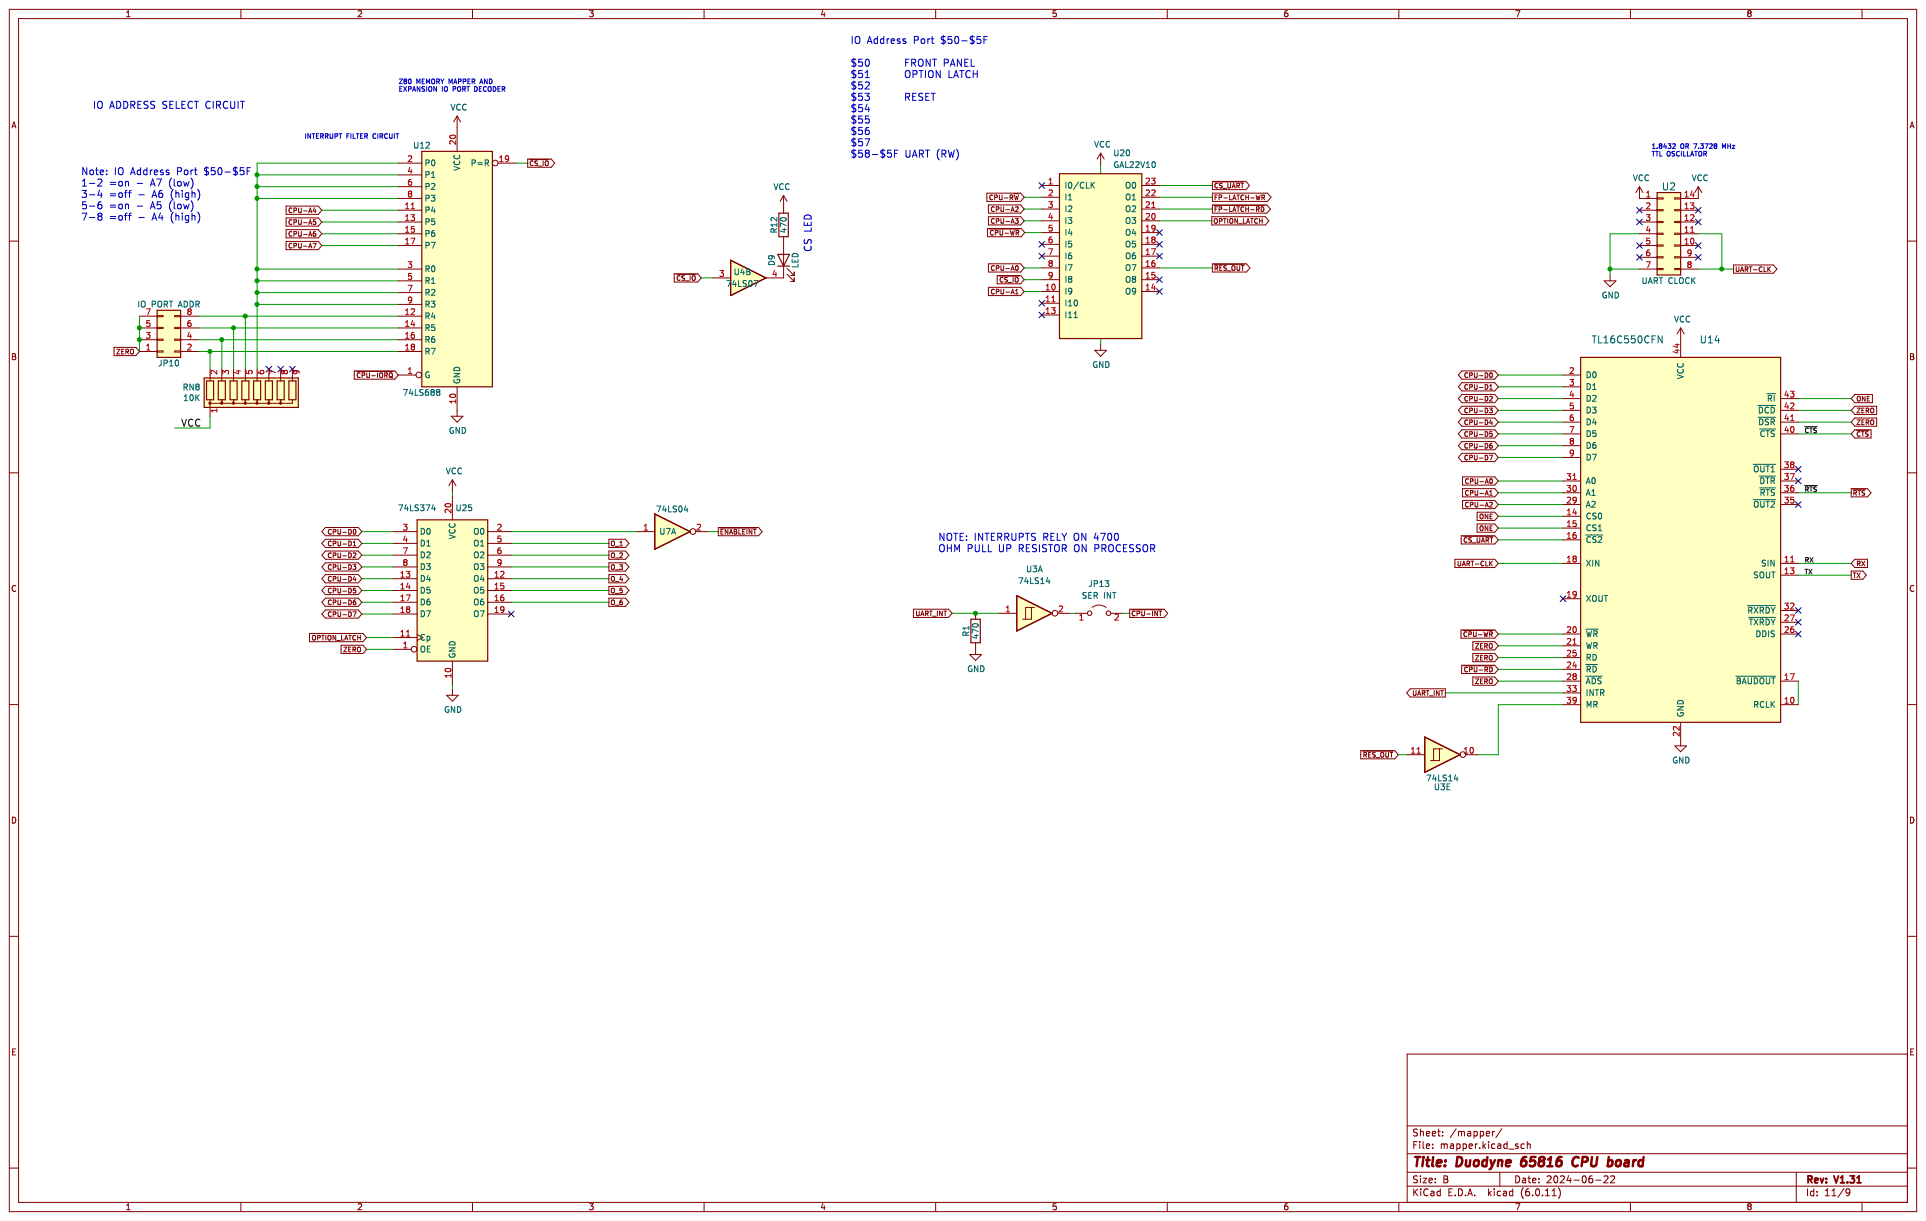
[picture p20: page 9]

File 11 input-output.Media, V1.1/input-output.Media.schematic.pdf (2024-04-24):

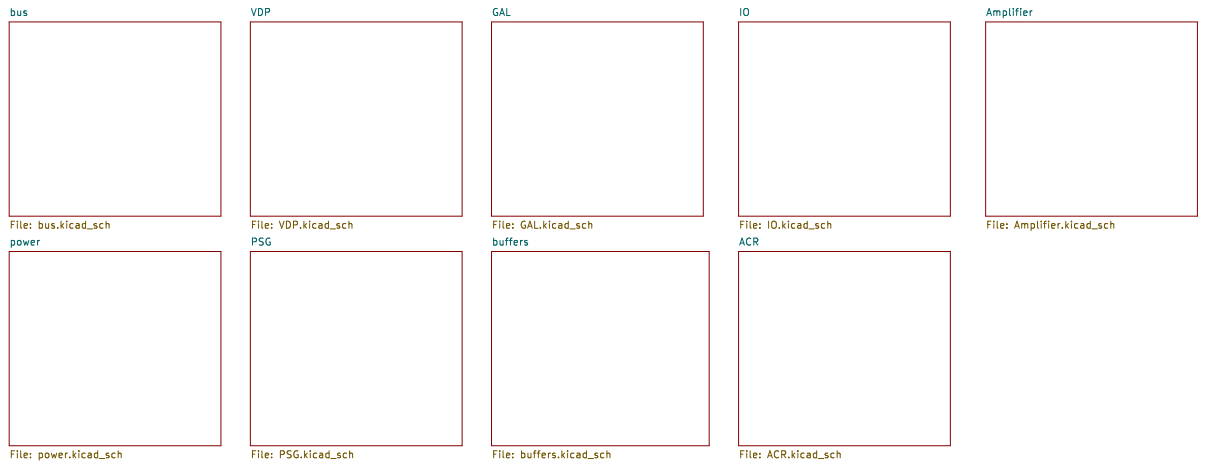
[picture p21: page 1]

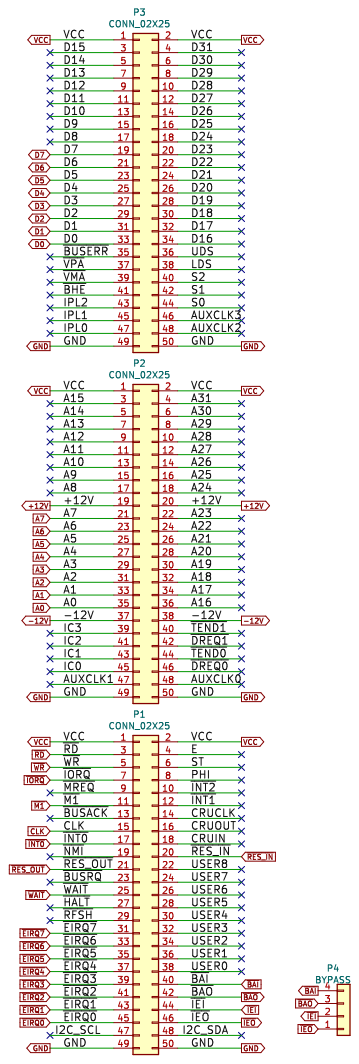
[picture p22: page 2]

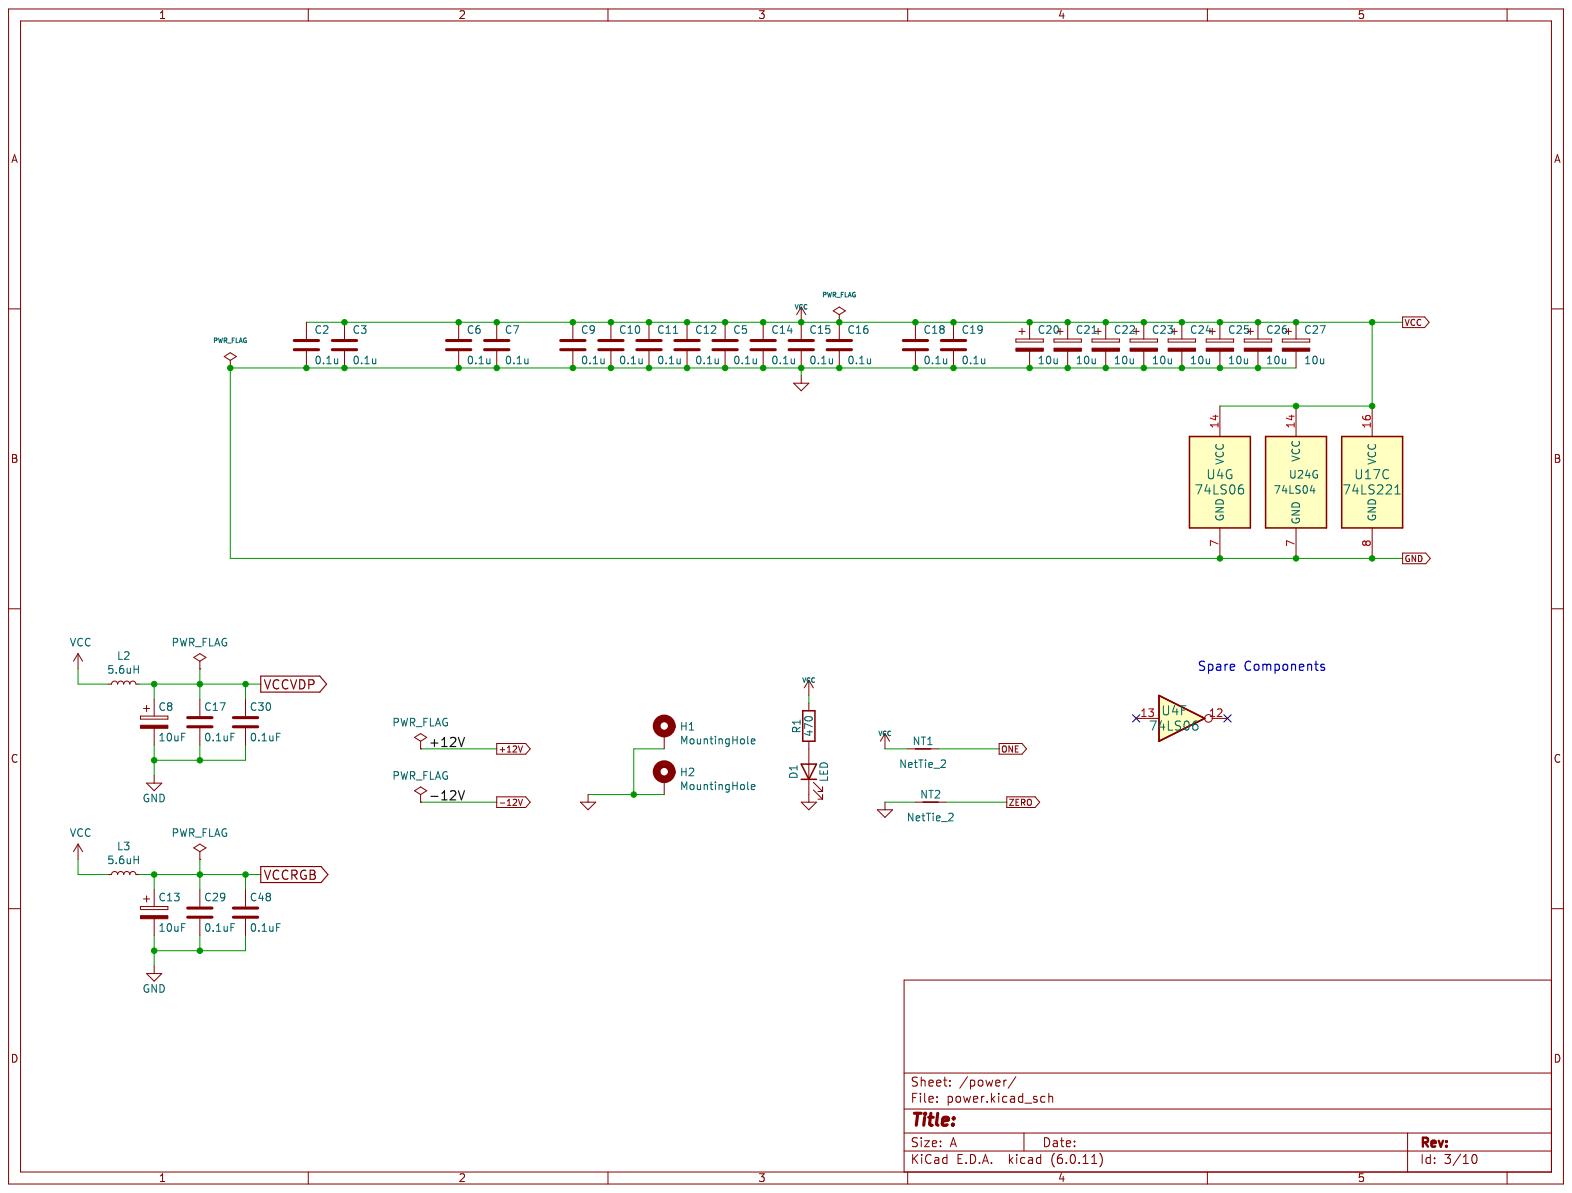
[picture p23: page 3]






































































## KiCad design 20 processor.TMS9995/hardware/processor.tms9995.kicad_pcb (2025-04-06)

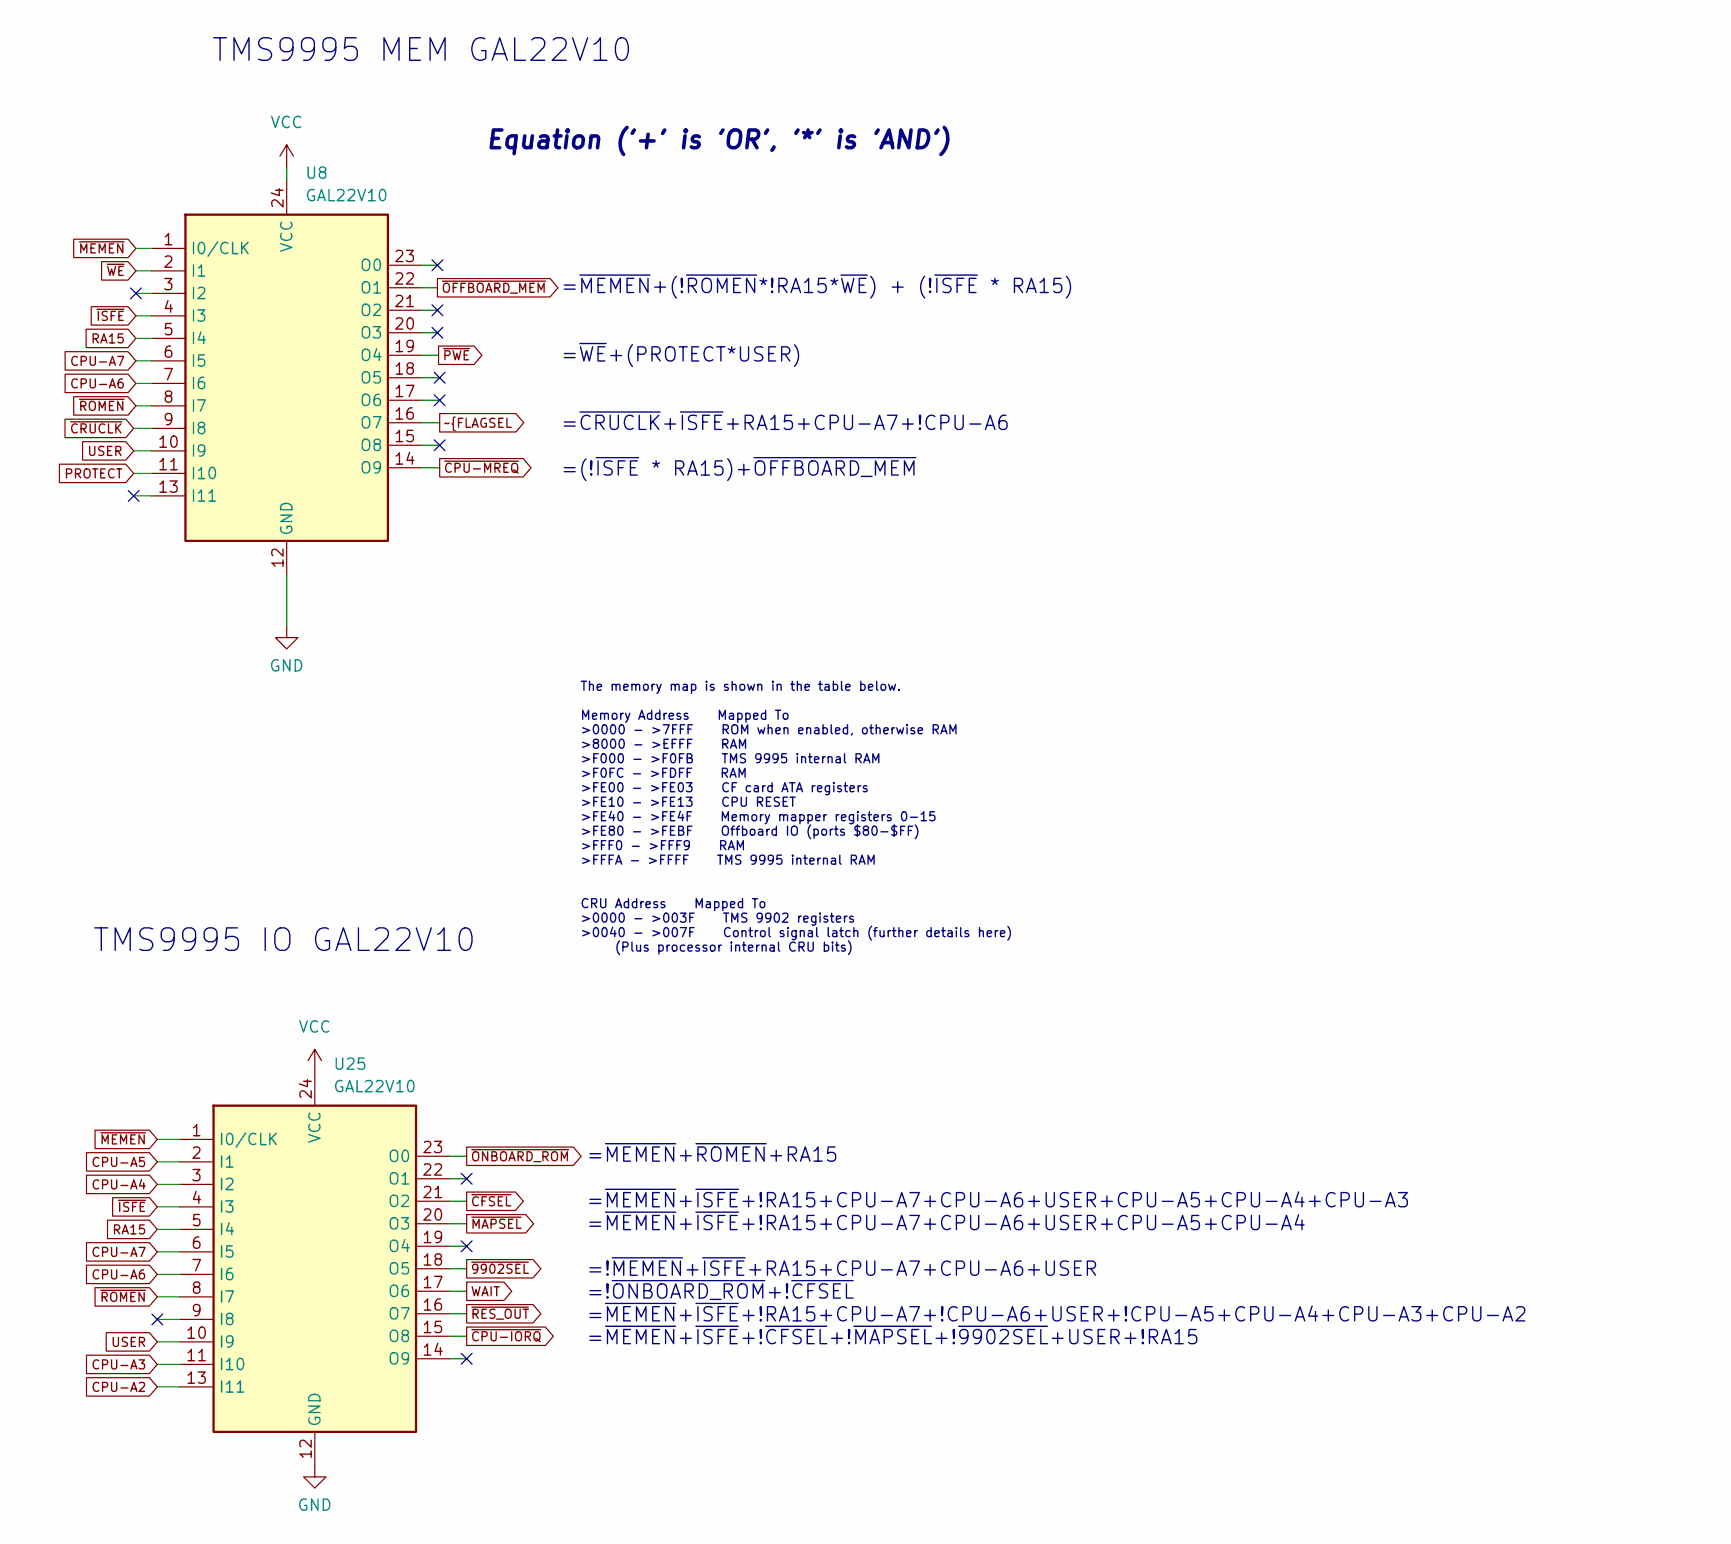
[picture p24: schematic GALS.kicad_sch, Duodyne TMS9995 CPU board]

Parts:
U8, U25: GAL22V10; DIP-24_W7.62mm_Socket_LongPads

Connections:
CPU-A2: U25.13 (I11); also elsewhere on the board
CPU-A3: U25.11 (I10); also elsewhere on the board
CPU-A4: U25.3 (I2); also elsewhere on the board
CPU-A5: U25.2 (I1); also elsewhere on the board
CPU-A6: U8.7 (I6), U25.7 (I6); also elsewhere on the board
CPU-A7: U8.6 (I5), U25.6 (I5); also elsewhere on the board
GND: U8.12 (GND), U25.12 (GND); also elsewhere on the board
PROTECT: U8.11 (I10); also elsewhere on the board
RA15: U8.5 (I4), U25.5 (I4); also elsewhere on the board
USER: U8.10 (I9), U25.10 (I9); also elsewhere on the board
VCC: U8.24 (VCC), U25.24 (VCC); also elsewhere on the board
WAIT: U25.17 (O6); also elsewhere on the board
~9902SEL: U25.18 (O5); also elsewhere on the board
~CFSEL: U25.21 (O2); also elsewhere on the board
~CPU-IORQ: U25.15 (O8); also elsewhere on the board
~CPU-MREQ: U8.14 (O9); also elsewhere on the board
~CRUCLK: U8.9 (I8); also elsewhere on the board
~ISFE: U8.4 (I3), U25.4 (I3); also elsewhere on the board
~MAPSEL: U25.20 (O3); also elsewhere on the board
~MEMEN: U8.1 (I0/CLK), U25.1 (I0/CLK); also elsewhere on the board
~OFFBOARD_MEM: U8.22 (O1); also elsewhere on the board
~ONBOARD_ROM: U25.23 (O0); also elsewhere on the board
~PWE: U8.19 (O4); also elsewhere on the board
~RES_OUT: U25.16 (O7); also elsewhere on the board
~ROMEN: U8.8 (I7), U25.8 (I7); also elsewhere on the board
~WE: U8.2 (I1); also elsewhere on the board

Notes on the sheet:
=~{MEMEN}+(!~{ROMEN}*!RA15*~{WE}) + (!~{ISFE} * RA15) =~{WE}+(PROTECT*USER) =~{CRUCLK}+~{ISFE}+RA15+CPU-A7+!CPU-A6 =(!~{ISFE} * RA15)+~{OFFBOARD_MEM}
Equation ('+' is 'OR', '*' is 'AND')
TMS9995 MEM GAL22V10
The memory map is shown in the table below. Memory Address Mapped To >0000 - >7FFF ROM when enabled, otherwise RAM >8000 - >EFFF RAM >F000 - >F0FB TMS 9995 internal RAM >F0FC - >FDFF RAM >FE00 - >FE03 CF card ATA registers >FE10 - >FE13 CPU RESET >FE40 - >FE4F Memory mapper registers 0-15 >FE80 - >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
TMS9995 IO GAL22V10
=~{MEMEN}+~{ROMEN}+RA15 =~{MEMEN}+~{ISFE}+!RA15+CPU-A7+CPU-A6+USER+CPU-A5+CPU-A4+CPU-A3 =~{MEMEN}+~{ISFE}+!RA15+CPU-A7+CPU-A6+USER+CPU-A5+CPU-A4 =!~{MEMEN}+~{ISFE}+RA15+CPU-A7+CPU-A6+USER =!~{ONBOARD_ROM}+!~{CFSEL} =~{MEMEN}+~{ISFE}+!RA15+CPU-A7+!CPU-A6+USER+!CPU-A5+CPU-A4+CPU-A3+CPU-A2 =~{MEMEN}+~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

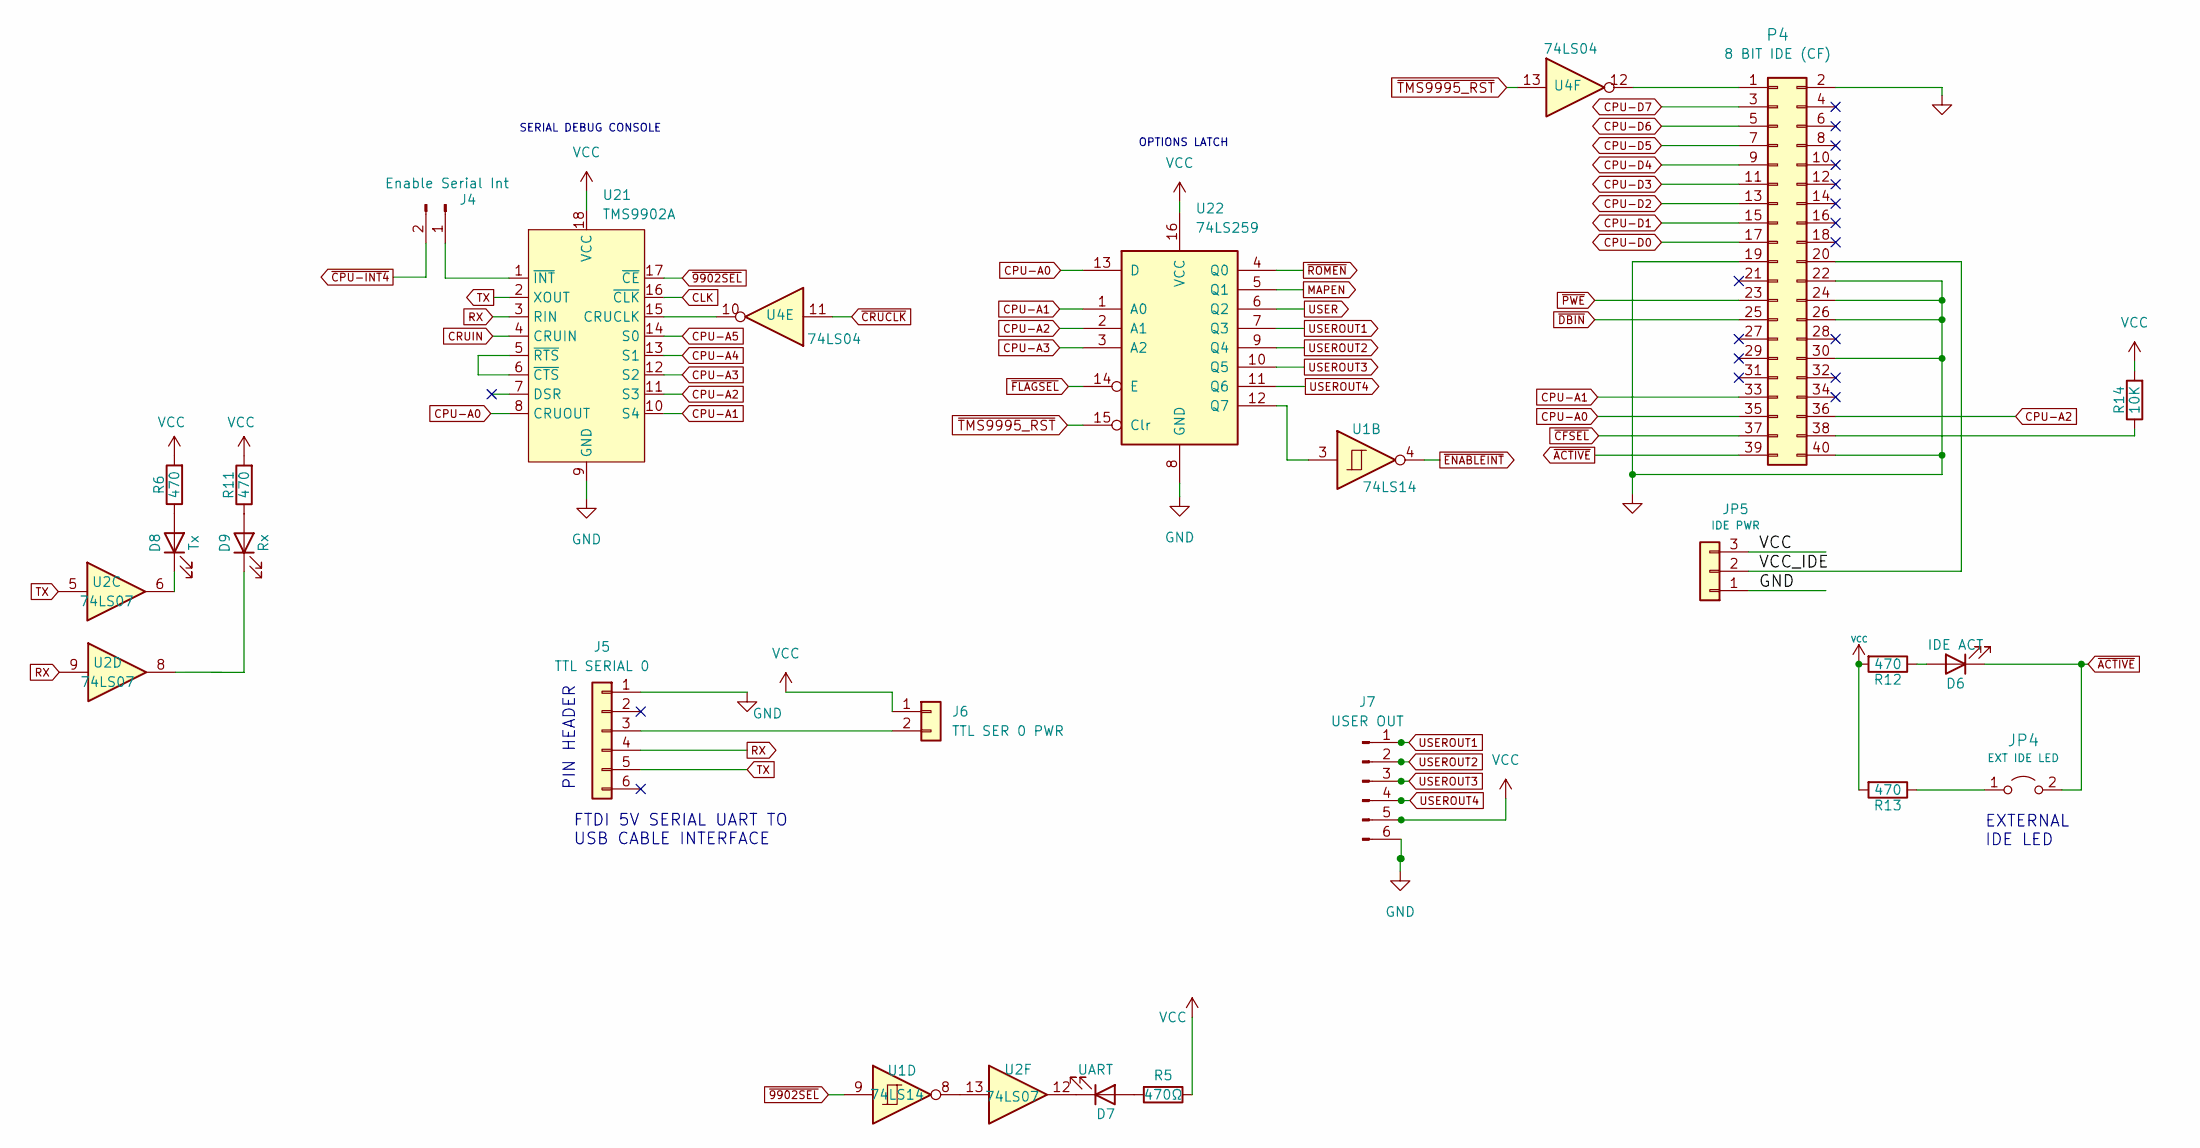
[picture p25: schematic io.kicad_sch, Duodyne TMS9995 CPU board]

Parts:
D6: IDE ACT; LED_D3.0mm_Horizontal_O3.81mm_Z2.0mm
D7: UART; LED_D3.0mm_Horizontal_O3.81mm_Z2.0mm
D8: Tx; LED_D3.0mm
D9: Rx; LED_D3.0mm
J4: Enable Serial Int; PinHeader_1x02_P2.54mm_Vertical
J5: TTL SERIAL 0; PinHeader_1x06_P2.54mm_Horizontal
J6: TTL SER 0 PWR; PinHeader_1x02_P2.54mm_Vertical
J7: USER OUT; PinHeader_1x06_P2.54mm_Horizontal
JP4: EXT IDE LED; PinHeader_1x02_P2.54mm_Vertical
JP5: IDE PWR; PinHeader_1x03_P2.54mm_Vertical
P4: 8 BIT IDE (CF); IDC-Header_2x20_P2.54mm_Horizontal
R5: 470Ω; R_Axial_DIN0207_L6.3mm_D2.5mm_P7.62mm_Horizontal
R6, R11, R12, R13: 470; R_Axial_DIN0207_L6.3mm_D2.5mm_P7.62mm_Horizontal
R14: 10K; R_Axial_DIN0207_L6.3mm_D2.5mm_P7.62mm_Horizontal
U1: 74LS14; DIP-14_W7.62mm_Socket_LongPads
U2: 74LS07; DIP-14_W7.62mm_Socket_LongPads
U4: 74LS04; DIP-14_W7.62mm_Socket_LongPads
U21: TMS9902A; DIP-18_W7.62mm_Socket_LongPads
U22: 74LS259; DIP-16_W7.62mm_Socket_LongPads

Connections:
/IO/VCC_IDE: JP5.2, P4.20
CLK: U21.16 (~CLK); also elsewhere on the board
CPU-A0: P4.35, U21.8 (CRUOUT), U22.13 (D); also elsewhere on the board
CPU-A1: P4.33, U21.10 (S4), U22.1 (A0); also elsewhere on the board
CPU-A2: P4.36, U21.11 (S3), U22.2 (A1); also elsewhere on the board
CPU-A3: U21.12 (S2), U22.3 (A2); also elsewhere on the board
CPU-A4: U21.13 (S1); also elsewhere on the board
CPU-A5: U21.14 (S0); also elsewhere on the board
CPU-D0: P4.17; also elsewhere on the board
CPU-D1: P4.15; also elsewhere on the board
CPU-D2: P4.13; also elsewhere on the board
CPU-D3: P4.11; also elsewhere on the board
CPU-D4: P4.9; also elsewhere on the board
CPU-D5: P4.7; also elsewhere on the board
CPU-D6: P4.5; also elsewhere on the board
CPU-D7: P4.3; also elsewhere on the board
CRUIN: U21.4 (CRUIN); also elsewhere on the board
GND: J5.1, J7.6, JP5.1, P4.2, P4.19, P4.22, P4.24, P4.26, P4.30, P4.40, U21.9 (GND), U22.8 (GND); also elsewhere on the board
MAPEN: U22.5 (Q1); also elsewhere on the board
unnamed: D6.2 (A), R12.1
unnamed: D7.1 (K), U2.12
unnamed: D7.2 (A), R5.2
unnamed: D8.1 (K), U2.6
unnamed: D8.2 (A), R6.1
unnamed: D9.1 (K), U2.8
unnamed: D9.2 (A), R11.1
unnamed: J4.1, U21.1 (~INT)
unnamed: J5.3, J6.2
unnamed: JP4.1 (A), R13.1
unnamed: P4.1, U4.12
unnamed: P4.38, R14.1
unnamed: U1.3, U22.12 (Q7)
unnamed: U1.8, U2.13
unnamed: U21.5 (~RTS), U21.6 (~CTS)
unnamed: U4.10, U21.15 (CRUCLK)
RX: J5.4, U2.9, U21.3 (RIN)
TX: J5.5, U2.5, U21.2 (XOUT)
USER: U22.6 (Q2); also elsewhere on the board
USEROUT1: J7.1, U22.7 (Q3)
USEROUT2: J7.2, U22.9 (Q4)
USEROUT3: J7.3, U22.10 (Q5)
USEROUT4: J7.4, U22.11 (Q6)
VCC: J6.1, J7.5, JP5.3, R5.1, R6.2, R11.2, R12.2, R13.2, R14.2, U21.18 (VCC), U22.16 (VCC); also elsewhere on the board
~9902SEL: U1.9, U21.17 (~CE); also elsewhere on the board
~ACTIVE: D6.1 (K), JP4.2 (B), P4.39
~CFSEL: P4.37; also elsewhere on the board
~CPU-INT4: J4.2; also elsewhere on the board
~CRUCLK: U4.11; also elsewhere on the board
~DBIN: P4.25; also elsewhere on the board
~ENABLEINT: U1.4; also elsewhere on the board
~PWE: P4.23; also elsewhere on the board
~ROMEN: U22.4 (Q0); also elsewhere on the board
~TMS9995_RST: U4.13, U22.15 (Clr); also elsewhere on the board

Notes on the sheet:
PIN HEADER
FTDI 5V SERIAL UART TO USB CABLE INTERFACE
EXTERNAL IDE LED
SERIAL DEBUG CONSOLE
OPTIONS LATCH

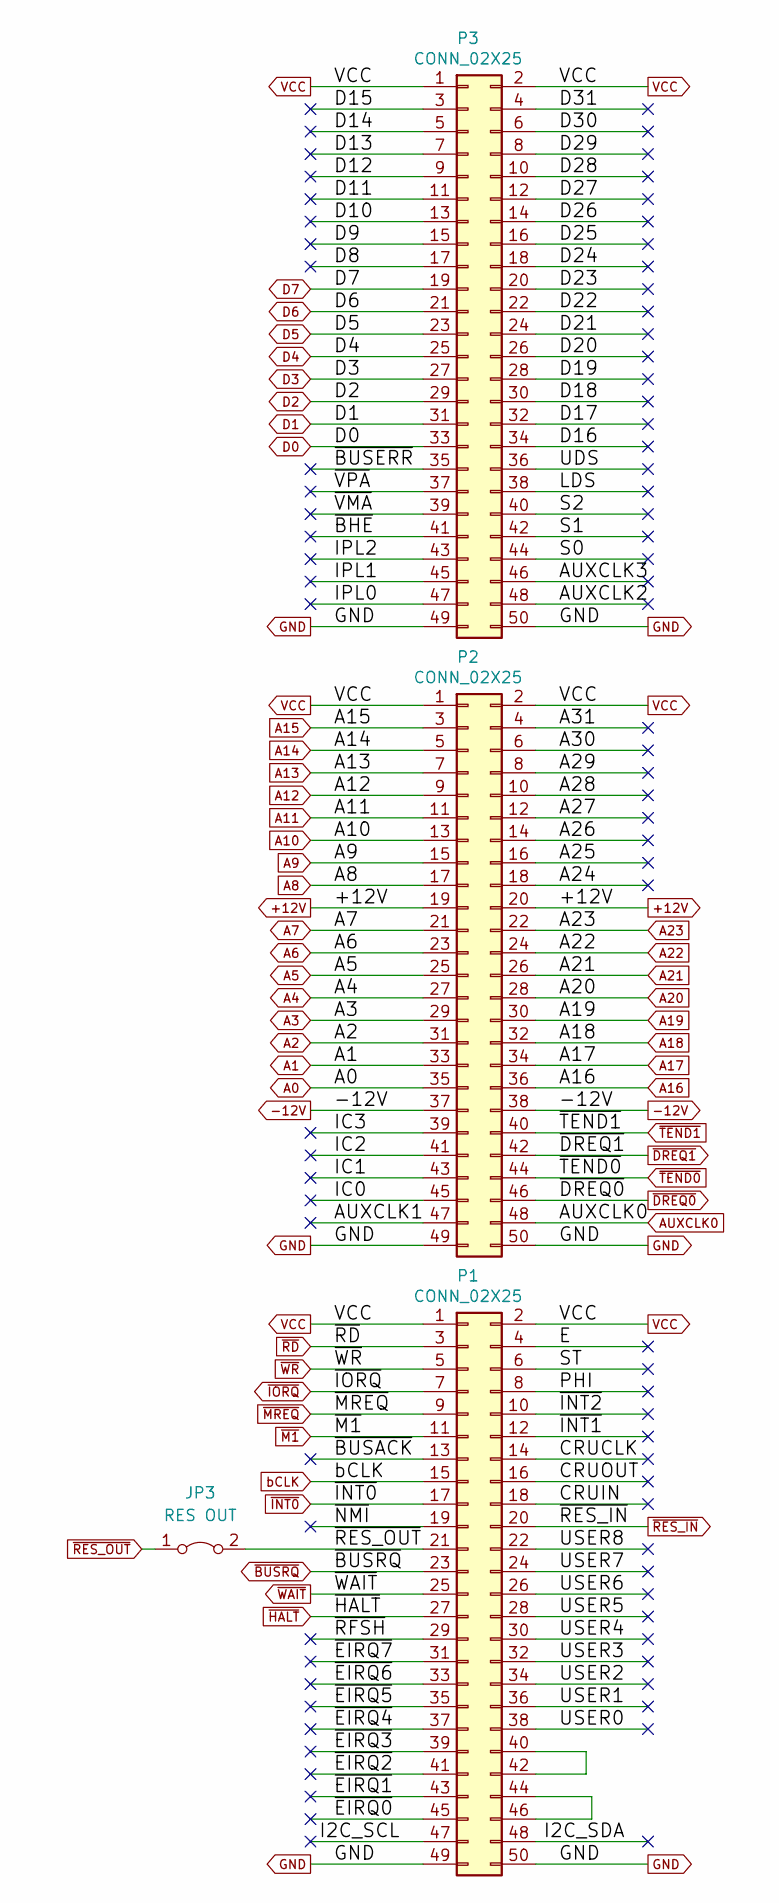
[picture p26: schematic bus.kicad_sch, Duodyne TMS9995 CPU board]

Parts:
JP3: RES OUT; SolderJumper-2_P1.3mm_Bridged_Pad1.0x1.5mm
P1, P2, P3: CONN_02X25; IDC-Header_2x25_P2.54mm_Horizontal

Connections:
+12V: P2.19, P2.20
-12V: P2.37, P2.38
/bus/A24: P2.18
/bus/A25: P2.16
/bus/A26: P2.14
/bus/A27: P2.12
/bus/A28: P2.10
/bus/A29: P2.8
/bus/A30: P2.6
/bus/A31: P2.4
/bus/AUXCLK1: P2.47
/bus/AUXCLK2: P3.48
/bus/AUXCLK3: P3.46
/bus/CRUCLK: P1.14
/bus/CRUIN: P1.18
/bus/CRUOUT: P1.16
/bus/D8: P3.17
/bus/D9: P3.15
/bus/D10: P3.13
/bus/D11: P3.11
/bus/D12: P3.9
/bus/D13: P3.7
/bus/D14: P3.5
/bus/D15: P3.3
/bus/D16: P3.34
/bus/D17: P3.32
/bus/D18: P3.30
/bus/D19: P3.28
/bus/D20: P3.26
/bus/D21: P3.24
/bus/D22: P3.22
/bus/D23: P3.20
/bus/D24: P3.18
/bus/D25: P3.16
/bus/D26: P3.14
/bus/D27: P3.12
/bus/D28: P3.10
/bus/D29: P3.8
/bus/D30: P3.6
/bus/D31: P3.4
/bus/E: P1.4
/bus/I2C_SCL: P1.47
/bus/I2C_SDA: P1.48
/bus/IC0: P2.45
/bus/IC1: P2.43
/bus/IC2: P2.41
/bus/IC3: P2.39
/bus/IPL0: P3.47
/bus/IPL1: P3.45
/bus/IPL2: P3.43
/bus/LDS: P3.38
/bus/PHI: P1.8
/bus/S0: P3.44
/bus/S1: P3.42
/bus/S2: P3.40
/bus/ST: P1.6
/bus/UDS: P3.36
/bus/USER0: P1.38
/bus/USER1: P1.36
/bus/USER2: P1.34
/bus/USER3: P1.32
/bus/USER4: P1.30
/bus/USER5: P1.28
/bus/USER6: P1.26
/bus/USER7: P1.24
/bus/USER8: P1.22
/bus/~BHE: P3.41
/bus/~BUSACK: P1.13
/bus/~BUSERR: P3.35
/bus/~EIRQ0: P1.45
/bus/~EIRQ1: P1.43
/bus/~EIRQ2: P1.41
/bus/~EIRQ3: P1.39
/bus/~EIRQ4: P1.37
/bus/~EIRQ5: P1.35
/bus/~EIRQ6: P1.33
/bus/~EIRQ7: P1.31
/bus/~INT1: P1.12
/bus/~INT2: P1.10
/bus/~NMI: P1.19
/bus/~RFSH: P1.29
/bus/~VMA: P3.39
/bus/~VPA: P3.37
A0: P2.35; also elsewhere on the board
A1: P2.33; also elsewhere on the board
A2: P2.31; also elsewhere on the board
A3: P2.29; also elsewhere on the board
A4: P2.27; also elsewhere on the board
A5: P2.25; also elsewhere on the board
A6: P2.23; also elsewhere on the board
A7: P2.21; also elsewhere on the board
A8: P2.17; also elsewhere on the board
A9: P2.15; also elsewhere on the board
A10: P2.13; also elsewhere on the board
A11: P2.11; also elsewhere on the board
A12: P2.9; also elsewhere on the board
A13: P2.7; also elsewhere on the board
A14: P2.5; also elsewhere on the board
A15: P2.3; also elsewhere on the board
A16: P2.36; also elsewhere on the board
A17: P2.34; also elsewhere on the board
A18: P2.32; also elsewhere on the board
A19: P2.30; also elsewhere on the board
A20: P2.28; also elsewhere on the board
A21: P2.26; also elsewhere on the board
A22: P2.24; also elsewhere on the board
A23: P2.22; also elsewhere on the board
AUXCLK0: P2.48; also elsewhere on the board
D0: P3.33; also elsewhere on the board
D1: P3.31; also elsewhere on the board
D2: P3.29; also elsewhere on the board
D3: P3.27; also elsewhere on the board
D4: P3.25; also elsewhere on the board
D5: P3.23; also elsewhere on the board
D6: P3.21; also elsewhere on the board
D7: P3.19; also elsewhere on the board
GND: P1.49, P1.50, P2.49, P2.50, P3.49, P3.50; also elsewhere on the board
unnamed: P1.40, P1.42
unnamed: P1.44, P1.46
VCC: P1.1, P1.2, P2.1, P2.2, P3.1, P3.2; also elsewhere on the board
bCLK: P1.15; also elsewhere on the board
~BUSRQ: P1.23; also elsewhere on the board
~DREQ0: P2.46; also elsewhere on the board
~DREQ1: P2.42; also elsewhere on the board
~HALT: P1.27; also elsewhere on the board
~INT0: P1.17; also elsewhere on the board
~IORQ: P1.7; also elsewhere on the board
~M1: P1.11; also elsewhere on the board
~MREQ: P1.9; also elsewhere on the board
~RD: P1.3; also elsewhere on the board
~RES_IN: P1.20; also elsewhere on the board
~RES_OUT: JP3.1 (A), JP3.2 (B), P1.21; also elsewhere on the board
~TEND0: P2.44; also elsewhere on the board
~TEND1: P2.40; also elsewhere on the board
~WAIT: P1.25; also elsewhere on the board
~WR: P1.5; also elsewhere on the board

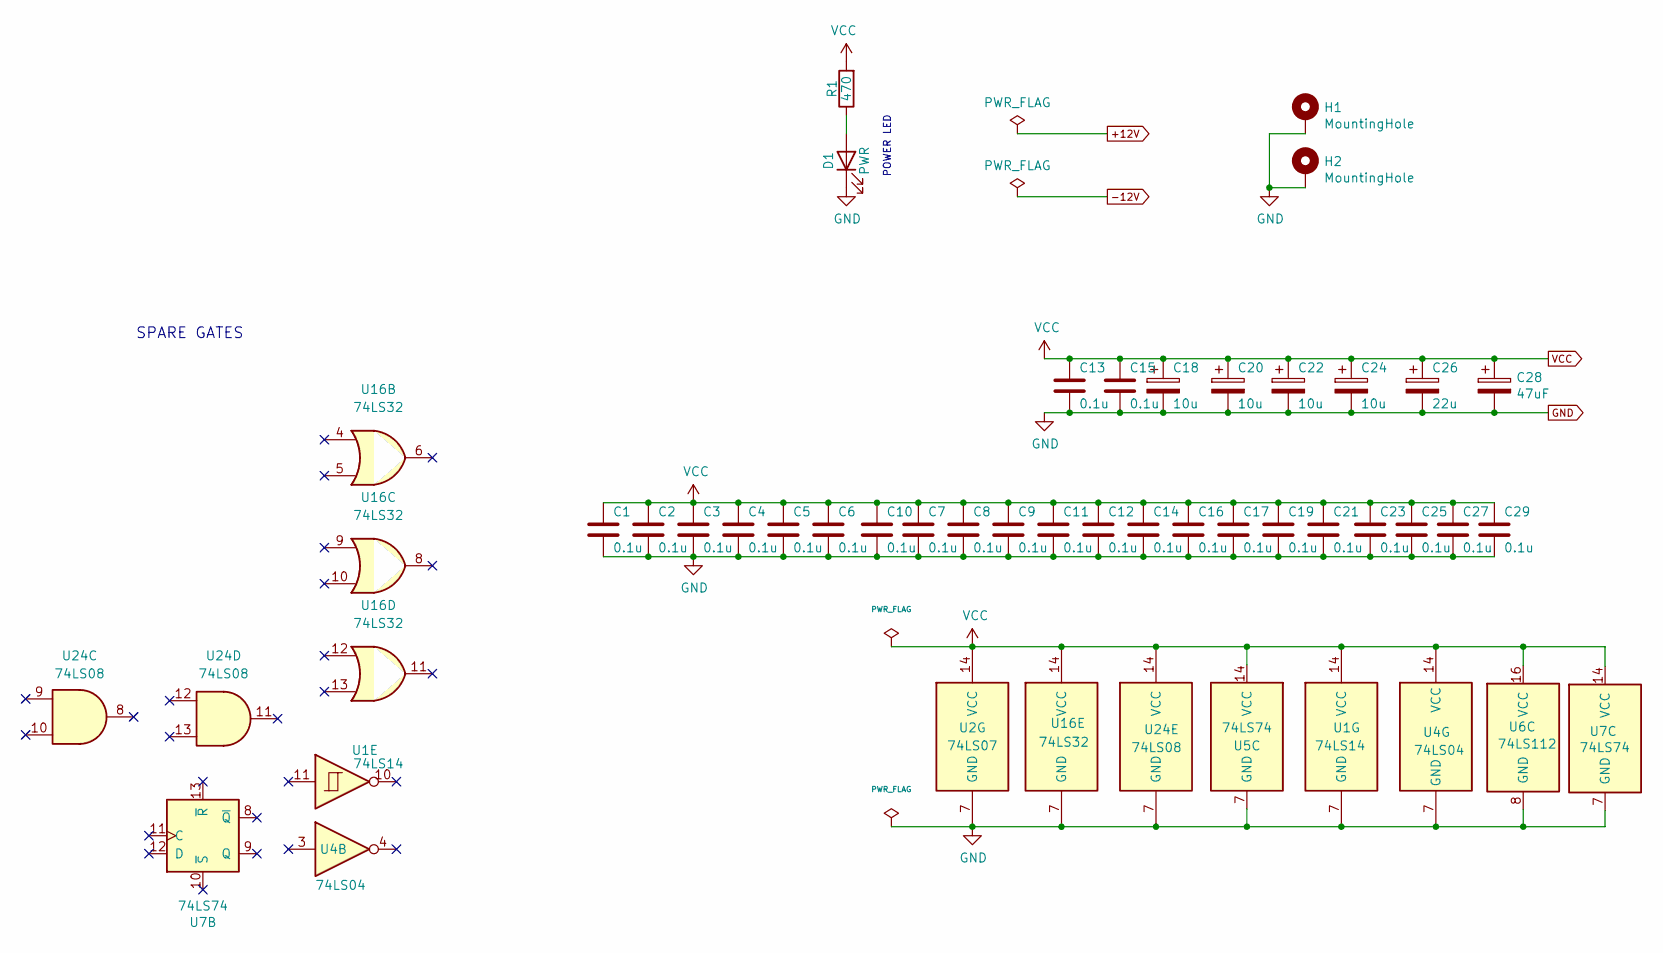
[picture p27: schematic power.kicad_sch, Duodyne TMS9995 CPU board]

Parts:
C1, C2, C3, C4, C5, C6, C7, C8, C9, C10, C11, C12, C13, C14, C15, C16, C17, C19, C21, C23, C25, C27, C29: 0.1u; C_Disc_D5.0mm_W2.5mm_P5.00mm
C18, C20, C22, C24: 10u; CP_Radial_D5.0mm_P2.50mm
C26: 22u; CP_Radial_D5.0mm_P2.50mm
C28: 47uF; CP_Radial_D5.0mm_P2.50mm
D1: PWR; LED_D3.0mm_Horizontal_O3.81mm_Z2.0mm
H1, H2: MountingHole; MountingHole_3.2mm_M3_Pad
R1: 470; R_Axial_DIN0207_L6.3mm_D2.5mm_P7.62mm_Horizontal
U1: 74LS14; DIP-14_W7.62mm_Socket_LongPads
U2: 74LS07; DIP-14_W7.62mm_Socket_LongPads
U4: 74LS04; DIP-14_W7.62mm_Socket_LongPads
U5, U7: 74LS74; DIP-14_W7.62mm_Socket_LongPads
U6: 74LS112; DIP-16_W7.62mm_Socket_LongPads
U16: 74LS32; DIP-14_W7.62mm_Socket_LongPads
U24: 74LS08; DIP-14_W7.62mm_Socket_LongPads

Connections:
GND: C1.2, C2.2, C3.2, C4.2, C5.2, C6.2, C7.2, C8.2, C9.2, C10.2, C11.2, C12.2, C13.2, C14.2, C15.2, C16.2, C17.2, C18.2, C19.2, C20.2, C21.2, C22.2, C23.2, C24.2, C25.2, C26.2, C27.2, C28.2, C29.2, D1.1 (K), H1.1, H2.1, U1.7 (GND), U2.7 (GND), U4.7 (GND), U5.7 (GND), U6.8 (GND), U7.7 (GND), U16.7 (GND), U24.7 (GND); also elsewhere on the board
unnamed: D1.2 (A), R1.1
VCC: C1.1, C2.1, C3.1, C4.1, C5.1, C6.1, C7.1, C8.1, C9.1, C10.1, C11.1, C12.1, C13.1, C14.1, C15.1, C16.1, C17.1, C18.1, C19.1, C20.1, C21.1, C22.1, C23.1, C24.1, C25.1, C26.1, C27.1, C28.1, C29.1, R1.2, U1.14 (VCC), U2.14 (VCC), U4.14 (VCC), U5.14 (VCC), U6.16 (VCC), U7.14 (VCC), U16.14 (VCC), U24.14 (VCC); also elsewhere on the board

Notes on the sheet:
POWER LED
SPARE GATES

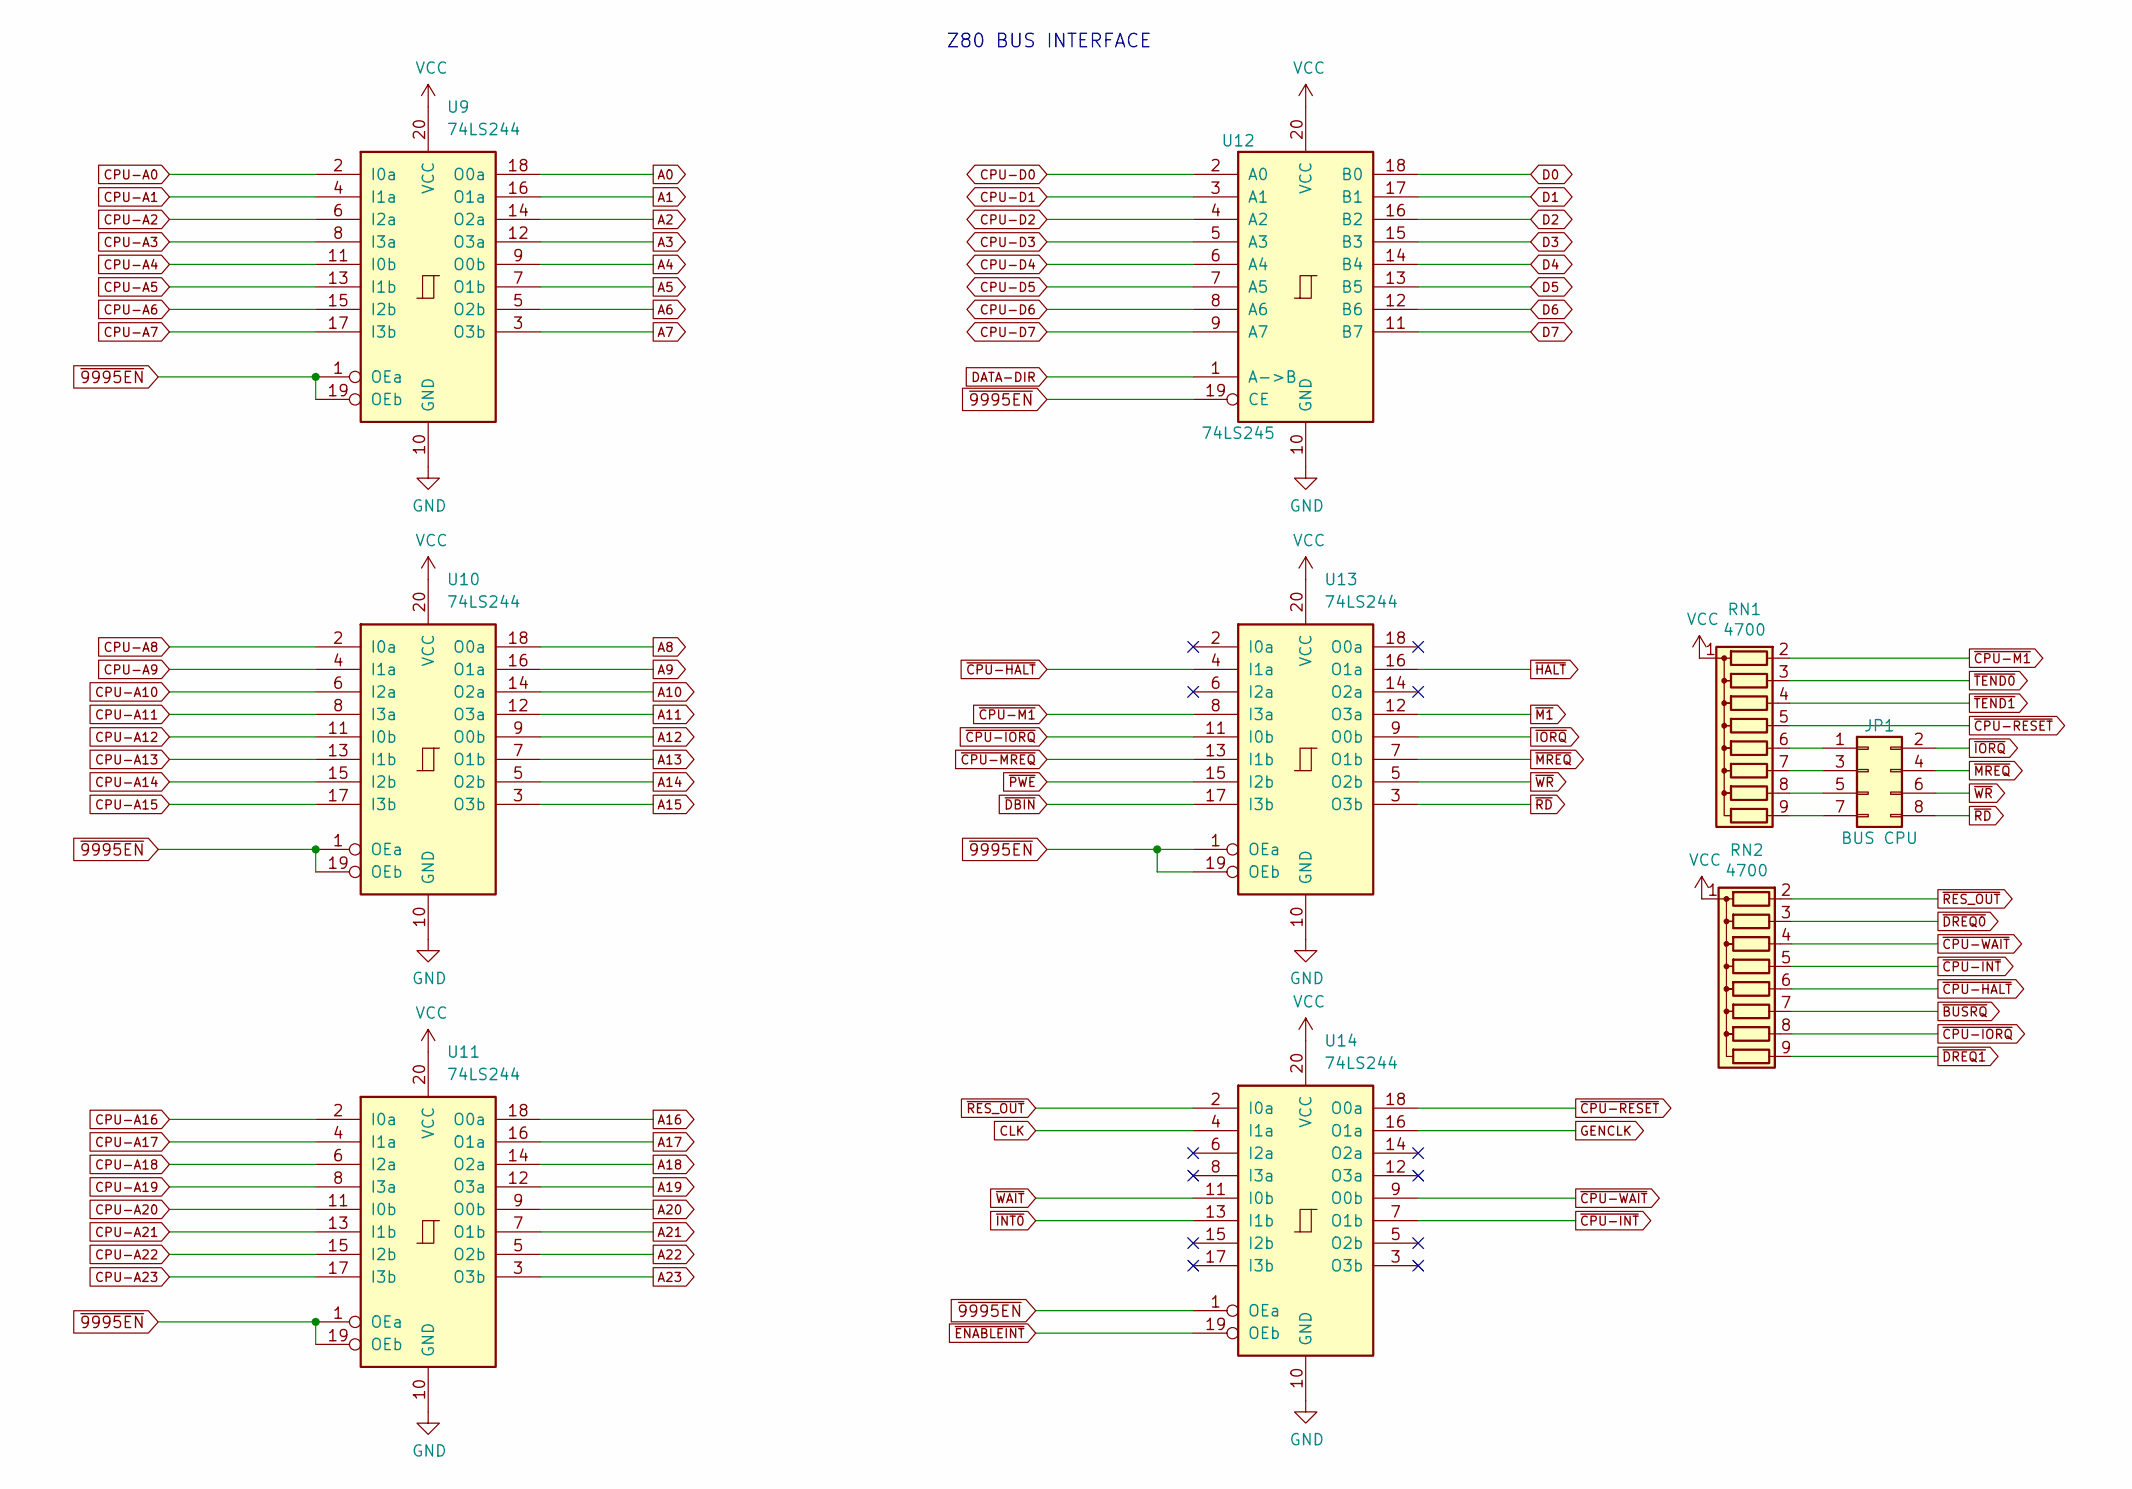
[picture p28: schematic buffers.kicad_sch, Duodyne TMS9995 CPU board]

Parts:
JP1: BUS CPU; PinHeader_2x04_P2.54mm_Vertical
RN1, RN2: 4700; R_Array_SIP9
U9, U10, U11, U13, U14: 74LS244; DIP-20_W7.62mm_Socket_LongPads
U12: 74LS245; DIP-20_W7.62mm_Socket_LongPads

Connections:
A0: U9.18 (O0a); also elsewhere on the board
A1: U9.16 (O1a); also elsewhere on the board
A2: U9.14 (O2a); also elsewhere on the board
A3: U9.12 (O3a); also elsewhere on the board
A4: U9.9 (O0b); also elsewhere on the board
A5: U9.7 (O1b); also elsewhere on the board
A6: U9.5 (O2b); also elsewhere on the board
A7: U9.3 (O3b); also elsewhere on the board
A8: U10.18 (O0a); also elsewhere on the board
A9: U10.16 (O1a); also elsewhere on the board
A10: U10.14 (O2a); also elsewhere on the board
A11: U10.12 (O3a); also elsewhere on the board
A12: U10.9 (O0b); also elsewhere on the board
A13: U10.7 (O1b); also elsewhere on the board
A14: U10.5 (O2b); also elsewhere on the board
A15: U10.3 (O3b); also elsewhere on the board
A16: U11.18 (O0a); also elsewhere on the board
A17: U11.16 (O1a); also elsewhere on the board
A18: U11.14 (O2a); also elsewhere on the board
A19: U11.12 (O3a); also elsewhere on the board
A20: U11.9 (O0b); also elsewhere on the board
A21: U11.7 (O1b); also elsewhere on the board
A22: U11.5 (O2b); also elsewhere on the board
A23: U11.3 (O3b); also elsewhere on the board
CLK: U14.4 (I1a); also elsewhere on the board
CPU-A0: U9.2 (I0a); also elsewhere on the board
CPU-A1: U9.4 (I1a); also elsewhere on the board
CPU-A2: U9.6 (I2a); also elsewhere on the board
CPU-A3: U9.8 (I3a); also elsewhere on the board
CPU-A4: U9.11 (I0b); also elsewhere on the board
CPU-A5: U9.13 (I1b); also elsewhere on the board
CPU-A6: U9.15 (I2b); also elsewhere on the board
CPU-A7: U9.17 (I3b); also elsewhere on the board
CPU-A8: U10.2 (I0a); also elsewhere on the board
CPU-A9: U10.4 (I1a); also elsewhere on the board
CPU-A10: U10.6 (I2a); also elsewhere on the board
CPU-A11: U10.8 (I3a); also elsewhere on the board
CPU-A12: U10.11 (I0b); also elsewhere on the board
CPU-A13: U10.13 (I1b); also elsewhere on the board
CPU-A14: U10.15 (I2b); also elsewhere on the board
CPU-A15: U10.17 (I3b); also elsewhere on the board
CPU-A16: U11.2 (I0a); also elsewhere on the board
CPU-A17: U11.4 (I1a); also elsewhere on the board
CPU-A18: U11.6 (I2a); also elsewhere on the board
CPU-A19: U11.8 (I3a); also elsewhere on the board
CPU-A20: U11.11 (I0b); also elsewhere on the board
CPU-A21: U11.13 (I1b); also elsewhere on the board
CPU-A22: U11.15 (I2b); also elsewhere on the board
CPU-A23: U11.17 (I3b); also elsewhere on the board
CPU-D0: U12.2 (A0); also elsewhere on the board
CPU-D1: U12.3 (A1); also elsewhere on the board
CPU-D2: U12.4 (A2); also elsewhere on the board
CPU-D3: U12.5 (A3); also elsewhere on the board
CPU-D4: U12.6 (A4); also elsewhere on the board
CPU-D5: U12.7 (A5); also elsewhere on the board
CPU-D6: U12.8 (A6); also elsewhere on the board
CPU-D7: U12.9 (A7); also elsewhere on the board
D0: U12.18 (B0); also elsewhere on the board
D1: U12.17 (B1); also elsewhere on the board
D2: U12.16 (B2); also elsewhere on the board
D3: U12.15 (B3); also elsewhere on the board
D4: U12.14 (B4); also elsewhere on the board
D5: U12.13 (B5); also elsewhere on the board
D6: U12.12 (B6); also elsewhere on the board
D7: U12.11 (B7); also elsewhere on the board
DATA-DIR: U12.1 (A->B); also elsewhere on the board
GENCLK: U14.16 (O1a); also elsewhere on the board
GND: U9.10 (GND), U10.10 (GND), U11.10 (GND), U12.10 (GND), U13.10 (GND), U14.10 (GND); also elsewhere on the board
unnamed: JP1.1, RN1.6 (R5)
unnamed: JP1.3, RN1.7 (R6)
unnamed: JP1.5, RN1.8 (R7)
unnamed: JP1.7, RN1.9 (R8)
VCC: RN1.1 (common), RN2.1 (common), U9.20 (VCC), U10.20 (VCC), U11.20 (VCC), U12.20 (VCC), U13.20 (VCC), U14.20 (VCC); also elsewhere on the board
~9995EN: U9.1 (OEa), U9.19 (OEb), U10.1 (OEa), U10.19 (OEb), U11.1 (OEa), U11.19 (OEb), U12.19 (CE), U13.1 (OEa), U13.19 (OEb), U14.1 (OEa); also elsewhere on the board
~BUSRQ: RN2.7 (R6); also elsewhere on the board
~CPU-HALT: RN2.6 (R5), U13.4 (I1a)
~CPU-INT: RN2.5 (R4), U14.7 (O1b); also elsewhere on the board
~CPU-IORQ: RN2.8 (R7), U13.11 (I0b); also elsewhere on the board
~CPU-M1: RN1.2 (R1), U13.8 (I3a)
~CPU-MREQ: U13.13 (I1b); also elsewhere on the board
~CPU-RESET: RN1.5 (R4), U14.18 (O0a)
~CPU-WAIT: RN2.4 (R3), U14.9 (O0b); also elsewhere on the board
~DBIN: U13.17 (I3b); also elsewhere on the board
~DREQ0: RN2.3 (R2); also elsewhere on the board
~DREQ1: RN2.9 (R8); also elsewhere on the board
~ENABLEINT: U14.19 (OEb); also elsewhere on the board
~HALT: U13.16 (O1a); also elsewhere on the board
~INT0: U14.13 (I1b); also elsewhere on the board
~IORQ: JP1.2, U13.9 (O0b); also elsewhere on the board
~M1: U13.12 (O3a); also elsewhere on the board
~MREQ: JP1.4, U13.7 (O1b); also elsewhere on the board
~PWE: U13.15 (I2b); also elsewhere on the board
~RD: JP1.8, U13.3 (O3b); also elsewhere on the board
~RES_OUT: RN2.2 (R1), U14.2 (I0a); also elsewhere on the board
~TEND0: RN1.3 (R2); also elsewhere on the board
~TEND1: RN1.4 (R3); also elsewhere on the board
~WAIT: U14.11 (I0b); also elsewhere on the board
~WR: JP1.6, U13.5 (O2b); also elsewhere on the board

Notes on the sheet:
Z80 BUS INTERFACE

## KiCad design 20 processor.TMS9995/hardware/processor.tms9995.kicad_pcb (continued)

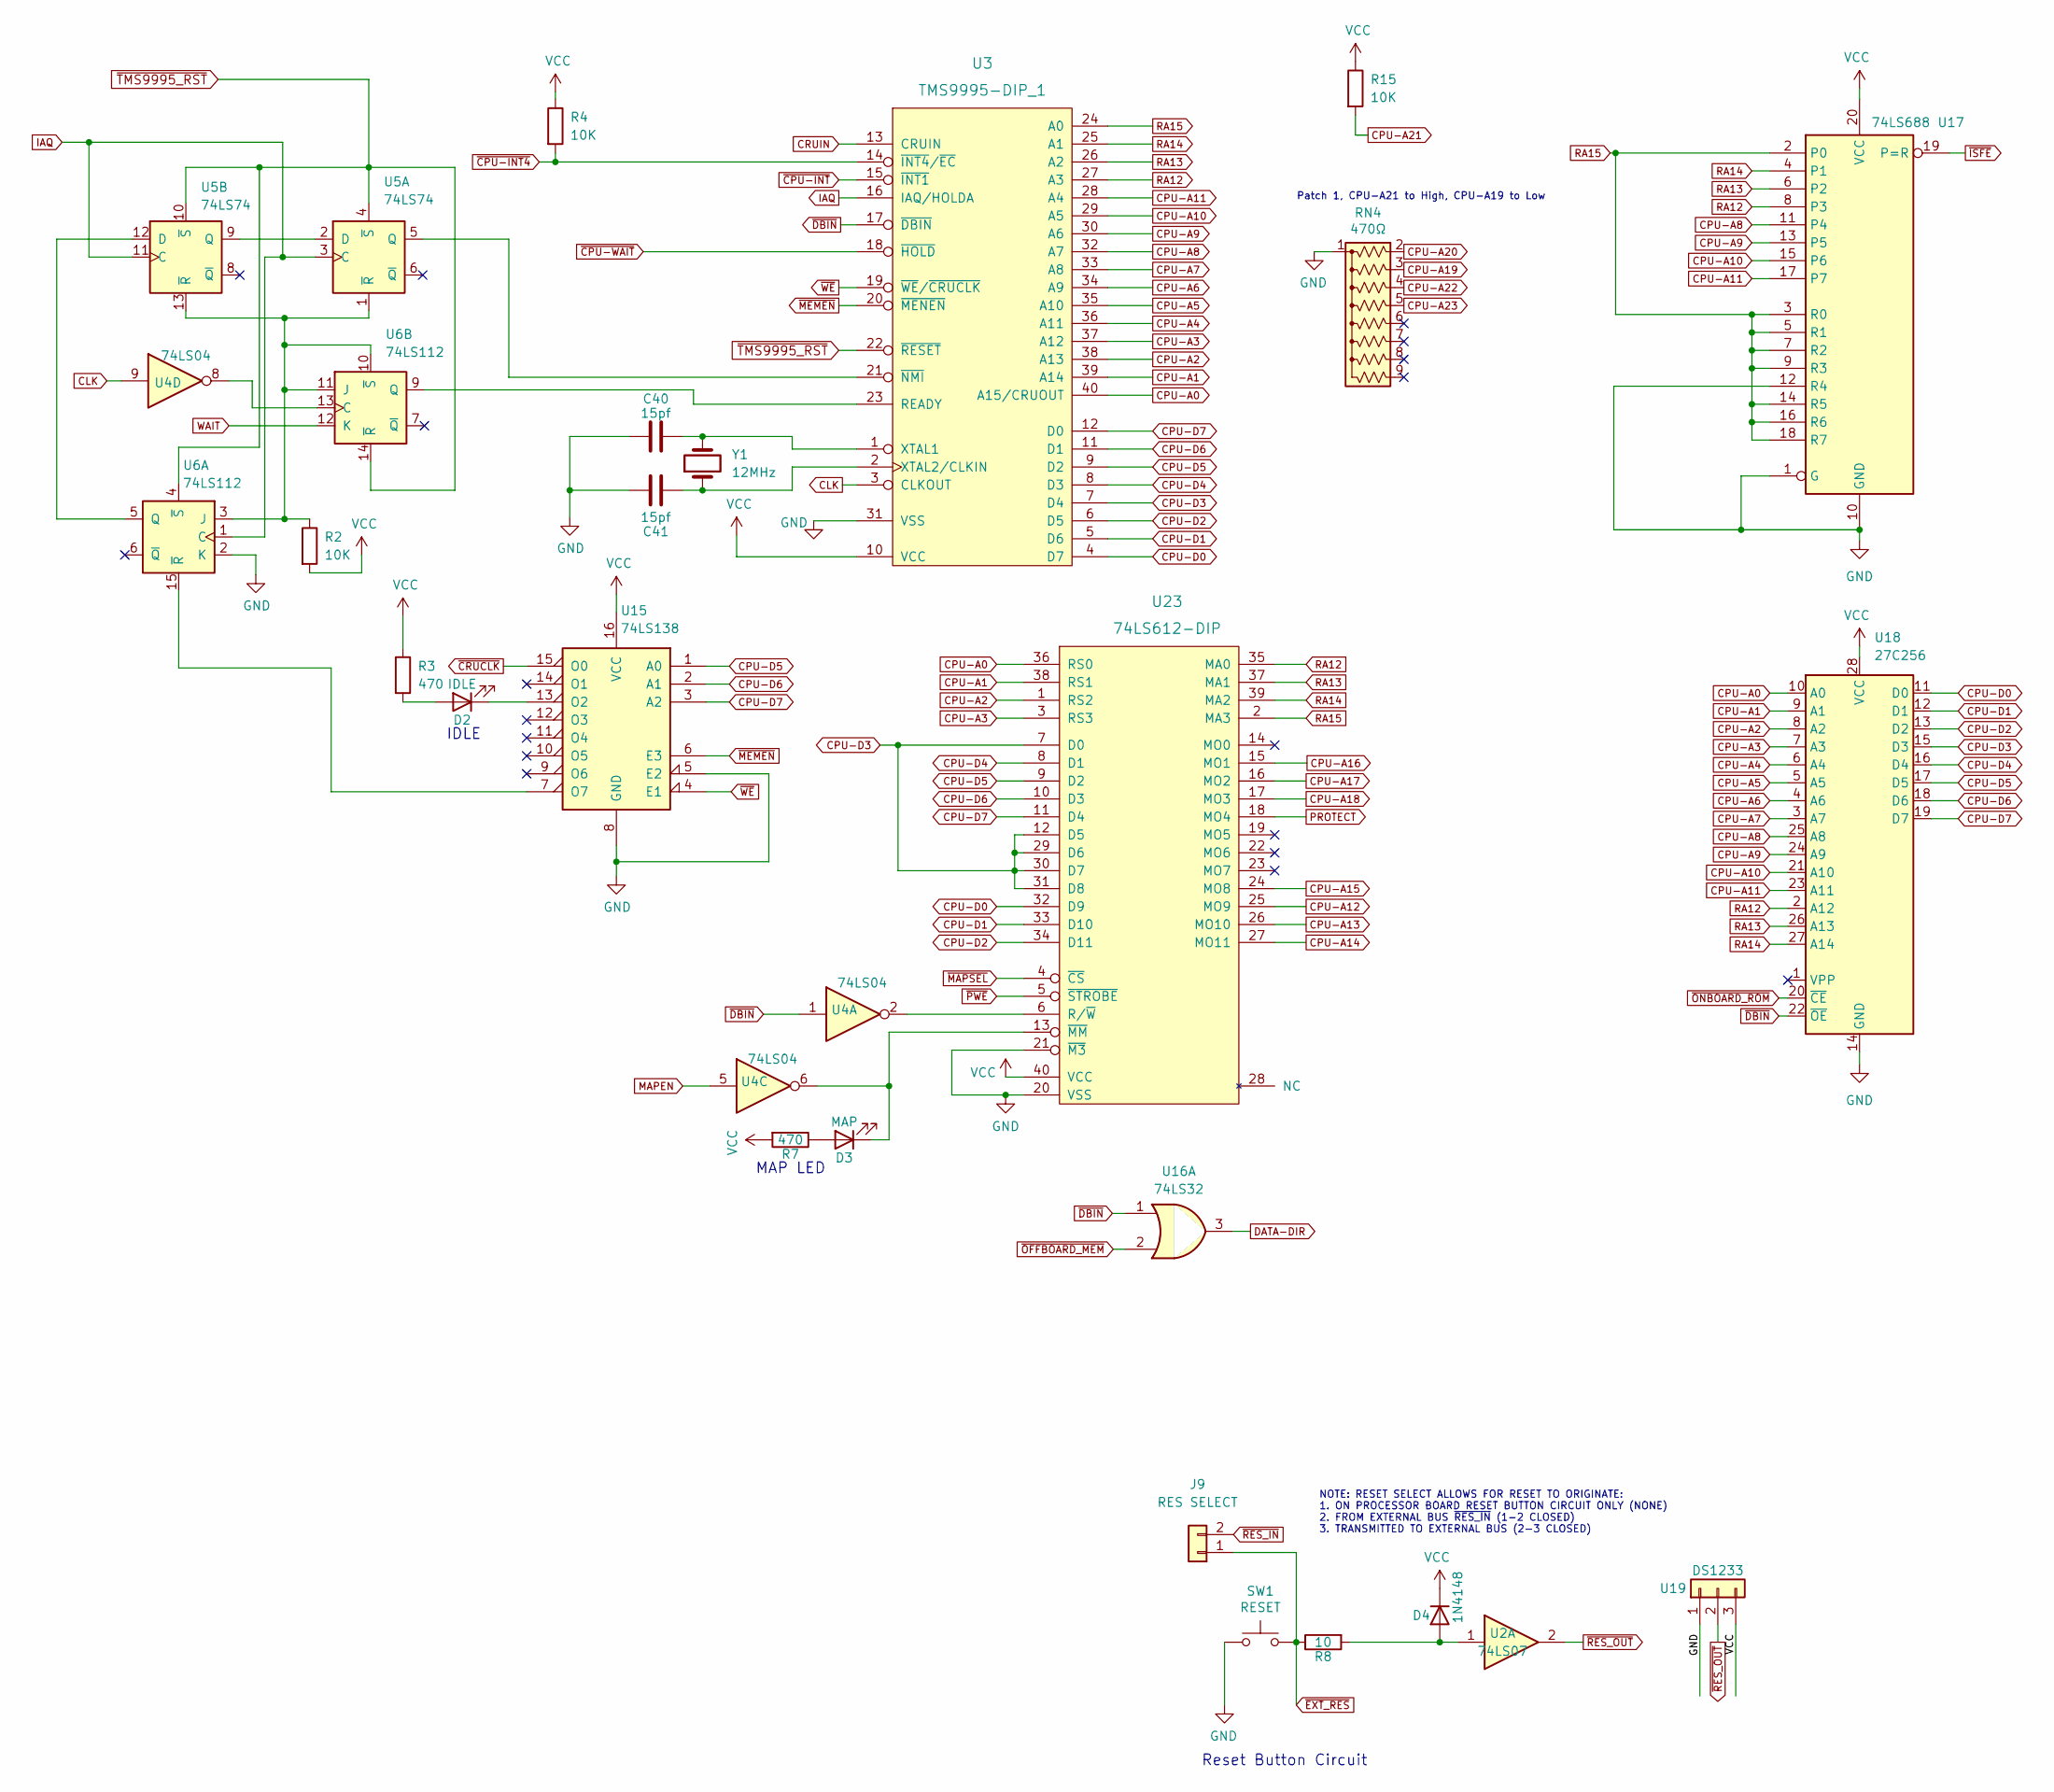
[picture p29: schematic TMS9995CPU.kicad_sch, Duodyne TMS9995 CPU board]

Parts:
C40, C41: 15pf; C_Disc_D5.0mm_W2.5mm_P5.00mm
D2: IDLE; LED_D3.0mm_Horizontal_O3.81mm_Z2.0mm
D3: MAP; LED_D3.0mm_Horizontal_O3.81mm_Z2.0mm
D4: 1N4148; D_DO-35_SOD27_P7.62mm_Horizontal
J9: RES SELECT; PinHeader_1x02_P2.54mm_Vertical
R2, R4, R15: 10K; R_Axial_DIN0207_L6.3mm_D2.5mm_P7.62mm_Horizontal
R3, R7: 470; R_Axial_DIN0207_L6.3mm_D2.5mm_P7.62mm_Horizontal
R8: 10; R_Axial_DIN0207_L6.3mm_D2.5mm_P7.62mm_Horizontal
RN4: 470Ω; R_Array_SIP9
SW1: RESET; SW_Tactile_SPST_Angled_PTS645Vx58-2LFS
U2: 74LS07; DIP-14_W7.62mm_Socket_LongPads
U3: TMS9995-DIP_1; DIP-40_W15.24mm_Socket_LongPads
U4: 74LS04; DIP-14_W7.62mm_Socket_LongPads
U5: 74LS74; DIP-14_W7.62mm_Socket_LongPads
U6: 74LS112; DIP-16_W7.62mm_Socket_LongPads
U15: 74LS138; DIP-16_W7.62mm_Socket_LongPads
U16: 74LS32; DIP-14_W7.62mm_Socket_LongPads
U17: 74LS688; DIP-20_W7.62mm_Socket_LongPads
U18: 27C256; DIP-28_W15.24mm_Socket_LongPads
U19: DS1233; TO-92L_HandSolder
U23: 74LS612-DIP; DIP-40_W15.24mm_Socket_LongPads
Y1: 12MHz; Crystal_HC49-U_Vertical

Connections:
CLK: U3.3 (CLKOUT), U4.9; also elsewhere on the board
CPU-A0: U3.40 (A15/CRUOUT), U18.10 (A0), U23.36 (RS0); also elsewhere on the board
CPU-A1: U3.39 (A14), U18.9 (A1), U23.38 (RS1); also elsewhere on the board
CPU-A2: U3.38 (A13), U18.8 (A2), U23.1 (RS2); also elsewhere on the board
CPU-A3: U3.37 (A12), U18.7 (A3), U23.3 (RS3); also elsewhere on the board
CPU-A4: U3.36 (A11), U18.6 (A4); also elsewhere on the board
CPU-A5: U3.35 (A10), U18.5 (A5); also elsewhere on the board
CPU-A6: U3.34 (A9), U18.4 (A6); also elsewhere on the board
CPU-A7: U3.33 (A8), U18.3 (A7); also elsewhere on the board
CPU-A8: U3.32 (A7), U17.11 (P4), U18.25 (A8); also elsewhere on the board
CPU-A9: U3.30 (A6), U17.13 (P5), U18.24 (A9); also elsewhere on the board
CPU-A10: U3.29 (A5), U17.15 (P6), U18.21 (A10); also elsewhere on the board
CPU-A11: U3.28 (A4), U17.17 (P7), U18.23 (A11); also elsewhere on the board
CPU-A12: U23.25 (MO9); also elsewhere on the board
CPU-A13: U23.26 (MO10); also elsewhere on the board
CPU-A14: U23.27 (MO11); also elsewhere on the board
CPU-A15: U23.24 (MO8); also elsewhere on the board
CPU-A16: U23.15 (MO1); also elsewhere on the board
CPU-A17: U23.16 (MO2); also elsewhere on the board
CPU-A18: U23.17 (MO3); also elsewhere on the board
CPU-A19: RN4.3 (R2); also elsewhere on the board
CPU-A20: RN4.2 (R1); also elsewhere on the board
CPU-A21: R15.2; also elsewhere on the board
CPU-A22: RN4.4 (R3); also elsewhere on the board
CPU-A23: RN4.5 (R4); also elsewhere on the board
CPU-D0: U3.4 (D7), U18.11 (D0), U23.32 (D9); also elsewhere on the board
CPU-D1: U3.5 (D6), U18.12 (D1), U23.33 (D10); also elsewhere on the board
CPU-D2: U3.6 (D5), U18.13 (D2), U23.34 (D11); also elsewhere on the board
CPU-D3: U3.7 (D4), U18.15 (D3), U23.7 (D0), U23.12 (D5), U23.29 (D6), U23.30 (D7), U23.31 (D8); also elsewhere on the board
CPU-D4: U3.8 (D3), U18.16 (D4), U23.8 (D1); also elsewhere on the board
CPU-D5: U3.9 (D2), U15.1 (A0), U18.17 (D5), U23.9 (D2); also elsewhere on the board
CPU-D6: U3.11 (D1), U15.2 (A1), U18.18 (D6), U23.10 (D3); also elsewhere on the board
CPU-D7: U3.12 (D0), U15.3 (A2), U18.19 (D7), U23.11 (D4); also elsewhere on the board
CRUIN: U3.13 (CRUIN); also elsewhere on the board
DATA-DIR: U16.3; also elsewhere on the board
GND: C40.1, C41.1, RN4.1 (common), SW1.2, U3.31 (VSS), U6.2 (K), U15.5 (E2), U15.8 (GND), U17.1 (G), U17.10 (GND), U17.12 (R4), U18.14 (GND), U19.1, U23.20 (VSS), U23.21 (~M3); also elsewhere on the board
IAQ: U3.16 (IAQ/HOLDA), U5.3 (C), U5.11 (C), U6.1 (C)
MAPEN: U4.5; also elsewhere on the board
unnamed: C40.2, U3.1 (XTAL1), Y1.2
unnamed: C41.2, U3.2 (XTAL2/CLKIN), Y1.1
unnamed: D2.1 (K), U15.13 (O2)
unnamed: D2.2 (A), R3.2
unnamed: D3.1 (K), U4.6, U23.13 (~MM)
unnamed: D3.2 (A), R7.1
unnamed: D4.2 (A), R8.2, U2.1
unnamed: R2.1, U5.1 (~R), U5.13 (~R), U6.3 (J), U6.10 (~S), U6.11 (J)
unnamed: U3.21 (~NMI), U5.5 (Q)
unnamed: U3.23 (READY), U6.9 (Q)
unnamed: U4.8, U6.13 (C)
unnamed: U5.2 (D), U5.9 (Q)
unnamed: U5.12 (D), U6.5 (Q)
unnamed: U6.15 (~R), U15.7 (O7)
unnamed: U4.2, U23.6 (R/~W)
PROTECT: U23.18 (MO4); also elsewhere on the board
RA12: U3.27 (A3), U17.8 (P3), U18.2 (A12), U23.35 (MA0)
RA13: U3.26 (A2), U17.6 (P2), U18.26 (A13), U23.37 (MA1)
RA14: U3.25 (A1), U17.4 (P1), U18.27 (A14), U23.39 (MA2)
RA15: U3.24 (A0), U17.2 (P0), U17.3 (R0), U17.5 (R1), U17.7 (R2), U17.9 (R3), U17.14 (R5), U17.16 (R6), U17.18 (R7), U23.2 (MA3); also elsewhere on the board
VCC: D4.1 (K), R2.2, R3.1, R4.1, R7.2, R15.1, U3.10 (VCC), U15.16 (VCC), U17.20 (VCC), U18.28 (VCC), U19.3, U23.40 (VCC); also elsewhere on the board
WAIT: U6.12 (K); also elsewhere on the board
~CPU-INT4: R4.2, U3.14 (~INT4/~EC); also elsewhere on the board
~CPU-INT: U3.15 (~INT1); also elsewhere on the board
~CPU-WAIT: U3.18 (~HOLD); also elsewhere on the board
~CRUCLK: U15.15 (O0); also elsewhere on the board
~DBIN: U3.17 (~DBIN), U4.1, U16.1, U18.22 (~OE); also elsewhere on the board
~EXT_RES: J9.1, R8.1, SW1.1
~ISFE: U17.19 (P=R); also elsewhere on the board
~MAPSEL: U23.4 (~CS); also elsewhere on the board
~MEMEN: U3.20 (~MENEN), U15.6 (E3); also elsewhere on the board
~OFFBOARD_MEM: U16.2; also elsewhere on the board
~ONBOARD_ROM: U18.20 (~CE); also elsewhere on the board
~PWE: U23.5 (~STROBE); also elsewhere on the board
~RES_IN: J9.2; also elsewhere on the board
~RES_OUT: U2.2, U19.2; also elsewhere on the board
~TMS9995_RST: U3.22 (~RESET), U5.4 (~S), U5.10 (~S), U6.4 (~S), U6.14 (~R); also elsewhere on the board
~WE: U3.19 (~WE/~CRUCLK), U15.4 (E1); also elsewhere on the board

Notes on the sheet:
Patch 1, CPU-A21 to High, CPU-A19 to Low
Reset Button Circuit
MAP LED
IDLE
NOTE: RESET SELECT ALLOWS FOR RESET TO ORIGINATE: 1. ON PROCESSOR BOARD RESET BUTTON CIRCUIT ONLY (NONE) 2. FROM EXTERNAL BUS ~{RES_IN} (1-2 CLOSED) 3. TRANSMITTED TO EXTERNAL BUS (2-3 CLOSED)

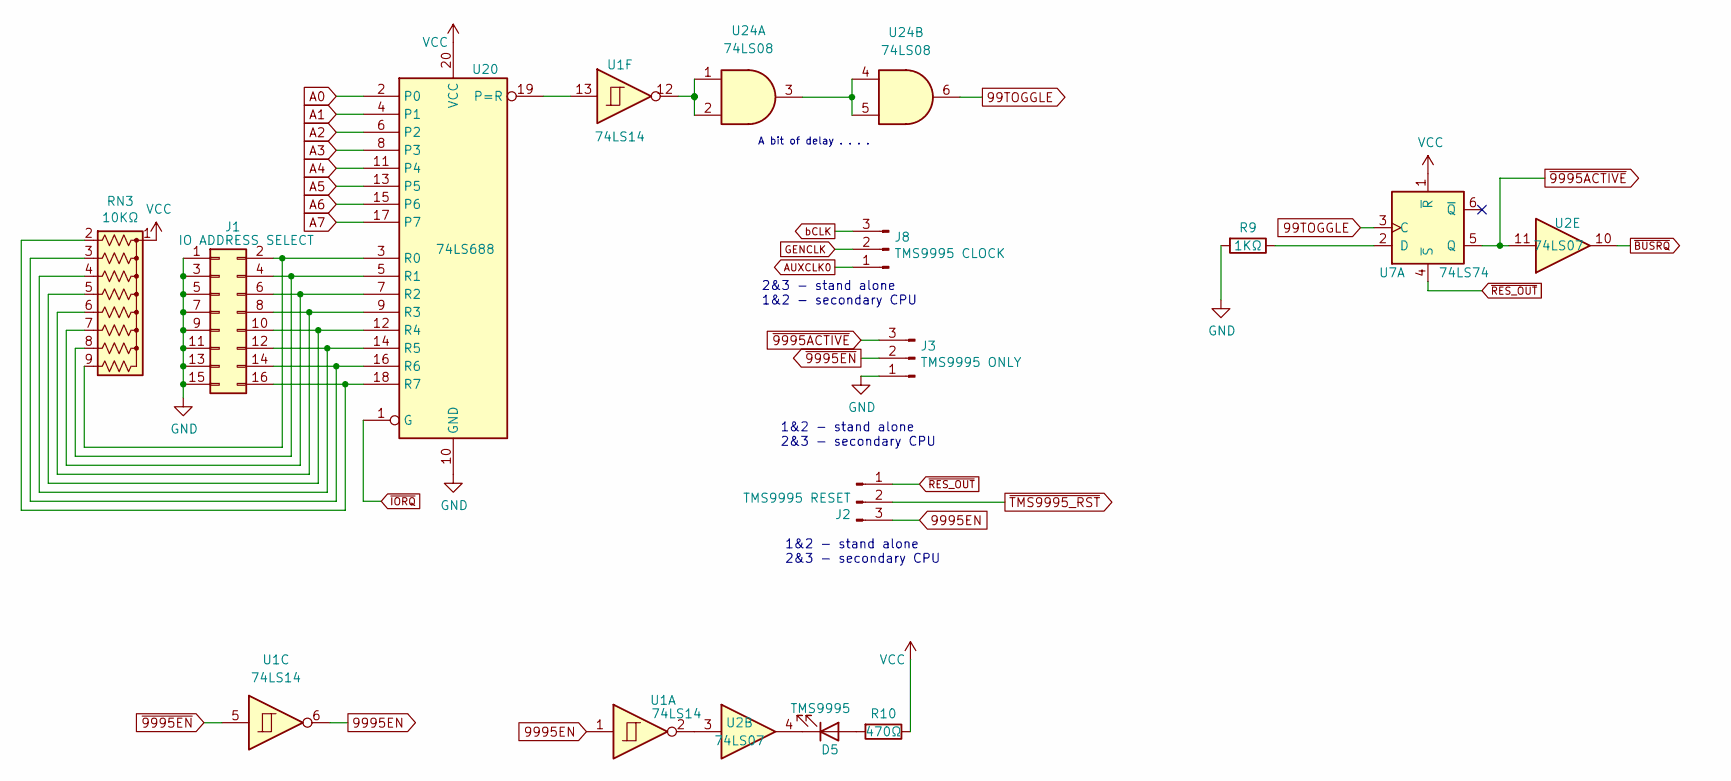
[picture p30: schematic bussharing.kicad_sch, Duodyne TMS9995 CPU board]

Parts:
D5: TMS9995; LED_D3.0mm_Horizontal_O3.81mm_Z2.0mm
J1: IO ADDRESS SELECT; PinHeader_2x08_P2.54mm_Vertical
J2: TMS9995 RESET; PinHeader_1x03_P2.54mm_Horizontal
J3: TMS9995 ONLY; PinHeader_1x03_P2.54mm_Horizontal
J8: TMS9995 CLOCK; PinHeader_1x03_P2.54mm_Horizontal
R9: 1KΩ; R_Axial_DIN0207_L6.3mm_D2.5mm_P7.62mm_Horizontal
R10: 470Ω; R_Axial_DIN0207_L6.3mm_D2.5mm_P7.62mm_Horizontal
RN3: 10KΩ; R_Array_SIP9
U1: 74LS14; DIP-14_W7.62mm_Socket_LongPads
U2: 74LS07; DIP-14_W7.62mm_Socket_LongPads
U7: 74LS74; DIP-14_W7.62mm_Socket_LongPads
U20: 74LS688; DIP-20_W7.62mm_Socket_LongPads
U24: 74LS08; DIP-14_W7.62mm_Socket_LongPads

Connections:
99TOGGLE: U7.3 (C), U24.6
9995EN: J2.3, U1.1, U1.6
A0: U20.2 (P0); also elsewhere on the board
A1: U20.4 (P1); also elsewhere on the board
A2: U20.6 (P2); also elsewhere on the board
A3: U20.8 (P3); also elsewhere on the board
A4: U20.11 (P4); also elsewhere on the board
A5: U20.13 (P5); also elsewhere on the board
A6: U20.15 (P6); also elsewhere on the board
A7: U20.17 (P7); also elsewhere on the board
AUXCLK0: J8.1; also elsewhere on the board
GENCLK: J8.2; also elsewhere on the board
GND: J1.1, J1.3, J1.5, J1.7, J1.9, J1.11, J1.13, J1.15, J3.1, R9.2, U20.10 (GND); also elsewhere on the board
unnamed: D5.1 (K), U2.4
unnamed: D5.2 (A), R10.2
unnamed: J1.2, RN3.9 (R8), U20.3 (R0)
unnamed: J1.4, RN3.8 (R7), U20.5 (R1)
unnamed: J1.6, RN3.7 (R6), U20.7 (R2)
unnamed: J1.8, RN3.6 (R5), U20.9 (R3)
unnamed: J1.10, RN3.5 (R4), U20.12 (R4)
unnamed: J1.12, RN3.4 (R3), U20.14 (R5)
unnamed: J1.14, RN3.3 (R2), U20.16 (R6)
unnamed: J1.16, RN3.2 (R1), U20.18 (R7)
unnamed: U1.2, U2.3
unnamed: U1.12, U24.1, U24.2
unnamed: U1.13, U20.19 (P=R)
unnamed: R9.1, U7.2 (D)
unnamed: U24.3, U24.4, U24.5
VCC: R10.1, RN3.1 (common), U7.1 (~R), U20.20 (VCC); also elsewhere on the board
bCLK: J8.3; also elsewhere on the board
~9995ACTIVE: J3.3, U2.11, U7.5 (Q)
~9995EN: J3.2, U1.5; also elsewhere on the board
~BUSRQ: U2.10; also elsewhere on the board
~IORQ: U20.1 (G); also elsewhere on the board
~RES_OUT: J2.1, U7.4 (~S); also elsewhere on the board
~TMS9995_RST: J2.2; also elsewhere on the board

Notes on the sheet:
1&2 - stand alone 2&3 - secondary CPU
2&3 - stand alone 1&2 - secondary CPU
A bit of delay . . . .

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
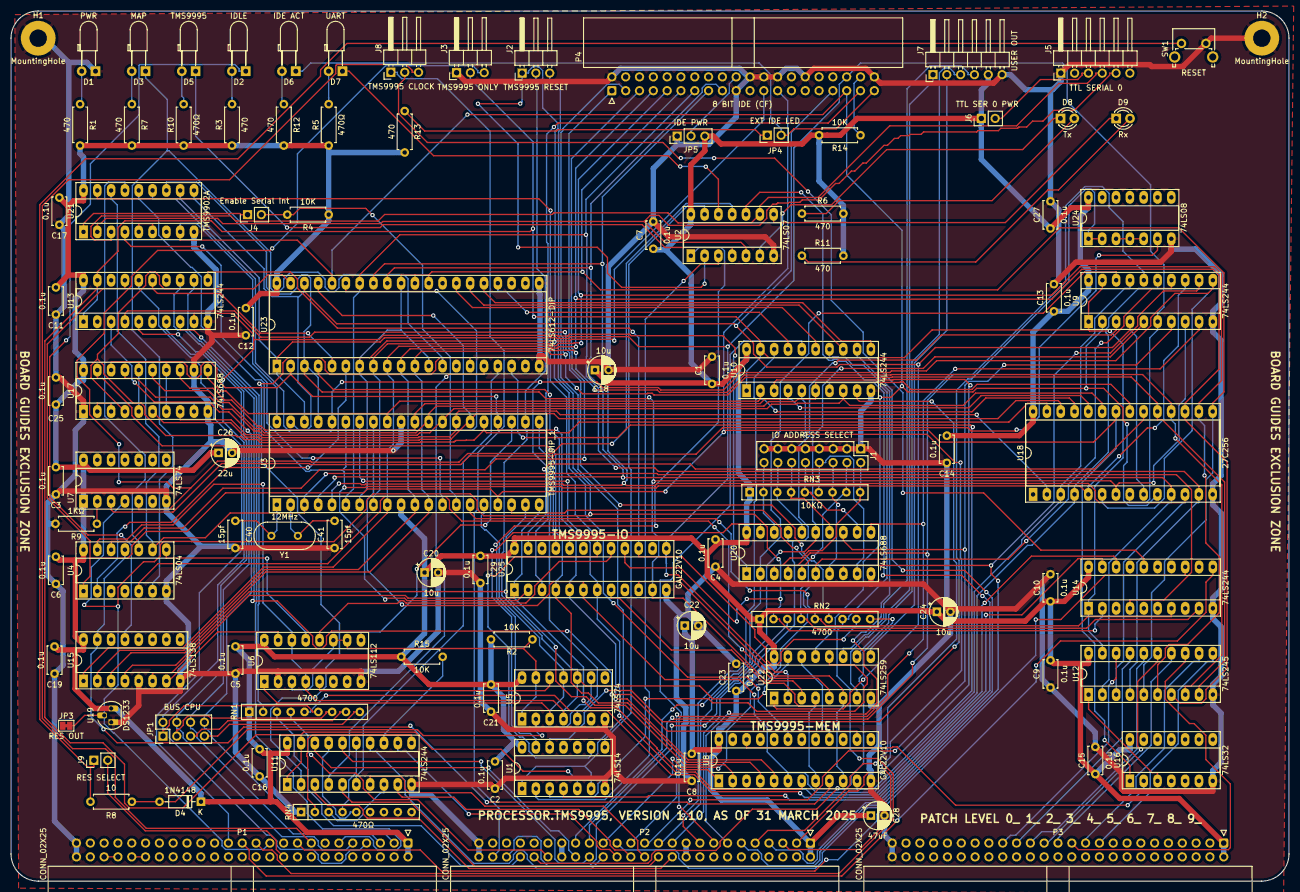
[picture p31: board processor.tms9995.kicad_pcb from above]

Board: 2 copper layers, 235.0 x 160.0 mm, 105 parts (0 on the bottom side), 187 nets.

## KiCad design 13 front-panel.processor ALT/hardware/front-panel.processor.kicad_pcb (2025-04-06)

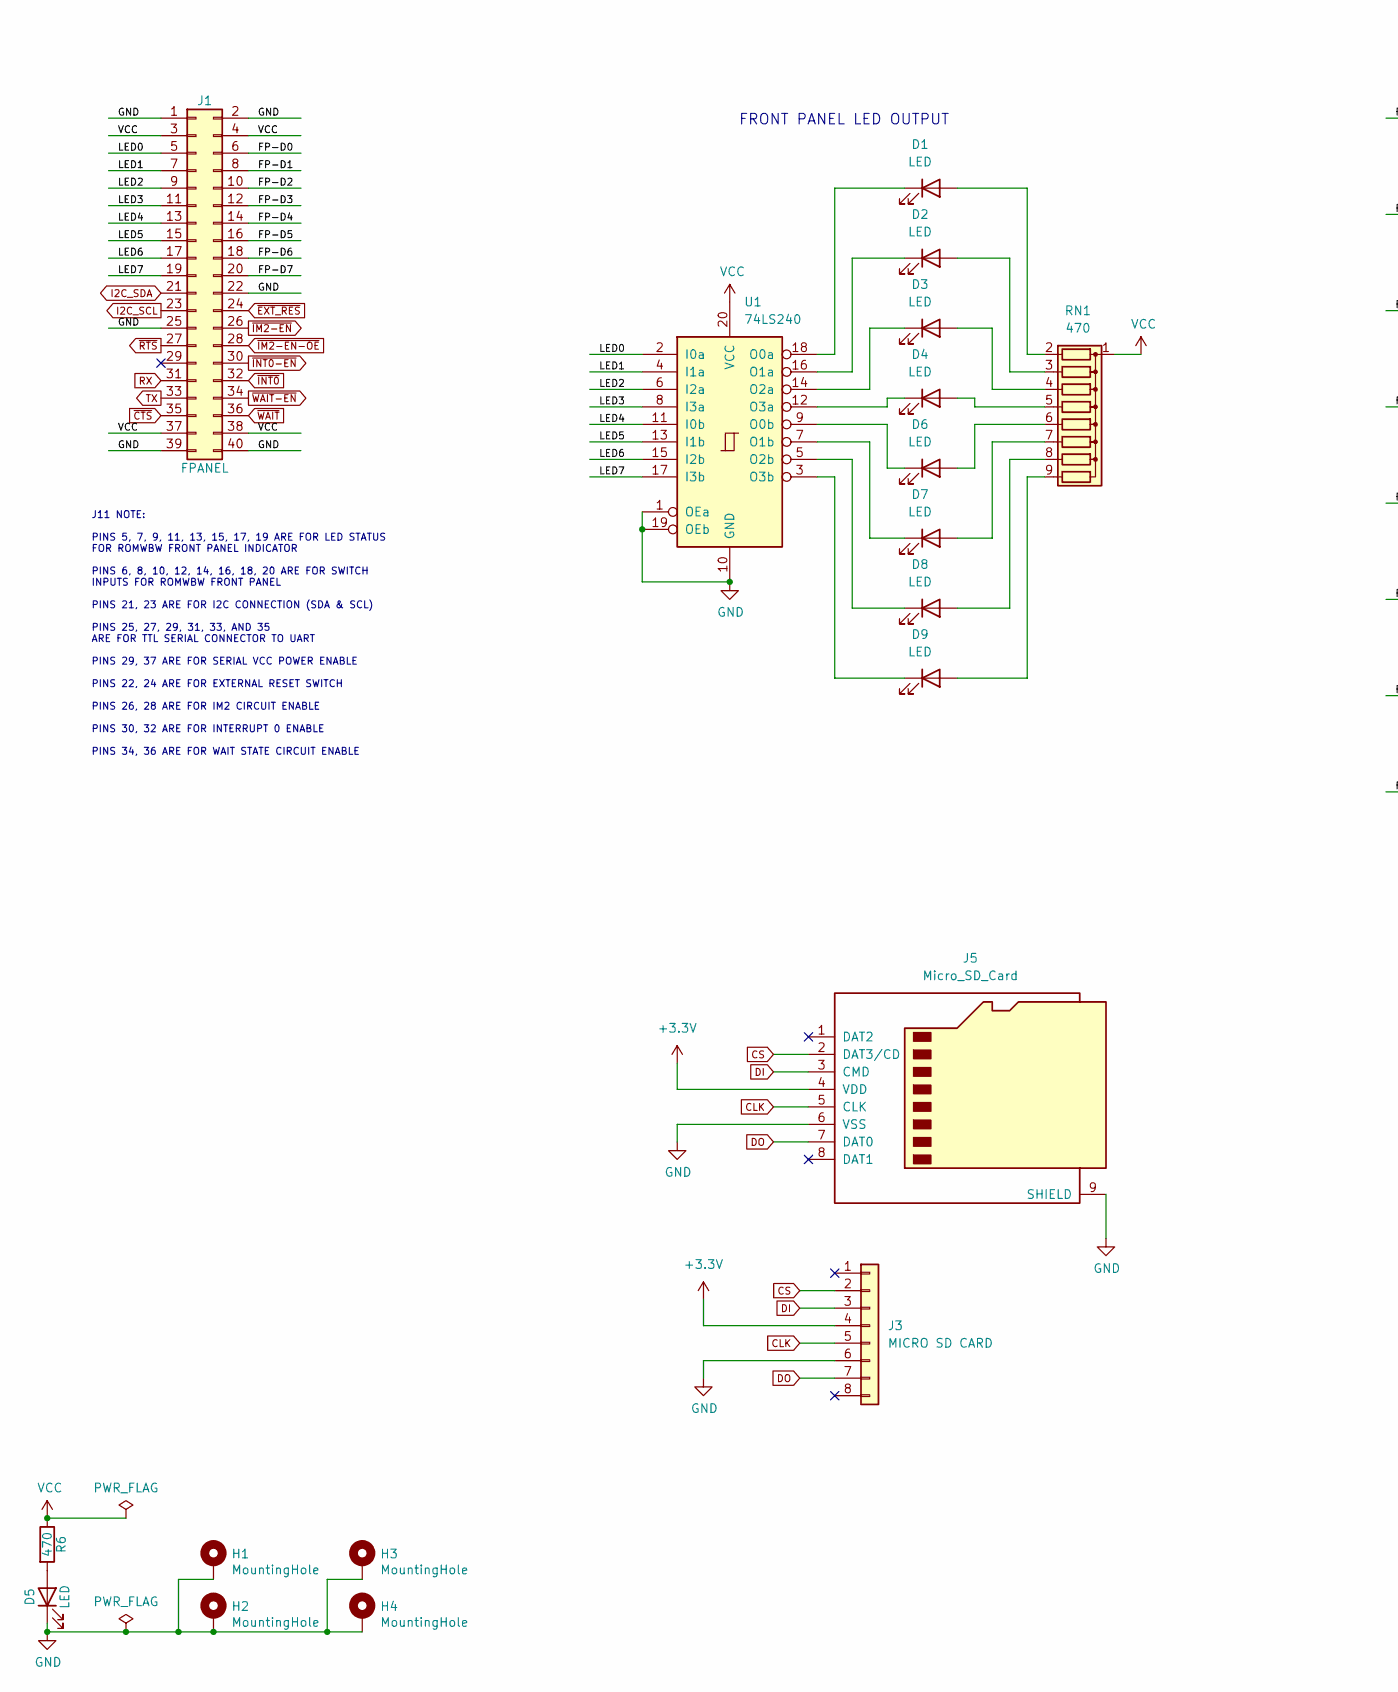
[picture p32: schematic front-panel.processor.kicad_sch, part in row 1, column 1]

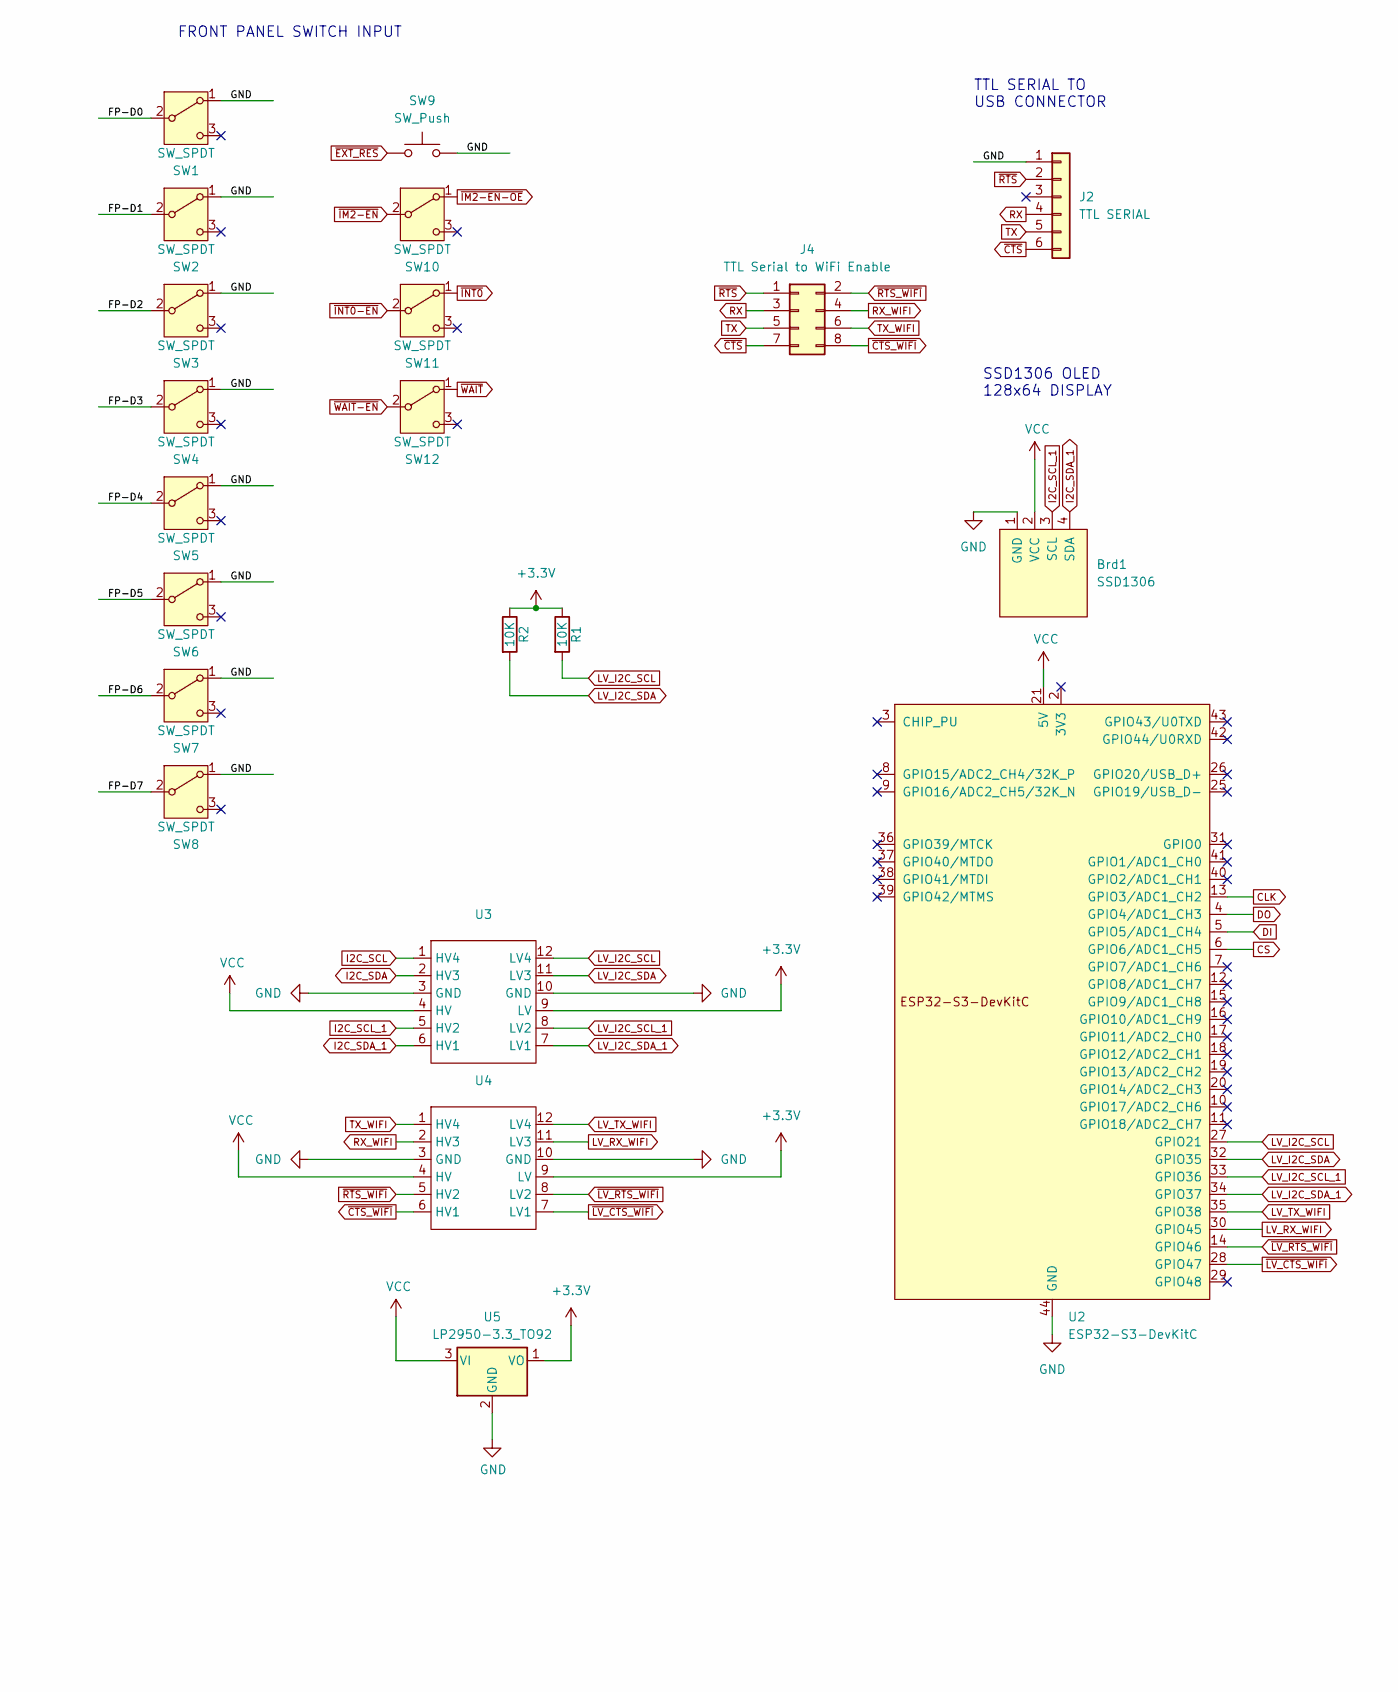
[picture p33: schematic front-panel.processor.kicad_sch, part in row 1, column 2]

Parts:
Brd1: SSD1306; 128x64OLED
D1, D2, D3, D4, D5, D6, D7, D8, D9: LED; LED_D3.0mm
H1, H2, H3, H4: MountingHole; MountingHole_3.2mm_M3_Pad
J1: FPANEL; IDC-Header_2x20_P2.54mm_Horizontal
J2: TTL SERIAL; PinHeader_1x06_P2.54mm_Vertical
J3: MICRO SD CARD; PinSocket_1x08_P2.54mm_Vertical
J4: TTL Serial to WiFi Enable; PinHeader_2x04_P2.54mm_Vertical
J5: Micro_SD_Card; SD_Hirose_DM1AA_SF_PEJ82
R1, R2: 10K; R_Axial_DIN0207_L6.3mm_D2.5mm_P7.62mm_Horizontal
R6: 470; R_Axial_DIN0207_L6.3mm_D2.5mm_P7.62mm_Horizontal
RN1: 470; R_Array_SIP9
SW1, SW2, SW3, SW4, SW5, SW6, SW7, SW8, SW10, SW11, SW12: SW_SPDT; SW_Toggle_Blue_wSlots
SW9: SW_Push; SW_PUSH_6mm
U1: 74LS240; DIP-20_W7.62mm
U2: ESP32-S3-DevKitC; ESP32S3Devkit3Universal
U3, U4: HV-LV
U5: LP2950-3.3_TO92; TO-92_Inline

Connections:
+3.3V: J3.4, J5.4 (VDD), R1.1, R2.1, U3.9 (LV), U4.9 (LV), U5.1 (VO)
/FP-D0: J1.6, SW1.2 (B)
/FP-D1: J1.8, SW2.2 (B)
/FP-D2: J1.10, SW3.2 (B)
/FP-D3: J1.12, SW4.2 (B)
/FP-D4: J1.14, SW5.2 (B)
/FP-D5: J1.16, SW6.2 (B)
/FP-D6: J1.18, SW7.2 (B)
/FP-D7: J1.20, SW8.2 (B)
/LED0: J1.5, U1.2 (I0a)
/LED1: J1.7, U1.4 (I1a)
/LED2: J1.9, U1.6 (I2a)
/LED3: J1.11, U1.8 (I3a)
/LED4: J1.13, U1.11 (I0b)
/LED5: J1.15, U1.13 (I1b)
/LED6: J1.17, U1.15 (I2b)
/LED7: J1.19, U1.17 (I3b)
CLK: J3.5, J5.5 (CLK), U2.13 (GPIO3/ADC1_CH2)
CS: J3.2, J5.2 (DAT3/CD), U2.6 (GPIO6/ADC1_CH5)
DI: J3.3, J5.3 (CMD), U2.5 (GPIO5/ADC1_CH4)
DO: J3.7, J5.7 (DAT0), U2.4 (GPIO4/ADC1_CH3)
GND: Brd1.1 (GND), D5.1 (K), H1.1, H2.1, H3.1, H4.1, J1.1, J1.2, J1.22, J1.25, J1.39, J1.40, J2.1, J3.6, J5.6 (VSS), J5.9 (SHIELD), SW1.1 (A), SW2.1 (A), SW3.1 (A), SW4.1 (A), SW5.1 (A), SW6.1 (A), SW7.1 (A), SW8.1 (A), SW9.2, U1.1 (OEa), U1.10 (GND), U1.19 (OEb), U2.22 (GND), U2.23 (GND), U2.24 (GND), U2.44 (GND), U3.3 (GND), U3.10 (GND), U4.3 (GND), U4.10 (GND), U5.2 (GND)
I2C_SCL: J1.23, U3.1 (HV4)
I2C_SCL_1: Brd1.3 (SCL), U3.5 (HV2)
I2C_SDA: J1.21, U3.2 (HV3)
I2C_SDA_1: Brd1.4 (SDA), U3.6 (HV1)
LV_I2C_SCL: R1.2, U2.27 (GPIO21), U3.12 (LV4)
LV_I2C_SCL_1: U2.33 (GPIO36), U3.8 (LV2)
LV_I2C_SDA: R2.2, U2.32 (GPIO35), U3.11 (LV3)
LV_I2C_SDA_1: U2.34 (GPIO37), U3.7 (LV1)
LV_RX_WIFI: U2.30 (GPIO45), U4.11 (LV3)
LV_TX_WIFI: U2.35 (GPIO38), U4.12 (LV4)
unnamed: D1.2 (A), RN1.2 (R1)
unnamed: D1.1 (K), U1.18 (O0a)
unnamed: D2.2 (A), RN1.3 (R2)
unnamed: D2.1 (K), U1.16 (O1a)
unnamed: D3.2 (A), RN1.4 (R3)
unnamed: D3.1 (K), U1.14 (O2a)
unnamed: D4.2 (A), RN1.5 (R4)
unnamed: D4.1 (K), U1.12 (O3a)
unnamed: D5.2 (A), R6.2
unnamed: D6.2 (A), RN1.6 (R5)
unnamed: D6.1 (K), U1.9 (O0b)
unnamed: D7.2 (A), RN1.7 (R6)
unnamed: D7.1 (K), U1.7 (O1b)
unnamed: D8.2 (A), RN1.8 (R7)
unnamed: D8.1 (K), U1.5 (O2b)
unnamed: D9.2 (A), RN1.9 (R8)
unnamed: D9.1 (K), U1.3 (O3b)
RX: J1.31, J2.4, J4.3
RX_WIFI: J4.4, U4.2 (HV3)
TX: J1.33, J2.5, J4.5
TX_WIFI: J4.6, U4.1 (HV4)
VCC: Brd1.2 (VCC), J1.3, J1.4, J1.37, J1.38, R6.1, RN1.1 (common), U1.20 (VCC), U2.21 (5V), U3.4 (HV), U4.4 (HV), U5.3 (VI)
~CTS_WIFI: J4.8, U4.6 (HV1)
~CTS: J1.35, J2.6, J4.7
~EXT_RES: J1.24, SW9.1
~IM2-EN-OE: J1.28, SW10.1 (A)
~IM2-EN: J1.26, SW10.2 (B)
~INT0-EN: J1.30, SW11.2 (B)
~INT0: J1.32, SW11.1 (A)
~LV_CTS_WIFI: U2.28 (GPIO47), U4.7 (LV1)
~LV_RTS_WIFI: U2.14 (GPIO46), U4.8 (LV2)
~RTS_WIFI: J4.2, U4.5 (HV2)
~RTS: J1.27, J2.2, J4.1
~WAIT-EN: J1.34, SW12.2 (B)
~WAIT: J1.36, SW12.1 (A)

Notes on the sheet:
SSD1306 OLED 128x64 DISPLAY
FRONT PANEL LED OUTPUT
J11 NOTE: PINS 5, 7, 9, 11, 13, 15, 17, 19 ARE FOR LED STATUS FOR ROMWBW FRONT PANEL INDICATOR PINS 6, 8, 10, 12, 14, 16, 18, 20 ARE FOR SWITCH INPUTS FOR ROMWBW FRONT PANEL PINS 21, 23 ARE FOR I2C CONNECTION (SDA & SCL) PINS 25, 27, 29, 31, 33, AND 35 ARE FOR TTL SERIAL CONNECTOR TO UART PINS 29, 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
FRONT PANEL SWITCH INPUT
TTL SERIAL TO USB CONNECTOR

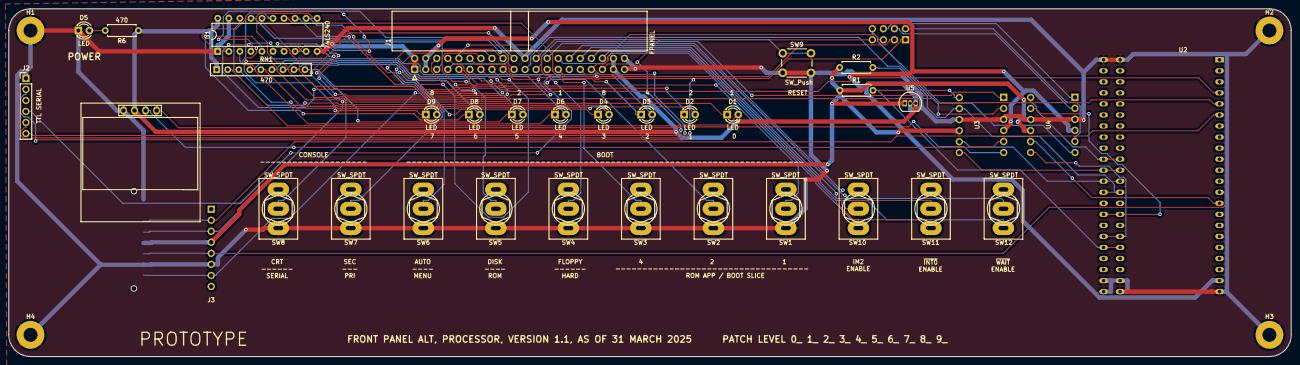
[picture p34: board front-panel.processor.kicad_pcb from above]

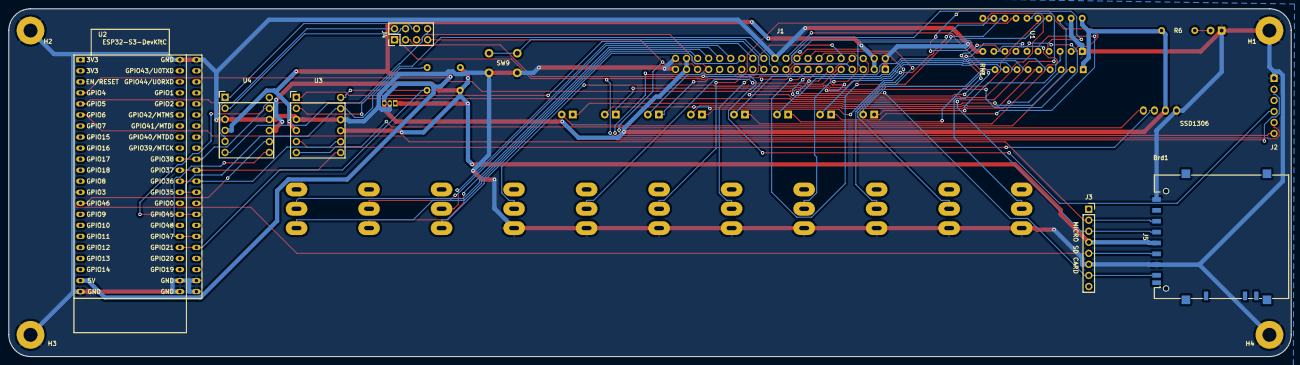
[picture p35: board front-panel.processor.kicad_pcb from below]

Board: 2 copper layers, 295.0 x 80.0 mm, 40 parts (6 on the bottom side), 67 nets.

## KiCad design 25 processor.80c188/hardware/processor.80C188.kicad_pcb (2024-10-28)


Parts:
D8, D9, D10, D11, D12: LED; LED_D3.0mm_Horizontal_O3.81mm_Z2.0mm
J7: I2C IRQ Selection; PinHeader_2x09_P2.54mm_Vertical
J8: UART IRQ Selection; PinHeader_2x09_P2.54mm_Vertical
R2, R3: 10K; R_Axial_DIN0207_L6.3mm_D2.5mm_P7.62mm_Horizontal
RN6: 470; R_Array_SIP5
U1: 74LS04; DIP-14_W7.62mm_Socket_LongPads
U4: 74LS07; DIP-14_W7.62mm_Socket_LongPads
U18: UART CLOCK; DIP-14_W7.62mm_Socket_LongPads
U20: TL16C550CFN; PLCC-44_THT-Socket
U23: 74LS00; DIP-14_W7.62mm_Socket_LongPads
U24: 74LS259; DIP-16_W7.62mm_Socket_LongPads
U25: GAL22V10; DIP-24_W7.62mm_Socket_LongPads
U27: PCF8584; DIP-20_W7.62mm_Socket_LongPads
U28: PCF CLOCK; DIP-14_W7.62mm_Socket_LongPads

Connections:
470E: D9.2 (A); also elsewhere on the board
ALE: U25.1 (I0/CLK); also elsewhere on the board
CPU-A0: U20.31 (A0), U24.1 (A0), U27.6 (A0); also elsewhere on the board
CPU-A1: U20.30 (A1), U24.2 (A1); also elsewhere on the board
CPU-A2: U20.29 (A2), U24.3 (A2); also elsewhere on the board
CPU-A3: U25.23 (O0); also elsewhere on the board
CPU-A4: U25.7 (I6); also elsewhere on the board
CPU-A5: U25.6 (I5); also elsewhere on the board
CPU-A6: U25.5 (I4); also elsewhere on the board
CPU-D0: U20.2 (D0), U24.13 (D), U27.7 (D0); also elsewhere on the board
CPU-D1: U20.3 (D1), U27.8 (D1); also elsewhere on the board
CPU-D2: U20.4 (D2), U27.9 (D2); also elsewhere on the board
CPU-D3: U20.5 (D3), U27.11 (D3); also elsewhere on the board
CPU-D4: U20.6 (D4), U27.12 (D4); also elsewhere on the board
CPU-D5: U20.7 (D5), U27.13 (D5); also elsewhere on the board
CPU-D6: U20.8 (D6), U27.14 (D6); also elsewhere on the board
CPU-D7: U20.9 (D7), U27.15 (D7); also elsewhere on the board
CPU-INT0: J7.1, J8.1; also elsewhere on the board
EIRQ0: J7.3, J8.3; also elsewhere on the board
EIRQ1: J7.5, J8.5; also elsewhere on the board
EIRQ2: J7.7, J8.7; also elsewhere on the board
EIRQ3: J7.9, J8.9; also elsewhere on the board
EIRQ4: J7.11, J8.11; also elsewhere on the board
EIRQ5: J7.13, J8.13; also elsewhere on the board
EIRQ6: J7.15, J8.15; also elsewhere on the board
EIRQ7: J7.17, J8.17; also elsewhere on the board
FP-LATCH-WR: U25.19 (O4); also elsewhere on the board
GND: U18.4, U18.7, U20.22 (GND), U24.8 (GND), U25.12 (GND), U27.10 (VSS), U28.4, U28.7; also elsewhere on the board
I2C_SCL: R2.1, U27.3 (SCL); also elsewhere on the board
I2C_SDA: R3.1, U27.2 (SDA); also elsewhere on the board
unnamed: D8.1 (K), U24.4 (Q0)
unnamed: D8.2 (A), RN6.2 (R1)
unnamed: D9.1 (K), U4.4
unnamed: D10.1 (K), U24.5 (Q1)
unnamed: D10.2 (A), RN6.3 (R2)
unnamed: D11.1 (K), U24.6 (Q2)
unnamed: D11.2 (A), RN6.4 (R3)
unnamed: D12.1 (K), U24.7 (Q3)
unnamed: D12.2 (A), RN6.5 (R4)
unnamed: J7.2, J7.4, J7.6, J7.8, J7.10, J7.12, J7.14, J7.16, J7.18, U23.8
unnamed: U1.8, U20.39 (MR)
unnamed: U20.10 (RCLK), U20.17 (~BAUDOUT)
unnamed: U23.13, U24.9 (Q4)
unnamed: U25.11 (I10), U25.22 (O1)
unnamed: U27.1 (CLK), U28.8, U28.11
ONE: U20.14 (CS0), U20.15 (CS1), U20.43 (~RI); also elsewhere on the board
RX: U20.11 (SIN); also elsewhere on the board
S2: U25.10 (I9); also elsewhere on the board
TMR1_IN: U23.11; also elsewhere on the board
TX: U20.13 (SOUT); also elsewhere on the board
UART-CLK: U18.8, U18.11, U20.18 (XIN), U23.12
UART_INT: J8.2, J8.4, J8.6, J8.8, J8.10, J8.12, J8.14, J8.16, J8.18, U20.33 (INTR)
VCC: R2.2, R3.2, RN6.1 (common), U18.1, U18.14, U20.44 (VCC), U24.16 (VCC), U25.24 (VCC), U27.20 (VDD), U28.1, U28.14; also elsewhere on the board
ZERO: U20.21 (WR), U20.25 (RD), U20.28 (~ADS), U20.41 (~DSR), U20.42 (~DCD); also elsewhere on the board
~CPU-RD: U20.24 (~RD), U25.9 (I8), U27.16 (~RD); also elsewhere on the board
~CPU-WR: U20.20 (~WR), U25.8 (I7); also elsewhere on the board
~CS_I2C_WR: U25.15 (O8), U27.18 (~WR)
~CS_I2C: U25.16 (O7), U27.17 (~CS)
~CS_PIC: U25.21 (O2); also elsewhere on the board
~CS_UART: U4.3, U20.16 (~CS2), U25.17 (O6)
~CTS: U20.40 (~CTS); also elsewhere on the board
~FP-LATCH-RD: U25.20 (O3); also elsewhere on the board
~INT-I2C: U23.9, U23.10, U27.5 (~INT)
~PCS4: U25.2 (I1); also elsewhere on the board
~PCS5: U25.3 (I2); also elsewhere on the board
~PCS6: U25.4 (I3); also elsewhere on the board
~RES_OUT: U1.9, U24.15 (Clr), U25.18 (O5), U27.19 (~RST); also elsewhere on the board
~RTS: U20.36 (~RTS); also elsewhere on the board
~WR_LS259: U24.14 (E), U25.14 (O9)

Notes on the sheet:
PERIF188.JED P/N 18802-01
TO CPU
PCF CLOCK TTL OSCILLATOR
UART LED
S2 aka ST2 (latched) rev. 003
1.8432 OR 7.3728 MHz TTL OSCILLATOR


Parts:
J11: FPANEL; IDC-Header_2x20_P2.54mm_Horizontal
RN3: 470; R_Array_SIP9
RN5: 4700; R_Array_SIP9
U31: 74LS244; DIP-20_W7.62mm_Socket_LongPads
U33: 74LS374; DIP-20_W7.62mm_Socket_LongPads

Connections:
470C: RN3.4 (R3); also elsewhere on the board
470D: RN3.5 (R4); also elsewhere on the board
470E: RN3.6 (R5); also elsewhere on the board
470F: RN3.7 (R6); also elsewhere on the board
470G: RN3.8 (R7); also elsewhere on the board
/fpanel/FP-D0: J11.6, RN5.2 (R1), U31.2 (I0a)
/fpanel/FP-D1: J11.8, RN5.3 (R2), U31.4 (I1a)
/fpanel/FP-D2: J11.10, RN5.4 (R3), U31.6 (I2a)
/fpanel/FP-D3: J11.12, RN5.5 (R4), U31.8 (I3a)
/fpanel/FP-D4: J11.14, RN5.6 (R5), U31.11 (I0b)
/fpanel/FP-D5: J11.16, RN5.7 (R6), U31.13 (I1b)
/fpanel/FP-D6: J11.18, RN5.8 (R7), U31.15 (I2b)
/fpanel/FP-D7: J11.20, RN5.9 (R8), U31.17 (I3b)
CPU-D0: U31.18 (O0a), U33.3 (D0); also elsewhere on the board
CPU-D1: U31.16 (O1a), U33.4 (D1); also elsewhere on the board
CPU-D2: U31.14 (O2a), U33.7 (D2); also elsewhere on the board
CPU-D3: U31.12 (O3a), U33.8 (D3); also elsewhere on the board
CPU-D4: U31.9 (O0b), U33.13 (D4); also elsewhere on the board
CPU-D5: U31.7 (O1b), U33.14 (D5); also elsewhere on the board
CPU-D6: U31.5 (O2b), U33.17 (D6); also elsewhere on the board
CPU-D7: U31.3 (O3b), U33.18 (D7); also elsewhere on the board
FP-LATCH-WR: U33.11 (Cp); also elsewhere on the board
GND: J11.1, J11.2, J11.22, J11.25, J11.39, J11.40, U31.10 (GND), U33.10 (GND); also elsewhere on the board
I2C_SCL: J11.23; also elsewhere on the board
I2C_SDA: J11.21; also elsewhere on the board
unnamed: J11.5, U33.2 (O0)
unnamed: J11.7, U33.5 (O1)
unnamed: J11.9, U33.6 (O2)
unnamed: J11.11, U33.9 (O3)
unnamed: J11.13, U33.12 (O4)
unnamed: J11.15, U33.15 (O5)
unnamed: J11.17, U33.16 (O6)
unnamed: J11.19, U33.19 (O7)
RX: J11.31; also elsewhere on the board
TX: J11.33; also elsewhere on the board
VCC: J11.3, J11.4, J11.37, J11.38, RN3.1 (common), RN5.1 (common), U31.20 (VCC), U33.20 (VCC); also elsewhere on the board
ZERO: U33.1 (OE); also elsewhere on the board
~CTS: J11.35; also elsewhere on the board
~EXT_RES: J11.24; also elsewhere on the board
~FP-LATCH-RD: U31.1 (OEa), U31.19 (OEb); also elsewhere on the board
~RTS: J11.27; also elsewhere on the board

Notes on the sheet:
J11 NOTE: PINS 5, 7, 9, 11, 13, 15, 17, 19 ARE FOR LED STATUS FOR ROMWBW FRONT PANEL INDICATOR PINS 6, 8, 10, 12, 14, 16, 18, 20 ARE FOR SWITCH INPUTS FOR ROMWBW FRONT PANEL PINS 21, 23 ARE FOR I2C CONNECTION (SDA & SCL) PINS 25, 27, 29, 31, 33, AND 35 ARE FOR TTL SERIAL CONNECTOR TO UART PINS 22, 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
U33 NOTE: USE 74HCT374 TO SOURCE OR SINK ADEQUATE CURRENT TO DRIVE LEDS ON FRONT PANEL
FRONT PANEL SWITCH INPUT
FRONT PANEL LED OUTPUT


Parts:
P1, P2, P3: CONN_02X25; IDC-Header_2x25_P2.54mm_Horizontal

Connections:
+12V: P2.19, P2.20
-12V: P2.37, P2.38
/bus/A22: P2.24
/bus/A23: P2.22
/bus/A24: P2.18
/bus/A25: P2.16
/bus/A26: P2.14
/bus/A27: P2.12
/bus/A28: P2.10
/bus/A29: P2.8
/bus/A30: P2.6
/bus/A31: P2.4
/bus/AUXCLK0: P2.48
/bus/AUXCLK1: P2.47
/bus/AUXCLK2: P3.48
/bus/AUXCLK3: P3.46
/bus/CRUCLK: P1.14
/bus/CRUIN: P1.18
/bus/CRUOUT: P1.16
/bus/D8: P3.17
/bus/D9: P3.15
/bus/D10: P3.13
/bus/D11: P3.11
/bus/D12: P3.9
/bus/D13: P3.7
/bus/D14: P3.5
/bus/D15: P3.3
/bus/D16: P3.34
/bus/D17: P3.32
/bus/D18: P3.30
/bus/D19: P3.28
/bus/D20: P3.26
/bus/D21: P3.24
/bus/D22: P3.22
/bus/D23: P3.20
/bus/D24: P3.18
/bus/D25: P3.16
/bus/D26: P3.14
/bus/D27: P3.12
/bus/D28: P3.10
/bus/D29: P3.8
/bus/D30: P3.6
/bus/D31: P3.4
/bus/E: P1.4
/bus/IC0: P2.45
/bus/IC1: P2.43
/bus/IC2: P2.41
/bus/IC3: P2.39
/bus/IPL0: P3.47
/bus/IPL1: P3.45
/bus/IPL2: P3.43
/bus/LDS: P3.38
/bus/PHI: P1.8
/bus/S0: P3.44
/bus/S1: P3.42
/bus/S2: P3.40
/bus/ST: P1.6
/bus/UDS: P3.36
/bus/USER0: P1.38
/bus/USER1: P1.36
/bus/USER2: P1.34
/bus/USER3: P1.32
/bus/USER4: P1.30
/bus/USER5: P1.28
/bus/USER6: P1.26
/bus/USER7: P1.24
/bus/USER8: P1.22
/bus/~BHE: P3.41
/bus/~BUSERR: P3.35
/bus/~INT1: P1.12
/bus/~INT2: P1.10
/bus/~TEND0: P2.44
/bus/~TEND1: P2.40
/bus/~VMA: P3.39
/bus/~VPA: P3.37
A0: P2.35; also elsewhere on the board
A1: P2.33; also elsewhere on the board
A2: P2.31; also elsewhere on the board
A3: P2.29; also elsewhere on the board
A4: P2.27; also elsewhere on the board
A5: P2.25; also elsewhere on the board
A6: P2.23; also elsewhere on the board
A7: P2.21; also elsewhere on the board
A8: P2.17; also elsewhere on the board
A9: P2.15; also elsewhere on the board
A10: P2.13; also elsewhere on the board
A11: P2.11; also elsewhere on the board
A12: P2.9; also elsewhere on the board
A13: P2.7; also elsewhere on the board
A14: P2.5; also elsewhere on the board
A15: P2.3; also elsewhere on the board
A16: P2.36; also elsewhere on the board
A17: P2.34; also elsewhere on the board
A18: P2.32; also elsewhere on the board
A19: P2.30; also elsewhere on the board
A20: P2.28; also elsewhere on the board
A21: P2.26; also elsewhere on the board
D0: P3.33; also elsewhere on the board
D1: P3.31; also elsewhere on the board
D2: P3.29; also elsewhere on the board
D3: P3.27; also elsewhere on the board
D4: P3.25; also elsewhere on the board
D5: P3.23; also elsewhere on the board
D6: P3.21; also elsewhere on the board
D7: P3.19; also elsewhere on the board
GND: P1.49, P1.50, P2.49, P2.50, P3.49, P3.50; also elsewhere on the board
I2C_SCL: P1.47; also elsewhere on the board
I2C_SDA: P1.48; also elsewhere on the board
unnamed: P1.40, P1.42
unnamed: P1.44, P1.46
VCC: P1.1, P1.2, P2.1, P2.2, P3.1, P3.2; also elsewhere on the board
bCLK: P1.15; also elsewhere on the board
~BUSACK: P1.13; also elsewhere on the board
~BUSRQ: P1.23; also elsewhere on the board
~DREQ0: P2.46; also elsewhere on the board
~DREQ1: P2.42; also elsewhere on the board
~EIRQ0: P1.45; also elsewhere on the board
~EIRQ1: P1.43; also elsewhere on the board
~EIRQ2: P1.41; also elsewhere on the board
~EIRQ3: P1.39; also elsewhere on the board
~EIRQ4: P1.37; also elsewhere on the board
~EIRQ5: P1.35; also elsewhere on the board
~EIRQ6: P1.33; also elsewhere on the board
~EIRQ7: P1.31; also elsewhere on the board
~HALT: P1.27; also elsewhere on the board
~IORQ: P1.7; also elsewhere on the board
~M1: P1.11; also elsewhere on the board
~MREQ: P1.9; also elsewhere on the board
~NMI: P1.19; also elsewhere on the board
~RD: P1.3; also elsewhere on the board
~RES_IN: P1.20; also elsewhere on the board
~RES_OUT: P1.21; also elsewhere on the board
~RFSH: P1.29; also elsewhere on the board
~WAIT: P1.25; also elsewhere on the board
~WR: P1.5; also elsewhere on the board


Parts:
C2, C3, C4, C5, C6, C8, C9, C10, C11, C12, C13, C14, C15, C16, C17, C18, C19, C20, C21, C22, C23, C24, C30, C31, C32, C33, C34, C35, C36, C37, C38, C39, C40: 0.1u; C_Disc_D5.0mm_W2.5mm_P5.00mm
C25, C26, C27, C28: 10u; CP_Radial_D5.0mm_P2.50mm
C29: 22u; CP_Radial_D5.0mm_P2.50mm
C46: 47uF; CP_Radial_D5.0mm_P2.50mm
D7: LED; LED_D3.0mm_Horizontal_O3.81mm_Z2.0mm
H1, H2: MountingHole; MountingHole_3.2mm_M3_Pad
NT3, NT4: NetTie_2; NetTie-2_THT_Pad0.3mm
U1: 74LS04; DIP-14_W7.62mm_Socket_LongPads
U2: 74LS32; DIP-14_W7.62mm_Socket_LongPads
U4: 74LS07; DIP-14_W7.62mm_Socket_LongPads
U16: 74LS08; DIP-14_W7.62mm_Socket_LongPads
U21: 74LS74; DIP-14_W7.62mm_Socket_LongPads
U23: 74LS00; DIP-14_W7.62mm_Socket_LongPads

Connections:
470F: D7.2 (A); also elsewhere on the board
GND: C2.2, C3.2, C4.2, C5.2, C6.2, C8.2, C9.2, C10.2, C11.2, C12.2, C13.2, C14.2, C15.2, C16.2, C17.2, C18.2, C19.2, C20.2, C21.2, C22.2, C23.2, C24.2, C25.2, C26.2, C27.2, C28.2, C29.2, C30.2, C31.2, C32.2, C33.2, C34.2, C35.2, C36.2, C37.2, C38.2, C39.2, C40.2, C46.2, D7.1 (K), H1.1, H2.1, NT4.1, U1.7 (GND), U2.7 (GND), U4.7 (GND), U16.7 (GND), U21.7 (GND), U23.7 (GND); also elsewhere on the board
ONE: NT3.2; also elsewhere on the board
VCC: C2.1, C3.1, C4.1, C5.1, C6.1, C8.1, C9.1, C10.1, C11.1, C12.1, C13.1, C14.1, C15.1, C16.1, C17.1, C18.1, C19.1, C20.1, C21.1, C22.1, C23.1, C24.1, C25.1, C26.1, C27.1, C28.1, C29.1, C30.1, C31.1, C32.1, C33.1, C34.1, C35.1, C36.1, C37.1, C38.1, C39.1, C40.1, C46.1, NT3.1, U1.14 (VCC), U2.14 (VCC), U4.14 (VCC), U16.14 (VCC), U21.14 (VCC), U23.14 (VCC); also elsewhere on the board
ZERO: NT4.2; also elsewhere on the board

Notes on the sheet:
POWER LED
SPARE GATES


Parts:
JP1: GENERATE CLOCK; PinHeader_1x02_P2.54mm_Vertical
JP4: BUS CPU; PinHeader_2x04_P2.54mm_Vertical
R4, R6, R7: 1K; R_Axial_DIN0207_L6.3mm_D2.5mm_P7.62mm_Horizontal
RN1, RN4: 4700; R_Array_SIP9
U2: 74LS32; DIP-14_W7.62mm_Socket_LongPads
U6, U8, U10, U14, U17: 74LS244; DIP-20_W7.62mm_Socket_LongPads
U7: 74LS240; DIP-20_W7.62mm_Socket_LongPads
U11: 74LS245; DIP-20_W7.62mm_Socket_LongPads
U23: 74LS00; DIP-14_W7.62mm_Socket_LongPads

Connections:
A0: U6.18 (O0a); also elsewhere on the board
A1: U6.16 (O1a); also elsewhere on the board
A2: U6.14 (O2a); also elsewhere on the board
A3: U6.12 (O3a); also elsewhere on the board
A4: U6.9 (O0b); also elsewhere on the board
A5: U6.7 (O1b); also elsewhere on the board
A6: U6.5 (O2b); also elsewhere on the board
A7: U6.3 (O3b); also elsewhere on the board
A8: U8.18 (O0a); also elsewhere on the board
A9: U8.16 (O1a); also elsewhere on the board
A10: U8.14 (O2a); also elsewhere on the board
A11: U8.12 (O3a); also elsewhere on the board
A12: U8.9 (O0b); also elsewhere on the board
A13: U8.7 (O1b); also elsewhere on the board
A14: U8.5 (O2b); also elsewhere on the board
A15: U8.3 (O3b); also elsewhere on the board
A16: U10.18 (O0a); also elsewhere on the board
A17: U10.16 (O1a); also elsewhere on the board
A18: U10.14 (O2a); also elsewhere on the board
A19: U10.12 (O3a); also elsewhere on the board
A20: U17.16 (O1a); also elsewhere on the board
A21: U17.18 (O0a); also elsewhere on the board
CLKOUT: U10.13 (I1b); also elsewhere on the board
CPU-A0: U6.2 (I0a); also elsewhere on the board
CPU-A1: U6.4 (I1a); also elsewhere on the board
CPU-A2: U6.6 (I2a); also elsewhere on the board
CPU-A3: U6.8 (I3a); also elsewhere on the board
CPU-A4: U6.11 (I0b); also elsewhere on the board
CPU-A5: U6.13 (I1b); also elsewhere on the board
CPU-A6: U6.15 (I2b); also elsewhere on the board
CPU-A7: U6.17 (I3b); also elsewhere on the board
CPU-A8: U8.2 (I0a); also elsewhere on the board
CPU-A9: U8.4 (I1a); also elsewhere on the board
CPU-A10: U8.6 (I2a); also elsewhere on the board
CPU-A11: U8.8 (I3a); also elsewhere on the board
CPU-A12: U8.11 (I0b); also elsewhere on the board
CPU-A13: U8.13 (I1b); also elsewhere on the board
CPU-A14: U8.15 (I2b); also elsewhere on the board
CPU-A15: U8.17 (I3b); also elsewhere on the board
CPU-A16: U10.2 (I0a); also elsewhere on the board
CPU-A17: U10.4 (I1a); also elsewhere on the board
CPU-A18: U10.6 (I2a); also elsewhere on the board
CPU-A19: U10.8 (I3a); also elsewhere on the board
CPU-A20: RN1.5 (R4), U17.4 (I1a)
CPU-A21: RN1.3 (R2), U17.2 (I0a)
CPU-D0: U11.2 (A0); also elsewhere on the board
CPU-D1: U11.3 (A1); also elsewhere on the board
CPU-D2: U11.4 (A2); also elsewhere on the board
CPU-D3: U11.5 (A3); also elsewhere on the board
CPU-D4: U11.6 (A4); also elsewhere on the board
CPU-D5: U11.7 (A5); also elsewhere on the board
CPU-D6: U11.8 (A6); also elsewhere on the board
CPU-D7: U11.9 (A7); also elsewhere on the board
CPU-DREQ1: R6.2; also elsewhere on the board
CPU-NMI: R4.2, U23.6; also elsewhere on the board
D0: U11.18 (B0); also elsewhere on the board
D1: U11.17 (B1); also elsewhere on the board
D2: U11.16 (B2); also elsewhere on the board
D3: U11.15 (B3); also elsewhere on the board
D4: U11.14 (B4); also elsewhere on the board
D5: U11.13 (B5); also elsewhere on the board
D6: U11.12 (B6); also elsewhere on the board
D7: U11.11 (B7); also elsewhere on the board
DT~R_TS: U11.1 (A->B); also elsewhere on the board
EIRQ0: U7.3 (O3b); also elsewhere on the board
EIRQ1: U7.5 (O2b); also elsewhere on the board
EIRQ2: U7.7 (O1b); also elsewhere on the board
EIRQ3: U7.9 (O0b); also elsewhere on the board
EIRQ4: U7.12 (O3a); also elsewhere on the board
EIRQ5: U7.14 (O2a); also elsewhere on the board
EIRQ6: U7.16 (O1a); also elsewhere on the board
EIRQ7: U7.18 (O0a); also elsewhere on the board
GND: R4.1, R6.1, R7.1, U6.10 (GND), U7.10 (GND), U8.10 (GND), U10.10 (GND), U11.10 (GND), U14.10 (GND), U17.10 (GND); also elsewhere on the board
HLDA: U14.2 (I0a); also elsewhere on the board
HOLD: R7.2; also elsewhere on the board
unnamed: JP1.1 (A), U10.7 (O1b)
unnamed: JP4.1, RN1.6 (R5)
unnamed: JP4.3, RN1.7 (R6)
unnamed: JP4.5, RN1.8 (R7)
unnamed: JP4.7, RN1.9 (R8)
unnamed: U2.3, U11.19 (CE)
unnamed: U17.7 (O1b), U23.4, U23.5
SRDY: U14.14 (O2a); also elsewhere on the board
VCC: RN1.1 (common), RN4.1 (common), U6.20 (VCC), U7.20 (VCC), U8.20 (VCC), U10.20 (VCC), U11.20 (VCC), U14.20 (VCC), U17.20 (VCC); also elsewhere on the board
bCLK: JP1.2 (B); also elsewhere on the board
~188EN: U2.1, U6.1 (OEa), U6.19 (OEb), U7.1 (OEa), U7.19 (OEb), U8.1 (OEa), U8.19 (OEb), U10.1 (OEa), U10.19 (OEb), U14.1 (OEa), U14.19 (OEb), U17.1 (OEa), U17.19 (OEb); also elsewhere on the board
~BDREQ: U10.3 (O3b); also elsewhere on the board
~BUSACK: U14.18 (O0a); also elsewhere on the board
~BUSRQ: RN4.7 (R6); also elsewhere on the board
~CPU-HALT: RN4.6 (R5), U10.15 (I2b); also elsewhere on the board
~CPU-INTA0: RN4.3 (R2); also elsewhere on the board
~CPU-IORQ: U14.11 (I0b); also elsewhere on the board
~CPU-M1: RN1.4 (R3), U14.8 (I3a); also elsewhere on the board
~CPU-MREQ: U14.13 (I1b); also elsewhere on the board
~CPU-RD: U14.17 (I3b); also elsewhere on the board
~CPU-RFSH: U10.11 (I0b); also elsewhere on the board
~CPU-WR: U14.15 (I2b); also elsewhere on the board
~DREQ0: RN1.2 (R1), U10.17 (I3b); also elsewhere on the board
~DREQ1: RN4.9 (R8); also elsewhere on the board
~EIRQ0: U7.17 (I3b); also elsewhere on the board
~EIRQ1: U7.15 (I2b); also elsewhere on the board
~EIRQ2: U7.13 (I1b); also elsewhere on the board
~EIRQ3: U7.11 (I0b); also elsewhere on the board
~EIRQ4: U7.8 (I3a); also elsewhere on the board
~EIRQ5: U7.6 (I2a); also elsewhere on the board
~EIRQ6: U7.4 (I1a); also elsewhere on the board
~EIRQ7: U7.2 (I0a); also elsewhere on the board
~G_DATA: U2.2; also elsewhere on the board
~HALT: U10.5 (O2b); also elsewhere on the board
~IORQ: JP4.2, U14.9 (O0b); also elsewhere on the board
~M1: U14.12 (O3a); also elsewhere on the board
~MREQ: JP4.4, U14.7 (O1b); also elsewhere on the board
~NMI: U17.13 (I1b); also elsewhere on the board
~RD: JP4.8, U14.3 (O3b); also elsewhere on the board
~RES_OUT: RN4.2 (R1); also elsewhere on the board
~RFSH: U10.9 (O0b); also elsewhere on the board
~SPEN: RN4.5 (R4); also elsewhere on the board
~WAIT: RN4.4 (R3), U14.6 (I2a); also elsewhere on the board
~WR: JP4.6, U14.5 (O2b); also elsewhere on the board

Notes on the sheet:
Z80 BUS INTERFACE

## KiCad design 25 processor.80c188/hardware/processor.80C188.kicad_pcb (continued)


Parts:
J13, J14: FLASH OR CMOS; PinHeader_1x03_P2.54mm_Vertical
R1: 10K; R_Axial_DIN0207_L6.3mm_D2.5mm_P7.62mm_Horizontal
U26: 29F040; DIP-32_W15.24mm_Socket_LongPads

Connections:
CPU-A0: U26.12 (A0); also elsewhere on the board
CPU-A1: U26.11 (A1); also elsewhere on the board
CPU-A2: U26.10 (A2); also elsewhere on the board
CPU-A3: U26.9 (A3); also elsewhere on the board
CPU-A4: U26.8 (A4); also elsewhere on the board
CPU-A5: U26.7 (A5); also elsewhere on the board
CPU-A6: U26.6 (A6); also elsewhere on the board
CPU-A7: U26.5 (A7); also elsewhere on the board
CPU-A8: U26.27 (A8); also elsewhere on the board
CPU-A9: U26.26 (A9); also elsewhere on the board
CPU-A10: U26.23 (A10); also elsewhere on the board
CPU-A11: U26.25 (A11); also elsewhere on the board
CPU-A12: U26.4 (A12); also elsewhere on the board
CPU-A13: U26.28 (A13); also elsewhere on the board
CPU-A14: U26.29 (A14); also elsewhere on the board
CPU-A15: U26.3 (A15); also elsewhere on the board
CPU-A16: U26.2 (A16); also elsewhere on the board
CPU-A17: J13.3; also elsewhere on the board
CPU-A18: J14.1, U26.1 (A18); also elsewhere on the board
CPU-D0: U26.13 (D0); also elsewhere on the board
CPU-D1: U26.14 (D1); also elsewhere on the board
CPU-D2: U26.15 (D2); also elsewhere on the board
CPU-D3: U26.17 (D3); also elsewhere on the board
CPU-D4: U26.18 (D4); also elsewhere on the board
CPU-D5: U26.19 (D5); also elsewhere on the board
CPU-D6: U26.20 (D6); also elsewhere on the board
CPU-D7: U26.21 (D7); also elsewhere on the board
GND: U26.16 (GND); also elsewhere on the board
unnamed: J13.2, U26.30 (A17)
unnamed: J14.2, R1.2, U26.31 (PGM)
VCC: J13.1, R1.1, U26.32 (VCC); also elsewhere on the board
~CPU-RD: U26.24 (OE); also elsewhere on the board
~CPU-WR: J14.3; also elsewhere on the board
~UCS: U26.22 (CE); also elsewhere on the board

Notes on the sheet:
29F040 SHOWS ALL PIN ASSIGNMENTS
CMOS 27C010 (128K, 32pin) ALTERNATE 27C020 28pin: 27C512(64K), 27C256(32K)
ROM
FLASH 39SF010 (128K) ALTERNATES: 39SF020, 29F020, 29F010 39SF040, 29F040 (512K) NOT RECOMMENDED
1-2 FLASH OR CMOS (32-PIN) 2-3 28-PIN CMOS
DEFAULT CHIP: 39SF010 (128K FLASH) DEFAULT JUMPERS: 1-2, 1-2 (BOTH)
OFF FLASH WRITE PROTECT OR CMOS UP TO 128K 1-2 FLASH (DEFAULT) NO WP 2-3 CMOS (512K)


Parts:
D2, D5: LED; LED_D3.0mm_Horizontal_O3.81mm_Z2.0mm
D6: 1N4148; D_DO-35_SOD27_P7.62mm_Horizontal
J4: RES SEL; PinHeader_1x02_P2.54mm_Vertical
R5: 10; R_Axial_DIN0207_L6.3mm_D2.5mm_P7.62mm_Horizontal
SW1: RESET; SW_Tactile_SPST_Angled_PTS645Vx58-2LFS
U1: 74LS04; DIP-14_W7.62mm_Socket_LongPads
U3, U19: 74ALS373; DIP-20_W7.62mm_Socket_LongPads
U4: 74LS07; DIP-14_W7.62mm_Socket_LongPads
U5: 8259; DIP-28_W15.24mm_Socket_LongPads
U9: CPU CLOCK; DIP-14_W7.62mm_Socket_LongPads
U12: 80C188; 80C188_52
U13: DS1233; TO-92L_HandSolder
U15: GAL22V10; DIP-24_W7.62mm_Socket_LongPads

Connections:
188RST: U12.24 (~RES); also elsewhere on the board
470C: D5.2 (A); also elsewhere on the board
470D: D2.2 (A); also elsewhere on the board
ALE: U3.11 (LE), U12.61 (ALE/QS0), U15.1 (I0/CLK), U19.11 (LE); also elsewhere on the board
CLKOUT: U12.56 (CLKOUT); also elsewhere on the board
CPU-A0: U5.27 (A0), U19.19 (O7); also elsewhere on the board
CPU-A1: U19.16 (O6); also elsewhere on the board
CPU-A2: U19.15 (O5); also elsewhere on the board
CPU-A3: U19.12 (O4); also elsewhere on the board
CPU-A4: U19.9 (O3); also elsewhere on the board
CPU-A5: U19.6 (O2); also elsewhere on the board
CPU-A6: U19.5 (O1); also elsewhere on the board
CPU-A7: U19.2 (O0); also elsewhere on the board
CPU-A8: U12.16 (A8); also elsewhere on the board
CPU-A9: U12.14 (A9); also elsewhere on the board
CPU-A10: U12.12 (A10); also elsewhere on the board
CPU-A11: U12.10 (A11); also elsewhere on the board
CPU-A12: U12.7 (A12); also elsewhere on the board
CPU-A13: U12.5 (A13); also elsewhere on the board
CPU-A14: U12.3 (A14); also elsewhere on the board
CPU-A15: U12.1 (A15); also elsewhere on the board
CPU-A16: U3.9 (O3); also elsewhere on the board
CPU-A17: U3.6 (O2); also elsewhere on the board
CPU-A18: U3.5 (O1); also elsewhere on the board
CPU-A19: U3.2 (O0), U15.5 (I4); also elsewhere on the board
CPU-D0: U5.11 (D0), U12.17 (AD0), U19.18 (D7); also elsewhere on the board
CPU-D1: U5.10 (D1), U12.15 (AD1), U19.17 (D6); also elsewhere on the board
CPU-D2: U5.9 (D2), U12.13 (AD2), U19.14 (D5); also elsewhere on the board
CPU-D3: U5.8 (D3), U12.11 (AD3), U19.13 (D4); also elsewhere on the board
CPU-D4: U5.7 (D4), U12.8 (AD4), U19.8 (D3); also elsewhere on the board
CPU-D5: U5.6 (D5), U12.6 (AD5), U19.7 (D2); also elsewhere on the board
CPU-D6: U5.5 (D6), U12.4 (AD6), U19.4 (D1); also elsewhere on the board
CPU-D7: U5.4 (D7), U12.2 (AD7), U19.3 (D0); also elsewhere on the board
CPU-DREQ0: U12.19 (DRQ1), U15.22 (O1)
CPU-DREQ1: U12.18 (DRQ0); also elsewhere on the board
CPU-INT0: U5.17 (INT), U12.45 (INT0); also elsewhere on the board
CPU-NMI: U12.46 (NMI); also elsewhere on the board
CPU_S0: U3.13 (D4), U12.52 (~S0)
CPU_S1: U3.14 (D5), U12.53 (~S1)
CPU_S2: U3.17 (D6), U12.54 (~S2)
DT~R_TS: U12.40 (DT/~R); also elsewhere on the board
EIRQ0: U5.18 (IR0); also elsewhere on the board
EIRQ1: U5.19 (IR1); also elsewhere on the board
EIRQ2: U5.20 (IR2); also elsewhere on the board
EIRQ3: U5.21 (IR3); also elsewhere on the board
EIRQ4: U5.22 (IR4); also elsewhere on the board
EIRQ5: U5.23 (IR5); also elsewhere on the board
EIRQ6: U5.24 (IR6); also elsewhere on the board
EIRQ7: U5.25 (IR7); also elsewhere on the board
GND: SW1.2, U3.10 (GND), U5.14 (GND), U9.4, U9.7, U12.26 (VSS), U12.60 (VSS), U13.1, U15.12 (GND), U19.10 (GND); also elsewhere on the board
HLDA: U3.1 (OE), U12.51 (HLDA), U15.13 (I11), U19.1 (OE); also elsewhere on the board
HOLD: U12.50 (HOLD); also elsewhere on the board
unnamed: D2.1 (K), U1.1, U1.6
unnamed: D5.1 (K), U1.2
unnamed: D6.2 (A), R5.2, U4.11
unnamed: U12.25 (~PCS0), U15.11 (I10)
unnamed: U12.35 (~MCS3), U15.10 (I9)
unnamed: U12.36 (~MCS2), U15.9 (I8)
unnamed: U12.37 (~MCS1), U15.8 (I7)
unnamed: U12.38 (~MCS0), U15.7 (I6)
unnamed: U12.47 (~TEST), U12.57 (RESET)
unnamed: U9.8, U9.11, U12.59 (X1)
unnamed: U3.3 (D0), U12.65 (A19/S6)
unnamed: U3.4 (D1), U12.66 (A18/S5)
unnamed: U3.7 (D2), U12.67 (A17/S4)
unnamed: U3.8 (D3), U12.68 (A16/S3)
S0: U3.12 (O4), U15.4 (I3)
S1: U3.15 (O5), U15.3 (I2)
S2: U3.16 (O6), U15.2 (I1); also elsewhere on the board
SRDY: U12.49 (SRDY); also elsewhere on the board
TMR1_IN: U12.21 (TMR_IN_1); also elsewhere on the board
VCC: D6.1 (K), U3.20 (VCC), U5.28 (VCC), U9.1, U9.14, U12.9 (VCC), U12.20 (TMR_IN_0), U12.43 (VCC), U13.3, U15.24 (VCC), U19.20 (VCC); also elsewhere on the board
ZERO: U12.55 (ARDY); also elsewhere on the board
~BDREQ: U15.21 (O2); also elsewhere on the board
~CPU-HALT: U1.5, U15.18 (O5); also elsewhere on the board
~CPU-INTA0: U5.26 (~INTA), U12.42 (INT2/~INTA0); also elsewhere on the board
~CPU-IORQ: U15.19 (O4); also elsewhere on the board
~CPU-M1: U15.16 (O7); also elsewhere on the board
~CPU-MREQ: U15.17 (O6); also elsewhere on the board
~CPU-RD: U5.3 (~RD), U12.62 (~RD/~QSMD); also elsewhere on the board
~CPU-RFSH: U12.64 (~RFSH); also elsewhere on the board
~CPU-WR: U5.2 (~WR), U12.63 (~WR/QS1); also elsewhere on the board
~CS_PIC: U5.1 (~CS); also elsewhere on the board
~EXT_RES: J4.2, R5.1, SW1.1; also elsewhere on the board
~G_DATA: U15.20 (O3); also elsewhere on the board
~PCS1: U12.27 (~PCS1), U15.23 (O0)
~PCS4: U12.30 (~PCS4); also elsewhere on the board
~PCS5: U12.31 (~PCS5/A1); also elsewhere on the board
~PCS6: U12.32 (~PCS6/A2); also elsewhere on the board
~RES_IN: J4.1; also elsewhere on the board
~RES_OUT: U3.18 (D7), U4.10, U13.2; also elsewhere on the board
~SPEN: U5.16 (~SP/~EN); also elsewhere on the board
~UCS: U12.34 (~UCS), U15.6 (I5); also elsewhere on the board

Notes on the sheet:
pin 18 is connected so ACT or AHCT may be used
STAT188.JED P/N 18801-01
CPU CLOCK TTL OSCILLATOR
RUN
HALT
NOTE: RESET SELECT ALLOWS FOR RESET TO ORIGINATE: 1. ON PROCESSOR BOARD RESET BUTTON CIRCUIT ONLY (NONE) 2. FROM EXTERNAL BUS ~{RES_IN} (1-2 CLOSED)
FROM UART
Reset Button Circuit
CPU 2X oscillator must be an EVEN number Mhz 50.0, 40.0, 32.0, 24.0
RUN/HALT LEDS


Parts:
D4: 80C188; LED_D3.0mm_Horizontal_O3.81mm_Z2.0mm
J1: IO Address Select; PinHeader_2x08_P2.54mm_Vertical
J2: 80C188 RESET; PinHeader_1x03_P2.54mm_Horizontal
J3: 80C188 ONLY; PinHeader_1x03_P2.54mm_Horizontal
R9: 1KΩ; R_Axial_DIN0207_L6.3mm_D2.5mm_P7.62mm_Horizontal
RN2: 10KΩ; R_Array_SIP9
U1: 74LS04; DIP-14_W7.62mm_Socket_LongPads
U4: 74LS07; DIP-14_W7.62mm_Socket_LongPads
U16: 74LS08; DIP-14_W7.62mm_Socket_LongPads
U21: 74LS74; DIP-14_W7.62mm_Socket_LongPads
U22: 74LS688; DIP-20_W7.62mm_Socket_LongPads

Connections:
88TOGGLE: U16.11, U21.3 (C)
188EN: J2.3, U1.10, U1.13
188RST: J2.2; also elsewhere on the board
470G: D4.2 (A); also elsewhere on the board
A0: U22.2 (P0); also elsewhere on the board
A1: U22.4 (P1); also elsewhere on the board
A2: U22.6 (P2); also elsewhere on the board
A3: U22.8 (P3); also elsewhere on the board
A4: U22.11 (P4); also elsewhere on the board
A5: U22.13 (P5); also elsewhere on the board
A6: U22.15 (P6); also elsewhere on the board
A7: U22.17 (P7); also elsewhere on the board
GND: J1.1, J1.3, J1.5, J1.7, J1.9, J1.11, J1.13, J1.15, J3.1, R9.2, U22.10 (GND); also elsewhere on the board
unnamed: D4.1 (K), U1.12
unnamed: J1.2, RN2.2 (R1), U22.18 (R7)
unnamed: J1.4, RN2.3 (R2), U22.16 (R6)
unnamed: J1.6, RN2.4 (R3), U22.14 (R5)
unnamed: J1.8, RN2.5 (R4), U22.12 (R4)
unnamed: J1.10, RN2.6 (R5), U22.9 (R3)
unnamed: J1.12, RN2.7 (R6), U22.7 (R2)
unnamed: J1.14, RN2.8 (R7), U22.5 (R1)
unnamed: J1.16, RN2.9 (R8), U22.3 (R0)
unnamed: R9.1, U21.2 (D)
unnamed: U1.3, U22.19 (P=R)
unnamed: U1.4, U16.9, U16.10
unnamed: U16.8, U16.12, U16.13
VCC: RN2.1 (common), U21.1 (~R), U22.20 (VCC); also elsewhere on the board
~188ACTIVE: J3.3, U4.13, U21.5 (Q)
~188EN: J3.2, U1.11; also elsewhere on the board
~BUSRQ: U4.12; also elsewhere on the board
~IORQ: U22.1 (G); also elsewhere on the board
~RES_OUT: J2.1, U21.4 (~S); also elsewhere on the board

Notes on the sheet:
1&2 - stand alone 2&3 - secondary CPU
A bit of delay . . . .
Note: IO Address Port $96 1-2 =off - A7 (high) 3-4 =on - A6 (low) 5-6 =on - A5 (low) 7-8 =off - A4 (high) 9-10 =on - A3 (low) 11-12 =off - A2 (high) 13-14 =off - A1 (high) 15-16 =on - A0 (low)


Board: 2 copper layers, 235.0 x 160.0 mm, 112 parts (0 on the bottom side), 227 nets.

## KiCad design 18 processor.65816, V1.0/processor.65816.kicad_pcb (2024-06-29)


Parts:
U9: GAL22V10; DIP-24_W7.62mm_Socket_LongPads
U10: GAL16V8; DIP-20_W7.62mm_Socket_LongPads

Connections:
CLK: U10.1 (I1/CLK); also elsewhere on the board
CPU-A8: U9.21 (B6); also elsewhere on the board
CPU-A9: U9.22 (B7); also elsewhere on the board
CPU-A10: U9.2 (I0); also elsewhere on the board
CPU-A11: U9.3 (I1); also elsewhere on the board
CPU-A12: U9.4 (I2); also elsewhere on the board
CPU-A13: U9.5 (I3); also elsewhere on the board
CPU-A14: U9.6 (I4); also elsewhere on the board
CPU-A15: U9.7 (I5); also elsewhere on the board
CPU-A16: U9.8 (I6); also elsewhere on the board
CPU-A17: U9.9 (I7); also elsewhere on the board
CPU-A18: U9.10 (I8); also elsewhere on the board
CPU-A19: U9.11 (I9); also elsewhere on the board
CPU-A20: U9.14 (I10); also elsewhere on the board
CPU-A21: U9.1 (OD/CLK); also elsewhere on the board
CPU-A22: U9.13 (I/~OE); also elsewhere on the board
CPU-A23: U9.23 (I11); also elsewhere on the board
CPU-R~W: U10.2 (I2); also elsewhere on the board
DATA-DIR: U10.14 (IO6); also elsewhere on the board
GND: U9.12 (GND), U10.10 (GND); also elsewhere on the board
HIMEM: U9.19 (B4), U9.20 (B5)
unnamed: U9.17 (B2), U10.6 (I6)
VCC: U9.24 (VCC), U10.20 (VCC); also elsewhere on the board
VDA: U10.3 (I3); also elsewhere on the board
VPA: U10.4 (I4); also elsewhere on the board
~CPU-IORQ: U10.18 (IO2); also elsewhere on the board
~CPU-MREQ: U10.19 (IO1); also elsewhere on the board
~CPU-RD: U10.16 (IO4); also elsewhere on the board
~CPU-WR: U10.15 (IO5); also elsewhere on the board
~CS_IO: U10.9 (I9); also elsewhere on the board
~OFFBOARD_MEM: U9.16 (B1), U10.7 (I7)
~ONBOARD_ROM: U9.15 (B0); also elsewhere on the board



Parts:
D9: LED; LED_D3.0mm_Horizontal_O3.81mm_Z2.0mm
JP10: IO PORT ADDR; PinHeader_2x04_P2.54mm_Vertical
JP13: SER INT; PinHeader_1x02_P2.54mm_Vertical
R1, R12: 470; R_Axial_DIN0207_L6.3mm_D2.5mm_P7.62mm_Horizontal
RN8: 10K; R_Array_SIP9
U2: UART CLOCK; DIP-14_W7.62mm_Socket_LongPads
U3: 74LS14; DIP-14_W7.62mm_Socket_LongPads
U4: 74LS07; DIP-14_W7.62mm_Socket_LongPads
U7: 74LS04; DIP-14_W7.62mm_Socket_LongPads
U12: 74LS688; DIP-20_W7.62mm_Socket_LongPads
U14: TL16C550CFN; PLCC-44_THT-Socket
U20: GAL22V10; DIP-24_W7.62mm_Socket_LongPads
U25: 74LS374; DIP-20_W7.62mm_Socket_LongPads
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

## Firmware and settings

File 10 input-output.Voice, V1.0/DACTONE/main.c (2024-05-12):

/* SPDX-License-Identifier: GPL-2.0-or-later */

#include <math.h>
#include <stdio.h>
#include <stdlib.h>
#include <string.h>

#include "buffer.h"
#include "hbios.h"
#include "sio.h"
#include "wave.h"

#define CTC1_BASE 0x60
#define CTC1_CH3 (CTC1_BASE+3)

#define CTC2_BASE 0x44
#define CTC2_CH0 (CTC2_BASE+0)
#define CTC2_CH1 (CTC2_BASE+1)
#define CTC2_CH2 (CTC2_BASE+2)
#define CTC2_CH3 (CTC2_BASE+3)

#define NEW_BUFFER_SIZE 4096
#define BUFFER_START 0x8000

// Copy handler to hi address dest_addr, optionally replacing DAC output port with output_port.
void *copy_interrupt_handler(void (*handler)(), uint16_t dest_addr, uint8_t output_port, int verbose)
{
    /* 
     * The interrupt handler has to live in the upper 32K of the address space
     * under the RomWBW architecture. Copy the handler. The copy stops when it
     * sees an 0xc9 for a RET instruction. But it's possible that there is
     * an 0xc9 for other reasons, so we should be smarter about this.
     */

    int count = 1000, i;
    uint8_t *src = (uint8_t *) handler;
    uint8_t *dest = (uint8_t *)(dest_addr);
    int replace_port = 0;
    for (i = 0; i < count; i++) { 
        dest[i] = replace_port ? output_port : src[i];
        /* Look for an OUT instruction, followed by the 0xBB DAC port. Replace it with chosen port. */
        replace_port = ((src[i] == 0xd3) && (src[i+1] == 0xbb));
        if (verbose && replace_port) { 
            printf("Replacing output port with 0x%02x\n", output_port);
        }
        if (dest[i] == 0xc9) break; /* return instruction */
     }
     if (verbose) printf("Copied %d bytes of the interrupt handler. Used port 0x%02x\n", i, output_port);
     return (void *) dest;
}

// Initialize CTC2 interrupt and Channel 3 timer. Disable system tick.
void setup_timers(int base_vector, uint32_t samples_per_second, int verbose)
{
    /* Disable the system timer tick while playing back. */
    outp(CTC1_CH3, 0x03); /* reset channel */    

    /* Set the interrupt vector, which can only be done by writing to Channel 0. */
    outp(CTC2_CH0, 0x03); /* reset channel */
    outp(CTC2_CH0, base_vector * 2); 

    /* Compute time constant. CTC2 runs at 7,372,800 Hz and we program the prescaler to divide by 16. */
    uint32_t clk_div_16 = 7372800 / 16;
    float time_const_f = (float) clk_div_16 / (float) samples_per_second;
    long time_const = (long) (time_const_f + 0.5);
    if (verbose) printf("Computed time constant is %f or %ld\n", time_const_f, time_const);
    if (time_const > 255) { 
        fprintf(stderr, "Warning: computed time constant %ld is too big!!\n", time_const);
    }
    /* Set up Channel 3 to generate the interrupt at the required rate. */
    outp(CTC2_CH3, 0x03); /* reset channel. */
    outp(CTC2_CH3, 0x85); /* enable interrupt, select timer mode, divide-by-16, auto trigger. */
    outp(CTC2_CH3, (uint8_t) time_const); 
}

// After playback, stop CTC2 channel 3, restore old interrupt handler and restore system tick.
void restore_timers(int vector, void (*old_handler)())
{
    // Turn off the CTC2 CH3 interrupt by resetting the channel.
    outp(CTC2_CH3, 0x03);

    // Restore the old interrupt handler
    set_interrupt(vector, old_handler);

    // Restore the system timer tick
    outp(CTC1_CH3, 0xD7);
    outp(CTC1_CH3, 72);
}

void print_hbios_info(void)
{
    int version = get_hbios_version();
    int platform = get_hbios_platform();
    int intr_info = get_hbios_intr_info();
    int interrupt_mode = (intr_info >> 8) & 0xFF;
    int ivt_size = intr_info & 0xFF;

    printf("HBIOS Version = 0x%04x, Platform = 0x%02x, interrupt mode = %d, IVT size = %d\n", 
        version, platform, interrupt_mode, ivt_size);
}

struct Config { 
    int verbose;
    int serial;
    int print_usage;
    char *arg1;
    char *prog_name;
};

// Parse command line arguments into Config struct.
void parse_config(struct Config *cfg, int argc, char **argv)
{
    cfg->verbose = 0;
    cfg->serial = 0;
    cfg->print_usage = 0;
    cfg->arg1 = NULL;
    cfg->prog_name = "dactone";

    for (int i = 1; i < argc; i++) {
        char *arg = argv[i];
        if (arg[0] == '-') { 
            char option = arg[1];
            switch (option) { 
                case 'V': 
                    cfg->verbose = 1; 
                    printf("Verbose output enabled.\n");
                    break;
                case 'S':
                    cfg->serial = 1;
                    printf("Serial output enabled.\n");
                    break;
                case 'H':
                    cfg->print_usage = 1;
                    break;
                default:
                    fprintf(stderr, "Error: unknown option '%c'\n", option);
                    cfg->print_usage = 1;
            }
        } else { 
            cfg->arg1 = arg;
        }
    }
}

// Print a help message.
void print_usage(struct Config *cfg)
{
    fprintf(stderr, "usage: %s [-v] [-s] frequency\n", cfg->prog_name);
    fprintf(stderr, "     -v         Show verbose output.\n");
    fprintf(stderr, "     -s         Send samples (four seconds) to SIO0 Channel A instead of the DAC.\n");
    fprintf(stderr, "\n     frequency  The frequency of the tone to generate.\n");
}

// Weird field order is for interrupt handler efficiency. 
struct BufInfo { 
    uint16_t head;
    uint16_t end;
    uint16_t start;
    uint16_t passes;
};

void new_interrupt_handler(void);

// Use the HBIOS framework on install an interrupt handler. Copy handler to high address first.
void *setup_interrupt_handler(int vector, void (*handler)(void), uint16_t hi_addr, uint8_t output_port, int verbose)
{
    /* Copy the code for the interrupt handler to hi_addr. */
    void *hi_interrupt_handler = copy_interrupt_handler(handler, hi_addr, output_port, verbose);
    void *old_handler = set_interrupt(vector, hi_interrupt_handler);
    return old_handler;
}

// When looking to periodic samples, are the 'window' samples close enough (not more than diff of 1)?
static int is_close_enough(uint8_t *buffer, uint16_t index, int window)
{   
     for (int i = 0; i < window; i++) {
          int diff = abs(buffer[i] - buffer[index+i]);
          if (diff > 1) return 0;
     }
     return 1;
}

// Look for the last occurance of a sample sequence in a buffer.
static uint16_t get_last_index(uint8_t *buffer, uint32_t samples_per_second, int window)
{
    uint16_t result = 0;
     for (int i = 1; i < samples_per_second-window; i++) {
          if (is_close_enough(buffer, i, window)) {
               result = i;
          }
     }
     return result;
}

void generate_tone(struct Config *cfg, int base_vector)
{
    int samples_per_second = 8000;
    int duration = 4;

    struct BufInfo *bufinfo = (struct BufInfo *) BUFFER_INFO;

    bufinfo->start = bufinfo->head = BUFFER_START;
    bufinfo->end = BUFFER_START + NEW_BUFFER_SIZE;
    bufinfo->passes = 0;
    struct WavetableFixed table;

    double frequency = atof(cfg->arg1);

    /* Fill the interrupt handler buffer with samples from the wave table. */
    init_wavetable(&table, 1024, frequency, samples_per_second);
    get_table_samples(&table, (uint8_t *) bufinfo->start, NEW_BUFFER_SIZE);

    /* Find the latest matching start of the waveform. */
    int check_window = 8;
    uint16_t last_index = get_last_index((uint8_t *) bufinfo->start, samples_per_second, check_window);
    if (cfg->verbose) printf("last index = %u\n", last_index);
    bufinfo->end = BUFFER_START + last_index;

    uint32_t total_samples = duration * samples_per_second;
    uint32_t number_of_passes = (total_samples / last_index) + 1;
    uint32_t samples_remaining = number_of_passes * last_index;

    if (cfg->serial) {
        // If serial debug is enabled, send a WAV header first.
        struct SimpleWAV wav;
        initWAV(&wav, samples_per_second, samples_remaining);
        char buffer[128];
        int header_size = getWAVHeader(buffer, &wav);
        sio_write_buffer(buffer, header_size);
        printf("Sending about four seconds of samples to the serial port.\n");
    } else {
        printf("Sending samples for %7.2f Hz sine wave to the DAC.\n", frequency);
        printf("Press a key to exit...\n");
    }

    /* Start playing! */
    uint16_t next_pass = 1;
    int done = 0;
    setup_timers(base_vector, samples_per_second, cfg->verbose);
    
    while (!done) {
        /* Wait for the interrupt handler to finish a pass. */
        while (bufinfo->passes != next_pass)
            ;
        samples_remaining -= last_index;
        if (cfg->serial) { 
            if (samples_remaining == 0) done = 1;
        } else { 
            if (bdos(CPM_ICON, 0) != 0) done = 1;
        }
        if (!done) {
            outp(LED_PORT, next_pass & 1 ? 2 : 1);
            if (cfg->serial) printf("pass %d\n", next_pass-1);
            next_pass++;
        }
    }
    /* Turn off the CTC2 CH3 interrupt by resetting the channel. ASAP. */
    outp(CTC2_CH3, 0x03);

    if (cfg->serial) outp(LED_PORT, 0);

    printf("Exiting...\n");
}

int main(int argc, char **argv)
{
    struct Config cfg;
    parse_config(&cfg, argc, argv);

    if (cfg.print_usage) { 
        print_usage(&cfg);
        exit(1);
    }

    if (cfg.serial) { 
        init_sio_8n1(SIO0_PORTA);
        printf("SIO0 PORT A initialized.\n");
    }

    if (cfg.verbose) {
        int *topram = (int *)(0x7);
        printf("Top of RAM seems to be 0x%04x\n", *topram);
        print_hbios_info();
    }

    if (cfg.arg1== NULL) {
        fprintf(stderr, "usage: dactone.com frequency\n");
        exit(1);
    }

    /* 
     * CTC2 will occupy vectors 8-11 while this program is running.
     * We will use vector 11 for Channel 3 interrupts.
     */
    int base_vector = 8;
    //void *old_handler = setup_interrupt_handler(base_vector + 3, interrupt_handler, 0xC100, cfg.verbose);
    void *old_handler = setup_interrupt_handler(base_vector + 3, new_interrupt_handler, 0xC100, 
        cfg.serial ? SIO0A_DAT : DAC_PORT, cfg.verbose);

    generate_tone(&cfg, base_vector);
    /* All done */
    restore_timers(base_vector + 3, old_handler);
    return 0;
}

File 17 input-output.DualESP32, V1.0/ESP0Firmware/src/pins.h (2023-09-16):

#pragma Once

#define RD 13
#define WR 36
#define OUTCLK 26
#define INCLK 27
#define OUTDATA 16
#define INDATA 17
#define BUSY 14
#define READY 12
#define SPARE 2
#define RXPIN 3
#define TXPIN 1

#define RED1  GPIO_NUM_22
#define RED0  GPIO_NUM_21
#define GREEN1  GPIO_NUM_19
#define GREEN0  GPIO_NUM_18
#define BLUE1  GPIO_NUM_5
#define BLUE0  GPIO_NUM_4
#define HSYNC   GPIO_NUM_23
#define VSYNC   GPIO_NUM_15

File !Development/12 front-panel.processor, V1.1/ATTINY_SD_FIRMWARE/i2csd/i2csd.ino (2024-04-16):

/* 
   Duodyne SD card I2C to SD
   Modifications by Dan Werner

   This work is based on:
   David Johnson-Davies - www.technoblogy.com - 7th July 2022
   I2C SC-Card Module - see http://www.technoblogy.com/show?1LJI
   ATtiny1614 @ 20MHz (internal clock; BOD disabled) 
   CC BY 4.0
   Licensed under a Creative Commons Attribution 4.0 International license: 
   http://creativecommons.org/licenses/by/4.0/
*/

/* 
    Arduino Board should be set to megaTinyCode ATtiny 3224/1624/1614/1604/824/814/804/424/414/404/214/204
    Chip ATTiny1614
    Programmer should be set to Serial-UPDI SLOW 57600
*/

/*
                                     ATTINY1614-SS
                                 --------------------
                                 |                  |
                            VCC  | 1             14 |   GND
                        (SD) CS  | 2             13 |   CLK (SD)
                              X  | 3             12 |   DO  (SD)
                              X  | 4             11 |   DI  (SD)
                              X  | 5             10 |   UPDI
          BI-COLOR  -----------  | 6              9 |   I2C_SCL
               LED  -----------  | 7              8 |   I2C_SDA
                                 |                  |
                                 --------------------

Commands:
   S=Set LBA Address    Format SBBBB    (B=address Byte)
   R=Read Sector (R followed by 512 bytes of read)
   W=Write Sector (W followed by 512 bytes of write)
*/

#include <SD.h>

File myFile;

#if DEBUG
File logFile;
#endif

volatile unsigned char buffer[512];

// LEDs **********************************************

const int LEDoff = 0;
const int LEDgreen = 1;
const int LEDred = 2;

void LightLED(int colour) {
  digitalWrite(5, colour & 1);
  digitalWrite(4, colour >> 1 & 1);
}

// I2C Interface **********************************************

volatile uint8_t lbaAddress[4];

union ulbaAddress_u {
  uint8_t bytes[4];
  uint32_t number;
} ulbaAddress;

const int MyAddress = 0x25;

// TWI setup **********************************************

void I2CSetup() {
  TWI0.CTRLA = 0;               // Default timings
  TWI0.SADDR = MyAddress << 1;  // Bottom bit is R/W bit
  // Enable address, data, and stop interrupts:
  TWI0.SCTRLA = TWI_APIEN_bm | TWI_DIEN_bm | TWI_PIEN_bm | TWI_ENABLE_bm;
}

// Functions to handle each of the cases **********************************************

volatile uint8_t command = 0;  // Currently active command
volatile int ch = 0, ptr = 0;  // Filename and size pointers
boolean checknack = false;     // Don't check Host NACK first time


boolean AddressHostRead() {
  ptr = 0;
  return true;
}

boolean AddressHostWrite() {
  command = 0;
  ch = 0;
  ptr = 0;  // Reset these on writing
  return true;
}

void DataHostRead() {
  if (command == 'R') {
    if (ptr < 512) {
      TWI0.SDATA = buffer[ptr++];  // Host read operation
    } else {
      TWI0.SDATA = 0;  // Error, too many bytes read
      LightLED(LEDred);
    }
  } else {
    TWI0.SDATA = 0;  // Read in other situations
                     // LightLED(LEDred);
  }
}


boolean DataHostWrite() {

#if DEBUG
  logFile.write("IB");
  logFile.write(TWI0.SDATA);
  logFile.flush();
#endif

  if (command == 0) {  // No command in progress

#if DEBUG
    logFile.write("CM");
    logFile.flush();
#endif

    command = TWI0.SDATA;
    LightLED(LEDgreen);  // Got Command
    if (command != 'I') return true;
  }

  if (command == 'R') {  // READ
#if DEBUG
    logFile.write("CR");
    logFile.flush();
#endif
    ptr = 0;
    return true;
  }


  if (command == 'I') {  // INFO
#if DEBUG
    logFile.write("CI");
    logFile.flush();
#endif
    unsigned long sz = myFile.size();
    unsigned char *p = (unsigned char *)&sz;
    for (int i = 0; i < 512; i++) buffer[i] = 0;
    buffer[0] = 'S';
    buffer[1] = 'D';
    buffer[2] = p[3];
    buffer[3] = p[2];
    buffer[4] = p[1];
    buffer[5] = p[0];
    ptr = 0;
#if DEBUG
    logFile.write(buffer[0]);
    logFile.write(buffer[1]);
    logFile.write(buffer[2]);
    logFile.write(buffer[3]);
    logFile.write(buffer[4]);
    logFile.write(buffer[5]);
    logFile.flush();
#endif
    return true;
  }



  if (command == 'S') {  // Set Sector
#if DEBUG
    logFile.write("CS");
    logFile.write(3 - ch);
    logFile.flush();
#endif
    if (ch < 4) {
      lbaAddress[3 - (ch++)] = TWI0.SDATA;
      if (ch == 4) {
        ulbaAddress.bytes[0] = lbaAddress[0];
        ulbaAddress.bytes[1] = lbaAddress[1];
        ulbaAddress.bytes[2] = lbaAddress[2];
        ulbaAddress.bytes[3] = lbaAddress[3];
        myFile.seek(ulbaAddress.number * 512);
        for (int i = 0; i < 512; i++) {
          buffer[i] = myFile.read();
        }
      }
      ptr = 0;
      return true;
    }
  }

  if (command == 'W') {
#if DEBUG
    logFile.write("CW");
    logFile.write(ptr);
    logFile.flush();
#endif
    if (ptr < 512) {
      buffer[ptr++] = TWI0.SDATA;
      if (ptr == 512) {
        ulbaAddress.bytes[0] = lbaAddress[0];
        ulbaAddress.bytes[1] = lbaAddress[1];
        ulbaAddress.bytes[2] = lbaAddress[2];
        ulbaAddress.bytes[3] = lbaAddress[3];

        myFile.seek(ulbaAddress.number * 512);
        for (int i = 0; i < 512; i++) {
          myFile.write(buffer[i]);
        }
        myFile.flush();
      }    
    return true;
  }
}

// LightLED(LEDred);
return false;
}

void Stop() {
  LightLED(LEDoff);
}

void SendResponse(boolean succeed) {
  if (succeed) {
    TWI0.SCTRLB = TWI_ACKACT_ACK_gc | TWI_SCMD_RESPONSE_gc;  // Send ACK
  } else {
    TWI0.SCTRLB = TWI_ACKACT_NACK_gc | TWI_SCMD_RESPONSE_gc;  // Send NACK
  }
}

// TWI interrupt service routine **********************************************

// TWI interrupt
ISR(TWI0_TWIS_vect) {
  boolean succeed;

  // Address interrupt:
  if ((TWI0.SSTATUS & TWI_APIF_bm) && (TWI0.SSTATUS & TWI_AP_bm)) {
    if (TWI0.SSTATUS & TWI_DIR_bm) {  // Host reading from client
      succeed = AddressHostRead();
    } else {
      succeed = AddressHostWrite();  // Host writing to client
    }
    SendResponse(succeed);
    return;
  }

  // Data interrupt:
  if (TWI0.SSTATUS & TWI_DIF_bm) {
    // LightLED(LEDred);
    if (TWI0.SSTATUS & TWI_DIR_bm) {  // Host reading from client
                                      //  LightLED(LEDgreen);
      if ((TWI0.SSTATUS & TWI_RXACK_bm) && checknack) {
        checknack = false;
      } else {
        DataHostRead();
        checknack = true;
      }
      TWI0.SCTRLB = TWI_SCMD_RESPONSE_gc;  // No ACK/NACK needed
    } else {                               // Host writing to client
      //LightLED(LEDoff);
      succeed = DataHostWrite();
      SendResponse(succeed);
    }

    return;
  }

  // Stop interrupt:
  if ((TWI0.SSTATUS & TWI_APIF_bm) && (!(TWI0.SSTATUS & TWI_AP_bm))) {
    Stop();
    TWI0.SCTRLB = TWI_SCMD_COMPTRANS_gc;  // Complete transaction
    return;
  }
}

// Setup **********************************************
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

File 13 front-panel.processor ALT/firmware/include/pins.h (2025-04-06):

#pragma Once


#define SCK 3
#define MISO 4
#define MOSI 5
#define CS 6

#define DISPLAYI2C_SCL  36
#define DISPLAYI2C_SDA  37
#define DUODYNEI2C_SCL  21
#define DUODYNEI2C_SDA  35

#define  ConsoleSerialTX 45     // 38
#define  ConsoleSerialRX 38     // 45
#define  ConsoleSerialRTS 47    // 46
#define  ConsoleSerialCTS 46    // 47
#define  ConsolePort 23

#define SCREEN_WIDTH 128 // OLED display width, in pixels
#define SCREEN_HEIGHT 64 // OLED display height, in pixels

#define I2C_DEV_ADDR 0x55 // Address that DUODYNE will find I2C

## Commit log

2023-04-01 more KiCAD 6 transition clean up Signed-off-by: lynchaj <lynchaj@yahoo.com>
    [CTC-INT.kicad_sch, CTC-SIO.kicad_sch, DMA.kicad_sch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]
2023-04-05 IO port update and clean-ups Signed-off-by: lynchaj <lynchaj@yahoo.com>
    [ADC-DAC.kicad_sch, CPU-DATA-DIR-GAL.csv, DMA.kicad_sch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]
2023-08-06 Add Dual32V1.0
    [DualESP32.kicad_sch, IOSelection.kicad_sch, buffers.kicad_sch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]
2023-08-19 ESP32 work
    [DualESP32.kicad_sch, IOSelection.kicad_sch, Z80ESP_Commands.xlsx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]
2023-08-21 esp test work and bug fix to serial 2 firmware
    [main.cpp]
2023-08-28 ESP32 reset
    [DualESP32.kicad_sch, buffers.kicad_sch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]
2023-09-02 Add 65816 Processor board
    [65816CPU.kicad_sch, GALS.kicad_sch, buffers.kicad_sch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]
2023-09-02 correct outgoing connection issue
    [retrowifi.cpp]
2023-09-05 update ESP32 with common serial format
    [DualESP32.kicad_sch, IOSelection.kicad_sch, buffers.kicad_sch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]
2023-09-15 FIX SERIAL FIRMWARE ISSUE
    [pins.h, serial.cpp]
2023-10-02 65c816 work
    [65816CPU.kicad_sch, GALS.kicad_sch, buffers.kicad_sch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]
2023-10-12 add TMS9995
    [GALS.kicad_sch, TMS9995CPU.kicad_sch, buffers.kicad_sch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]
2023-10-15 tms9995 work
    [GALS.kicad_sch, TMS9995CPU.kicad_sch, buffers.kicad_sch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]
2023-10-31 tms9995 updates
    [GALS.kicad_sch, TMS9995CPU.kicad_sch, buffers.kicad_sch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]
2023-11-12 TMS9995 patches
    [65816CPU.kicad_sch, GALS.kicad_sch, TMS9995CPU.kicad_sch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]
2023-11-13 Interrupt updates for 65816 and TMS9995
    [65816CPU.kicad_sch, GALS.kicad_sch, TMS9995CPU.kicad_sch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]
2023-12-11 65816 updates
    [65816CPU.kicad_sch, GALS.kicad_sch, buffers.kicad_sch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]
2023-12-16 TMS9994 updates
    [GALS.kicad_sch, TMS9995CPU.kicad_sch, buffers.kicad_sch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]
2023-12-29 Add 6809 processor
    [65816CPU.kicad_sch, 6809CPU.kicad_sch, GALS.kicad_sch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]
2023-12-29 6809 fixes
    [6809CPU.kicad_sch, GALS.kicad_sch, buffers.kicad_sch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]
2023-12-30 TMS updates, add CF Image
    [6809CPU.kicad_sch, GALS.kicad_sch, TMS9995CPU.kicad_sch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]
2023-12-31 6809 updates
    [processor.6809-B_Cu.gbr, processor.6809-B_Mask.gbr, processor.6809-B_Paste.gbr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]
2023-12-31 TMS9995 documentation updates
    [processor.tms9995.csv]
2024-01-06 65816 GAL updates;
    [processor-tms9995.dsn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]
2024-01-15 6809 patches
    [6809CPU.kicad_sch, GALS.kicad_sch, buffers.kicad_sch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]
2024-01-15 6809 work
    [GALS.kicad_sch, bussharing.kicad_sch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]
2024-01-20 IO GAL update for TMS9995
    [GALS.kicad_sch]
2024-02-05 restore missing files
    [SW_Slide_1P2T_CK_OS102011MS2Q.step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]
2024-04-14 Front panel 1.1 firmware
    [SW_Slide_1P2T_CK_OS102011MS2Q.step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]
2024-05-09 FIRQ 6809 fix
    [6809CPU.kicad_sch, GALS.kicad_sch, buffers.kicad_sch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]
2024-05-12 Initial commit of DACTONE program.
    This program generates a sine wave of a specified
    frequencies and sends the samples to the DAC.
2024-05-12 update documentation
    [65816CPU.kicad_sch, fpanel.kicad_sch, mapper.kicad_sch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]
2024-05-14 65816 update
    [65816CPU.kicad_sch, buffers.kicad_sch, mapper.kicad_sch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]
2024-07-06 add 80c188 board
    [CPU_80C188.kicad_sch, Memory.kicad_sch, buffers.kicad_sch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]
2024-07-20 80c188 work
    [processor-6809.dsn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]
2024-09-08 PCB work
    [CPU_80C188.kicad_sch, Memory.kicad_sch, ansi.cfg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]
2024-09-15 80c188 updates
    [CPU_80C188.kicad_sch, Memory.kicad_sch, ansi.cfg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]
2024-10-21 80c188 working, monitor work
    [CPU_80C188.kicad_sch, Memory.kicad_sch, buffers.kicad_sch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]
2024-10-28 working design 80c188
    [CPU_80C188.kicad_sch, buffers.kicad_sch, bus.kicad_sch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]
2024-10-28 add new backplane
    [backplane.20-slot-B_Cu.gbr, backplane.20-slot-B_Mask.gbr, backplane.20-slot-B_Paste.gbr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]
2024-11-03 80c188 source cleanup
    [ansi.cfg, cvdu.cfg, dumb.cfg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]
2024-11-03 update docs
    [ansi.cfg, cvdu.cfg, dumb.cfg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]
2024-11-04 80c188 pcb updates
    [CPU_80C188.kicad_sch, ansi.cfg, buffers.kicad_sch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]
2024-11-24 BIOS updates
    [CPU_80C188.kicad_sch, Memory.kicad_sch, ansi.cfg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]
2024-12-08 support duodyne media board on 80c188
    [CPU_80C188.kicad_sch, debug.obj, floppy.obj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]
2024-12-08 support duodyne multi io board on 80c188
    [usb.obj]
2024-12-09 Add MultiIO support for 80C188
    [IO.kicad_sch, VDP.kicad_sch, buffers.kicad_sch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]
2024-12-09 add disable flag for 8242 on 80c188
    [int16ser.obj, kbd.obj, rbios.obj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]
2024-12-15 remove memory mapped video board
    [IO.kicad_sch, VDP.kicad_sch, buffers.kicad_sch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]
2025-04-06 Add alternate front panel
    [SW_Slide_1P2T_CK_OS102011MS2Q.step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]
